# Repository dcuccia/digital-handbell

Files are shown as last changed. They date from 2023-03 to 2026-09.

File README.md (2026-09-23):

# Digital Handbell

**September 22: inner ground plane, +3V3 bridge and four ground stitches accepted.** The active
four-layer PCB now has **44 opens**, with existing connected groups and
protected sense returns preserved. The supply bridge adds three 0.40 mm
In2 segments between existing vias; component placement is unchanged.
An off-pad ground via and short R4 stub now join the existing C9/R4/R8
ground group to main GND without changing the plane fills; C9's local
high-frequency return remains unqualified.
Three further stitches connect C4, shared C11/C15 and U2 ground groups;
C12, C23 and C24 remain unresolved within the finite screen.
This is an incremental routing baseline, not a fabrication
release or final SI/PI qualification. See the
[latest acceptance record](hardware/handbell/iterations/printed-bell-four-layer/reports/supply-ground-radial-acceptance.json)
and [handoff](docs/pcb-closure-plan.md#owner-pause-and-next-item).

**September 21: four-layer migration approved, with Astra/Sol role separation.**
The [routing-agent policy](docs/routing-agent-policy.md) retains Astra's
engineering review and requires pinned Sol for corridor/group routing batches.
A separate [four-layer migration baseline](hardware/handbell/iterations/printed-bell-four-layer/README.md)
was established with 51 open connections, preserving placement and existing
copper. The first staged ground plane was rejected after a refill regression.
The explicit-settings replay subsequently preserved the connections and was
accepted September 22; the rejected trial remains historical evidence.
The two-layer layout is preserved unchanged. Saved SCL experiments and the older routing-recovery archive
are preserved separately; neither is accepted replacement copper. See the
[current handoff](docs/pcb-closure-plan.md#owner-pause-and-next-item).

An open-source, motion-triggered electronic handbell for affordable educational
music-making. Replace the clapper in a children's play handbell with a speaker,
rechargeable battery, and compact electronics. A natural ringing gesture should
produce a convincing bell sound; the instrument should be quiet between notes.

**Status: schematic, PCB and mechanical engineering drafts, not a
fabrication-ready or child-use-qualified design.** The preserved 0.2
[native KiCad draft](hardware/handbell/README.md) and
[schematic PDF](hardware/handbell/reports/handbell-schematic.pdf) integrate
LSM6DSOX, TPS61023 audio boost, independent mute, keyed speaker/button connectors
and service pads. Feather/RGB/servo/STEMMA extras are removed.
The [0.2 handoff](docs/electrical-reduction-and-placement.md) and
[mechanical models](docs/mechanical-feasibility.md) distinguish actual CAD,
screening assumptions and unresolved fit/power/manufacturing gates.
A separate partial-routing checkpoint is now available; no fabrication-ready
PCB or functioning firmware has been released.

**September 14 closure work:** the [current integration draft](hardware/handbell/iterations/printed-bell-clock-draft/README.md)
has its local clock routed, recorded ground fill restored, and USB slot/land
correction applied with local CC/VBUS repairs. All **83 fitted MPNs** are
assigned, and eleven selected power/passive land patterns are applied.
It retains **56 unconnected items**, with zero other native DRC errors and
232 silkscreen/text warnings.
The [cost-aware closure plan](docs/pcb-closure-plan.md) tracks remaining
geometry, routing and matched PCB+PCBA quotation inputs. This is still an
engineering checkpoint, not a complete or qualified board.
**September 15:** work has resumed. Six documented device-envelope corrections
are applied without moving parts. The selected U5 boost and R27 current-sense
land patterns are now applied too, with local U5 escape corrections and a
matching enlargement of R27's protected ground exclusion. The first local
core-supply links to C18, C6 and the C8 regulator-output capacitor are now
routed; **52 opens remain**.
C6's QSPI obstruction was resolved by a shorter QSPI escape and small
capacitor-column moves, retaining the existing courtyard geometry.
C8's obstruction was resolved by moving the unchanged-width VHI feed into
the central backside corridor and rearranging, not removing, the nine MCU
ground vias. Thermal/stencil review remains open.
Remaining native lands are retained for routing with explicit
supplier-process questions, including filled/capped amplifier thermal vias;
two-layer supplier availability and price are not yet confirmed.
The closure plan contains the
current handoff and repo-only fill-check commands.
The [routing-tooling study](docs/routing-tooling.md) records exercised native
API strategies and the bounded offline Freerouting pilot. No external-router
proposal was accepted; routing automation remains experimental.
Subsequent native-mask routing has connected the R2/CHG0 charge-indicator
branch without moving parts or changing existing copper: **51 opens remain**.
Core supply/return and amplifier GAIN attempts were preserved but not accepted.

**September 13 printed-bell revision:** the owner reports that the latest
inert pieces fit and authorizes a single-piece printed bell, flush removable
cartridge and black handle. The separate
[front-electronics placement](hardware/handbell/iterations/printed-bell-front/README.md)
fits **81 electronic parts on F and two battery contacts on B without growing
the D43 PCB**. Rear SMT contacts still require assembly work.
The [coordinated revision](docs/printed-bell-revision.md) records the new
interfaces, conditional routing authorization and pending mechanical results;
[material/handle notes](docs/printed-bell-material-and-handle.md) distinguish
silk-PLA guidance from qualified structural or thermal performance.

The [original printed bell and rendered views](docs/printed-bell-revision.md#printed-shell-cartridge-and-handle)
now provide a **70 mm diameter, 55.8 mm body with an 80 mm black handle**,
flush grille and removable complete cartridge. Native FreeCAD/STEP and nine
inert STL files are available separately from the earlier metal-bell studies.
The coordinated PCB interfaces support the authorized critical-routing stage;
this does not approve fabrication or live-cell operation.

The [first routed candidate](hardware/handbell/iterations/printed-bell-routing/README.md)
contains real tracks/vias and reduces unconnected items from 222 to 148.
It remains incomplete and inoperable. The owner-requested
[high-current review](hardware/handbell/iterations/printed-bell-routing/reports/power-routing-review.md)
identified boost output-capacitor loop and protector-sense pickoff corrections.
The [separate power-rework milestone](hardware/handbell/iterations/printed-bell-power-rework/README.md)
now implements those corrections, and the complete FreeCAD assembly has been
rebuilt around its exact placement. It still has **155 unconnected items**;
the main switched-battery feed, other routing, sourced parts and manufacturing
inputs remain unfinished. A newly identified
[USB import/land-pattern problem](docs/usb-connector-qualification.md) must also
be corrected before the quotation package.

The intended handoff includes [full PCB+PCBA quotation assets](docs/pcba-quotation-plan.md)
for JLCPCB and PCBWay after completing the design, not just the partial
routing checkpoint. No supplier upload or order is authorized.

**September 11 revision:** the owner confirms the newer print assembly fits,
supplies [measured shell stations](docs/measurements/2026-09-11-shell-speaker-inputs.json),
and refines the speaker magnet to **21.70 mm OD**. The
[next integration plan](docs/t8-integration-plan.md) combines the Vapcell T8
contact/capture candidate, compact cell protection, 2 MB flash, revised mouth
profile, supported USB access and reversible servicing. A complete placed
FreeCAD assembly is the owner-review checkpoint before routing. Earlier
profiles and prints below remain historical snapshots, not current tolerances.

The [new native T8 placement](hardware/handbell/iterations/t8-protected-draft/README.md)
implements **83 fitted parts**, including two SMT battery contacts, an eight-part
cell-protection stage and the smaller Winbond flash footprint. Its
[schematic PDF](hardware/handbell/iterations/t8-protected-draft/reports/handbell-schematic.pdf)
and [electrical handoff](docs/t8-electrical-revision.md) explain the protected
return, sourcing and current/charging limits. It remains unrouted and does not
approve live-cell operation.

The coordinated [T8 cartridge review model](mechanical/studies/2026-09-11-t8-cartridge/README.md)
adds a four-piece body/yoke/cradle/cover, M2 captive-nut hardware, insulating
shell attachment and a mouth-open USB service slot. Its current contact/guard
geometry requires a **6.25 mm mouthward stack shift**, putting the grille
10.75 mm outside the mouth. This is a review alternative, not an approved
final exterior or permission to route. Earlier print files remain unchanged.

**Preserved September 9 placement/fit draft:** the [two-face wing placement](hardware/handbell/iterations/wing-draft/README.md)
keeps a central battery/contact reservation, moves the boost and amplifier
blocks to rear wings, and adds two GND-assigned M2 mounting holes. The
[two-piece cartridge](mechanical/studies/2026-09-09-integrated-cartridge/README.md)
provides an integrated grille/seat/support body, removable capture yoke and
new populated-PCBA STEP/STL. Its 72 mm flange sits outside the assumed 70 mm
mouth; it does not yet include battery retention or shell attachment. The
[electromechanical handoff](docs/electromechanical-wing-iteration.md) separates
draft progress from the remaining cell, retention, routing and assembly-cost
gates. The original project/print files remain intact.

**September 9 measurements:** the arrived speaker is 40 mm OD x 19 mm overall,
with a 32 mm basket rear at 12 mm and a 22 mm x 7 mm magnet. The
[measured-speaker follow-up](mechanical/studies/2026-09-09-measured-speaker/README.md)
keeps the original print files intact and compares speaker-facing electronics
with cylindrical/pouch battery space. The PCBA print received positive fit
feedback; some other pieces need structural reconsideration.

The [compact power and packaging review](docs/compact-power-and-packaging.md)
records the earlier decisions behind this revision. Its hypothetical taper
example is superseded by the owner's z13/50 mm to z43/34 mm working profile.

The working first-revision baseline is the
[Adafruit RP2040 Prop-Maker Feather (5768)](https://www.adafruit.com/product/5768):
RP2040, CircuitPython, MAX98357A I2S DAC/amplifier, LIS3DH accelerometer, USB-C,
and single-cell LiPo charging. Its documented, code-supported circuitry is
adapted into the reduced circular candidate, with the sensor and audio-power
changes described above. This is not a frozen BOM.

The owner-approved [LSM6DSOX six-axis sensor](docs/motion-sensing.md) is now in
the separate handbell draft for strike plus chest-stop/rest development.
The imported reference retains its original LIS3DH. Gesture performance,
assembled cost and final electrical decisions remain evidence gates.

## Start here

| Document | Purpose |
|---|---|
| [Project brief](docs/project-brief.md) | Captured goals, requirements, open questions, and original mechanical ideas |
| [Reference catalog](docs/reference-designs.md) | Every proposed source, learning guides, source revisions, and important corrections |
| [Architecture](docs/architecture.md) | Proposed blocks, verified baseline GPIOs, and retain/remove decisions |
| [Schematic and CAD plan](docs/schematic-plan.md) | Beginner-oriented KiCad setup/import path and schematic review gates |
| [KiCad setup and readiness](docs/kicad-setup.md) | Installed tooling, opening the native reference, and remaining import-review work |
| [Firmware and audio](docs/firmware-and-audio.md) | CircuitPython, bell assets, strike detection, quiet idle, and power modes |
| [Motion-sensor decision](docs/motion-sensing.md) | LIS3DH versus six-axis sensing, chest-stop limits, CircuitPython APIs, and sourcing |
| [Mechanics and manufacturing](docs/mechanics-and-manufacturing.md) | Speaker/board trade space, measurements, mounting, JLCPCB and OSH Park |
| [Compact power and packaging review](docs/compact-power-and-packaging.md) | Approved next revision, boost/cell/mute review, speaker-rating conflict and fit constraints |
| [0.2 reduction and placement](docs/electrical-reduction-and-placement.md) | Implemented circuits, 43 mm candidate, service map and open routing/DFM gates |
| [Mechanical feasibility](docs/mechanical-feasibility.md) | Editable FreeCAD, STEP/STL, assumed shell profile and cartridge interference findings |
| [Wing/cartridge iteration](docs/electromechanical-wing-iteration.md) | Preserved September 9 placement, two-piece fit models and JLC assembly-tier findings |
| [Measured-shell T8 integration](docs/t8-integration-plan.md) | September 11 measurements, compact protection/contact/capture revision and owner review before routing |
| [T8 electrical revision](docs/t8-electrical-revision.md) | Actual 2 MB flash lands, protected battery return, pin map, current tradeoffs and remaining gates |
| [T8 cartridge model](mechanical/studies/2026-09-11-t8-cartridge/README.md) | Complete placed FreeCAD/STEP assembly, four inert structural prints, M2 service sequence and explicit fit limitations |
| [Routing readiness](docs/routing-readiness.md) | Print-fit checkpoint, electrical floorplanning gates and the path to reviewed Gerbers/BOM/CPL |
| [Validation plan](docs/validation-plan.md) | Measurements and evidence required before each hardware release |
| [Decision log](docs/decisions.md) | Provisional decisions and the evidence needed to close them |
| [Roadmap and epics](docs/roadmap.md) | Milestones, dependencies, scope, and acceptance criteria |
| [Attribution and licensing](ATTRIBUTION.md) | Hardware, software, sound-asset, and documentation provenance |

Track execution in the public
[Digital Handbell Project](https://github.com/users/dcuccia/projects/1),
[12 epic issues](https://github.com/dcuccia/digital-handbell/issues?q=is%3Aissue%20label%3Aepic),
and [five milestones](https://github.com/dcuccia/digital-handbell/milestones).
The epics include checklists, acceptance criteria, native blocked-by
relationships, and links to supporting plans.

## Design direction

- Start with a bench demonstration using the integrated Prop-Maker Feather,
  while developing the reduced schematic in parallel.
- Prefer a single circular PCB and compare selective rear-wing population
  against the original one-face assembly goal using complete assembly cost.
  Two copper layers remain the draft baseline. Establish diameter through real
  placement and measured shell geometry, not the sum of chip areas; compare
  four layers or stacked boards if evidence warrants them.
- Keep sounding local/offline; evaluate an S3-MINI wireless variant early
  enough to inform antenna/carrier choices. The draft already has six-axis
  sensing; the unchanged reference has neither a radio nor a gyroscope.
- Optimize complete assembled cost and novice assembly, not merely IC prices.
  Fine-pitch soldering should not be a prerequisite for an educational kit.

## Project history

The original [2023 design notes](Design%20Notes.md) and
[system diagram](System%20Diagram.pptx) are preserved unchanged. They considered
wireless connectivity, a host interface, and a six-degree-of-freedom IMU.
The 2026 planning baseline narrows the first experiment; it does not silently
erase those earlier ideas.

## Licensing and attribution

The existing [MIT license](LICENSE) remains in place for original project
software and documentation. It does **not** relicense third-party hardware,
software, images, or recordings. Most candidate Adafruit hardware sources use
CC BY-SA 3.0; adapted material must retain its applicable terms and notices.
See [ATTRIBUTION.md](ATTRIBUTION.md) before importing anything.

Pinned, licensed Adafruit CAD and notices are vendored in the reference
packages; the separate derivative identifies its modifications. No third-party
firmware or recordings are vendored. This is an independent project, not an
Adafruit-endorsed product.

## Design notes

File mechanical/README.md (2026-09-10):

# Handbell mechanical feasibility artifacts

**Integrated wing draft:** the
[two-piece cartridge study](studies/2026-09-09-integrated-cartridge/README.md)
adds an integral grille/seat/support body, removable capture yoke and a new
two-face PCBA proxy with mounting holes. It uses the separate native wing
placement and preserves every older print below. Its D72 flange is external;
insertion order, small nominal clearances and unqualified hardware/retention
are described in its own handoff. Do not substitute it for a finished battery
holder or shell attachment.

**September 9 update:** the arrived speaker measures 40 mm OD and **19 mm**
overall depth, with a D32 basket rear at z12 and D22 x H7 magnet. The
[separate measured-speaker study](studies/2026-09-09-measured-speaker/README.md)
records those stations, speaker-facing PCB conflicts, battery-space comparisons
and physical print feedback. The files below are the unchanged September 7
snapshot; its **18.5 mm speaker gauge is not deep enough for the measured part**.
No reinforced carrier or new battery holder has been released.

**Inert dimensional study, not a complete fitted assembly or child-use hardware.**
The editable FreeCAD document includes the current 74-part placement as rectangular
proxies, directly from the final supplied manifest with **no height overrides**.
J2 is SM02B side-entry at 3.1 mm; D3/D4 are 1.1/1.0 mm.
USB-to-shell interference and insufficient battery clearance are retained,
not hidden by cutting the shell or shrinking parts. See the
[quantitative handoff](../docs/mechanical-feasibility.md).
The [print-now dummy set](#print-now-inert-dummy-set) adds a connected fake
populated PCBA, speaker gauges and battery blocks for PLA fit work.

## Files and coordinate system

| File | Purpose |
|---|---|
| `handbell-feasibility.FCStd` | Native document with individually selectable BRep solids, Parameters spreadsheet, assumptions, source snapshot and placement snapshot |
| `handbell-assembly.step` | 82-solid assembly in the primary 74-component study; includes assumed shell and solid exterior-only handle, excludes construction cavity and battery clearance tools |
| `fit-carrier.stl` | Single connected baffle, speaker locating sleeve, three PCB seating rails and grille stand-offs; no positive speaker/PCB restraint |
| `bonded-interface.stl` | Separate shell mounting-ring fit gauge; adhesive/paint compatibility and retention unqualified |
| `grille.stl` | Separate grille fit gauge with matching alignment holes; cone excursion and acoustic performance unqualified |
| `parameters.json` | Explicit dimensions used for this run; editable regeneration input |
| `fit-report.json` | Per-component and scenario fits, material intersection volumes, battery alternatives, toolchain and artifact round-trip results/hashes |
| `fit-dummies.json` | Standalone dummy inventory, exact dimensions, print/assembly datums, assumptions and frozen placement hash |
| `freecad-build.log` | Local, Git-ignored diagnostics regenerated by the build; not part of the published download |
| `views/packaging-views.svg` | Original axial/proxy-plan illustration, not a photograph or manufacturer drawing |
| `views/fit-dummies.svg` | Original illustrative-speaker profile and print-dummy dimension inventory; no source image included |
| `README.md`, `LICENSE` | Usage, scope and original-work licensing |

All CAD coordinates represent **millimetres**. `z=0` is the bell opening,
positive z inward. PCB XY positions use the manifest's right-handed coordinates,
with positive rotations counterclockwise when viewed from +z toward the origin.
The SVG plan has +X right and +Y up. STEP declares millimetre SI units.
**STL has no unit metadata: import as mm at 1:1.**

The original carrier/interface/grille STLs retain assembly positions. Translate
them to the print bed rather than scaling: carrier z=-4, grille z=-5.8,
interface z=0. **All new standalone dummies below already start at print Z=0.**
Their print origin is not necessarily their position inside the bell.

## Print-now inert dummy set

Original dummy profile and dimensions

**Start with** the [populated PCBA STL](populated-pcba-proxy.stl),
[maximum speaker gauge](speaker-envelope-maximum.stl), and
[compact battery-clearance gauge](battery-clearance-compact.stl).
The [illustrative speaker STL](speaker-illustrative-unmeasured.stl) shows the
approximate stepped shape, but is not the conservative fit envelope.
Use mm at 100%; the PCBA's extra USB projection must not be scaled away.
**No USB drilling/cutting template is supplied.** Its interference with an
uncut shell is expected; do not force it or use the proxy box as a connector
manufacturing drawing.

All dimensions in this table are default **millimetres**, at 100% scale.
Every listed STL is one connected, closed solid. Each has an editable BRep in
the native document's `FitDummies` group, separate from the assembly export.

| STL file | Size / purpose |
|---|---|
| `populated-pcba-proxy.stl` | **43 x 43.465 x 6.6** bounding box; 43 mm circular substrate, 1.6 mm thick, fused to all 74 supplied component boxes |
| `speaker-envelope-nominal.stl` | **D40.5 x H18** full cylinder; nominal frame/depth gauge |
| `speaker-envelope-maximum.stl` | **D40.9 x H18.5** full cylinder; conservative maximum frame/depth gauge |
| `speaker-illustrative-unmeasured.stl` | **D40.5 x H18** stepped rim, solid tapered basket and magnet; intermediate geometry is unmeasured |
| `battery-dummy-primary.stl` | **20 x 30 x 8** inert block, not a selected pack |
| `battery-dummy-compact.stl` | **18 x 28 x 8** inert block, not a selected pack |
| `battery-clearance-primary.stl` | **22 x 32 x 10** solid gauge representing the primary block plus 1 mm clearance on every face |
| `battery-clearance-compact.stl` | **20 x 30 x 10** solid gauge representing the compact block plus 1 mm clearance on every face |

The standalone **`populated-pcba-proxy.step`** and
**`speaker-illustrative-unmeasured.step`** have the same print orientation/datum
as their STLs. The PCBA is a true fused union, not a collection of disconnected
boxes. No small 0402 detail was enlarged, no bridging material added outside the
source envelopes, and no body clipped at the PCB boundary. The USB proxy explains
the 43.465 mm overall Y extent: do not scale the whole dummy down to 43 mm.
No visualization-enlargement variant is included.

For the current inward-facing board, put the PCBA's flat substrate underside on
the bed and components upward. Restore its bottom to **assembly z20** when
checking the bell; the print file itself has substrate z0..1.6 and components
through z6.6. Speaker gauges have the front/frame face on the bed and correspond
to assembly z0. Battery blocks correspond to **assembly z28**, while their
clearance gauges start at **z27** because they include the mouthward free space.
Use those depth datums rather than directly stacking all dummies against each
other; the model includes deliberate gaps between them.
The current model still predicts USB interference with an uncut shell and failure
of the larger battery-clearance gauge; do not force either into the bell.

### Speaker: supplied dimensions versus invented shape

The supplied retail image repeats frame40.5 +/-0.4, magnet22 +/-0.5, overall
depth18 +/-0.5 and rim2.7 +/-0.3 mm. It is **not redistributed**, embedded in
the native document, or traced for measurements. Rim height is part of overall
depth, not added to it. The maximum full cylinder remains the hard-interference
model; neither gauge includes unknown terminals, wire exits or cone excursion.

The separate illustrative dummy uses nominal frame40.5, depth18, magnet22 and
rim2.7. Its **37 mm basket front diameter**, **26 mm basket rear diameter** and
**magnet front at z12** are deliberately chosen, unmeasured starting values.
They imply a 9.3 mm tall solid conical basket and 6 mm magnet height. No rib
windows, terminals, diaphragm, recess or rear vent is claimed. A fit of this
illustrative shape is **not** evidence that the real basket fits.

Change the `gauge_speaker_assumed_*` values in `parameters.json` or the saved
Parameters spreadsheet, then regenerate. The compact battery has separate
`gauge_compact_battery_*` parameters. Its parameters also drive the corresponding
numeric clearance comparison. Older native spreadsheets receive the explicitly
logged new gauge defaults during regeneration.

### Creality K1C / PLA starting guidance

Use the K1C profile for the **nozzle actually installed**, with the filament's PLA
temperature settings. For a stock 0.4 mm nozzle, a reasonable unqualified starting
point is 0.20 mm layers for bulk gauges, 0.12-0.16 mm for the PCBA's small details,
three walls and 15-20% infill. These are starting suggestions, not an exercised
slicer profile; no G-code or remote print job is supplied.

Import **mm, 100% scale**, without fit-to-bed resizing. The wide speaker frame
face and battery block bottoms are already on Z=0 and are intended to print
without support. Inspect the PCBA's USB overhang and very small component boxes
in the slicer; add local support only if the actual toolpath requires it. Tiny
0402 proxy details can be lost, fragile or dimensionally inaccurate with a
0.4 mm nozzle. Check the toolpath rather than enlarging the exact-fit file.
The original carrier may require a different orientation/support strategy.

Let prints cool, then measure their diameters, depths and board thickness with
calipers before drawing fit conclusions. Remove loose fragments and do not
force a gauge against the painted shell. Follow the printer/filament guidance
for PLA ventilation and enclosure use. **PLA dummies are not live-cell
restraints, FR4/thermal substitutes, electrically functional parts, mass/acoustic
stand-ins, structural mounts or child-ready hardware.**

## Reproduce without opening a GUI

From the repository root, using ordinary Python and installed FreeCAD:

```powershell
$FreeCAD = "$env:LOCALAPPDATA\Programs\FreeCAD 1.1\bin\FreeCADCmd.exe"
python .\tools\build_mechanical.py --freecad-cmd $FreeCAD --placement .\hardware\handbell\placement\placement-manifest.json
```

The launcher runs the installed FreeCAD Python interpreter, not an unrelated pip
package. It uses temporary isolated user/system preferences, waits synchronously,
and checks a fresh completion marker because FreeCAD's console can return zero
after a Python exception. The console process has a **300-second timeout**.
No GUI, background detachment, add-on installation,
user-window manipulation or shared FreeCAD-preference changes are required.

The script regenerates the named CAD/data/view artifacts in this directory.
It never writes the placement manifest, KiCad files or existing documentation.
It overwrites its generated outputs, so use `--output` with another directory
to preserve a study. A successful build means artifacts were generated and
round-tripped, **not** that all geometry fits.

To modify a parameter without editing code, use `--parameters` with a JSON
object containing known keys, or edit the native `Parameters` spreadsheet,
save the document, then regenerate:

```powershell
python .\tools\build_mechanical.py --freecad-cmd $FreeCAD --parameters-from .\mechanical\handbell-feasibility.FCStd --placement .\hardware\handbell\placement\placement-manifest.json
```

The BReps are source-generated features, not a fully constrained interactive
feature history. **Spreadsheet edits alone do not rebuild geometry.** The command
above reads those saved values and rebuilds the model. Manifest board dimensions
and face take precedence over parameter-file/spreadsheet board values.
`--speaker-front-z 1` moves the speaker front to z=1, with unchanged full depth.
The script snapshot inside the document records the source that built it.

`--component-height REFERENCE=MM` is an explicit model-only parameter: it changes
neither the input manifest nor the component's XY, footprint or rotation.
`--component-height-note` records its reason. If explicitly requested, original
and effective heights are recorded in `fit-report.json` and native
`ComponentHeightOverrides`; the native manifest snapshot remains unchanged.
`--parameters-from` does not restore such overrides automatically.
**No height override is used or needed for the current supplied manifest.**
The earlier top-entry height screen and its J2/battery-clearance overlaps are
superseded. The current side-entry J2 does not intersect either battery
alternative's clearance envelope.

The report distinguishes `required_shell_cutouts` from
`unplanned_cavity_conflicts` while retaining raw uncut-shell intersections.
No USB slot is implemented or dimensionally qualified. The 18 reverse-face
copper features and C29 DNP reservation remain metadata, not material solids.
Battery variants include their intersections with populated-board proxies:
cavity containment alone does not establish assembly clearance.

When first opening the headless-produced document in FreeCAD, hide
`CavityReference` and `BatteryClearance` under the construction-reference group;
their solid geometry is for calculations, not physical parts. Also hide the
`FitDummies` group: its independent print-coordinate objects overlap when shown
together and are deliberately excluded from `handbell-assembly.step`.
Hide `BellShell` and `HandleExterior` to inspect the electronics/carrier.
Show one dummy at a time to inspect it, or open its standalone STEP.
The original SVGs are ready-to-view illustrations without display setup.

Passing `--placement` with a missing or malformed file is an error. Omitting it
deliberately produces a **placeholder-only** study with no component solids;
it does not silently load a nearby manifest or reuse old placement data.

## Attribution and license boundaries

The original mechanical primitives, fit-print designs, parameters, program and
new documentation are explicitly available under the [MIT license](LICENSE).
They are independent geometry built from the declared dimensions and assumptions.
No vendor photograph, owner photograph, manufacturer STEP model, speaker drawing,
upstream board solid, KiCad library geometry or third-party mesh is copied here.
The illustration is generated from this original model.

**Do not label the populated study blanket-MIT.** The embedded placement snapshot,
component-reference context and adapted electronics remain subject to the
repository's [attribution policy](../ATTRIBUTION.md) and the
[handbell hardware's CC BY-SA 3.0 notices](../hardware/handbell/README.md).
The mixed populated FCStd/STEP, populated-PCBA STEP/STL, placement-based views
and reports must travel with
those notices; the original mechanical geometry's separate MIT grant does not
relicense the electronics. The embedded script retains MIT independently.

The referenced electronics are based on:

- **Limor Fried/Ladyada for Adafruit Industries**, RP2040 Prop-Maker Feather
  5768, revision `408fa9a40c0a01a3a65497ef42a29e0b08fe711e`;
  [source notices and full CC BY-SA 3.0 license](../hardware/reference/adafruit-5768/README.md).
- **Bryan Siepert for Adafruit Industries**, LSM6DSOX 4438,
  revision `c05abef4675b0380fbf3d23171615a2f1ac0b130`;
  [source notices and full license](../hardware/reference/adafruit-4438/README.md).
- **Limor Fried/Ladyada for Adafruit Industries**, TPS61023 MiniBoost 4654,
  revision `82b5a33a1900a5c13849029bc84e7856a44086e0`;
  [source notices and full license](../hardware/reference/adafruit-4654/README.md).

Distribute this study with the repository's complete upstream notices, or carry
those notices/licenses alongside standalone populated exports. These proxy boxes
are not Adafruit or component-manufacturer CAD models. Attribution does not imply
endorsement, manufacture or mechanical/electrical/safety qualification.

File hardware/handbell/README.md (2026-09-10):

# Handbell: 0.2 electrical and placement draft

**Later placement alternative:** the separate
[wing draft](iterations/wing-draft/README.md) adds selective rear-face
population and M2 mounting interfaces for the
[integrated cartridge](../../mechanical/studies/2026-09-09-integrated-cartridge/README.md).
This directory's original 0.2 CAD and print snapshot remain unchanged;
open the variant's project for the newer placement.

**Reduced electronics and a 43 mm unrouted candidate; not a fabrication release.** Open
[`handbell.kicad_pro`](handbell.kicad_pro) in KiCad 10.0.6, then its schematic.
For a CAD-free view, use the [schematic PDF](reports/handbell-schematic.pdf).
The PCB editor opens [`handbell.kicad_pcb`](handbell.kicad_pcb), an actual-footprint
placement with no tracks/vias/zones. Start with the
[0.2 handoff](../../docs/electrical-reduction-and-placement.md) for boost, mute,
connectors, service access, geometry and unresolved DRC/power gates.

The owner approved the sensor change on 2026-09-07. The earlier 0.1 replaced the
5768 reference's LIS3DH, resolves its original ERC findings in a separate
derivative, and established explicit sensor/debug connections. That history
remains in commit `ef3d6ab2bf822cff79d41573f05b5916c6a7133e`.

**Later 2026-09-07 scope update:** the owner approved the compact GPIO19-button,
no-STEMMA/header/RGB revision and a boosted audio/mute review. The
[power/packaging assessment](../../docs/compact-power-and-packaging.md) records
those decisions, candidate sources and remaining gates. This directory now
implements **0.2**: TPS61023 boost, independent GPIO20 mute, GPIO19 button,
keyed speaker connector, service pads and removal of expansion/RGB branches.

## Artifacts and scope

| Artifact | Purpose |
|---|---|
| [Native schematic](handbell.kicad_sch), [local symbols](Handbell.kicad_sym) | Editable design; source-derived and mode-specific symbol definitions |
| [PDF](reports/handbell-schematic.pdf), [XML netlist](reports/handbell-netlist.xml) | Human and machine-readable views |
| [ERC disposition](reports/erc-review.md), [machine-readable dispositions](reports/erc-dispositions.json) | Individual treatment of all 50 original findings and collateral warnings |
| [Current ERC](reports/handbell-erc.json) | Zero errors and zero warnings under the unchanged baseline rules; no exclusions |
| [Connectivity/pad review](reports/connectivity-review.json) | 62 retained components, 73 projected groups, explicit changes, all sensor/boost lands |
| [BOM draft](reports/bom-draft.csv) | Values and footprints, with incomplete MPN/assembly choices explicitly marked |
| [Placement](placement/placement-top.svg), [manifest](placement/placement-manifest.json), [review](placement/placement-review.json) | 74 fitted front parts, 18 reverse copper features, one DNP provision |
| [Native DRC](placement/placement-drc.json), [substrate STEP](placement/pcb-substrate.step) | Unresolved findings retained; substrate-only STEP is not a populated model |

The footprint table refers to three sibling reference packages and the local
`Handbell.pretty` correction library using
`${KIPRJMOD}`-relative paths. Keep the **whole repository checkout** together;
copying only this directory omits required footprints. Standard KiCad libraries
provide `power:PWR_FLAG`. The exported schematic also embeds its symbols.

## Reuse, authorship and license

This independent adaptation is **CC BY-SA 3.0 Unported**:
[complete license](LICENSE.txt). It is not an Adafruit product or endorsement.

- Core, power, audio and other retained circuitry: Adafruit RP2040 Prop-Maker
  Feather 5768, designed by Limor Fried/Ladyada for Adafruit Industries,
  source commit `408fa9a40c0a01a3a65497ef42a29e0b08fe711e`.
  [Full original notice and source](../reference/adafruit-5768/upstream/README.md).
- SOX symbol and LGA-14L footprint: Adafruit LSM6DSOX 4438, designed by
  **Bryan Siepert for Adafruit Industries**, source commit
  `c05abef4675b0380fbf3d23171615a2f1ac0b130`.
  [Full original notice and source](../reference/adafruit-4438/upstream/README.md).
- Boost: Adafruit TPS61023 MiniBoost 4654, Limor Fried/Ladyada for Adafruit
  Industries, commit `82b5a33a1900a5c13849029bc84e7856a44086e0`.
  [Full original notice and source](../reference/adafruit-4654/upstream/README.md).
- Integration, changed wiring, electrical pin types, annotations and review:
  the dcuccia digital-handbell project, with AI assistance, 2026-09-07.
- Standard KiCad power, connector, SOT23 and solder-jumper material is used in the design under KiCad's
  [CC BY-SA 4.0 library license with design exception](https://www.kicad.org/libraries/license/).
  It is not redistributed in `Handbell.kicad_sym` as a library collection.
  Original verification scripts under `tools` remain MIT-licensed.

All three upstream references are preserved separately. The old Adafruit graphical
title frame was removed from this derivative and replaced with an independent
title block carrying attribution; upstream notices were not removed.

## LSM6DSOX electrical contract

**IC4 = LSM6DSOXTR**, LGA-14L, nominal 2.5 x 3.0 x 0.83 mm. It operates from
the common regulated **3.3 V**, not raw battery voltage. This is an I2C-only,
ST **Mode 1** implementation at seven-bit address **0x6A**.

| Physical pad | Function | Connection |
|---|---|---|
| 1 | SDO/SA0 | GND: fixed address 0x6A |
| 2, 3 | SDx, SCx | GND: unused Mode 1 auxiliary pins must not float |
| 4 | INT1 | `INT`, RP2040 GPIO22 / IC1 physical pin 34 |
| 5 | VDDIO | +3V3, local C24 = 100 nF to GND |
| 6, 7 | GND | Both physical pads to GND; imported symbol has stacked pins |
| 8 | VDD | +3V3, local C23 = 100 nF to GND |
| 9 | INT2 / DEN | `IMU_INT2` to TP6 only; no second MCU connection yet |
| 10 | OCS_Aux | Explicit NC; its physical land must still be soldered |
| 11 | SDO_Aux | Explicit NC; its physical land must still be soldered |
| 12 | CS | +3V3: I2C interface selected |
| 13 | SCL | GPIO3 / IC1 pin 5; existing R14 = 10 kohm to +3V3 |
| 14 | SDA | GPIO2 / IC1 pin 4; existing R15 = 10 kohm to +3V3 |

No duplicate regulator, BSS138 level shifter, CS diode or additional I2C
pull-up bank is imported from the breakout. Two local 100 nF bypass capacitors
follow ST's application circuit rather than treating the breakout's shared
100 nF and regulator bulk capacitance as interchangeable.

**Deliberate difference from Adafruit 4438:** its auxiliary pins go to JP2.
This fixed-function design instead follows ST's Mode 1 instructions: SDx/SCx
are tied to GND; OCS_Aux is NC; SDO_Aux is NC (ST also permits VDDIO).
The source symbol's generic bidirectional types are specialized to this mode
in `LSM6DSOX_I2C_MODE1`. Do not reuse that symbol for sensor-hub/OIS wiring
without reviewing the types, straps and firmware.

Evidence: [ST LSM6DSOX datasheet](https://www.st.com/resource/en/datasheet/lsm6dsox.pdf),
DS12814 Rev 3, Table 1 pp.8-9, section 5.1 pp.18-19, Figure 24 p.39 and Table 20
p.42. The reviewed ST-authored Rev 3 document was obtained through JLC's
[C481766 datasheet link](https://jlcpcb.com/partdetail/C481766) when the direct
ST fetch failed; page numbers above are **Rev 3**, not Rev 4. Original Adafruit
pin-to-pad mapping is in its pinned
[schematic lines 5463-5482](https://github.com/adafruit/Adafruit-LSM6DSOX-PCB/blob/c05abef4675b0380fbf3d23171615a2f1ac0b130/Adafruit_LSM6DSOX.sch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).

## Historical 0.1 integration changes

In 0.1, all non-sensor component values, footprints and pin-to-pin groups were retained.
I2S remains GPIO16 data, GPIO17 bit clock and GPIO18 word select; amplifier
power enable remains GPIO23. The original changes beyond the sensor were:

- TP4 on SWCLK and TP5 on SWDIO make debug-pad intent explicit. They reuse the
  reference's 1.5 mm copper test-pad footprint; they are not fitted components.
  Adjacent GND/3V3 probing and physical accessibility remain layout decisions.
- Power-output/ground/mounting-terminal electrical types are corrected in the
  derivative library; intentional unused pins have NC markers.
- Redundant label-bearing wire tails are trimmed or removed without changing
  retained connections. Five power flags declare external/discrete sources;
  they are annotations, not added supplies or a proof of every power state.
- The inherited `1.2V` rail name becomes **`VCORE`**, with identical connections.
  RP2040's datasheet specifies a 1.1 V reset nominal for its internal regulator;
  a copied net label is not a voltage measurement or firmware setting.

## Firmware prerequisite discovered during integration

The inspected CircuitPython LSM6DS snapshot redefines `_i3c_disable` from
CTRL9_XL bit 1 to bit 0, and the SOX constructor uses that descriptor.
For this non-I3C design, verify **bit 1 set, reserved bit 0 clear**, preserving
other bits. Do not assume an unmodified copy of that inspected snapshot is
ready for bring-up. See the [motion document](../../docs/motion-sensing.md)
for pinned source evidence and the bring-up gate.
Execution is tracked in [E06 child issue #13](https://github.com/dcuccia/digital-handbell/issues/13).

Keep sensor-hub master, pass-through, OIS and DEN disabled. Retain the default
auxiliary pull-ups when leaving pads 10/11 NC. Route chosen events explicitly
to INT1; a physical interrupt wire does not configure interrupt behavior.

## Not resolved by 0.2

Cell choice, charger current/temperature/protection, cutoff and play-while-charge
policy; qualified speaker power and measured quiet-idle sequencing; USB input/ESD
review; final mating harnesses; complete MPN/assembly quote; real-shell circular fit,
orientation, placement/routing, ground/current-return paths and mechanical
support; actual sound, latency, gestures, runtime and safety.

In particular, the inherited R8 = 5.1 kohm is about **196 mA nominal** charge
current, not an approved setting for an unspecified cell. Neither speaker lead
is ground: the MAX98357A output is BTL. E02/E04 remain open; zero ERC findings
are not independent electrical, acoustic, thermal or child-use signoff.

## Reproduce exports and checks

From the repository root in PowerShell, with Python 3.10+ and KiCad installed:

```powershell
$Cli = "$env:LOCALAPPDATA\Programs\KiCad\10.0\bin\kicad-cli.exe"
$Sch = ".\hardware\handbell\handbell.kicad_sch"
$Reports = ".\hardware\handbell\reports"
& $Cli sch export pdf --exclude-pdf-metadata --output "$Reports\handbell-schematic.pdf" $Sch
& $Cli sch export netlist --format kicadxml --output "$Reports\handbell-netlist.xml" $Sch
& $Cli sch erc --exit-code-violations --format json --output "$Reports\handbell-erc.json" $Sch
python .\tools\check_handbell.py --kicad-cli $Cli
```

Stop on a nonzero exit code. The final command freshly exports all four
schematics in temporary storage, checks three source imports and the derivative,
and updates the connectivity report and BOM draft. It uses only Python's
standard library. Its expected changes describe this 0.2 integration; future
intentional reductions must update that explicit contract, not bypass it.
These commands do not qualify a PCB. See the 0.2 handoff for placement generation
and the `--placement` correspondence review.

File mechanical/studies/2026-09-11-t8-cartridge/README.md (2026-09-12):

# Measured-shell T8 cartridge: coordinated mouthward stack

**A nominal placed-fit study for owner review before routing, not a fabrication,
live-cell, contact-force or child-use approval.** The entire internal stack is
moved **6.25 mm toward the mouth**, preserving its speaker/yoke/PCB/cell gaps.
The mouth register stays fixed and the front body projects farther outside.
The chosen battery-guard target is **1.0 mm plastic**, within the owner's
1-1.5 mm range, with **0.10 mm nominal cell/contact clearance**.

The initial fixed-stack result is preserved under
[`alternatives/baseline-fixed-stack`](alternatives/baseline-fixed-stack/README.md).
It is not silently relabeled as fitting. The bounded alternative and its exact
source hashes are in
[`alternatives/whole-stack-screen/stack-shift-fit-report.json`](alternatives/whole-stack-screen/stack-shift-fit-report.json).
All September 7/9 studies and existing generators remain unchanged.

## Why the shift is 6.25 mm rather than 2 mm

The upper, full-thickness Keystone 254 spring limits the fit, not the bare cell.
At a 2 mm shift the bare cell clears the working shell by1.581 mm, but the
contact metal clears by only0.331 mm: that does not leave room for a1.0 mm
guard. The screen first tried the suggested1.5/2 mm shifts, then used the
analytic upper-contact corner to choose two quarter-millimetre brackets.
It did not run a blind optimizer or clip the metal.

| Whole-stack mouthward shift | Plastic target | Full rounded guard-stock result |
|---|---|---|
|1.5 mm |1.0 mm |27.475 mm3 shell overlap |
|2.0 mm |1.0 mm |18.845 mm3 shell overlap |
|6.0 mm |1.0 mm |No overlap;0.231 mm shell margin |
|**6.25 mm, chosen** |**1.0 mm** |**No overlap;0.294 mm shell margin** |
|7.0 mm |1.25 mm |No overlap;0.232 mm shell margin |
|7.25 mm |1.25 mm |No overlap;0.294 mm shell margin |

The rounded stock uses conservative local contact bounding solids with rounded
external corners, not an oversized rectangular corner and not a substituted
solid contact box through the cell. Its0.25 mm nominal shell-margin target is
a design assumption, **not measured print, paint or shell tolerance**.
The chosen1.0 mm option avoids another1 mm of external projection.

## Exact coordinated interface

All coordinates are **mm**. Mouth/front is z0; positive z is toward the handle.
The builder consumes the updated electrical manifest and contact interface
directly. It does not silently shift electronics imported from an old manifest.

| Feature | Current working coordinate |
|---|---|
| Speaker front / grille front |z-6.25 / z-10.75 |
| Rear basket station / magnet rear |z5.75 / z12.75 |
| Capture ring |z6.05..8.55 |
| PCB speaker-facing F / handle-facing B |z14.25 / z15.85 |
| T8 axis, X-oriented |(0,0,25.63), D16.4 x totalL34 provisional |
| Cell bottom / top |z17.43 / z33.83 |
| Contact B landing / spring top |z15.85 / z32.44 |
| Cover split |z25.75 |
| PCB mounting holes |(+10,+15.7), (-10,-15.7), D2.2 |
| USB native origin / source mouth |(0,-22.82) / (0,-27.90) |
| USB body-height proxy |z10.75..14.25 |
| Fixed shell attachment locations |Opposed X sides, outer-wall center z3 |

The main PCB remains D43 x1.6 with the **actual supplied outline polygon**:
contact-pad tabs to x+/-22.25, y+/-2.3 and a USB tongue x+/-5.75 to y-26.85.
The tongue/mouth move2.75 mm outward from the fixed-stack variant. All other
component XY, mount and contact-pad positions remain supplied by electrical.

The current manifest/companion hashes, actual PCB/schematic hashes and raw
snapshots are in `fit-report.json` and `artifact-manifest.json`.
The coordinated manifest at generation is
`4e8e27f7241e76850ef4fb9719a45acf0ab49ccfe9e1d651ef60f278b20da46c`;
the companion is
`e93d72ef211b7615634f255153a413b826d05c1495fa19d967c64456b647c4a6`.
An electrical source change requires a new build, not reuse of old fit values.

## Open the files

| File | Scope |
|---|---|
| `t8-cartridge.FCStd` | Selectable BReps, colored components, transparent working shell, parameters, exact base64 raw-input/source snapshots |
| `t8-cartridge-with-shell.step` | Complete placed study with proposed shell slot/holes and handle exterior |
| `t8-cartridge-assembly.step` | Complete cartridge including full contact primitives, without shell/handle |
| `body.step`, `yoke.step`, `battery-cradle.step`, `battery-cover.step` | Four separate structural parts |
| `populated-t8-pcba.step` | Full supplied PCBA/contact geometry; not a mesh-printability approval |
| `INERT-body.stl`, `INERT-yoke.stl`, `INERT-battery-cradle.stl`, `INERT-battery-cover.stl` | Four connected structural inert print models |
| `INERT-populated-t8-pcba-without-contacts.stl` and matching STEP | Explicitly contact-free, connected PCBA fit dummy |
| `INERT-speaker-body-screen.stl`, `INERT-T8-full-cell.stl` | Full inert dimensional bodies, not live parts |
| `inner-outer-profile-and-datums.svg` | Original novice-oriented section, measured/inferred stations and shifted datums |
| `fit-report.json`, `artifact-manifest.json`, `completion.json` | Exact Booleans/distances, path samples, source/output hashes and fresh completion |
| `placement-snapshot.json`, `contact_interface-snapshot.json`, `measurements-snapshot.json` | Exact consumed raw bytes, not reformatted approximations |

**STL is unitless: import mm,100%, without scaling.** Files retain assembly
coordinates, not print-bed coordinates; translate/reorient only for a separately
approved inert print. No G-code, printer job, physical drilling or fabrication
order is supplied.

Dark-grey F and brown B boxes distinguish the board faces; contact metal is
silver, body green, yoke amber, cradle/cover blue/cyan and cell purple.
`ConstructionReferences` contains hidden gauges, alternative/exact-source
comparison shapes and the USB anchor reservation, not extra fitted parts.
View properties are written headlessly; parent coordinates the actual GUI review.

### Contact geometry and the deliberately limited PCBA print dummy

The source spring polyline is its **cell-facing boundary**. The0.30 mm
thickness extends outward +X for BT1 and -X for mirrored BT2. Segment coordinates
are checked, and contact material must not penetrate the nominal cell.
Loaded ear angles are[-80,52] and[128,260] degrees, innerR8.2/outerR8.5.
The17.0 mm loaded outer width is an unqualified kinematic assumption, not an
approved deformation from the drawing's16.61 mm unloaded reference.

The contact base/spring junction has four nonmanifold mesh edges outside the
narrow outer solder tab. The full native/STEP geometry remains unchanged;
no connecting metal is invented to make an STL pass. The released PCBA STL
therefore explicitly omits BT1/BT2. They remain in the fitted83-component model
and BOM and are **not** reclassified as copper-only features.
Each contact is one instance containing three BRep solids; their fold-root
geometry and actual loaded form still need review. The report records the
nonmanifold edge endpoints/facet counts. No full-contact PCBA STL is released.

## Measurements versus assumptions

The model prioritizes owner-measured **ID71.68 atz0, ID69.75 atz4.9 and rough
ID50 atz14.9**. The first concave section ends at4.9+10=14.9, explicitly
confirmed. **ID36.12 at approximatez41.75 is inferred**, not measured:
OD38.42 minus twice the owner-requested1.15 wall assumption.

The1.15 mm wall is a **radial offset**, not constant normal thickness.
Working ODs at the first three stations are73.98,72.05,52.30; raw observations
remain73.15,73.15,51.50. The disagreements are preserved in the exact record.
Concave interpolation, the straight upper taper and the final closure above
z41.75 are provisional. Roundness, paint, uncertainty and handle-fastener
intrusion remain unmeasured. Handle exterior H85.5/D18.52..15.01 does not imply
usable internal handle space.

The fixed register follows that inner profile throughz9 with an assumed0.30 mm
radial print clearance. Two localized carrier pads intentionally bear on the
working cavity at the shell fasteners. The **D75.5 flange is external** and now
ends at the mouth plane; it is not shrunk to fit inside ID71.68. The external
skirt connects the mouth to the translated front plate. It projects6.25 mm
before the lower plate/grille; the grille front is10.75 mm outside the mouth.
Cosmetic overhang, mass, strength and acoustic behavior are not qualified.

Speaker dimensions remain D40/H19, rear basket D32 at speaker-relativez12 and
magnet D21.70/H7. The conservative conditional body remains D40 through the
basket depth, followed by the magnet; the illustrative tapered basket is not
substituted to hide collisions. Opening D22.1 gives0.4 mm diametral nominal
magnet play; the rear-basket gap remains0.3 mm. These are print assumptions,
not measured tolerances, permissible preload or a reason to force the speaker.
Rim bearing, intermediate basket, terminals, wire exits, vent and cone excursion
remain unknown.

## Four pieces, load paths and M2 hardware

The body integrates grille/seat, fixed register, external skirt, supports and
USB bezel. The removable yoke closes the speaker loading path and supports
the PCB. The cradle and separate cover provide positive can/end capture.
Cell loads are intended to pass through the cradle legs, locally supported
board mounts, yoke and body rather than SMT solder joints. Loaded force sharing,
spring travel, torque, creep and retention strength remain unqualified.

**M2 means2 mm nominal thread, not M3.** The board holes are2.2 mm clearance
drills. Hex nut pockets are not heat-set-insert pilots.

| Joint | Hardware / nominal stack |
|---|---|
| Two body-to-yoke joints | M2x6 cap screws and M2 nuts;1.45 mm roof,1.6 mm full nut engagement,0.4 mm blind-tip gap |
| Two PCB/cradle-to-yoke joints | M2x6 cap screws and M2 nuts;1.40 mm roof,0.8 mm clamping floor,1.1 mm blind-tip gap |
| Two cover-to-cradle joints | M2x6 cap screws and M2 nuts;1.45 mm roof,0.3 mm blind-tip gap |
| Two shell-to-carrier joints | Insulating nylon M2x6 screws and M2 nuts, separate from board hardware |

All six metal screws use the same M2x6 size. The dimension screen uses
DIN934-style nuts AF4/H1.6, ISO4762-style cap heads D3.8/H2 and nominal1.5AF
hex-key access. Nut pockets AF4.2 and screw bores D2.2 are unqualified print
allowances. Family references: [DIN934](https://www.fasteners.eu/standards/DIN/934/)
and [ISO4762](https://www.fasteners.eu/standards/ISO/4762/). No chosen supplier
lot, nylon head shape, thread form, knurl, torque or pullout rating is qualified.
The old D3xL4 insert placeholders are not reused.

The six metal nuts enter **sideways beneath real roofs** belonging to the part being fastened.
A top-open nut pocket closed only by the next part would not clamp its parent.
The engaged screw prevents sideways escape; a fully removed screw can release
a nut, so service over a tray with no live cell.
The two nylon shell nuts instead enter from the bell-axis side along open-ended
hexagonal sockets aligned with the inclined shell screws. A vertical insertion
chute was collision-checked and rejected. Their final outer nut faces bear on
the socket roofs; nominal engagement is1.6 mm with0.55 mm of screw beyond each
nut. The declared insertion path is included in the BRep report.

PCB screw heads end atz18.65 inside cups endingz19.90, recessed1.25 mm axially
and1.30 mm radially. Lower and cover screw guards are integral printed features.
The two shell screws follow the working lip's surface normal, approximately
**11.14 degrees handleward from the local radial direction**. Their under-head
planes contact the modeled outside instead of floating above it; local carrier
pads bear on the inside. These are proposed CAD/template locations, not
instructions to drill an unmeasured bell. Nylon substitution, paint damage,
clamping pressure, weakening of the shell and installation tooling remain gates.

## Assembly and service path

1. Outside the bell and before the yoke/PCB, load the nylon shell nuts from the
   inner ends of their inclined hexagonal sockets. Load the lower metal body nuts next: lower them
   through the register at radius26.5, move outward above the supports, lower
   at radius29.1, then slide inward into the roofed pockets. The report records
   the waypoints; do not push nuts through the external skirt.
2. With yoke/PCB absent, lower the speaker front-first onto its shifted seat.
   Its D40 frame cannot pass through the installed D22.1 capture opening.
3. Lower the yoke over the magnet and fit its two M2x6 screws. Do not preload
   an unverified speaker bearing surface.
4. Side-load the yoke-boss nuts, lower the PCBA into the **open-top** USB bezel,
   add the empty cradle and install the two recessed M2x6 screws.
5. Evaluate only with an inert cell, side-load the cover nuts and fit the cover.
   Positive retention does not qualify actual cell insertion, contact load,
   wrapper abrasion or reverse-insertion behavior.
6. Unplug USB and remove both shell screws before sliding the whole cartridge
   through the mouth, aligning its bezel with the mouth-open -Y slot.
   The front flange and carrier pads are the load-bearing interfaces, not USB
   solder anchors. Fit the insulating shell screws only after owner review.

For service unplug first, remove both shell screws and withdraw the **whole
cartridge mouthward (-z)**. Remove the cover/cell, then cradle/PCB, then yoke
and speaker as needed. The slot is open all the way toz0; a closed side hole
would trap a protruding USB connector. Nut, screw-tool, speaker, yoke, PCB,
cover and complete-cartridge motions are recorded as exact swept bounds where
available and explicit pose samples otherwise. They do not prove every tilted,
cabled or deforming motion.

The under-USB ledge ends atz10.55, leaving0.2 mm to the source body'sz10.75
underside. The proposed slot ends atz17.75 and bezel atz17.45. The source mouth
y-27.90 is approximately0.045 mm outward of the working shell at midpointz12.5;
the curved wall creates a different recessed/protruding band at other heights.
**No whole-face flush or selected-plug claim is made.** The unselected
8.8x8x2.6 mm plug-nose approach screen is not an approved mating travel/overmold.
USB tails remain unmeasured: copper1x2 and drill0.60 dimensions are not metal
tail dimensions. The full B projection is retained as a hidden planning
reservation, not a fabricated occupied height. Inherited electrical USB-hole
clearance findings are not waived or resized here.

## Fit evidence and remaining gates

The owner's later visual estimate of approximately 1 mm spare speaker-to-PCB
space is recorded as an estimate, not a measured minimum clearance.
`speaker_pcb_spacing_sensitivity` in the fit report compares 0.5 and 1.0 mm
PCB-only mouthward reductions with the speaker fixed. It preserves each
component's height/XY and reports individual speaker and unchanged-yoke
contacts/intersections. These comparisons do not modify the delivered
placement, supports or USB interface. A zero-distance contact is not positive
assembly clearance; reclaiming space by relocating parts is a separate design
change, not justification for silently shortening every standoff.

`fit-report.json` is authoritative for the current generated results. It
includes all physical pair intersections, uncut/cut shell comparisons,
metal-to-shell distances, the full guard stock **before** contact/PCB reliefs,
and a measured BRep material section under the cell.

The1.0 mm exterior guard uses0.10 mm clearance assumptions. Contact-ear pockets
follow the actual supplied angular sectors rather than erasing a full cylinder
through the bottom support. At x8/y0 the available under-cell section is1.08 mm;
the build checks that actual cradle material retains at least the chosen1.0 mm.
Other contact pockets use matched rounded offsets so a square clearance corner
does not thin a rounded outer wall. Each actual pocket BRep is positively
offset by1.0 mm; Boolean containment proves the entire expanded pocket stays
inside its stock. Additional containment checks establish the corresponding
bound for the union, before intentional PCB landing and fastener reliefs.
The report retains every witness and verifies that the global pocket contains
no unproved extra void. This constructive3D bound avoids an unsupported OCC
nested-shell extrema operation; it is not a bounding-box or single-height
proxy. Neither it nor the specific under-cell section is a global dielectric
or tolerance rating.
Intentional SMT lands terminate at PCB B; there is no plastic forced through FR4
to claim insulation, and no guard is clipped to the shell.

The bare T8 D16.4/L34, exact positive button, maximum cell dimensions, loaded
ear geometry and contact force remain unqualified. Positive ears approach the
wrapped negative can; the wrapper is **not credited as qualified independent
insulation**. Raw cell negative must remain isolated from both bell and
protected GND when the low-side protector opens. The circuit cannot clear a
short made directly across the raw cell outside its protected interface.

Minimum speaker/component and yoke/component gaps remain0.5 and approximately
0.25 mm; L1 is kept at its full5.0 mm height and its cradle gap remains0.30 mm.
These and the0.294 mm guard/shell margin require physical dimensional review.
Selected plastic/material, manufacturing variation, thermal/charge policy,
live-cell identification, vent clearance, reverse insertion, strength,
drop/shake, acoustic behavior and eventual child suitability are still gates.
**A nominal fit result is not routing, fabrication or safety signoff.**

## Reproduction and attribution

See [REPRODUCE.md](REPRODUCE.md). STEP precedes tessellation; native and STEP
are reopened and compared by BRep symmetric differences, not only bounding
boxes. Released STLs are reimported as closed manifold meshes and reconstructed
BReps. Raw source/measurement/electrical bytes and hashes are preserved.

Original geometry, code, SVG and documentation are MIT under
[mechanical/LICENSE](../../LICENSE). No vendor photograph, third-party CAD or
manufacturer mesh is copied. Mixed populated exports retain the adapted
electronics' **CC BY-SA3.0** context and complete
[hardware notices](../../../hardware/handbell/README.md) and
[attribution policy](../../../ATTRIBUTION.md), including Limor Fried/Ladyada
for Adafruit Industries (5768/4654) and Bryan Siepert for Adafruit Industries
(4438). Carry those notices with standalone populated files.

Owning epics remain E01/#1 (measurements), E04/#4 (electrical/contact interface),
E05/#5 (capture/service), E07/#7 (placed review before routing), and E10/#10
(eventual insulation/retention/use qualification). No purchase, physical
modification, routing, GUI launch or commit was performed by this mechanical task.

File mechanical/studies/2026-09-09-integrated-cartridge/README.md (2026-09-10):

# Integrated cartridge - two-piece mechanical draft

**An original, implemented fit/structural concept, not a complete retained
battery assembly or a qualified instrument.** The former separate grille,
speaker seat and lower supports become one printed body. One removable
capture yoke carries the PCB and closes the speaker-loading opening.
There are **two primary printed structural pieces**, four ordinary M2 screw
placeholders, four metal insert placeholders and two PCB washers.

The speaker can be inserted directly from the rear **before the yoke and PCB
are installed**. No claim is made that a D40 speaker passes through the
installed D22.8 capture opening. The yoke is intentionally removable rather
than a thin flex clip. No cell retainer is supplied or qualified.

Original cartridge section and shared-coordinate component plan

## Delivered artifacts

| File | Purpose |
|---|---|
| `integrated-cartridge-draft.FCStd` | Native selectable BReps, individual F/B component envelopes, full alternative battery bodies, Parameters record and embedded builder/helper/input source snapshots |
| `integrated-cartridge-assembly.step` | Body, removable yoke, conditional speaker body, fused populated PCB and metal hardware placeholders; no unselected battery or assumed shell in this assembly |
| `INERT-integrated-grille-seat-body.stl` | First primary structural piece: integral grille, annular front seat, lip register and opposed lower supports |
| `INERT-removable-capture-yoke.stl` | Second primary structural piece: rear capture ring, screw ears and locally supporting PCB bosses |
| `populated-wing-pcba-proxy.step`, `INERT-populated-wing-pcba-proxy.stl` | Single connected substrate-plus-73-component union with both 2.2 mm mounting drills; no enlarged components or extra bridging material |
| `INERT-measured-speaker-body-screen.stl` | Optional fit dummy, not an additional structural piece; D40 through z12 plus D22 magnet through z19 |
| `placement-snapshot.json` | Exact consumed schema-2 bytes, not a rewritten approximation |
| `parameters.json` | Dimensional record of this build, not a stand-alone regeneration input |
| `shell-parameters-snapshot.json` | Frozen baseline shell parameters consumed by the reused profile helper |
| `fit-report.json` | Raw BRep intersections/distances, insertion sweeps/samples, battery failures, hardware stacks and round-trip results |
| `artifact-manifest.json`, `completion.json` | Input/output SHA-256 records and a fresh run-specific completion token |
| `review-status.json` | Export-hold status; cleared only after the regenerated CAD and reports reach successful completion |
| `integrated-cartridge-views.svg` | Original explanatory section and common-XY two-face plan; not vendor artwork |
| `freecad-build.log` | Local console diagnostics, Git-ignored; no GUI was launched |

All coordinates are **mm**, with opening z0 and +z inward. CAD/STL objects
retain assembly coordinates. **Do not scale these files to fit.** Translate
to a print bed only when preparing an inert sample: the body starts at z-4.5,
yoke at z9, PCBA components at z17 and speaker at z0. The two-sided PCBA proxy
has no full flat board face to put directly on the bed; its printing orientation,
supports and small-feature reproduction require separate consideration.
No G-code, print job or fabrication package is supplied.

## Frozen interface and actual input

The board is D43 x 1.6, F substrate face z20.5 toward the speaker and B face
z22.1 toward the handle. Component XY, rotation, footprint, side, dimensions
and explicit z bounds are consumed without adjustment. There are 62 F and
11 B fitted proxies.

MH1 is (+10,+15.7), MH2 (-10,-15.7). The **actual supplied manifest has 4.4 mm
pad diameters**, rather than the initial 4.2 mm planning value. Both drills
remain 2.2 mm, GND-assigned, with 3.2 mm-radius reservations on both faces.
The yoke's D6.4 PCB bosses stay inside those reservations; this builder does
not alter the PCB, pads, nets or source manifest. GND assignment is not
electrical connection on an unrouted board.

Consumed placement SHA-256:
`d78f06c8793b69e0d4d2ae1dab5687bb57284abac32e0f68830c0995b6bd8f34`.
The input section of `fit-report.json` also records the manifest's electrical
PCB/schematic hashes and the frozen helper hash. The old print artifacts and
measured-speaker study are not regenerated.

## Geometry and mechanical load paths

| Feature | Draft dimensions / meaning |
|---|---|
| Integrated body | D72 outer flange, z-4.5..9; 2.7 mm annular plate with 1 mm axial grille-root overlap; D69 lip register z-1..2 inside assumed ID70 mouth |
| Speaker front seat | D36 aperture, outer D40.4, top z0; actual rim bearing width is unknown |
| Grille | 1.8 mm web, z-4.5..-2.7, nominal 2.8 mm slots on 4 mm pitch; no excursion/acoustic approval |
| Opposed lower supports | Radius22.6 on MH radial axis, 4.6 radial x 7 tangential, ending at z9; clear basket passage D40.6 |
| Capture yoke | Ring ID22.8 / OD37, z12.3..14.8; wider 8 mm screw ears, PCB bosses D6.4 ending at z20.5 |
| Lower fasteners | Two M2x8 placeholders, shanks z3.5..11.5, heads D3.8 x H2 at z11.5..13.5; inserts D3 x L4 at z5..9 |
| PCB fasteners | Two M2x6 placeholders, shanks z16.4..22.4; D4 x 0.3 washers at z22.1..22.4; heads through z24.4; inserts z16.5..20.5 |

PCB clamping passes through each washer, locally supported substrate and
yoke boss, then through the capture arms and the two lower M2 joints into
the integrated body. The speaker bears on the front seat, with the removable
yoke limiting rearward/lateral movement. Its loads need not pass through an
unsupported PCB, solder joint or battery contact.

The lower fastener pockets leave nominal 0.8 mm radial plastic walls and
1.95 mm tangential ligaments around the head counterbores. These are
geometrical dimensions, **not** insert-installation or pullout approval.
Nominal thread-engagement envelopes are 4 mm; screw-tip to blind-hole-bottom
gaps are 0.3 mm below and 0.6 mm at the PCB. Real screw tolerances, insert
knurls, installation tools, torque, washer finish, layer orientation, creep
and local IMU stress remain gates. The model uses smooth metal placeholders,
not printed/custom helical threads. No fastener penetrates the central
battery planning corridor; actual electrical insulation is still required.

The integral D69 lip register **locates but does not attach** the cartridge
to the shell. The D72 flange deliberately remains outside the mouth.
Adhesive/paint compatibility, a positive shell attachment and insertion/USB
loads into that attachment are unresolved. There is no invented handle
interior, concealed bonded mounting ring or third structural print.

## Exact assembly sequence and evidence

1. Outside the bell, inspect both inert prints and install the selected metal inserts only after resolving their actual installation dimensions. Keep all live cells absent.
2. With the yoke, PCB and screws absent, lower the speaker axially, front-first, until its front rim reaches the z0 seat. The lower supports leave a D40.6 passage for the D40 body.
3. Lower the yoke over the D22 magnet, onto the two lower support tops. Install the two M2x8 screws from the handle side before fitting the PCB.
4. Lower the populated PCB onto the two D6.4 bosses. Add the two washers and M2x6 screws from the handle side. Support the board locally; do not use torque to pull a warped PCB flat.
5. Inspect the remaining access/clearance gates. Do not install an unselected cell or treat the lip register as secure shell attachment. Reverse the order for speaker service.

`assembly_paths` contains an exact swept union of the stepped speaker for
50 mm axial travel and 26 pose samples, checked against the integrated body.
It contains conservative yoke translation bounds for 40 mm travel plus
21 poses against the seated speaker/body, and a 30 mm conservative populated
PCBA sweep against installed lower hardware and structure. These paths have
zero modeled material intersection at the supplied input. Intended bearing
contacts have zero distance; that does not mean interference.

The wrong sequence is also recorded: attempting rear axial speaker insertion
with the yoke installed produces a large swept collision. Positive stop
probes show intersections for 0.5 mm axial displacement and eight 1 mm lateral
displacements, rather than relying solely on gravity. These are rigid-body
stop probes, **not** proof of all possible tilted escape paths, sufficient
retention strength or a suitable bearing surface on the real driver.

The stepped D40 z0..12 + D22 z12..19 speaker is a **conditional body screen**.
The straight D40-to-D32 basket in the native file is only illustrative.
The real rim, intermediate basket, terminals, wire exit, rear vent, excursion
and dimensional tolerances are unknown. In particular, a measured D32 rear
basket station does not establish that the capture annulus may safely bear
there. The 0.3 mm axial gap and 0.4 mm radial magnet gap are assumptions.
The speaker-front z0 placement is also assumed.

## Retained fit findings and battery blockers

There are no speaker/component or yoke/component material intersections in
the supplied 73-part screen. Minimum component-to-speaker separation is
**0.5 mm**. The closest component-to-yoke gap is only **0.254 mm at U3**;
this is not a tolerance, vibration or IMU-stress allowance.
The yoke clears the assumed shell by only **0.263 mm**, and the lower screw
heads by **0.354 mm**. These small nominal distances do not establish usable
manufacturing or real-shell clearance.

X6 remains `required_not_implemented` for a shell access cutout even though
its new F-side body proxy has **0 mm3 raw uncut-shell intersection**.
Its full bounds are x-4.82..4.82, y-21.965..-14.035, z17..20.5.
Do not interpret a contained connector box as an accessible USB port.
Plug/cable travel, through-board anchors, connector support, insulation and
a manufacturable cutout remain unresolved; no shell material is silently cut.

The manifest's **10.64 x 8.93 mm B-side USB projection**, centered at
(0,-18), is screened separately against B components, structure, hardware,
the optional floor and every battery alternative. Its native construction
prism extends z22.1..43 conservatively because the anchor height is unknown:
**43 mm is the assumed cavity-depth limit, not a claimed anchor height.**
It is not fused into the PCBA or included as material in the assembly STEP.
Individual USB anchor/solder volumes and PTH/NPTH holes are not supplied as
3D primitives; the PCBA dummy is not a gauge for those omitted details.
Raw overlaps and distances are in `cross_face_reservations`, separate from
actual material collisions and the required shell access cutout.

Battery bodies are **not** shrunk or clipped. Cylindrical axes are X; pouch
long dimensions are also X to match the central x+/-19, y+/-10 planning
corridor. The alternatives are mutually exclusive native reference bodies,
not installed objects in the STEP assembly.

| Full bare body | Bottom z23.1: 1 mm above PCB | Bottom z24.6: illustrative floor/contact lift |
|---|---|---|
| Protected 16340 example, D16.8 x L34 | About 0.43 mm shell distance | About 0.04 mm shell distance |
| Fenix ARB-L16-700UP published D16.8 x L35.5 | About 1.37 mm3 outside cavity | About 16.48 mm3 outside cavity |
| Pouch 28X x 18Y x 8Z | About 3.41 mm shell distance | About 3.02 mm shell distance |
| Pouch 30X x 20Y x 8Z | About 2.07 mm shell distance | About 1.69 mm shell distance |

An **unattached** 38 x 20 x 1.5 floor sensitivity is modeled in full at
z22.6..24.1, with cell bottom z24.6 leaving 0.5 mm above it. It is not a
printed part, a load-bearing connection or an implemented cradle. The full
cells move with the lift; no original cell underside is retained by clipping.
Uniform 0.5 and 1 mm envelope sensitivities are also reported.

With 0.5 mm clearance, even the shorter cylindrical example has about
1.19 mm3 outside the cavity at the no-floor position, rising to about
14.58 mm3 after lift. The larger pouch's 0.5 mm envelope at z23.1 intersects
the populated PCB by about 2.23 mm3, despite clearing the shell. The raw
failures remain in the report.

**No complete battery retainer fits by declaration here.** There are no end
stops, independent top capture, contact travel model, wrapper-safe supports
or selected cell/insulation system. Contacts must not be structural restraint;
a bare floor cannot replace cell protection. The compact example's current
capability is unqualified; the Fenix published 2.5 A claim does not solve its
longer body's mechanical interference or unspecified tolerances. No live-cell,
child-use, PLA temperature, shake, drop or electrical qualification is implied.

## Reproduction and source editing

From `C:\Projects\dcuccia\digital-handbell`:

```powershell
$FreeCAD = "$env:LOCALAPPDATA\Programs\FreeCAD 1.1\bin\FreeCADCmd.exe"
python .\tools\build_integrated_cartridge.py --freecad-cmd $FreeCAD --placement .\hardware\handbell\iterations\wing-draft\placement-manifest.json
```

The exercised toolchain is FreeCAD **1.1.3**, OpenCASCADE **7.8.1**, bundled
Python **3.11.14**. No new packages or GUI are used. `--placement` is required;
schema, dimensions, faces, z bounds, hole interfaces and electrical hashes
are checked. There is no fallback to the old placement. Missing or invalid
input fails, and a unique completion token prevents FreeCAD's interactive
console returning zero after a Python exception from looking successful.

STEP is exported before tessellation so OpenCASCADE's mesh-cached bounding
boxes cannot contaminate the exact STEP-bound comparison. STEP is reopened
for solid-count, volume, bounds and mm-unit checks. Each STL is reimported
as a single closed manifold mesh and reconstructed BRep; FCStd is reopened
and its solids/source records checked.

Native solids can be inspected/edited in FreeCAD; the source snapshots
describe their construction. For reproducible changes, edit the **new**
builder's geometry and dimensional record together, then rerun. The
Parameters spreadsheet is a record, not a live expression-driven model;
editing it alone does not recompute the BReps. Hide the assumed shell,
individual proxy group, cross-face planning reservations and unselected
battery/reference objects when viewing only the assembly. The historical
`tools\build_mechanical.py` is imported
unchanged and enforced against its frozen SHA-256.

## Original work and retained electronics context

Original mechanical primitives, this illustration, documentation and the
new builder are MIT under [the mechanical license](../../LICENSE).
No third-party printed design, manufacturer CAD, vendor photograph or image
was copied. The mixed assembly/PCBA context retains the adapted electronics'
**CC BY-SA 3.0** scope; it is not relicensed MIT merely by using simple boxes.
See [mechanical attribution](../../README.md),
[handbell notices](../../../hardware/handbell/README.md) and
[project attribution](../../../ATTRIBUTION.md), including the source notices
for Limor Fried/Ladyada and Adafruit Industries, and Bryan Siepert for
Adafruit Industries for the SOX hardware. Attribution does not imply endorsement.

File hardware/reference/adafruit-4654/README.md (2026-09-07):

# Adafruit MiniBoost TPS61023 reference

**Immutable imported reference, not a qualified handbell power supply.**
Source: [Adafruit TPS61023 PCB](https://github.com/adafruit/Adafruit-TPS61023-PCB/tree/82b5a33a1900a5c13849029bc84e7856a44086e0),
product [4654](https://www.adafruit.com/product/4654), commit
`82b5a33a1900a5c13849029bc84e7856a44086e0`.

Designed by **Limor Fried/Ladyada for Adafruit Industries**. The complete
[original README and required notice](upstream/README.md) and
[CC BY-SA 3.0 Unported license](upstream/license.txt) accompany byte-exact
EAGLE sources. Native conversions retain those terms, not the root MIT license.
This reference/adaptation is not an Adafruit endorsement.

KiCad 10.0.6 imported the schematic through its EAGLE project importer and the
PCB through its native CLI. The
[import record](reports/import-review.json) contains source hashes:
**six source connection groups match**, and **18 physical pads** in the seven
standalone footprint types match source locations, dimensions and rectangle axes.
Standalone footprints were normalized from native PCB poses before use.

The [reference ERC](reports/reference-erc.json) retains its **four initial
findings**, not suppressed or confused with the handbell derivative's ERC.
The [PDF](reports/reference-schematic.pdf) and
[netlist](reports/reference-netlist.xml) support review. Raw PCB import is not a
complete routing/geometry/thermal audit; do not assume it proves source copper
fidelity merely because standalone lands were checked.

The source divider is **732 kohm / 100 kohm**, approximately a 5 V rail despite
the README/product's 5.2 V prose. It uses TPS61023, 1 uH in a 5 x 5 mm footprint,
three 22 uF/0805 capacitors and default EN pull-up. It is **not a charger**.
Exact magnetic/capacitor MPNs and ratings remain unresolved for the handbell.

The [0.2 derivative](../../handbell/README.md) omits the default-on EN pull-up,
uses the existing GPIO23 POWER pull-down/switching, adds an optional DNP
feed-forward provision, and supplies the amplifier through VAMP. It does not
modify this reference or blindly reuse its routing.

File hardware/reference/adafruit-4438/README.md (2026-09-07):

# Adafruit 4438 LSM6DSOX reference

Pinned, unchanged EAGLE source plus a KiCad 10.0.6 conversion, made 2026-09-07.
This is a **reference**, not the handbell derivative or a fabrication release.

Source: [Adafruit-LSM6DSOX-PCB](https://github.com/adafruit/Adafruit-LSM6DSOX-PCB/tree/c05abef4675b0380fbf3d23171615a2f1ac0b130),
commit **`c05abef4675b0380fbf3d23171615a2f1ac0b130`**.
[Product 4438](https://www.adafruit.com/product/4438);
[learning guide](https://learn.adafruit.com/lsm6dsox-and-ism330dhc-6-dof-imu).

**Designed by Bryan Siepert for Adafruit Industries.** This package and its
derived CAD/review exports retain **CC BY-SA 3.0 Unported**, not the root MIT
license. See the [complete license](LICENSE.txt), the verbatim
[upstream README](upstream/README.md) and [upstream license](upstream/license.txt).
The original README, including its asset links, is unchanged; product images
are not vendored. This project is not endorsed or manufactured by Adafruit.

## Source bytes

Downloaded directly from the pinned GitHub revision; `.gitattributes` disables
line-ending conversion for `upstream/**` and the copied license.

| File | SHA-256 |
|---|---|
| `Adafruit_LSM6DSOX.sch` | `7fe13187c92c2170aa739ca57b0ee3c0541cc95609738b708574141811c1302c` |
| `Adafruit_LSM6DSOX.brd` | `42b56029ffb6dddc04ed11b2173ebecbe7d558b3489007661546e2276abea58a` |
| `README.md` | `baeae983e8d6afd022d590fa3b07986c18d62cfbf57a65a75fa80cc6a9fd9f7b` |
| `license.txt` | `075dad5e5fc96c27014fabc269f4f5732909cffd178a486f546d982b6cf86b74` |

## Conversion and evidence

Used **File > Import Non-KiCad Project > EAGLE Project**, selected the pinned
schematic and matching board, auto-matched imported layers, and saved both
editors. Native files and project-local libraries are in `kicad`.

- [Schematic PDF](reports/reference-schematic.pdf)
- [XML netlist](reports/reference-netlist.xml)
- [Initial ERC](reports/reference-erc.json): **24 findings retained**, not waived.
- **All 17 nonempty upstream board-signal connection groups match** the native
  schematic. This source needs no reference-designator renaming for comparison.
- The LGA-14L import preserves all **14 numbered lands**, their positions,
  sizes, rectangular-pad axes, and top copper/paste/mask layers. GND's two
  physical pads, 6 and 7, remain separate stacked symbol pins.

Reproduce the net/pad comparison with
[`tools/check_handbell.py`](../../../tools/check_handbell.py) as described in
the [derivative handoff](../../handbell/README.md). Its
[report](../../handbell/reports/connectivity-review.json) records the results.
This does not establish complete board-geometry, design-rule, assembly,
functional or safety equivalence. The breakout's remaining ERC findings have
not been silently edited out of this reference.

Only the sensor symbol and footprint are reused by the handbell. The derivative
follows ST's fixed Mode 1 wiring rather than copying the breakout's auxiliary
header and floating SDx/SCx connections. Its regulator, level shifters, CS diode
and resistor networks are not needed on the common 3.3 V handbell bus.

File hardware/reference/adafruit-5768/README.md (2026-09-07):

# Adafruit 5768 reference: EAGLE sources and KiCad conversion

**Reference only: not a custom digital-handbell schematic or fabrication
package.** No intentional circuit reduction or sensor substitution has been
made. The imported reference is not yet fully reviewed or ERC-clean.

## Provenance and license

- Original design: **Limor Fried/Ladyada for Adafruit Industries**.
- Product: [RP2040 Prop-Maker Feather, PID 5768](https://www.adafruit.com/product/5768).
- [Learning guide](https://learn.adafruit.com/adafruit-rp2040-prop-maker-feather).
- [Pinned hardware source](https://github.com/adafruit/Adafruit-RP2040-Prop-Maker-Feather-PCB/tree/408fa9a40c0a01a3a65497ef42a29e0b08fe711e):
  `408fa9a40c0a01a3a65497ef42a29e0b08fe711e`.
- Original CAD: EAGLE XML 9.6.2.
- Conversion: KiCad 10.0.6 on 2026-09-07, using the built-in GUI project importer
  and automatic layer matching.

**This entire reference package, including adapted CAD and derived exports, is
distributed under [CC BY-SA 3.0 Unported](LICENSE.txt), not the repository's root
MIT license.** Preserve the complete [upstream README](upstream/README.md) and
[original license](upstream/license.txt) with redistribution. Upstream markings
are retained to identify the reference, not to imply Adafruit endorses or
manufactures this project's future derivative.

## Contents

| Directory | Purpose |
|---|---|
| `upstream` | Unmodified source `.sch`, `.brd`, README, and license from the pinned commit |
| `kicad` | Saved native project, schematic, PCB, imported symbols/footprints, and project-local library tables |
| `reports` | Schematic PDF and initial ERC JSON from the converted reference |

Open `kicad\Adafruit Feather RP2040 Prop-Maker.kicad_pro`.
The imported footprint library has 116 files. Machine-local `.kicad_prl`, lock
files, temporary source copies, and editor history are not part of the package.

## Original source SHA-256

| File in `upstream` | SHA-256 |
|---|---|
| `Adafruit Feather RP2040 Prop-Maker.sch` | `B94E1E25F71B7F7B6AB203B362476060F20FC40AA0F0B3186E82D129BE12D5ED` |
| `Adafruit Feather RP2040 Prop-Maker.brd` | `D1F434C1DA4D7AB0B70ECD9EE710E3150E708AB6D29B9648DEE83500349EC43B` |
| `README.md` | `4170E40C048C0C33A510486BC43CD7C6FC78AAF5A4617EC748DF938E43716C2B` |
| `license.txt` | `075DAD5E5FC96C27014FABC269F4F5732909CFFD178A486F546D982B6CF86B74` |

These are the raw upstream Git object bytes, not a Windows CRLF-normalized
checkout. The local `.gitattributes` preserves those bytes on future checkouts.

## Initial import evidence

The GUI conversion produced saved native files and project-relative library
references. Native schematic XML-netlist and PDF export succeeded. The
schematic export contains 77 component entries and 78 nets, including additional
unconnected-pin nets generated by KiCad.

Electrical partition comparison used the original EAGLE board's physical
`contactref` element/pad groups and the converted schematic's exported
reference/pin groups. It found **71 matching nonempty signal groups, with no
group-membership differences**, after the following importer renames:

| EAGLE reference | KiCad reference |
|---|---|
| `CHG` | `CHG0` |
| `CHG_EN` | `CHG_EN0` |
| `GAIN` | `GAIN0` |
| `L` | `L0` |
| `OUTPUTS` | `OUTPUTS0` |
| `SERVO` | `SERVO0` |

These names were also observed in the imported PCB. Three additional upstream
board signals have no contact references and were excluded, not treated as
connected nets: `PB22/I6/SERCOM5.2`, `PB23/I7/SERCOM5.3`, and
`PB03/I3/AIN11/SERCOM5.1`.

This comparison checks preservation of the populated source connection groups.
It is not full schematic-to-board synchronization, a package/pad review,
confirmation of unrouted geometry, or functional verification.

## Known conversion findings

The [initial ERC report](reports/reference-erc.json) has **50 findings**:

| Severity/type | Count | Disposition |
|---|---:|---|
| Error: power pin not driven | 8 | Review source power intent and KiCad pin types/power flags |
| Error: pin not connected | 5 | Review intended NC pins versus missing connections |
| Warning: isolated pin label | 2 | Inspect imported label attachment and intended net |
| Warning: unconnected wire endpoint | 35 | Inspect import geometry and dangling source stubs |

Do not blanket-exclude these or assume they are all harmless. No changes were
made merely to obtain a clean ERC result.

A separate CLI PCB-import experiment logged eight skipped package polygons on
EAGLE layers `Route2` and `Route15`. The source board's active layer setup is
`(1*16)`; those two layers are explicitly inactive, and its actual signal
polygons are on layers 1 and 16. The skipped polygons are library-package
content, not evidence that an active four-layer design was flattened.
Nevertheless, review their intended role and compare geometry before treating
any PCB conversion as fabrication-equivalent. The CLI JSON report had empty
warning/error arrays despite the console diagnostics: retain this distinction.

## Remaining work before deriving a release schematic

- [ ] Resolve or individually justify the ERC findings against upstream intent.
- [ ] Review symbol pin types, power flags, intended NC pins, net labels, and
  imported graphic/wire geometry.
- [ ] Check footprint pad mapping, orientation, exposed pads, mask/paste,
  board outline, stackup, zones, and project design rules.
- [ ] Confirm schematic/PCB identity linking and all library assets in a fresh
  checkout, not just successful rendering.
- [ ] Create the reduced handbell design separately and record every changed
  block, including any six-axis sensor substitution.

Tracked by [E02](https://github.com/dcuccia/digital-handbell/issues/2) and
[E04](https://github.com/dcuccia/digital-handbell/issues/4).

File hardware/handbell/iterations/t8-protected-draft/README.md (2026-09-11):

# T8 protected-contact placement draft

**2026-09-11: native schematic and complete new placement, deliberately
unrouted. Not for a live cell, fabrication, charging or child use.**

Open `handbell.kicad_pro` in **KiCad10.0.6**. Read the
[electrical revision](../../../../docs/t8-electrical-revision.md) for exact
pins, body-diode directions, protection thresholds/current tradeoffs,
source drawings and still-open temperature, reversal and charging gates.
This is separate from the frozen wing/reference/original projects.

T8 two-face placement

## Delivered artifacts

| Artifact | Scope |
|---|---|
| `handbell.kicad_sch`, `handbell.kicad_pcb`, `handbell.kicad_pro` | Native editable circuit/placement;104 references,83 fitted (70F/13B) |
| `T8.kicad_sym`, `T8.pretty`, library tables | New USON2x3, protector/FET/shunt and SMT-contact implementations |
| [Schematic PDF](reports/handbell-schematic.pdf) | Human-readable export, including a dedicated protection section |
| [XML netlist](reports/handbell-netlist.xml), [BOM draft](reports/bom-draft.csv) | Actual pin/net and fitted/DNP/copper inventory; not an order-ready BOM |
| [Placement manifest](placement-manifest.json) | Schema2 mixed-face components, explicitZ, actual substrate outline, USB/mount interface |
| [Contact interface](battery-contact-interface.json) | Drawing-based land datums and original **thin** contact primitives, not solid collision boxes |
| [Frozen XY seed](placement-xy-seed.json), [stack-shift evidence](reports/stack-shift-screen-evidence.json) | Retained native poses and exact bounded mechanical selection; not a full-assembly approval |
| [Correspondence review](reports/correspondence-review.json) | Native inputs/reports byte-bound, unchanged-pin and actual-pad checks |
| [ERC](reports/erc.json), [DRC](reports/drc.json) | Complete findings retained, not hidden by waivers |
| [Source evidence](source-evidence.json) | Reviewed manufacturer document revisions/hashes; documents not redistributed |

U1 is **W25Q16JVUXIQ TR /2MB**, not4x4. The8-part protection block uses
**BQ29700DSER+CSD83325L+33mohm shunt**, with both charge and all-load returns
on protected GND. **Raw CELL_NEG must not be bonded to USB/system ground**.
Two **Keystone254revC** B-side contacts replace X1 completely.

The conservative overcurrent choice can trip below2A at low voltage/hot
silicon. It is not a promise of2A continuous delivery, a3A hard current clamp,
or a complete BMS. Reverse-cell protection and cell-temperature charging
inhibit are **not implemented**. The unchanged196mA/14.7mA charger profile
needs agreement with the exact T8 specification. Use inert fit models only.

**Selected fit alternative: the whole internal stack moves 6.25 mm toward
the mouth**, preserving relative speaker/component/cell gaps. A 1.0 mm
plastic guard with 0.10 mm nominal clearance gives 0.29406 mm external
guard-stock/shell clearance in the bounded mechanical BRep screen.
The requested 1.5/2.0 mm shifts failed because of the upper contact spring,
not the bare cell. No cell or metal geometry was clipped.
The complete mechanical assembly must rebind to this selected manifest;
this bounded result does not qualify tolerances or the positive clip's
independent can insulation. See the
[selected stack translation](../../../../docs/t8-electrical-revision.md#mechanical-coordination-selected-stack-translation).

## Shared mechanical interface

- Main bodyD43; Fz14.25/Bz15.85. Mounts(+10,+15.7),(-10,-15.7):
  2.2mm plated drills/4.4mm pads assignedGND,3.2mm local support/tool reserve.
- Local contact support tabs extend tox=±22.25 overy=±2.3.
- USB tongue isx=±5.75, outery=-26.85; retained **body mouth** is(0,-27.90),
  not the footprint center. Shell opening and repeatable load support required.
  This projects0.0445mm at the working shell's connector-midheight station,
  not across its entire flat mouth on a curved shell.
  USB signal ground is system GND; shell anchors X6.M1-M4 remain unassigned,
  with no reviewed shield bond. Insulate the shield as a conductive interface.
- Provisional34.0mm-total button-top T8 lies alongX; cell centerz25.63,
  springtopz32.44. Speakerfrontz=-6.25; the mechanical grille projects farther
  outside while the measured mouth register/shell attachment remain fixed.
  Maximum length/button geometry conflict, tolerances, loaded contact span,
  spring travel/current rating and qualified retention remain open.
- The FreeCAD assembly must consume this exact new manifest, including
  substrate tabs/tongue and thin contact geometry, before routing review.
  Existing wing mechanical approvals do not transfer.

## Native results

**0ERC**. There are244 physical DRC findings:240 unfinished silk/text and
the four inherited internal USB hole-clearance findings. **222 unconnected**
items reflect no routing. **46 known CLI parity fallback findings** remain
in the full report. There is no new GUI parity approval.

No copper-clearance, mask-bridge, courtyard or library findings remain.
The BQ29700 footprint deliberately uses an all-NSMD adaptation of the
manufacturer's exposed-land dimensions instead of copying its larger
left-side SMD copper. The unchanged0.20mm rule was not weakened; the
land/mask/stencil choice remains an assembler-review gate.

## Reproduce

From repository root, with Python and the installed KiCad:

```powershell
python .\tools\draft_t8_placement.py --preserve-xy --front-z 14.25 --usb-mouth-y -27.90 --guard-mm 1.0
python .\tools\check_t8_placement.py --run-native
python .\tools\check_t8_placement.py
```

The original placement's deterministic seed was163404. The selected update
uses **zero optimizer steps** and the immutable `placement-xy-seed.json`;
all non-USB native XY/angles/faces remain unchanged. Later runs automatically
retain that seed. Add `--preview` for a non-writing parameter screen.
The generator reads frozen wing sources but writes **only this variant**.
It refuses edited/untracked native
schematic/board bytes, routed boards, changed project settings and changed
previously recorded local libraries/interfaces. Preserve manual work and
update handoffs deliberately; do not run a frozen/original generator over it.

`--run-native` performs ERC, native netlist, parity DRC and PDF export in
`reports\.native-run`, then removes that staging directory and records
`native-input-bindings.json`. This location is inside this project, not an
OS temporary directory. Later checks reject stale CAD/dependencies,
changed report bytes or a mismatched manifest. The selected source-measurement
bytes, frozen XY seed and bounded stack-screen snapshot are also bound.
The fast electrical shell screen uses station chords; the mechanical BRep
uses its separately declared curved working profile. Manually invoking native
commands alone does not renew the evidence binding.

No Gerbers, routed copper, manufacturing order, purchase, firmware test or
physical battery-safety approval is provided.

## Attribution

The adapted hardware remains **CC BY-SA3.0 Unported**, not the root MIT
license: see [complete LICENSE](LICENSE.txt), [upstream notices](notices/)
and the [project attribution policy](../../../../ATTRIBUTION.md).
Core5768 and boost4654 credit **Limor Fried/Ladyada for Adafruit Industries**;
SOX4438 credits **Bryan Siepert for Adafruit Industries**. Their pinned
source revisions and full notices remain intact. This is an independent
dcuccia adaptation with AI assistance, not an Adafruit product/endorsement.

Standard KiCad mounting/recovery/library material uses its library design
exception. The new pads/symbols/contact primitives are original factual
implementations, not copied manufacturer CAD. Vendor PDFs, images and
STEP models are not redistributed. Original generation/checking code and
documentation use MIT; that does not change the adapted hardware's license.

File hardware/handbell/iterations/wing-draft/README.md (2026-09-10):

# Two-face wing placement draft

**2026-09-09: a separate, unrouted electromechanical iteration.**
Open `handbell.kicad_pro` in KiCad 10. The native schematic/board live beside
this file; their libraries resolve to the preserved parent/reference packages.
The original handbell project, September 7 print kit and measured-speaker study
are unchanged.

Two-face planning view, common assembly coordinates

## What changed

The 43 mm board retains the existing circuit connectivity and part footprints.
It has **73 fitted components: 62 on F, facing the speaker; 11 on B, facing
the handle**. B contains the seven-part MiniBoost block and the four-part
amplifier/local-bypass block. The speaker connector and its output filter
remain on the speaker-facing outer annulus.

The old wired-battery connector X1 is **DNP in all three schematic units and
on the PCB**; C29 remains DNP. X1's footprint is retained as an unpopulated
provision, not a fitted 5 mm obstruction. No new contact footprint or reverse
insertion circuit is invented: battery/holder selection remains an electrical
freeze gate. This is not a complete, ready-to-power replacement battery input.

Two board-only plated M2 mounting footprints, MH1/MH2, are assigned to GND.
Their stock KiCad pads are **4.4 mm diameter with 2.2 mm drills**. They have
not become electrically grounded just by receiving a net name: the PCB still
has no tracks, vias or copper zones.

The 18 copper-only recovery/test/jumper features are on F and excluded from
the fitted BOM/placement-file inventory. They are principally board-out
bring-up access, not proven access through the assembled speaker/carrier.

## Shared mechanical interface

All dimensions are mm. The bell-opening plane is z0; +z points toward the
handle. F faces the speaker at z20.5; the 1.6 mm substrate ends at z22.1.

| Interface | Draft value |
|---|---|
| PCB | Diameter 43, thickness 1.6, front surface z20.5 |
| MH1 / MH2 centers | (+10, +15.7) / (-10, -15.7) |
| Hole copper / bore | Diameter 4.4 / plated drill 2.2, assigned GND |
| Support/head/tool reservation | Radius 3.2 about each mounting center on both faces |
| B-side battery/contact planning corridor | x=-19..19, y=-10..10; not a fitted holder envelope |
| B-side USB reservation | Center (0,-18), 10.64 x 8.93; USB body/drill projection plus 0.5 per edge |

`placement-manifest.json` is the schema-2 interface to the integrated-cartridge
study. Every fitted proxy has its actual side, center, rotation and explicit
z-min/z-max. Both diagram faces use **common assembly XY with +Y up**, not
mirrored photographs. Native KiCad coordinates are centered at (100,100);
for the speaker-facing F orientation, the common-frame rotation is the
negative native footprint angle.

**The USB's anchors extend through the PCB.** Initial placement under that
connector caused real rear-copper/drill conflicts, even though the SMT parts
were on opposite faces. The revised draft reserves that projection on B and
keeps the amplifier clear. Mating plug, actual anchor protrusion, slot,
insulation and cable/load-path dimensions still need review.

Mounting pads are not permission for metal fasteners to contact a cell can,
terminals or the bell. Support the PCB locally at fasteners and route
speaker/battery loads into the retaining structure, not through an unsupported
board or the IMU. Screw-head/washer size, shoulder/insert geometry, thread
engagement and bottom-out length remain explicit mechanical decisions.

## Electrical floorplanning versus geometric packing

The core starts from Adafruit 5768 relative placement. MCU, flash, crystal and
their fixed resistors retain their relative poses; local core capacitors are
translated by at most 1.2 mm before the cluster is placed, to remove crowded
courtyard relationships. The per-capacitor changes are recorded in the
manifest's local cluster frame.

The boost retains the pinned MiniBoost's internal placement as a rigid
seven-part block. Its source copper is **not copied**. This is a starting point
for short power loops and feedback separation, not a thermal/routing result.
The amplifier cluster explicitly moves C16 toward the transformed PVDD pads
7/8 and keeps bulk C19 adjacent instead of retaining the remote original
location. Other controls are still draft placements and need a routing-led
bypass/return-path review.

The planner reports zero inter-cluster envelope overlaps and zero current
boundary, mounting, battery-corridor or tall-front-part constraint violations.
Seven retained inflated planning-envelope overlaps remain within the boost
and fixed core relationships. These are not suppressed native DRC findings;
native copper, mask and courtyard results are recorded separately below.
Footprint-derived boxes/heights are not qualified manufacturer bodies.

## Native correspondence and remaining findings

[`reports/correspondence-review.json`](reports/correspondence-review.json)
binds the CAD, native reports and manifest. The source and candidate netlists
have identical pin/net connectivity, all 300 physical pads are accounted for,
and the project/rule settings are unchanged. Schematic changes are limited to
its title/revision and the consistent X1 DNP state.

| Native result | Disposition |
|---|---|
| ERC | 0 findings |
| Copper clearance, solder-mask bridge, courtyard and library issues | None in this candidate's native report |
| Physical DRC findings | 264 total: 116 silk-over-copper, 69 text-height, 68 silk-overlap, 4 hole-clearance, 4 silk-edge and 3 text-thickness |
| Four hole-clearance findings | The retained internal X6 USB geometry; still open, not waived |
| Unconnected items | 205; the board is intentionally unrouted |
| CLI schematic parity | 46 known auto-net/NC-pin fallback findings; complete records retained |

No paired-editor GUI parity review has been performed for this variant.
The baseline's GUI evidence must not be transferred to these changed files.
The independent pin/net/side/DNP checks and the known CLI limitation are not a
claim of fabrication, hardware, cell-safety or full routing approval.

## Reproduce and inspect

From the repository root:

```powershell
python .\tools\draft_wing_placement.py
python .\tools\check_wing_placement.py --run-native
python .\tools\check_wing_placement.py
```

The `--run-native` wrapper creates fresh reports in an isolated temporary
directory and binds their bytes to the exact schematic, board, project and
library tables. Later checks reject changed CAD or stale/modified reports.
Manually running a native command does not create that binding.

The deterministic placement defaults are seed163402 and160000 steps.
Regeneration takes time and refuses to overwrite routed or manually changed
candidate boards, edited schematics, project settings or library tables.
After a manual placement change, preserve the edited board
and update its mechanical/validation handoffs deliberately; do not work around
the overwrite guard. Do not run the original `place_handbell.py` to regenerate
this separate variant.

The next placement freeze depends on the
[integrated-cartridge study](../../../../mechanical/studies/2026-09-09-integrated-cartridge/README.md),
exact cell/contacts, complete speaker/USB envelopes and a priced assembly route.
JLC's published Economic tier is single-sided; Standard supports two-sided
placement, and the selected IMU's current listing is already Standard Only.
See the [dated capability/cost record](../../../../docs/electromechanical-wing-iteration.md#assembly-cost-is-a-decision-gate-not-a-reason-to-stop-drafting)
for the source links and required frame/panel assessment.
No Gerber, drill, order-ready BOM/CPL or fabrication order is issued here.
Inherited supplier-rotation fields are not approval of this variant's assembly
orientation; pin-1/side/rotation must be reconciled with the eventual JLC BOM/CPL.

## Attribution

The circuit and native PCB remain Adafruit 5768/4438/4654 derivatives under the
[parent hardware license](../../LICENSE.txt) and
[project attribution](../../../../ATTRIBUTION.md). The stock KiCad mounting
footprint is covered by the standard library's CC BY-SA 4.0 design exception.
Original generation/checking code is MIT; that does not relicense the adapted
electronics. No manufacturer 3D model, vendor photo or third-party print design
is copied into this draft.

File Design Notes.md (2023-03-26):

2023-03-26 Episode 0

- Microprocessor to play sounds (aka "mp3 player") + IMUwith WiFi and BLE:
    - Seeed Xiao: https://www.seeedstudio.com/Seeed-XIAO-BLE-Sense-nRF52840-p-5253.html
    - ILabs: https://ilabs.se/product/challenger-rp2040-wifi-ble-mkii-with-chip-antenna-and-16bit-accelerometer/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
- Handbell "object" to mechanically hold the parts
    - e.g. https://www.amazon.com/Rhythm-Band-Note-Metal-Bells/dp/B0002E363C
- Speaker to play the sound
    - https://www.adafruit.com/product/3968
- Amplifier to magnify the signal
    - https://www.adafruit.com/product/3006
- Power switch
    - https://www.adafruit.com/product/5498 (?)

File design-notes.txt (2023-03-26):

2023-03-25 Episode 0

- Microprocessor board to "play" wav files
    - Adafruit QT PY
        - board with Raspberry Pi RP2040: https://www.adafruit.com/product/4900
        - AirLift breakout: https://www.adafruit.com/product/4201
    - Challenger MKII with WiFi/BLE and accelerometer: https://ilabs.se/product/challenger-rp2040-wifi-ble-mkii-with-chip-antenna-and-16bit-accelerometer/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
    - Alternative - Pico W (with WiFi): 
        - Adafruit: https://www.adafruit.com/product/5526
        - Newark: https://www.newark.com/raspberry-pi/raspberry-pi-pico-w/raspberry-pi-board-arm-cortex/dp/38AK5986?CMP=AFC-OP
    - Alternative: Feather + Wing
        - Feather: https://www.adafruit.com/product/4884
        - Feather Wing: https://www.adafruit.com/product/4264

- Amplifier board to amplify the audio
    - Adafruit I2S 3W Class D Amplifier Breakout - MAX98357A: https://www.adafruit.com/product/3006

- Speaker to play the audio
    - Speaker - 40mm Diameter - 4 Ohm 3 Watt: https://www.adafruit.com/product/3968

- IMU sensor:
    - Absolute 9-DOF breakout: https://www.adafruit.com/product/4646
    - (or, built-in ala Challenger)
    - (or, something simpler)
    
- Mechanical structure to hold the electronics
    - design a 3D print
    - use "toy" set of handbells off Amazon

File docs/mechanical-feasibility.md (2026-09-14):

# FreeCAD mechanical feasibility

**Current September 13 direction:** use the
[original printed-bell handoff](printed-bell-revision.md#printed-shell-cartridge-and-handle)
and [dedicated native/print package](../mechanical/studies/2026-09-13-printed-bell/README.md)
for new work. It has a D70/H55.8 one-piece shell, flush removable cartridge,
80 mm keyed black handle and the exact D43 all-front electronics interface.
The guide includes original exterior/profile/grille/cutaway views and an
exercised portable FreeCAD view macro. Earlier studies below remain preserved;
their metal-shell profiles, exterior skirt and mixed-face poses are not the
new printed-bell geometry.

**September 11 update:** [new shell stations and owner clarifications](measurements/2026-09-11-shell-speaker-inputs.json)
supersede the old assumed taper for new work. The first concave section ends
at z14.90; the owner requests a uniform 1.15 mm working wall and now measures
the speaker magnet as D21.70. The
[T8 integration plan](t8-integration-plan.md) includes actual battery capture,
USB access and service attachment before routing. Preserve the old artifacts
and their original parameter/manifest bindings.

The [complete T8 cartridge](../mechanical/studies/2026-09-11-t8-cartridge/README.md)
is the current separate review model: open
`mechanical\studies\2026-09-11-t8-cartridge\t8-cartridge.FCStd`.
It contains the exact 83-part placement, full contact primitives, speaker,
provisional T8 cell, four printed structural pieces, M2 hardware and the
working shell. The contact/guard fit requires a proposed 6.25 mm mouthward
stack shift, so the grille front is 10.75 mm outside the mouth.
Use its dedicated reproduction instructions, not the September 7 commands
below. The contact-free PCBA print dummy deliberately omits BT1/BT2 while the
full native/STEP models retain them; it cannot qualify spring or cell fit.

**Historical measurement follow-up, 2026-09-09:** the
[separate measured-speaker study](../mechanical/studies/2026-09-09-measured-speaker/README.md)
uses the owner's arrived-part measurements and captures physical print feedback.
The speaker is 40 mm OD and 19 mm deep, not the earlier 18.5 mm retail maximum.
Its measured basket rear is D32 at z12, followed by a D22 x H7 magnet.
The original artifacts and findings below are preserved as the September 7
snapshot, not silently regenerated. The new outward-facing screen does not yet
establish a complete fit or reinforced carrier.

**2026-09-07: actual editable CAD and fit-print artifacts, not a demonstrated
complete fit.** FreeCAD generated the
[native document](../mechanical/handbell-feasibility.FCStd),
[STEP assembly](../mechanical/handbell-assembly.step),
[carrier](../mechanical/fit-carrier.stl),
[separate interface](../mechanical/bonded-interface.stl) and
[grille](../mechanical/grille.stl). The current 74-component placement is integrated
as explicitly approximate solids, directly from the final supplied manifest
with **no height overrides**. J2 is the selected **SM02B side-entry at 3.1 mm**.
The study retains the required-but-unimplemented USB slot's raw interference
and insufficient clearance around the larger battery dummy. The earlier
height-screen J2/battery overlaps are no longer present. No routed board,
live-cell assembly, acoustic result or child-ready hardware is claimed.

**Print-now addition:** the [inert dummy set](../mechanical/README.md#print-now-inert-dummy-set)
includes standalone populated-PCBA STEP/STL, two full-cylinder speaker gauges,
an explicitly illustrative speaker STEP/STL, two battery blocks and two
clearance gauges. These are delivered files, not just modeling instructions.

Original section and component-proxy plan

## Installed toolchain and reproduction

Installed silently for the current Windows user with the official winget package:

```powershell
winget install --id FreeCAD.FreeCAD --exact --source winget --scope user --silent --accept-package-agreements --accept-source-agreements --disable-interactivity
```

The exercised version is **FreeCAD 1.1.3, revision 20260725 (Git shallow)**,
commit `145529fe741292ff0b3977a01195bf0247425794`, with **OpenCASCADE 7.8.1**
and bundled **Python 3.11.14**. Executable:
`%LOCALAPPDATA%\Programs\FreeCAD 1.1\bin\FreeCADCmd.exe`.
No prior installation was found. Winget verified the installer hash and
successfully installed the user-scoped package; no fallback installer was needed.

Official installer:
<https://github.com/FreeCAD/FreeCAD/releases/download/1.1.3/FreeCAD_1.1.3-Windows-x86_64-py311-installer.exe>

Installer SHA-256:
`3de56676dedb7c68f4da9734c79abeaff9bbbf09f6a2c01df72a82beeee81c11`.

From the repository root:

```powershell
$FreeCAD = "$env:LOCALAPPDATA\Programs\FreeCAD 1.1\bin\FreeCADCmd.exe"
& $FreeCAD --version
python .\tools\build_mechanical.py --freecad-cmd $FreeCAD --placement .\hardware\handbell\placement\placement-manifest.json
```

This is a console build: **no FreeCAD GUI was opened** and no KiCad window,
document or settings were changed. The launcher supplies isolated temporary
`--user-cfg` and `--system-cfg` files and runs synchronously. Exact executable
arguments, console bootstrap and output are written to local
`mechanical\freecad-build.log` on regeneration. This machine-local diagnostic
file is Git-ignored and is not part of the published download.
Actual native export operations are `doc.saveAs(...)`, `Part.export(assembly,
step_path)` and `MeshPart.meshFromShape(...).write(stl_path)` in the
[readable script](../tools/build_mechanical.py).

[`parameters.json`](../mechanical/parameters.json) and the native `Parameters`
spreadsheet expose dimensions. Edit a parameter JSON or saved spreadsheet and
regenerate with `--parameters` or `--parameters-from`; the
[mechanical README](../mechanical/README.md) contains those commands and native
viewing instructions. Spreadsheet edits alone do not recompute the generated
BReps. The FCStd includes source and input snapshots, with separate named solids,
not a mesh-only model or an undisclosed one-off construction.

### Final supplied manifest and connector configuration

The supplied manifest SHA-256 is
`bca8252da704c28e0982eacd353149119c557c5a6a1f0f5452f98bc73d00af41`.
It contains **74 fitted components, 18 copper-only reverse features and C29 DNP**.
J2 is **SM02B-SRSS-TB side-entry**, screened at **3.1 mm** from the reviewed JST
2.95 mm reference mated-height reading. Its local manifest envelope is
**4.8 x 6.25 x 3.1 mm**. The placement generator includes a 0.7 mm front mating planning
allowance; the model consumes the supplied final width/depth and center verbatim,
without adding another 0.7 mm to that proxy. No separate mating-allowance field
or qualified cable/plug/underside-anchor model is present in the manifest.

**D3 is 1.1 mm high and D4 is 1.0 mm high.** The final supplied footprint
identifiers, XY centers, dimensions and mathematical rotations are retained;
reverse-face copper and the DNP reservation do not create physical component
boxes. Native PCB net-associated copper and back-face semantics remain the
electrical handoff's scope, not an inference from these bounding-box solids.

The temporary J2 height override is removed. The earlier top-entry screen and
its battery-clearance overlaps are superseded; do not apply an override when
reproducing this final manifest. No placement input or electrical
file was modified. The hash above identifies the exact bytes consumed, including
embedded native-PCB hash metadata; later metadata-only updates can change the
manifest hash even when component geometry remains identical.
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

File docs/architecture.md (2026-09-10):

# Proposed architecture

Status: schematic integration draft, not frozen. The
[handbell derivative](../hardware/handbell/README.md) adapts Adafruit 5768 and
now has LSM6DSOX, TPS61023 boost, independent mute and reduced peripheral
wiring. Cell/speaker qualification and routing remain open; the
[0.2 handoff](electrical-reduction-and-placement.md) covers the 43 mm placement.
All upstream implementation claims refer to the
[pinned source catalog](reference-designs.md), particularly the
[5768 schematic](https://github.com/adafruit/Adafruit-RP2040-Prop-Maker-Feather-PCB/blob/408fa9a40c0a01a3a65497ef42a29e0b08fe711e/Adafruit%20Feather%20RP2040%20Prop-Maker.sch).

The diagram below describes the current **0.2 boosted** circuit.

```mermaid
flowchart LR
    USB[USB-C: 5 V and USB data] --> SEL[USB / battery source selection]
    USB --> CHG[1S charger: cell-specific limits]
    CHG --> BAT[Protected 1S LiPo]
    BAT --> SEL
    SEL --> LDO[3.3 V regulator]
    LDO --> MCU[RP2040 + QSPI flash]
    LDO --> ACC[LSM6DSOX + INT1]
    ACC <-->|I2C| MCU
    USB <-->|USB D+ / D-| MCU
    SEL --> SW[Switched amplifier rail]
    MCU -->|Power enable| SW
    MCU -->|I2S: data / BCLK / LRCLK| AMP[MAX98357A DAC + class-D amp]
    SW --> BOOST[TPS61023: VAMP about 5 V]
    MCU -->|POWER / EN| BOOST
    MCU -->|AMP_MUTE via Q4| AMP
    BOOST --> AMP
    AMP -->|BTL pair: neither lead is ground| SPK[Speaker]
```

This is a logical diagram, not wiring instructions. Protection, decoupling,
clocking, reset, USB CC terminations, test access, and control/status circuits
must be explicit in the schematic.
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

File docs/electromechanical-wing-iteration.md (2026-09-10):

# Wing placement and integrated cartridge iteration

**2026-09-09: draft iteration, not an electrical/structural manufacturing release.**
The owner requested selective rear-face components in the battery-free wings,
ground-assigned mounting holes for sturdier supports, and fewer separate
printed parts. The original print kit and electrical baseline are preserved.
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

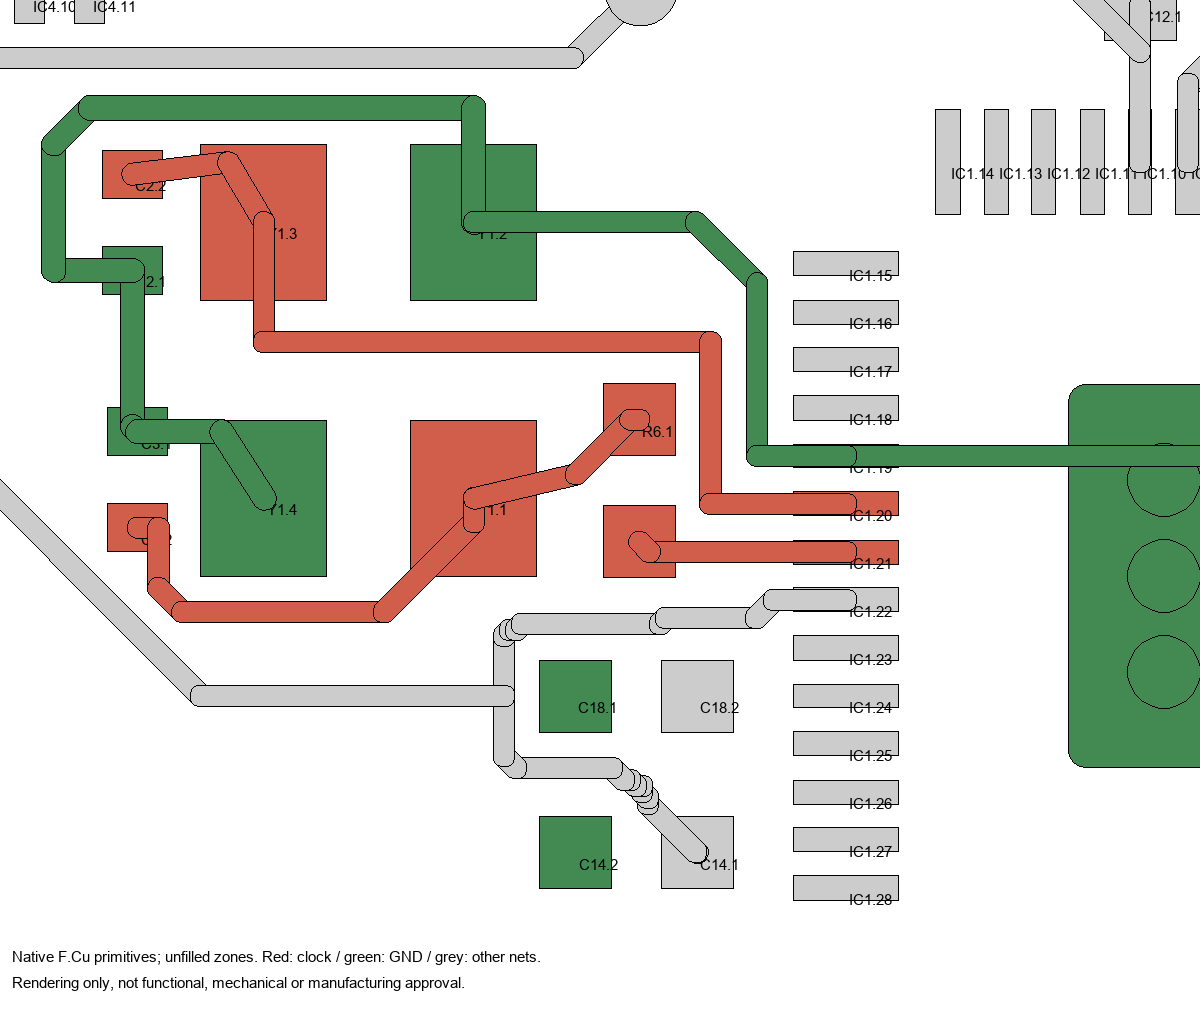
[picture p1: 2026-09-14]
hardware/handbell/iterations/printed-bell-clock-draft/reports/clock-approaches-front.png

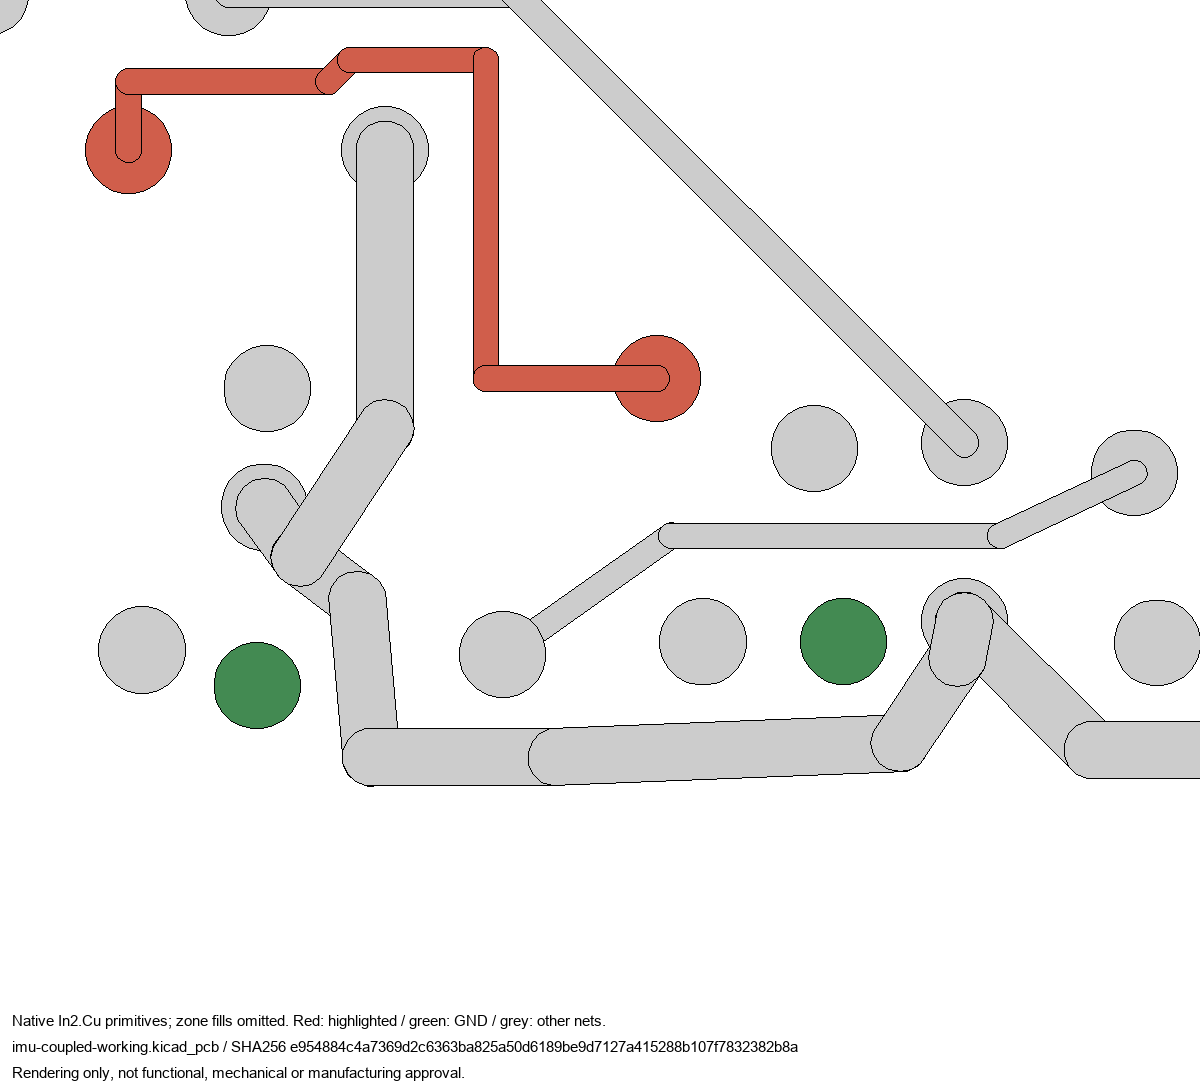
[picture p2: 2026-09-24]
hardware/handbell/iterations/printed-bell-four-layer/reports/imu-working-inner.png

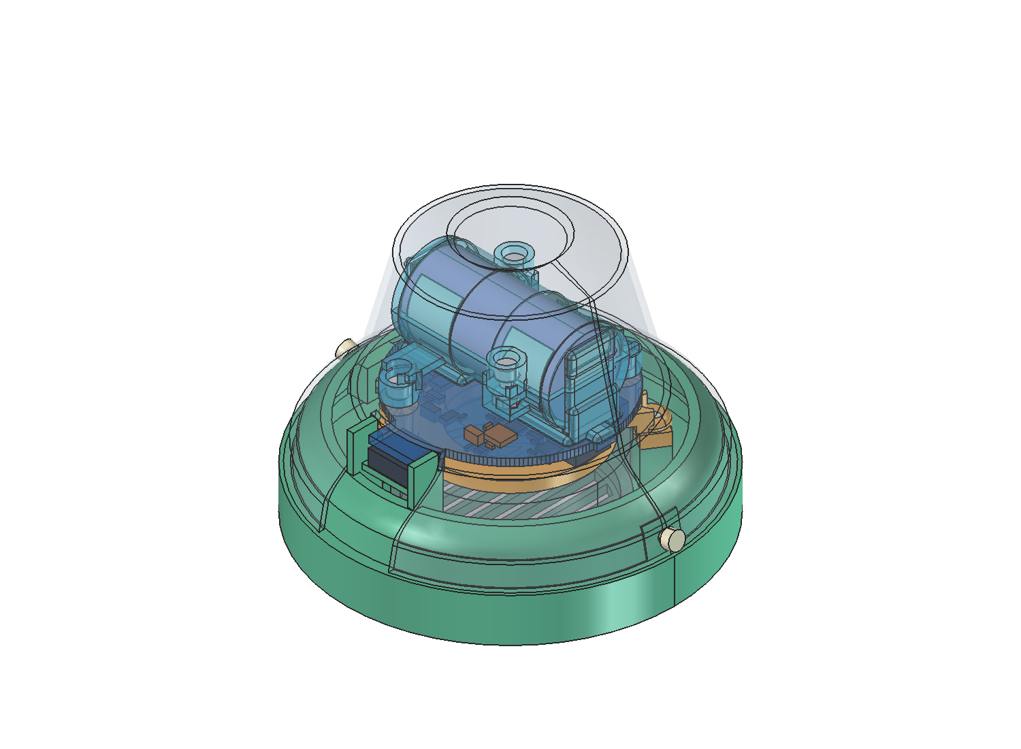
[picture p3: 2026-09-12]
mechanical/views/t8-cartridge-review.png

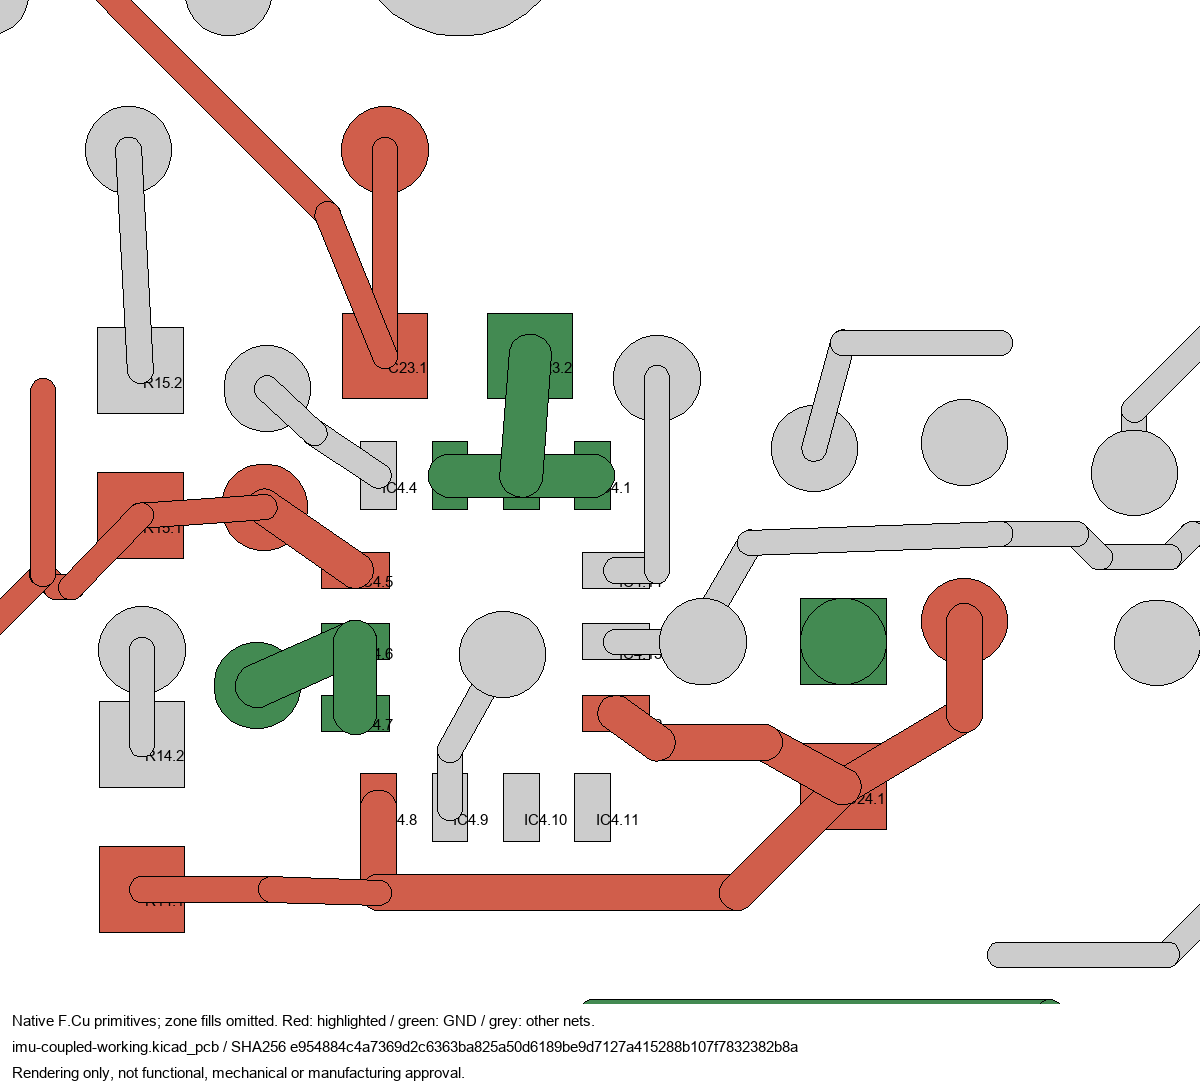
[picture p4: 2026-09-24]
hardware/handbell/iterations/printed-bell-four-layer/reports/imu-working-front.png

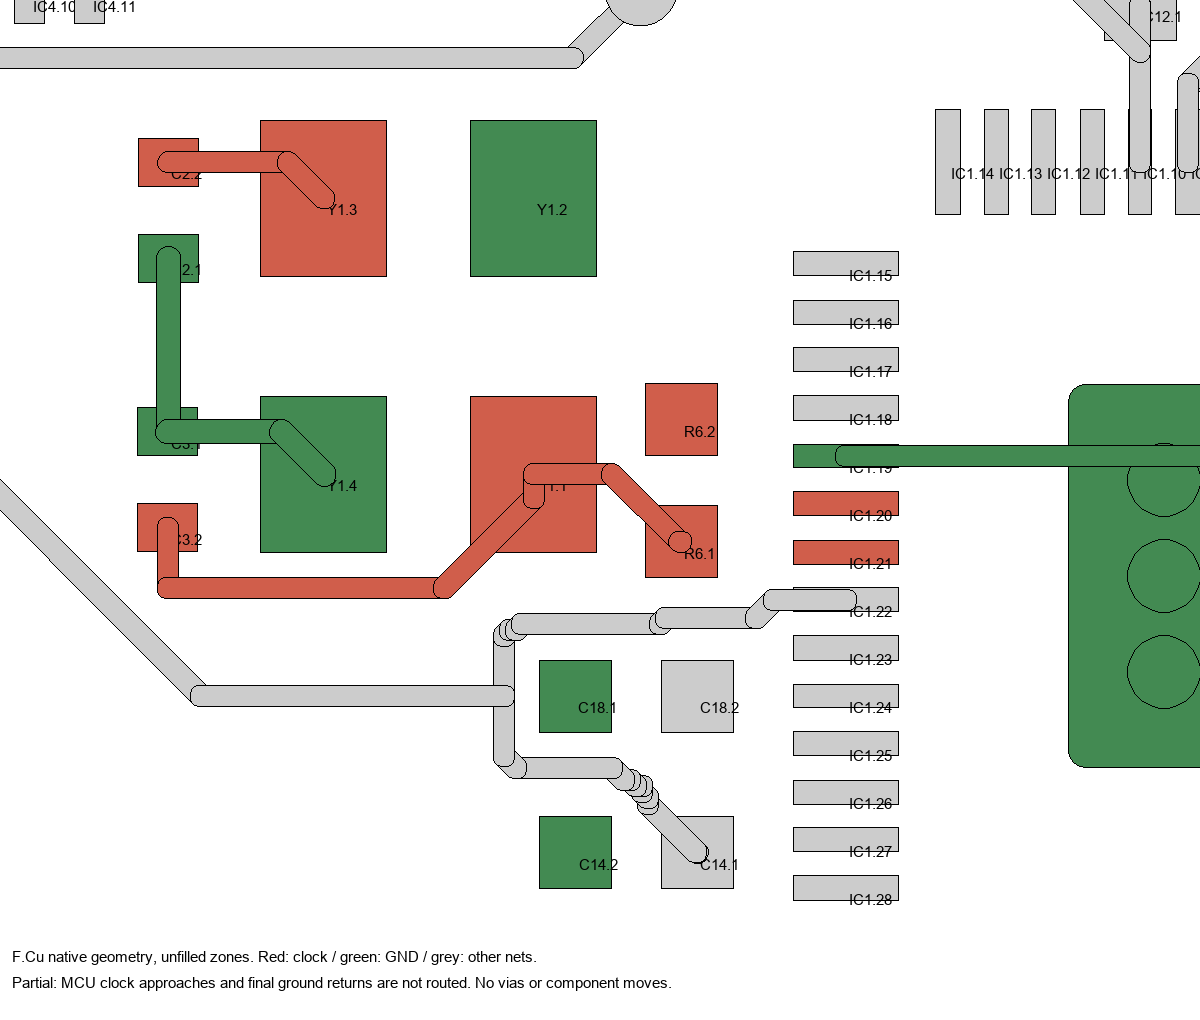
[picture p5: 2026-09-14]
hardware/handbell/iterations/printed-bell-clock-draft/reports/clock-local-front.png

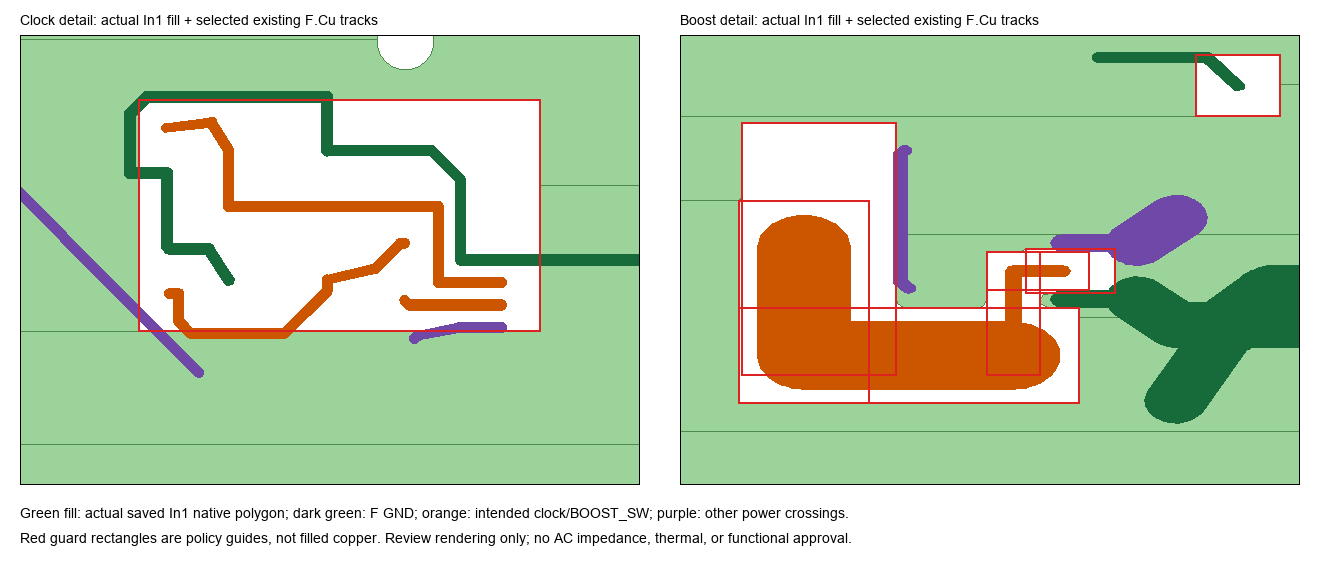
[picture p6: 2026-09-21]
hardware/handbell/iterations/printed-bell-four-layer/reports/in1-plane-review-details.png

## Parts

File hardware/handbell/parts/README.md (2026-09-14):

# Sourced part candidates

This separate register supplies **manufacturer-verified prototype candidates**,
not a complete supplier upload or authority to purchase. It leaves the frozen
schematics, BOMs, footprints and placement packages unchanged.

`standard-passive-candidates.json` covers **53 fitted references**: 26
non-boost capacitors and 27 ordinary resistors. It provides identities for
48 previously blank MPN rows and confirms five already specified rows.
C26-C28, the power inductor/beads, shunt and remaining device/connector
selections are outside this register.

The choices preserve existing nominal values and specified minimum voltage
except the explicit **C2/C3 22-to-15 pF clock-reference revision** below.
They prefer consistent Murata/Yageo families, including the
already recorded C30/R25/R26/R28/R29 identities. Application/land/paste/
supplier review remains explicit; importing this list must not be mistaken
for closing the whole [quotation handoff](../../../docs/pcba-quotation-plan.md).

**Scoped native application:** the continuing
[clock/integration draft](../iterations/printed-bell-clock-draft/README.md) now
implements the Y1/C2/C3 clock revision, selected Q3 identity, all 27 ordinary
0402 resistor identities and all 26 non-boost capacitor identities. The resistor
step filled 23 blank MPNs and confirmed four; the capacitor step filled 23 and
confirmed three. Nominal values and geometry were preserved by those identity
steps; R27 and C26-C28 were excluded from those ordinary-passive batches.
The subsequent USB correction and final 17-reference device/power batch now
complete **83/83 fitted MPNs**, matching across PCB, schematic and manifest.
This is not a count of supplier-qualified or geometry-approved parts.
The [current schematic PDF](../iterations/printed-bell-clock-draft/reports/identified-schematic.pdf)
and `reports/remaining-identities.json` bind that milestone. The frozen source
packages remain unchanged; part-specific land/envelope/assembly gates remain.

`hro-usb-candidate.json` separately identifies **HRO TYPE-C-31-M-12 / C165948**
for X6. It records the visually read 2020-12-08 drawing, derived datums and
explicit project DFM deviations for the new quote candidate. Its current
1.4 mm front-slot recommendation differs from the old source; true plated
slots, larger annular rings, four shifted power/ground lands and matching
paste are required. It also adds the previously absent mouth-position
component tolerance to the mechanical handoff. This is not an exact
manufacturer footprint or supplier approval. Its native implementation is now
applied in the continuing draft, with local CC/VBUS repairs and no X6 move;
see [the USB qualification record](../../../docs/usb-connector-qualification.md).

`power-component-candidates.json` selects the six L1/C26-C28/FB1-FB2 prototype
candidates and records their current/bias data and required native land/paste
changes. It also covers the closely coupled land treatment for the five
already selected 10 uF capacitors sharing the oversized source pattern.
No larger body envelope is required for these six parts; keep the conservative
heights. The eleven selected land patterns are now applied in the continuing
draft, with no part moves and preserved quiet pickoffs. This is not supplier or
current-capacity qualification. See
[power-component selection](../../../docs/power-component-selection.md).

`device-component-candidates.json` selects thirteen formerly blank device
identities and confirms Q4, including **DMP2045UFY4-7** for Q3 and the
tested **ABM8-272-T3** clock reference. It records diode-height and permitted-flash
screening corrections, correct package/pin variants, and remaining land/
paste/thermal-via gates. See
[device-component selection](../../../docs/device-component-selection.md).

Y1 requires a deliberately larger 3225 footprint and four-terminal schematic,
with a 3.60 x 2.80 x 1.00 mm screening envelope, within the unchanged D43 board.
Its exact electrical sheet and matching family geometry have different source
roles; generic crystal electrical defaults must not replace the exact part.
C2/C3 now select **GRM1555C1H150JA01D, 15 pF**, with dedicated
manufacturer-range 0.40 x 0.50 mm lands. Their retained `source_values`
still describe the immutable 22 pF base; `selected_value` explicitly records
the new value. No other passive group changes, and R6 remains 1 kohm.
The continuing draft now has local all-front clock routing. The complete
mechanical bind, supplier process and powered/low-cell oscillator behavior
remain open.

## Direct source evidence

`existing-part-review.json` preserves the **stopped final audit of nine
already-identified references** against the frozen power-rework package.
It records connector suffix/pickup evidence, U5/R27 land and envelope
dispositions, contact packing/height and fine-package assembly gates.
No changes were applied by that audit; it did not inspect the active routing
candidate. It is not a second selected BOM or authority to rewrite native
geometry. See [the wrap-up findings](../../../docs/pcba-bom-readiness.md#stopped-final-audit-remaining-assembly-inputs).

On September 14, 2026, the actual manufacturer product pages, their public
catalog responses and linked specifications were read. The JSON records
response/document SHA-256 values. Raw responses and manufacturer PDFs were
kept as local research evidence, not redistributed as project-owned material.

For Murata, open
`https://pim.murata.com/en-global/pim/details/?partNum=<MPN>`.
Its browser uses the public read-only search endpoint
`https://pimapi.murata.com/public/api/pim/v1/products/search`, with this
observed POST query:

```json
{
  "searchCondClass": 3,
  "partNum": "<MPN>",
  "page": 1,
  "pageSize": 20,
  "productCategoryId": "ceramicCapacitorSMD",
  "languageRegion": "en-global",
  "series": "",
  "sortKey": "",
  "valSearchCondList": [],
  "rangeValSearchCondList": [],
  "dateRangeSearchCondList": []
}
```

Require a unique result whose `partNumWithPackageCode` contains the exact
orderable, not merely a similarly named family. Specifications and versioned
PDF links are in `productSearchResult[0].itemInfoList`. Use the full dimensional
display including tolerance: some API numeric `thicknessMax.value` fields
still contain the nominal number despite a larger displayed maximum.
Some `capacitanceTolerance.value` fields likewise contain nominal capacitance,
not tolerance; use the explicit tolerance display and the linked specification.

For Yageo, open `https://yageogroup.com/products/Resistors/part/<MPN>`.
The observed public GET
`https://yageogroup.com/search/unique-parts/<MPN>?displayArea=COMPONENT_EDGE_PART_DETAIL`
provides exact identity, resistance, tolerance, power and package. The linked
RC_L specification is **V.14, November 14, 2025**; pages 4, 5 and 7 define
dimensions, ratings/TCR and derating.

## Important distinctions

| Quantity | Verified manufacturer basis |
|---|---|
| Murata 0805 maximum body | 2.1 x 1.35 x 1.35 mm, not the 2.0 x 1.25 x 1.25 mm nominal size |
| Murata 0402 maximum body | 1.05 x 0.55 x 0.55 mm, not 1.0 x 0.5 x 0.5 mm |
| Yageo 0402 maximum body | 1.05 x 0.55 x 0.40 mm |
| R23 orderable | RC0402FR-07732KL is **732 kohm**, not 73.2 kohm |
| Selected Yageo TCR | V.14 specifies +/-100 ppm/C for the selected 1/16 W values above 10 ohm through 10 Mohm, including 5.1 Mohm |
| Resistor voltage | Limited by both 50 V maximum working voltage and the derated power/resistance relationship |

Search summaries had incorrectly reported some nominal dimensions as maxima,
misread 732 kohm and assigned a different high-resistance TCR range. Those
claims were discarded in favor of direct manufacturer records.

These passive body limits are manufacturer data, not project measurements or
a qualified mounted-assembly envelope. Their existing conservative proxies
are retained; the separate USB register explicitly requires a larger front bound.
Part-specific DC-bias and circuit behavior, final supplier codes, placement/
paste and assembly processes remain to be resolved in the complete handoff.
The manufacturer catalog's production indication is not a stock promise.

Original register and explanations: MIT. Adapted electronics and their
exports retain the hardware attribution/license scope in `ATTRIBUTION.md`.

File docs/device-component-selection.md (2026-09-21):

# Device identities and package corrections

September 14, 2026. The
[device register](../hardware/handbell/parts/device-component-candidates.json)
selects **thirteen formerly blank prototype device identities** and confirms
Q4. It records manufacturer sources, pin/polarity details, local-axis maximum
dimensions and unresolved manufacturing gates. These identities are not a
released supplier BOM, approval to purchase, or proof that every inherited
land/paste pattern is suitable.

All selected device identities are now applied in the continuing
[clock/integration draft](../hardware/handbell/iterations/printed-bell-clock-draft/README.md#all-fitted-part-identities-applied).
Its final identity batch preserves geometry. The separately completed clock/Q3
work and September 15 six-device envelope revision are applied. Remaining
copper-retention decisions are recorded below; supplier paste/process acceptance
and full mechanical qualification stay open.

| Reference | Selected identity | Principal distinction |
|---|---|---|
| CHG0 | Kingbright APT1608LSECK/J4-PRV | Low-current orange; J4, not J3 |
| L0 | Kingbright APT1608LSECK/J3-PRV | Low-current hyper red |
| D3 | Diodes 1N4148WS-7-F | Actual SOD323, not axial 1N4148 or a similarly named SOD123 part |
| D4 | Nexperia PMEG2020AEA,115 | Manufacturer package is SOD323, despite the imported SOD323F alias |
| IC1 | Raspberry Pi RP2040 | Official reel codes SC0914(7)/(13) are recorded separately |
| IC4 | ST LSM6DSOXTR | Correct LGA14, Mode 1 and existing firmware initialization gate retained |
| Q1 | AOS AO3401 | Manufacturer says Full Production; no AO3401A substitution is needed |
| Q2, Q4 | AOS AO3400A | C20917 resolves Q2; Q4 has a differently oriented native footprint |
| Q3 | Diodes DMP2045UFY4-7 | Explicit replacement for NRND DMG3415UFY4-7; corrected DFN drain retained |
| U2 | Richtek RT9080-33GJ5 | Fixed 3.3 V, non-N variant: pin 4 NC, not SNS |
| U3 | Microchip MCP73831T-2ACI/OT | Exact existing charger options retained |
| U4 | MAX98357AETE+T | T1633+4 16-TQFN, not the WLP option |
| Y1 | Abracon ABM8-272-T3 | RP2040 reference; deliberate 3225 footprint and 15 pF load-capacitor revision |

The researcher preserved original manufacturer documents and actual catalog
records locally; the parent confirmed all 24 named source hashes and
inspected the height/flash drawings. Twenty of those source records support
the first eleven selected groups. The subsequent Q3 selection adds four
manufacturer records from a separately hash-bound follow-up; all sixteen
follow-up source hashes were confirmed before adoption. Public records omit personal evidence paths
and do not redistribute manufacturer PDFs or images.

## Conservative package-envelope corrections

These changes belong only in the new quote candidate and its next complete
CAD bind. No archived board, placement or print is overwritten.

**Applied September 15** to the continuing manifest, retaining actual current
poses and offsets. The source-bound `reports/device-envelopes.json` records
no new overlap/outline/speaker screen conflicts. Native PCB/schematic files
are unchanged; this is not a fresh full-CAD or physical-fit approval.

| Reference | New local X x Y x Z screening envelope, mm | Reason |
|---|---|---|
| D3 | 3.04 x 1.40 x 1.20 | The drawing separates body thickness A2 from standoff A1; their conservative maximum sum is 1.20, not the old 1.10 |
| D4 | 3.00 x 1.35 x 1.10 | Actual SOD323 maximum width and height exceed the old 1.30/1.00 values |
| Q1/Q2 | 3.354 x 3.20 x 1.50 | Add the manufacturer-permitted mold-flash screen to the body's long axis |
| Q4 | 3.35 x 3.354 x 1.50 | The same package's long axis is local Y in this footprint |
| U3 | 3.60 x 3.8002 x 1.50 | Conservative BSC/profile and permitted-flash derivation, not an ordinary-body size claim |

Mold flash is a small plastic protrusion left by package molding. AOS permits
less than 0.127 mm per non-lead side beyond its 3.10 mm body length, giving
a conservative 3.354 mm screening bound. Microchip separately excludes up
to 0.25 mm per side; the recorded profile-based bare-length derivation gives
3.10 mm and hence a 3.60 mm flash-inclusive screen.

These are conservative component screens, **not measured mounted dimensions**
or a complete combination of solder lift, placement accuracy, PCB distortion
and printed-part tolerances. Manufacturing should review the interpretations
before the final envelope is frozen. Do not shrink other existing proxies or
discard native-to-proxy center offsets.

## Electrical identity does not approve the old footprint

The new candidate must address the part-specific land/paste/polarity findings
in the register. Examples include the LEDs' recommended 0.85 mm land gap
versus the old 0.70 mm, D3/D4's actual SOD323 recommendations, and U2's
recommended 0.7 x 1.0 mm pads versus the old 0.55 x 1.2 mm pads.
These differences are not themselves evidence that previous hardware failed,
but they cannot be hidden behind a generic package label.

U4's selected exposed pad is nominally 1.10 mm square, maximum 1.25 mm;
the native thermal copper is 1.50 mm square. Its actual paste, thermal vias,
mask and supplier soldering process need an explicit disposition. Neither
full-pad paste nor filled/capped vias are automatically approved by this
identity selection. Preserve the intended GND return and remeasure altered
current-carrying geometry where applicable.

Keep actual pin/net mappings, including diode/LED `C`/`A` identities and
manufacturer pin-1 cathode conventions. Do not widen all similarly named
footprints globally or silently replace RT9080 with its SNS variant.

The two LED candidates are specified optically at 2 mA, but the actual board
uses **10 kohm R2/R7**. Illustrative currents are about 0.28-0.32 mA for
the charging LED and 0.15 mA for the GPIO LED. These are operating-point
examples, not guaranteed bounds or guaranteed visible brightness. The
resistors are not changed to force the datasheet's optical test current.

## September 15 remaining land and assembly dispositions

The current native land choices are retained for continued routing unless
listed as changed below. This closes a copper-design decision, **not** supplier
process acceptance. Example-pattern differences alone are not evidence that
the adopted Adafruit design failed.

| References | Routing disposition | Explicit quotation/assembly condition |
|---|---|---|
| CHG0/L0 | Retain 0.8 x 0.8 mm lands at 1.50 mm pitch. The manufacturer example uses the same land size at 1.65 mm pitch; retain the mapped C/A polarity and source layout rather than moving parts solely to copy the example. | Confirm paste, placement and joints for the exact selected LEDs. Do not change the 10 kohm resistors to match an optical-test current. |
| D3 | Retain 0.9 x 0.8 mm lands at 2.14 mm pitch. The selected SOD323 lead-span/terminal bounds fit the centered land region; C remains USBBOOT. | Full-pad paste is larger than the manufacturer's 0.59 x 0.45 mm land example. Assembler must review solder volume; this is not a manufacturer-prescribed stencil or a demonstrated solder failure. |
| D4 | Retain 1.0 x 0.8 mm lands at 2.00 mm pitch for the selected actual SOD323 package, not the stale SOD323F alias. A remains VBUS, C remains VHI. | Confirm exact suffix/packing and stencil volume. The corrected maximum envelope is already applied. |
| U2 | Retain 0.55 x 1.20 mm lands, 0.95 mm pitch and 2.6002 mm row spacing. Nominal pin layout agrees; the 0.559 mm maximum lead width exceeds the land by 0.009 mm overall. This small width difference alone does not establish a failed joint. Pin 4 stays NC. | Obtain placement/joint acceptance rather than silently claiming the Richtek 0.7 x 1.0 mm example was applied. |
| U4 | Retain the imported copper, peripheral openings and four thermal vias. The actual center paste is one **1.143 x 1.143 mm square**, not full 1.5 x 1.5 mm pad paste. Retain it as the quotation stencil baseline. | Specify filled-and-copper-capped treatment for those four vias in the quote-only process notes below. Stencil volume/voiding and the 16 explicit peripheral mask openings require assembler review; do not add duplicate automatic mask openings. |

For U4, the center paste area is 1.306449 mm2, about 58.1% of the 2.25 mm2
copper land. Comparing only that percentage is not a solder-process approval:
the selected package's exposed pad is nominally 1.10 mm square and its
placement, paste release and finished voiding still matter.

The retained-part audit is likewise split into copper and process decisions:
J1/J2 keep their agreeing nominal connector patterns and all reinforcement
joints; BT1/BT2 keep their split lands and fixed datums; U1 keeps the previously
corrected terminal/center-strip geometry; U6 keeps the documented all-NSMD
adaptation; Q5 keeps its manufacturer-matching circular copper lands and
current circular paste. U5/R27's selected corrections are now applied in
`reports/power-device-lands.json`. No further native land change is selected
by this pass.

J2's toleranced maximum, connector pickup mapping, U1's 0.15 x 1.20 mm
center-strip aperture, U6's all-NSMD assembly and Q5's paste-area difference
remain explicit supplier questions, not hidden waivers. BT1/BT2's 16.97 mm
upper drawing height must be screened in the coordinated mechanical model;
do not stretch the nominal contact primitives or invent loaded geometry.

### U4 quote-only via treatment

September 21 update: the owner approved a separate four-layer migration.
The treatment below remains required for the retained U4 geometry until a
specific simpler alternative passes thermal, electrical and stencil review.
Extra ground-plane access alone does not qualify an off-pad substitute.

For the matched quotation assets, specify **nonconductive resin fill,
planarization and copper capping** on U4's four existing 0.35 mm nominal-drill
thermal vias. Keep the two-layer board and current copper as the baseline.
Their native PCB centers in mm are:

| X | Y | Via UUID |
|---|---|---|
| 110.400323 | 89.587211 | `eb628663-2af6-5175-bd63-91e9eecb0258` |
| 110.400323 | 90.237211 | `d9dcd570-3f7d-5000-b8d1-12b9b39f93b5` |
| 111.050323 | 89.587211 | `545fee40-3fbd-59ae-bd8d-30ffe16436ec` |
| 111.050323 | 90.237211 | `c63c289d-af32-592b-9732-d17507fbf476` |

Transform these coordinates with the final fabrication datum; do not mistake
this native-coordinate table for a finished vendor drawing. Ordinary tenting
is not an equivalent process: the vias sit inside the thermal land's mask
opening and can draw solder away without controlled treatment.

This is a **quotation requirement, not a verified service or cost** at either
vendor. Supplier confirmation of two-layer availability, cap finish/flatness
and stencil is required before manufacture. If unavailable, report the
constraint or separately priced alternative; do not silently change the
stackup, relocate vias or replace capping with ordinary tenting.

The [official JLCPCB via-treatment guide](https://jlcpcb.com/help/article/pcb-via-covering),
read September 15, distinguishes resin-filled/capped vias from ink plugging
and tenting, and specifically excludes via-in-pad from ordinary ink plugging.
Its statement that resin filling is free at six layers and above does **not**
establish a two-layer prohibition. Neither vendor's two-layer availability or
price was established here, and no quote was requested.

## Q3 replacement decision

Select **DMP2045UFY4-7** instead of the manufacturer-NRND DMG3415UFY4-7.
The old/new package drawings agree, so keep the corrected DFN lands, explicit
paste/mask, 2.855 x 1.575 x 1.0 mm proxy and 0.2725 mm centre displacement.
Pin 1 is gate/VBUS, pin 2 source/VHI and pin 3 the large drain/VBAT.
The intrinsic diode conducts from VBAT toward VHI during battery startup.

This is package-compatible, **not electrically identical**. At 25 C the
maximum resistance increases 39 to 45 milliohm at -4.5 V gate drive and
52 to 58 milliohm at -2.5 V, under their matching specified currents.
An illustrative 2 A comparison at the latter limits adds 12 mV/24 mW;
it does not rate the board. The new 1.8 V resistance test is at only 0.1 A,
not the old 2 A condition. Drain voltage increases to 20 V; gate maximum
remains +/-8 V.

Do not retain the old 500 nA gate-leakage guarantee at 5 V: the new datasheet
only specifies 10 microamp at 8 V. Gate charge, capacitance and internal gate
resistance also differ; the real VBUS/10 kohm gate network needs startup and
USB-transition measurements, not an assumed identical switching waveform.
Neither the body-diode current figure nor the thermal ratings are independent
of the manufacturer's specified test-board copper.

[PCN-2792-REV1](https://www.diodes.com/assets/PCN-Files/Diodes_PCN_2792_and_Qual_Rpt.pdf),
dated January 27, 2026 with April 27 implementation, names exact
DMP2045UFY4-7 in table 4. Its change is Cu-to-PdCu bond wire, not the
mold-compound changes in other tables. This supports current manufacturing
continuity, not a stock/lifetime guarantee or an observed Active field.
No reverse-cell or ideal-diode protection is added.

**Native application:** the continuing
[clock/integration draft](../hardware/handbell/iterations/printed-bell-clock-draft/README.md)
now identifies Q3 as DMP2045UFY4 with exact MPN **DMP2045UFY4-7**, manufacturer
and datasheet fields in its schematic and PCB, plus the placement manifest.
It retains the generic P-channel symbol and corrected DFN footprint rather
than inventing a different circuit symbol or changing copper. All three nets,
pad primitives, placement and the actual pose-dependent proxy offset are
unchanged. The scoped report is `reports/q3-native-identity.json`; the updated
schematic is `reports/q3-schematic.pdf`. Earlier native variants remain intact.
This implements the identity choice, not its remaining powered or supplier gates.

## Selected clock-reference revision

The bounded 2520 search did not establish a lower-ESR exact orderable.
ECS-120-12-36-AGN-TR remains a conditional 12 MHz/12 pF/150 ohm option,
not the preferred reference. A seemingly lower-ESR Multicomp ordering string
had contradictory primary tables; its suffix was not accepted as a rating.

Select **Abracon ABM8-272-T3**, explicitly recommended
in Raspberry Pi's RP2040 hardware guide: 12 MHz, 10 pF load, 50 ohm maximum
ESR and 200 microwatt maximum drive. Its 3.2 x 2.5 mm package is larger than
the old crystal, but the board must remain D43. This is authorization to
implement the local revision, not a claim that the finished routing fits.

The exact 2024 manufacturer PDF still contains only three sheets and
references an absent height table. The matching manufacturer-hosted
[ABM8 family drawing](https://abracon.com/Resonators/abm8.pdf), revised
July 29, 2020, supplies the actual **0.80 mm maximum** height table and
recommended lands. Its body/terminal dimensions, pin arrangement and
variable-chamfer note match the exact part. Use it for geometry only;
its generic electrical/MSL defaults do not override the exact part.

Use four **1.30 x 1.05 mm rectangular lands at 2.30 x 1.75 mm centre pitch**,
with 1.00/0.70 mm X/Y gaps. The new **3.60 x 2.80 x 1.00 mm screening
envelope** contains both maximum bare body and recommended copper while
retaining the existing height allowance. It is not a qualified placement
courtyard. The register specifies body-centred pin coordinates; chamfer
location alone does not identify pin 1 or the assembly rotation.

This reference uses 15 pF load capacitors and 1 kohm series resistance for
3.3 V IOVDD. C2/C3 now explicitly select **Murata GRM1555C1H150JA01D**,
15 pF/C0G/50 V/+/-5%, replacing only the earlier 22 pF group. The original
catalog response and part-specific PDF agree on the complete orderable,
maximum 1.05 x 0.55 x 0.55 mm body and D packing.

While rerouting this clock cluster, select dedicated **0.40 x 0.50 mm
capacitor lands at X +/-0.40 mm**. These follow the manufacturer's reflow
range, unlike the old 0.60 mm pad length. Update corresponding paste/mask;
do not alter all 0402 footprints or shrink the existing capacitor proxies.
Keep C3 on the crystal side of R6, and keep R6 at 1 kohm.

Even the tested reference needs
startup/drive/load evaluation on this layout, particularly when the battery
and LDO approach dropout rather than maintaining 3.3 V.
The Pi guide explicitly warns that reduced IOVDD can stop oscillation with
1 kohm; any later damping change must also recheck drive at maximum IOVDD.

The preserved Y1 symbol has only pins 1/3, while physical pads 2/4 have no net.
The selected crystal's grounded metal-case pads require a corresponding
four-terminal symbol, schematic/netlist and PCB grounding change. A PCB-only
ground assignment would not close source equivalence.

The routing candidate owns native implementation and its evidence; the
parent then rebinds the complete assembly and prepares the
[matched quotation handoff](pcba-quotation-plan.md). Prototype electrical,
thermal, fault, acoustic and child-use qualification remain separate gates.
Tracking: E04/#4, E05/#5, E07/#7 and E08/#8.

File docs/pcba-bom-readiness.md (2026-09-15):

# Parts readiness for the full PCBA quotation

This independent audit covers the preserved initial routing candidate at
`b63a121b1ca990a64b00f231a85dd715126319af`, not the active power rework.
Its source [BOM](../hardware/handbell/iterations/printed-bell-routing/reports/bom-draft.csv)
has SHA-256 `b760b993757a85d4b0bb9b32155a34244e6282fbc9127692afbd5df36a8bd0e0`.
PCB and manifest hashes begin `075c7b7c` and `cc935ef4`.

**83 parts are fitted: 81 F and 2 B. Fifteen fitted rows have an MPN field;
68 do not, and there is no manufacturer column.** Some exact identities are
recoverable from values/source metadata, so this is not a claim that all
68 devices are unknown. It is nevertheless not a complete turnkey BOM.

The [quotation plan](pcba-quotation-plan.md) requires a sourced, matched final
package. Do not overwrite this immutable draft CSV to suggest its original
metadata was already procurement-ready.

## First sourcing increment

The separate [standard-passive register](../hardware/handbell/parts/README.md)
now provides manufacturer-verified candidates for 53 fitted references.
It identifies candidates for 48 formerly blank rows and confirms five already
specified identities without editing the preserved BOM. Full nominal/tolerance
dimensions and the actual Yageo TCR range are recorded from direct sources.
Application, final land/paste/placement and supplier review remain open;
this is progress toward the complete BOM, not a completed quotation package.

## Subsequent source decisions

The [USB register](../hardware/handbell/parts/hro-usb-candidate.json) identifies
X6 and its required engineering footprint/mechanical correction. The
[power-component register](../hardware/handbell/parts/power-component-candidates.json)
now selects L1, C26-C28 and FB1/FB2 prototype candidates, with actual biased
capacitance/current evidence and source-backed land/paste changes. The five
already selected 10 uF capacitors receive the corresponding part-specific
land treatment because they share the oversized source pattern.

These provide candidate identities for seven more formerly blank references.
The [device register](../hardware/handbell/parts/device-component-candidates.json)
then selects all thirteen remaining formerly blank identities and confirms
Q4, including the explicit DMP2045UFY4-7 replacement for NRND Q3 and the
tested ABM8-272-T3 crystal reference. C2/C3 explicitly change to sourced
15 pF parts with dedicated reflow lands. Implement the larger crystal
within the unchanged D43 board; actual fit is not yet established.
Circuit/package gates are in
[the device handoff](device-component-selection.md).
The selected parts still need to be applied to the new native candidate and
matched final supplier BOM; neither this progress nor the existing MPN fields
establishes complete package/process qualification. The audit tables below
retain the original draft's definitions rather than rewriting its history.

## Stopped final audit: remaining assembly inputs

At the owner's request to wrap up the long-running work, the final
nine-reference audit has stopped and handed back its findings. The
[structured audit](../hardware/handbell/parts/existing-part-review.json)
preserves eight identity groups, source URLs/hashes and unresolved operations.
It inspected the frozen power-rework package, **not the active quote
candidate**, and applied no native changes.

| References | Finding requiring disposition before freezing |
|---|---|
| J1 | Retain Molex 5040500291, alias 504050-0291. Manufacturer nominal lands agree; body height is 2.00 +/-0.15 mm. Preserve the larger proxy and map the specified pickup region rather than using its proxy centre. |
| J2 | Complete identity is SM02B-SRSS-TB(LF)(SN). Nominal side-entry lands agree; toleranced maximum geometry and actual pickup datum remain unresolved. |
| U5 | TI's example uses 0.67 x 0.30 mm pads at X +/-0.74, versus frozen 0.65 x 0.275 at +/-0.635. Local depth needs 1.70 mm for the body, or 2.00 including the documented protrusion allowance. |
| R27 | Panasonic's part-specific example permits 1.15 x 1.40 mm pads at X +/-1.025. Maximum package is 2.20 x 1.45 x 0.75 mm; frozen depth and height each underbound it by 0.05 mm. Preserve the independent sense connections when reconciling lands. |
| BT1/BT2 | Keystone 254 is bulk; 254TR is the reel option, not an automatic substitution. Confirm Rev C and account for its 16.97 mm upper drawing height separately from nominal/loaded contact geometry. Both contacts require assembly. |
| U1/U6/Q5 | Retain the existing exact identities and documented flash/protector geometry corrections. Fine-package stencil/handling remains a supplier disposition; Q5's native circular paste is about 19.5% smaller in area than TI's rounded-square example. |

These differences are **not demonstrated solder failures**, and they are not
silently waived or patched during wrap-up. Contact-height tolerance requires
coordinated mechanical work, not simply changing a number in a released model.
Pickup/rotation, connector hold-down joints, the common stencil/reflow profile,
thermal-pad vias and the distinct under-R27 transition still need an explicit
manufacturing disposition. Do not infer a complete board's reflow profile from
one semiconductor's MSL/260 C classification.

The current source-selection records and this stopped audit are durable
inputs to the next deliberate revision. They do not establish completed
routing, a matched final mechanical assembly or upload-ready quotation files.
No further research or implementation is authorized by this audit handoff.

**Subsequent owner-authorized September 15 application:** U5 and R27's recorded
land examples and conservative envelopes are now applied in the continuing
clock draft. The [source-bound result](../hardware/handbell/iterations/printed-bell-clock-draft/reports/power-device-lands.json)
includes local U5 escape corrections and a matching R27.2 pour-exclusion
enlargement, preserving the private sense connection. The historical audit
above is unchanged; remaining contacts, fine-package stencil/handling and
thermal-pad processes still need disposition.

## Capacitors: 29 fitted

| Group | Count | Existing definition and required action |
|---|---:|---|
| C1,C4,C5,C19,C20 | 5 | 10 uF/16 V, 0805. Select manufacturer/MPN, dielectric/tolerance, maximum dimensions and suitable effective capacitance. |
| C2,C3 | 2 | 22 pF, 0402. Specify dielectric/tolerance/voltage and reconcile with the actual crystal. C0G/NP0 is a proposed specification, not a recorded selection. |
| C6,C7,C9,C12,C13,C14,C16,C18,C23,C24 | 10 | 100 nF, 0402. Voltage, dielectric, tolerance and MPN are absent. The selected C30 identity is not automatically assigned to these references. |
| C8,C10,C11,C15,C17 | 5 | 1 uF/25 V, 0402. Select actual orderable parts and verify DC-bias/dimensions. |
| C21,C22 | 2 | 220 pF, 0402. Define dielectric, tolerance, voltage and EMI/pulse behavior. |
| C25 | 1 | 10 nF, 0402. Complete voltage/dielectric/tolerance/MPN. |
| C26,C27,C28 | 3 | 22 uF, 0805; no voltage/dielectric/tolerance/MPN. Priority power selections: effective capacitance at input/output bias, temperature/tolerance, ESR/ripple and maximum body dimensions. C29 remains DNP unless explicitly changed. |
| C30 | 1 | Explicit Murata GRM155R71C104KA88D, 100 nF/16 V X7R. Complete the exact manufacturer/package evidence; its height entry is still a planning proxy. |

Source BOM lines 4-33. The generic 0805 capacitor height is an unqualified
2.0 mm proxy, not a verified manufacturer maximum.

## Resistors: 28 fitted

| Group | Count | Existing value/identity |
|---|---:|---|
| R1-R5,R7,R14,R15,R18,R21 | 10 | 10 kohm, generic 0402 |
| R6,R11,R22 | 3 | 1 kohm, generic 0402 |
| R8,R12,R13 | 3 | 5.1 kohm, generic 0402; charge-programming and USB-C functions still need application-specific tolerance review |
| R9,R10 | 2 | 22 ohm, generic 0402 |
| R16,R17,R24 | 3 | 100 kohm, generic 0402; R24 is the boost divider's lower leg |
| R20 | 1 | 4.7 kohm, generic 0402 |
| R23 | 1 | 732 kohm, generic 0402; do not let the assembler round the divider value |
| R25 | 1 | Yageo RC0402FR-07330RL, 330 ohm |
| R26 | 1 | Yageo RC0402FR-072K2L, 2.2 kohm |
| R27 | 1 | Panasonic ERJ-6BWFR033V, 33 mohm, 1%, 0.5 W, 0805 |
| R28,R29 | 2 | Yageo RC0402FR-075M1L, 5.1 Mohm |

Source BOM lines 54-81. Generic rows need exact manufacturer/orderable,
tolerance, power and TCR. The five explicit rows still need package/derating
evidence; do not infer the high-resistance part's TCR/voltage parameters from
the 330 ohm family member. R27's 0.7 mm manifest height is not a sourced
maximum, and its nominal power rating is not a board-level thermal result.

## Other components: 26 fitted

| References | Count | Audit disposition |
|---|---:|---|
| BT1,BT2 | 2 | Keystone 254, real B-side assembly. Confirm supplied revision, packaging/pickup and assembly operation. Nominal free-contact height is not loaded spring/retention/current qualification. |
| IC1 | 1 | Recover Raspberry Pi RP2040 from the existing identity/source C2040; do not procure by the footprint name. |
| IC4 | 1 | Recover ST LSM6DSOXTR from the existing exact value. Front placement does not eliminate supplier-tier restrictions. |
| U1 | 1 | Winbond W25Q16JVUXIQ TR is explicit; retain the actual UX land/paste pattern. Correct the maximum-XY proxy below. |
| U2 | 1 | RT9080-3.3 is incomplete. RT9080-33GJ5 is a proposed Richtek orderable, subject to non-SNS pin/package comparison, not already selected. |
| U3 | 1 | Recover Microchip MCP73831T-2ACI/OT from the exact existing value. Preserve the AC charging-profile option. |
| U4 | 1 | MAX98357A is a family name. MAX98357AETE+T is a proposed TQFN orderable; do not substitute a WLP package. |
| U5 | 1 | TI TPS61023DRLR is explicit; attach exact DRL package/manufacturing limits. |
| U6 | 1 | TI BQ29700DSER is explicit. Retain the deliberately reviewed all-NSMD pattern and correct the maximum-XY proxy below. |
| Q1 | 1 | AOS AO3401 base identity; resolve ordering/package evidence. Do not silently change to AO3401A or a clone. |
| Q2,Q4 | 2 | Q4 is AO3400A. Q2's C20917 catalog identifier maps to AOS AO3400A, but imported versus standard SOT23 land patterns still need reconciliation. |
| Q3 | 1 | Diodes DMG3415UFY base identity; freeze orderable/packing suffix and preserve the corrected custom drain land. |
| Q5 | 1 | TI CSD83325L, YJE6 PicoStar. Maximum 1.15 x 2.20 x 0.22 mm has source support; confirm assembly capability and authorized sourcing. |
| D3 | 1 | 1N4148 plus SOD323_MINI is not a package-specific orderable. Select the actual SOD323 device/polarity/ratings. |
| D4 | 1 | Nexperia PMEG2020AEA base identity. Reconcile exact orderable and SOD323F drawing; generic SOD323 names are not interchangeable. |
| FB1,FB2 | 2 | Only "Ferrite", 0603. Define actual impedance/frequency, DCR, rated/DC-bias current and maximum dimensions before selecting. |
| CHG0,L0 | 2 | Orange/red 0603 LEDs need separate exact orderables, polarity, electrical/optical specifications and dimensions. |
| J1 | 1 | Molex 504050-0291 is explicit. Confirm manufacturer/mating/current evidence; 3.1 mm remains a proxy. |
| J2 | 1 | JST SM02B-SRSS-TB is explicit. Confirm suffix/finish and side-entry package; do not substitute BM02/top-entry. |
| L1 | 1 | 1 uH and TDK_VLC5045 footprint family do not establish an orderable. Priority: actual saturation/thermal current, DCR/loss, tolerance, lands and maximum height. Do not invent a part number from the family name or shrink the 5 mm proxy without evidence. |
| X6 | 1 | CUSB31-CFM2AX-01-X footprint alias versus source C165948/HRO TYPE-C-31-M-12 is unresolved. Obtain the exact manufacturer drawing and reconcile the actual lands, NPTH/anchors, mouth and height. |
| Y1 | 1 | 12 MHz/12 pF, 2.5 x 2 mm is not an orderable. Freeze crystal load/ESR/drive/tolerance/stability/pin case/height; do not substitute an oscillator. |

Source BOM lines 2-3, 34, 38-53, 96-103. Existing device/package evidence is
in [the T8 electrical revision](t8-electrical-revision.md), particularly its
flash, protection, contact and footprint sections. Public catalog identity
leads for [Q2](https://jlcpcb.com/partdetail/AO3400A/C20917) and
[X6](https://jlcpcb.com/partdetail/Korean_HropartsElec-TYPE_C_31_M12/C165948)
are not proof of land-pattern compatibility or current stock.

## Geometry and assembly corrections

The manifest has 78 unqualified height-proxy entries, three entries with
manufacturer-height evidence and two nominal contact-height entries.

- U1's depth is 2.0 mm, but the reviewed Winbond dimension is 2.0 +/- 0.1 mm:
  use 2.1 mm maximum along the appropriate transformed axis. The other axis
  already has the larger envelope. See the T8 flash drawing discussion and
  initial manifest lines 2580-2603.
- U6's depth is 1.5 mm; TI DSE0006A 4220552/B permits 1.55 mm. Enlarge the
  relevant envelope in the new candidate, not the preserved snapshot or pad
  identities. See [BQ2970 package drawing](https://www.ti.com/lit/ds/symlink/bq2970.pdf)
  and initial manifest lines 2700-2723.

Proxy centres and native origins also differ: X6 Y-1.115 mm, J2 Y+0.350 mm,
Q3 Y+0.2725 mm and U4 X-0.170709 mm. None of those differences alone defines
the assembly pickup point. Explicitly review actual package centres, pin 1,
cathodes and bottom-side rotation. Inherited rotation metadata is not a
universal correction. The split-land contacts need particular handling.

The original candidate's actual outline bounds are **44.50 x 48.35 mm**,
including contact tabs and USB tongue, not a D43 circular coupon. Preserve
that outline and coordinate supplier-defined rails/tooling/depanelization.
Define thermal-pad via, under-resistor via and stencil treatment. U1's narrow
0.15 x 1.20 mm paste aperture and Q5/U6 packages require specific capability
review. Do not erase USB-clearance findings to obtain a superficially clean
quote export.

## Population and closure

Include both BT1 and BT2. Exclude C29 (DNP), the 18 copper-only features
CHG_EN0/D+1/D-1/GAIN0/TP3-TP16, and MH1/MH2 from component loading.
X1 is absent, not an extra purchase line. Copper jumpers are not fictitious
zero-ohm resistors.

First close L1, C26-C28, FB1/FB2, X6, Y1 and D3; normalize recoverable device
identities and finish the ordinary passive specifications in parallel.
Record explicit proposals and selection/package evidence before exporting a
complete sourced BOM. Incompatible lands and unspecified parts/processes
are quotation-input problems, not merely future functional tests.

Later powered, acoustic, runtime, enclosed-temperature, contact/fault and
charging qualification may remain clearly disclosed prototype gates at
quotation time. No supplier upload, purchase or live-cell approval is implied.
Owning epics: E04/#4, E05/#5, E07/#7 and E08/#8.

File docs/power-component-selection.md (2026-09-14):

# Sourced boost and audio-filter parts

September 14, 2026. These are selected **prototype quotation candidates**,
not a purchase, assembly or safety approval. The
[machine-readable register](../hardware/handbell/parts/power-component-candidates.json)
records exact source URLs/hashes, dimensions, native changes and limits.
The frozen references and power-routing milestone are not edited.

The selected identities and all eleven land/paste changes below are now applied
in the continuing
[clock/integration draft](../hardware/handbell/iterations/printed-bell-clock-draft/README.md#power-land-patterns-applied-owner-pause).
The actual smaller lands retain existing primitive connectivity and quiet
pickoffs without moving parts or changing tracks. Pad-adjacent exposure is
remeasured separately; this does not qualify solder joints or current capacity.

| References | Selected exact part | Important source limits |
|---|---|---|
| L1 | TDK **VLS5045EX-1R0N** | 1 uH +/-30%; 19.5 milliohm maximum DCR; manufacturer current figures use separate inductance-drop and temperature-rise criteria |
| C26-C28 | Murata **GRM21BR61C226ME44L** | 22 uF, 16 V, X5R; typical effective capacitance is about 9.96 uF each at 5 V |
| FB1/FB2 | Murata **BLM18SG121TN1D** | 120 ohm at 100 MHz, maximum initial DCR 25 milliohm; impedance falls substantially with current |

The parent directly read TDK's current product page: it lists **Production**,
magnetic shielding, the exact unsuffixed order code, maximum dimensions and
the same recommended lands as the 20160411 manufacturer drawing. This is
not a delivery/stock guarantee. The primary PDF was not retrieved; the older
drawing was viewed through a public mirror. Murata's exact catalog aliases,
versioned specifications and actual characteristic samples were obtained
directly from its public product-data APIs.

## Fit is not the same as an assembly-ready footprint

All six selected maximum bodies fit the existing conservative local envelopes.
Keep L1's full **5 mm** planning height, even though the selected part is
4.5 mm maximum. Do not use this selection to reduce PCB/speaker spacing.

The original lands are comparatively large and have full-pad paste. Their
similar package names do not establish a suitable solder joint for these
specific parts. The new quote candidate receives deliberate, part-specific
land and paste changes:

| Group | New copper land basis | Manufacturing treatment |
|---|---|---|
| L1 | 1.5 x 4.0 mm, centers +/-1.8 mm, gap 2.1 mm | TDK recommended pattern instead of old 2 x 5 mm full-pad paste |
| C26-C28 | 0.7 x 1.3 mm, centers +/-0.95 mm, gap 1.2 mm | Within Murata's reflow recommendation for this +/-0.20 mm body-tolerance group |
| C1/C4/C5/C19/C20 | 0.6 x 1.25 mm, centers +/-0.90 mm, gap 1.2 mm | Separate pattern for the already selected 10 uF GRM21 part's +/-0.10 mm body-tolerance group |
| FB1/FB2 | 0.65 x 1.2 mm copper, centers +/-0.675 mm | Explicit 0.65 x 0.7 mm solder-mask/paste windows, following the wide-copper/narrow-opening mounting arrangement |

The five additional capacitors are tightly coupled to this issue: the parent
confirmed that they have the same old 1.24 x 1.5 mm native pads/full paste as
C26-C28. Their selected values/MPNs do not change. This is not a blanket
replacement of every 0805 or 0603 footprint.

The ferrite manufacturer's 1.2 mm copper dimension is from its 35 um,
3-4 A mounting-reference category. It does not make the route, amplifier or
whole board a 3 A design. Ordinary pad mask/paste must not duplicate the
explicit windows. Preserve component/pad identities and nets; make the
library, schematic and actual board agree.

Changing copper lands also changes electrical geometry. Reconnect actual
traces and vias where necessary, preserve broad power/return approaches,
and remeasure uncovered necks and voltage-drop paths. Keep the short boost
output loops and the R26/R24 independent reference connections; their old
pad-boundary evidence does not automatically apply to smaller lands.
Supplier stencil/profile/assembly acceptance remains open.

## What the component ratings actually mean

**Inductor:** the 8.9 A catalog point is defined by a 30% inductance reduction;
the 5.1 A figure is a typical DC current causing 40 C self-heating. Neither
permits those currents in the enclosed bell. A tolerance-only 0.7 uH,
2.8-to-5 V, 1 MHz typical-frequency example gives 1.76 A peak-to-peak ripple.
At 2 A mean, this means approximately 2.88 A peak and 83 mW cold winding loss.
AC/core loss, hot DCR, bias-dependent inductance and startup/fault behavior
are not included. TPS61023's limit is a valley-current limit, not a guaranteed
peak-current ceiling.

**Capacitors:** ceramic capacitance falls with applied DC voltage. The
manufacturer's 25 C, 0.5 Vrms typical data give 9.96 uF at 5 V and 9.47 uF at
5.25 V for each selected 22 uF part. C26 must include USB-derived input
voltage, not only cell voltage. Temperature, initial tolerance and small
AC-amplitude effects cannot simply be multiplied into a guaranteed joint
minimum.

TI recommends **4-1000 uF effective output capacitance**, not an invented
20 uF hard minimum. Its 10 uF input statement applies to most applications.
Its feedforward-capacitor recommendation above 40 uF needs the complete
connected output network and operating conditions, not just three nameplate
values. **C29 remains DNP.** An ideal 0.75 A/1 MHz example using the two
typical 5 V-biased output capacitors gives about 16.6 mVpp capacitive ripple;
it excludes interconnect, ESR/ESL, control response and audio transients.

**Ferrites:** the selected pair's cold resistance gives about 37.5 mW loss at
the ideal 3 W/4 ohm planning current of 0.866 A RMS. At 1 A DC bias, typical
impedance is only about 14.7 ohm at 100 MHz and 70.2 ohm at 600 MHz. These
curves do not predict the complete switching/audio waveform or emissions.

BLM18SG331TN1D is a recorded, unselected alternative with stronger
high-frequency suppression but greater resistance and a lower catalog
current rating. Its MAX98357 evaluation-board precedent used 680 pF, whereas
this design retains **220 pF C21/C22**. Neither choice validates the complete
filter or proves 3 W of clean audio.

## Remaining handoff

The continuing candidate now owns native land/mask/paste and connectivity
evidence. Complete routing, current-budget and supplier/process work remain.
The parent consumes its exact final placement in the complete CAD model.
The [USB correction](usb-connector-qualification.md), remaining device
identities and [quotation process](pcba-quotation-plan.md) remain coordinated
dependencies. No fabrication exports are called quote-ready while these
native/assembly inputs are unfinished.

Manufacturer PDFs, mirrors and curve images are retained only as local
research evidence; the public register records factual parameters and hashes.
Original explanation/register: MIT. Adapted electronics retain CC BY-SA 3.0.
Tracking: E04/#4 electrical, E05/#5 mechanics, E07/#7 routing, E08/#8 quotation.

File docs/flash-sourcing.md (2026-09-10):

# Smaller RP2040 flash: sourcing and compatibility

**2026-09-10 sourcing study, not a selected or qualified BOM substitution.**
The owner requested in-stock 2 MB and 4 MB alternatives from major authorized
distributors. These capacities mean 16 Mbit and 32 Mbit respectively; they
are serial NOR flash, not DRAM or PSRAM. Availability and prices must be
observed for the exact ordering code rather than inferred from a general
memory-market description.
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

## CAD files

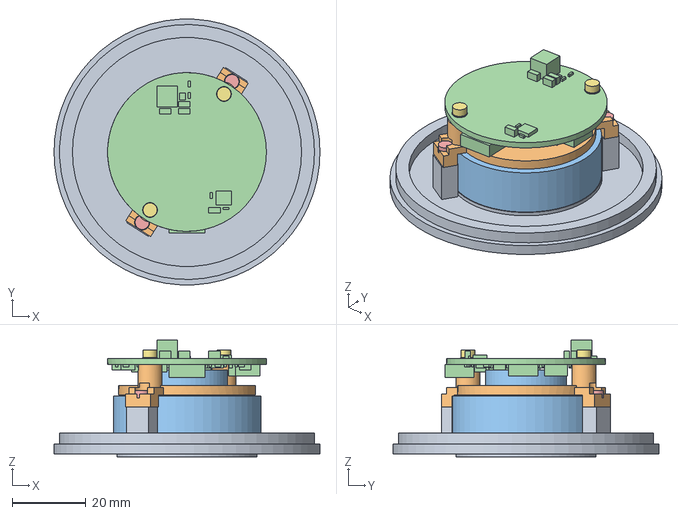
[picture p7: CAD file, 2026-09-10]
mechanical/studies/2026-09-09-integrated-cartridge/integrated-cartridge-assembly.step
72.0 x 71.9 x 31.6 mm

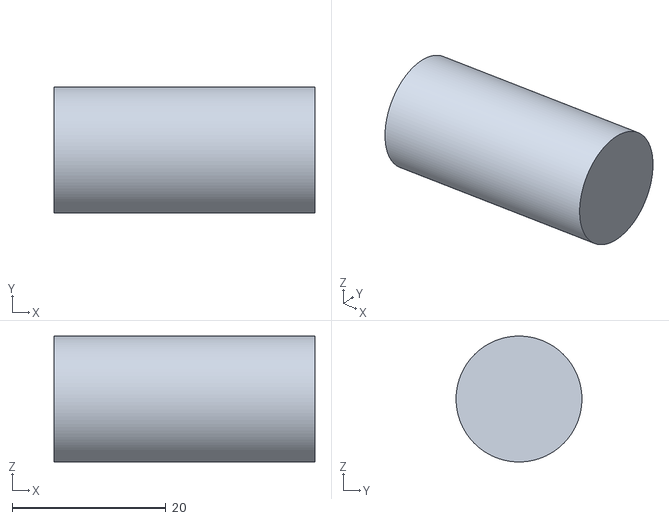
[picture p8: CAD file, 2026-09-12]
mechanical/studies/2026-09-11-t8-cartridge/alternatives/baseline-fixed-stack/INERT-T8-full-cell.stl
34.0 x 16.4 x 16.4

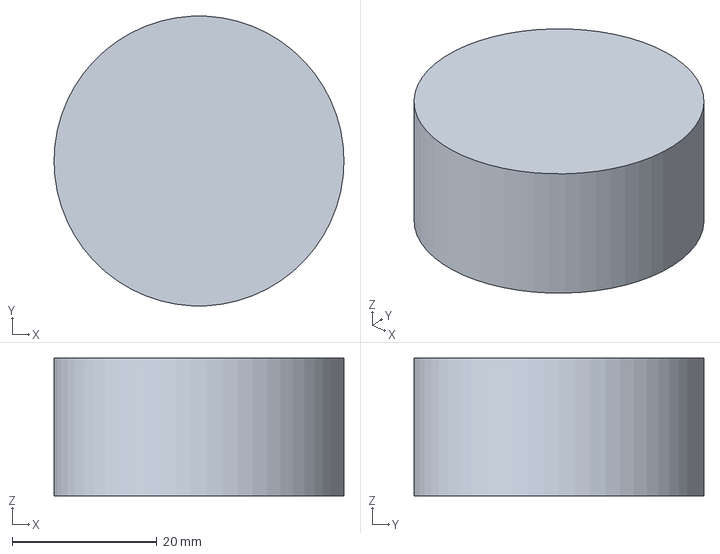
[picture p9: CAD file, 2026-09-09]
mechanical/studies/2026-09-09-measured-speaker/speaker-full-body-cylinder.step
40.0 x 39.9 x 19.0 mm

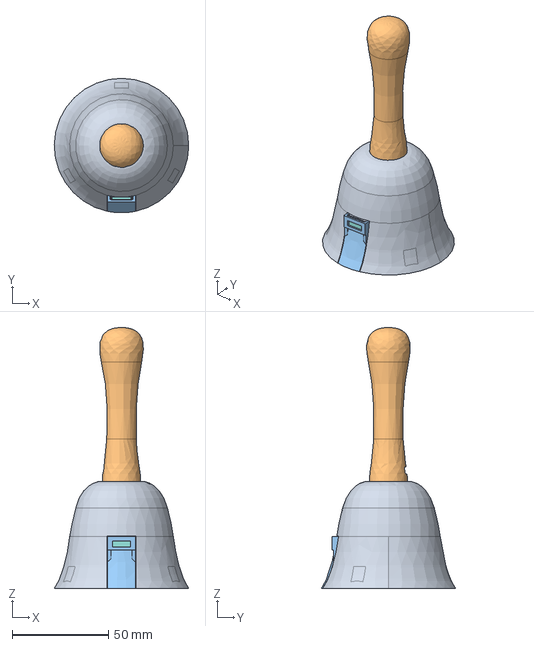
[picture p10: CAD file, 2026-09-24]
mechanical/studies/2026-09-13-printed-bell/imu-four-layer-review/extended-run/printed-bell-complete.step
70.0 x 69.9 x 135.8 mm

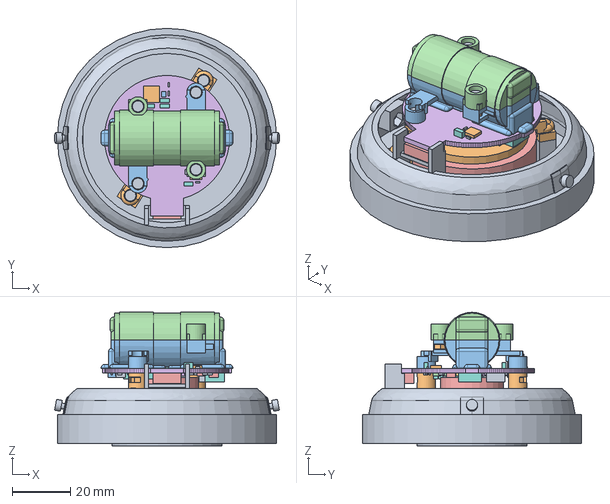
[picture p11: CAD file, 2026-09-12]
mechanical/studies/2026-09-11-t8-cartridge/t8-cartridge-assembly.step
77.5 x 75.5 x 46.0 mm

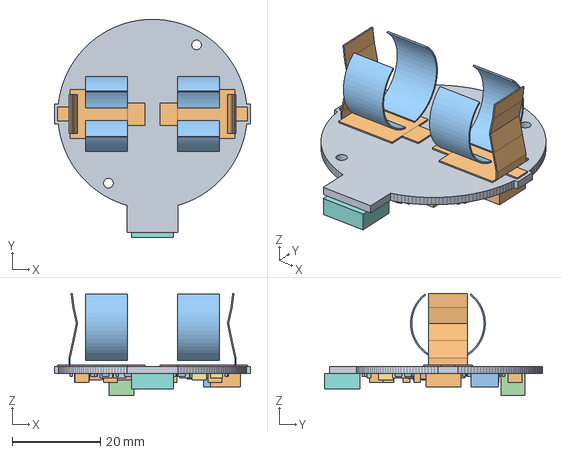
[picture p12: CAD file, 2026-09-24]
mechanical/studies/2026-09-13-printed-bell/imu-four-layer-review/extended-run/full-populated-pcba.step
44.5 x 49.5 x 23.2 mm

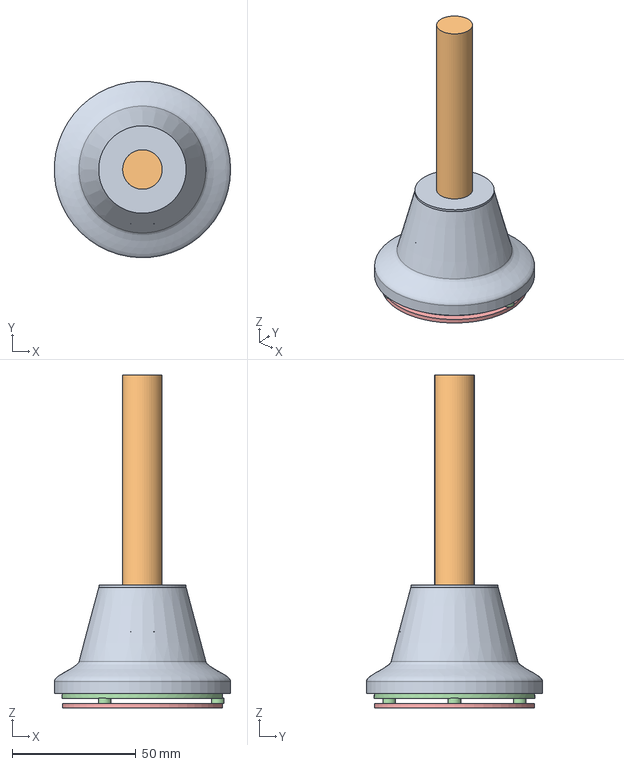
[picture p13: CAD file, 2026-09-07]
mechanical/handbell-assembly.step
71.3 x 71.4 x 134.8 mm

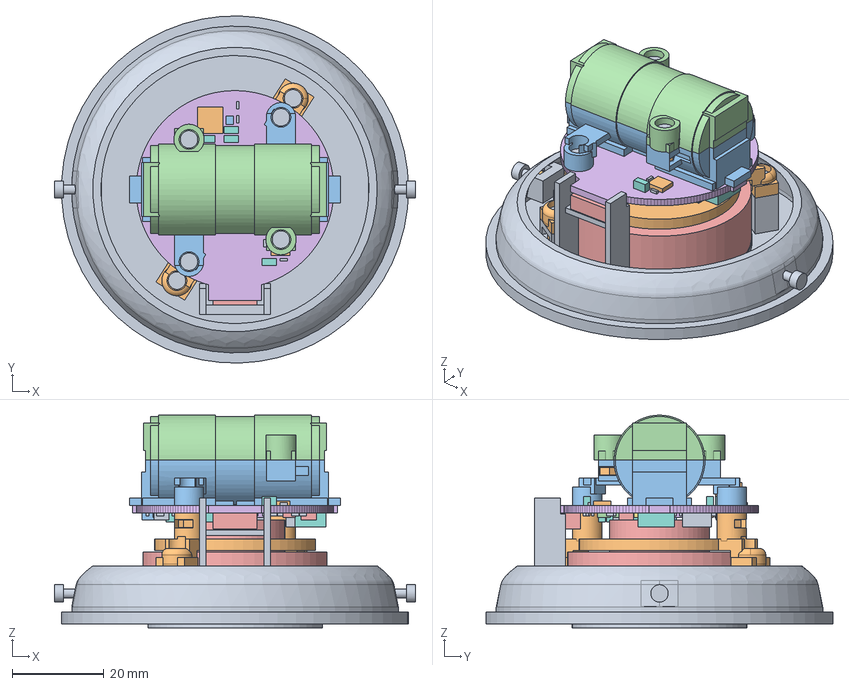
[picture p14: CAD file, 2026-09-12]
mechanical/studies/2026-09-11-t8-cartridge/alternatives/baseline-fixed-stack/t8-cartridge-assembly.step
78.6 x 75.5 x 46.3 mm

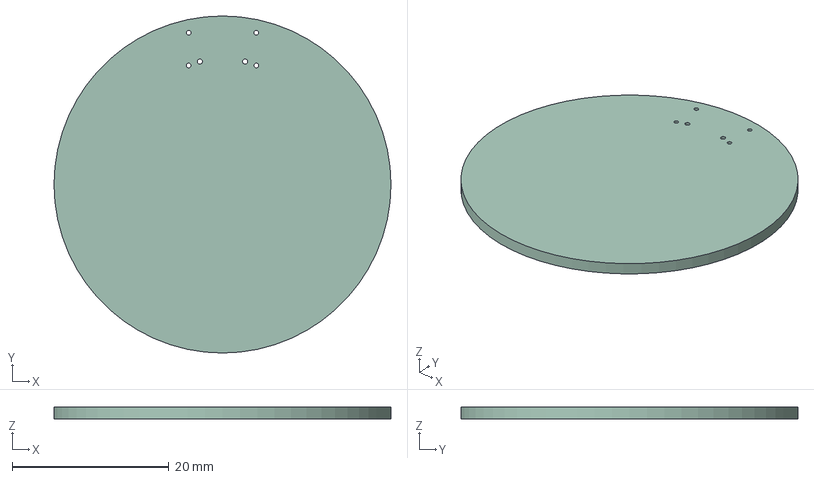
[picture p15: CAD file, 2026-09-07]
hardware/handbell/placement/pcb-substrate.step
43.0 x 43.0 x 1.51 mm

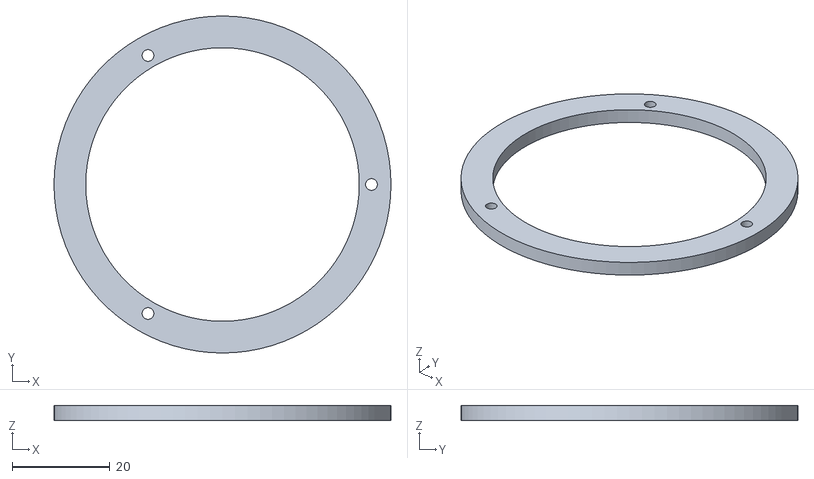
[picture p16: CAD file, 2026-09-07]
mechanical/bonded-interface.stl
69.0 x 69.0 x 3.00

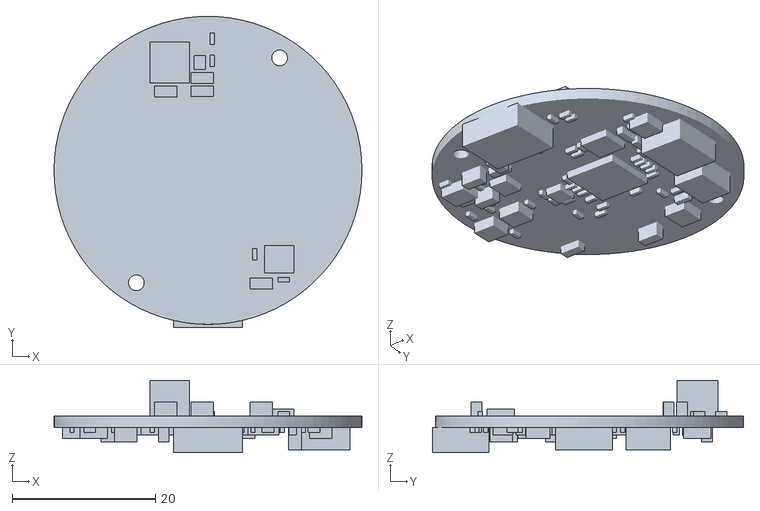
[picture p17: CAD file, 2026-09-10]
mechanical/studies/2026-09-09-integrated-cartridge/INERT-populated-wing-pcba-proxy.stl
43.0 x 43.5 x 10.1

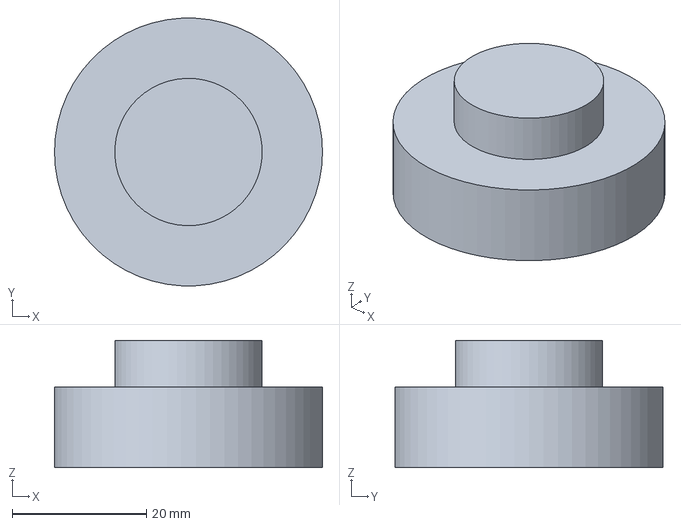
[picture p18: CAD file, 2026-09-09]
mechanical/studies/2026-09-09-measured-speaker/speaker-stepped-body-envelope.step
40.0 x 39.9 x 19.0 mm

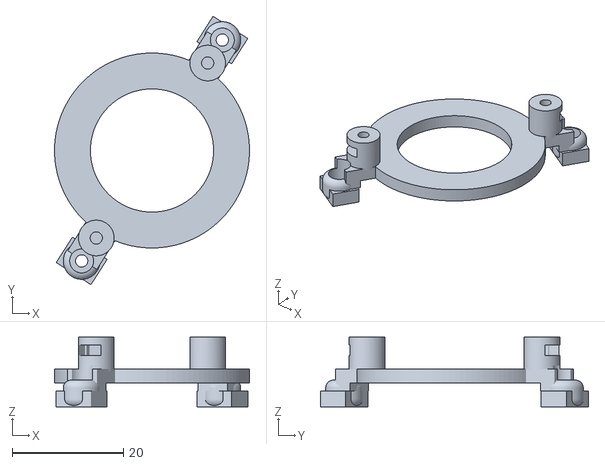
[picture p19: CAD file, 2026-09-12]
mechanical/studies/2026-09-11-t8-cartridge/alternatives/baseline-fixed-stack/INERT-yoke.stl
35.0 x 48.2 x 12.5

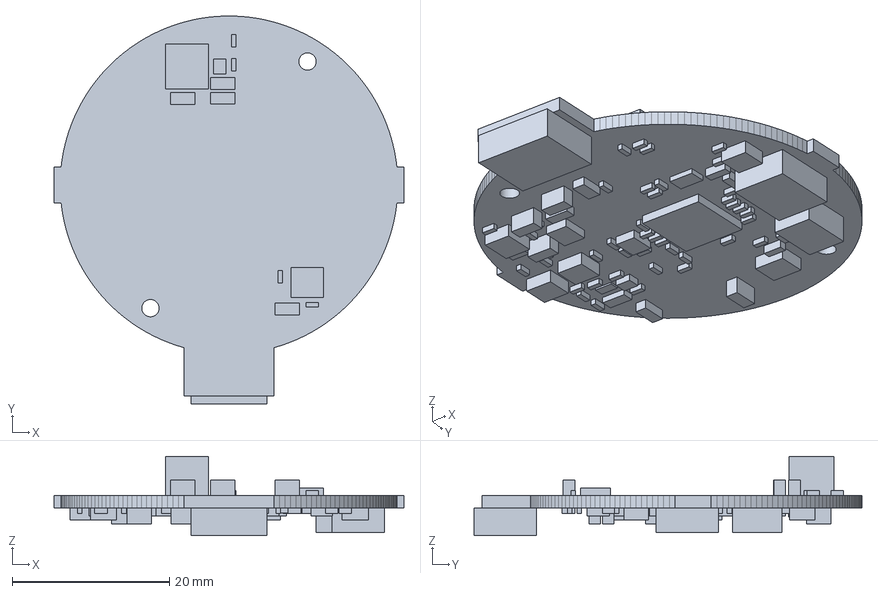
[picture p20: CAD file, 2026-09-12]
mechanical/studies/2026-09-11-t8-cartridge/populated-t8-pcba-without-contacts.step
44.5 x 49.4 x 10.1 mm

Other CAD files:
mechanical/studies/2026-09-11-t8-cartridge/INERT-T8-full-cell.stl
mechanical/studies/2026-09-13-printed-bell/imu-four-layer-review/extended-run/INERT-full-cell.stl
mechanical/studies/2026-09-13-printed-bell/imu-four-layer-review/extended-run/INERT-flush-carrier.stl
mechanical/grille.stl
mechanical/battery-clearance-compact.stl
mechanical/battery-clearance-primary.stl
mechanical/battery-dummy-compact.stl
mechanical/battery-dummy-primary.stl
mechanical/fit-carrier.stl
mechanical/handbell-feasibility.FCStd
mechanical/populated-pcba-proxy.step
mechanical/populated-pcba-proxy.stl
mechanical/speaker-envelope-maximum.stl
mechanical/speaker-envelope-nominal.stl
mechanical/speaker-illustrative-unmeasured.step
mechanical/speaker-illustrative-unmeasured.stl
mechanical/studies/2026-09-09-integrated-cartridge/INERT-integrated-grille-seat-body.stl
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

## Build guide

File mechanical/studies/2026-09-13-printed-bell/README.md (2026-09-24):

# Original printed bell — September 13

**Latest engineering review: four-layer IMU closure, September 24.**
Open [the completed native assembly](imu-four-layer-review/extended-run/printed-bell.FCStd)
or [complete STEP](imu-four-layer-review/extended-run/printed-bell-complete.step).
The separate [fit report](imu-four-layer-review/extended-run/fit-report.json)
and [artifact manifest](imu-four-layer-review/extended-run/artifact-manifest.json)
bind PCB `d2a098b0...` and the preserved manifest `443fe1b5...`.
IC4/R15's 0.50 mm shifts and the approved HRO USB envelope are included.
The flat USB skin moves 0.15 mm outward while retaining the native
connector datum, closed frame, loading gap and assembly/service checks.

The authorized run finished in 440.1 seconds with zero nominal material
intersections and passing native, STEP and inert-STL checks. This is not
physical tolerance, mating, insulation-material, live-cell, powered,
supplier or child-use qualification. The parent `imu-four-layer-review`
files are the incomplete first attempt; use **`extended-run`**, not those
partial files. Its ignored raw build log is private installation evidence.

**Preserved earlier assembly:** the remainder of this page describes the
power-rework artifacts at the study root. They have not been overwritten.

**Exact all-front power-rework assembly; an intermediate routing milestone,
not the final fabrication model.** The native and exports at this
study root bind the actual `printed-bell-power-rework` PCB, schematic, manifest,
contact companion and source libraries: **81 F electronic parts plus two
fitted B contacts**. No PCB growth, changed mounts, USB relocation, lowered
cell or shortened inductor was required.

The ten local power-layout pose changes and audited U1/U6 maximum-depth
enlargements are now represented in the full assembly. D3 still gives the
smallest nominal component/speaker gap, 0.400 mm; L1 retains its 0.700 mm
yoke gap. All seven actual rear service labels have separate current-model
visibility evidence in the electrical package. The six structural print
geometries are unchanged. The prior stage-1 assembly remains in commit
`4bbdcbb0ee1724b450b66f3a03abcaa8c48333d1`.

The recorded power-rework checker passed exact input/output hashes, native/STEP BRep
round trips, all nine inert meshes, zero static material overlaps and the
declared assembly/service poses. This is engineering confidence in the
**unchanged mechanical interface**, not electrical-rule waivers, physical
tolerances, a qualified print, live-cell use or fabrication approval.

The earlier `development` directory is explicitly a frozen mixed-face
checkpoint, **not the current assembly**. Use the latest review linked above.
Final mode never automatically falls back to that old electronic population.

**Parent visual-review finding corrected:** the former R29.5 shell-fastener
pockets broke through the cosmetic exterior. Static nonintersection alone
had not established a closed skin. The three printed shell/carrier joints
are now at **R26.5, angles90/210/330 degrees**, with radial hex flats,
inside-only nut entry and positively verified **at least1 mm geometric
exterior stock**. The actual shell retains every original revolved cosmetic
side face except the intentional USB channel; measured missing face area
in the BRep check is **0 mm2**. PCB, USB, speaker, cell and contact datums
did not change. The earlier rendered checkpoint remains preserved at
commit `6e7ef9ef4dd1f6611695e73227630fdc5c8dae7a`; a new parent rendering
should use the corrected root native, not those earlier images.

## Released mechanical interface for routing

The actual all-front placement and full retained contacts fit the complete
shell/cartridge/yoke/capture/handle assembly. Critical routing can proceed
without changing the D43 outline, mounting holes, USB XY/Z, contact lands,
cell axis or speaker-relative PCB stack listed below. Keep these interfaces
fixed. Copper-only changes still require a new exact-byte bind by the parent;
do not silently treat a changed PCB hash as already reviewed.

| Bound source | SHA256 |
|---|---|
| Placement manifest | `60e394c41bcfd7734b41c7713100360253164381f0217eed325386bd49977799` |
| Actual PCB | `6132f8d3ec508f8ae023888052cc2a1f8b2c24f2c38d9d12dca3234ba887dcc1` |
| Actual schematic | `e131a8d093795df7285bcae4a8886ffe01106c6513a19bd588ee7c29c6993b4f` |
| Contact companion | `f96133d9f044600167477bcddbf67c43311ed0897066db9fa63d8e7f8118467b` |
| Dated design-input bytes | `e0006b59412f4a0184744e0aa9cebbab2b7f11e57228aa5997de904f1b48916e` |
| Current FreeCAD native | `2a923489d72297a27e0bd05760b09d3ed2e19513efced5a6510add9d7b53cb4b` |

The electrical package retains 155 unconnected items, four known USB clearance
findings and unfinished silk/text work; mechanical release does not waive them.
The newly documented lost USB anchor-slot import and exact connector drawing
remain qualification work, so this model does not approve the current USB
drills or a future replacement footprint.
Actual USB tails/cable, loaded contact/cell geometry, insulation, strength,
temperature and printing gates remain open as detailed below.

## Shape and size

This is an original revolved Bezier design: continuous flared mouth, concave
sides and rounded narrow crown, with no broad handguard disk. No supplied
photograph, traced outline, logo or artwork is imported or redistributed.

| Working CAD feature | Dimension |
|---|---|
| Maximum shell diameter | 70 mm, versus previous 75.5 mm comparison |
| Shell body height | 55.8 mm, versus previous 56.3 mm assembly comparison |
| Handle above crown | 80 mm, versus previous 85.5 mm |
| Complete height | 135.8 mm |
| Grille/front mouth plane | z0, no projecting skirt |
| Speaker front / conservative basket rear / magnet rear | z4.5 / 16.5 / 23.5 |
| PCB F / B | z25 / 26.6 |
| Full D16.4 x L34 provisional cell axis | z36.38 |
| PCB mounting holes | (+10,+15.7), (-10,-15.7), D2.2 |
| USB native origin / mouth | (0,-22.82) / (0,-27.90) |

These are authored CAD dimensions, **not measured tolerances**. The profile
does not rescale the old metal bell. Its independent cavity follows the
retained hardware, and the flush carrier replaces the former projecting
external band. Exact part volumes and component/structure distances are in
`fit-report.json`; do not convert volumes to mass without a
declared material density and slicer settings. No normal wall thickness,
global printable tolerance or support-free claim is made.

Current nominal solid volumes (not slicer consumption or measured mass):

| Printed part | BRep volume |
|---|---:|
| One-piece shell | 22.413 cm3 |
| Black handle | 19.883 cm3 |
| Flush carrier/bezel | 9.656 cm3 |
| Retained yoke | 2.117 cm3 |
| Retained cradle | 2.112 cm3 |
| Service-relieved cover | 1.597 cm3 |

The carrier is approximately 57.4% lower volume than the preserved T8 body;
this comparison does not imply equal stiffness or printing time.
The actual **all-front** minimum component-to-speaker gap is **0.400 mm
(D3)**; the minimum component-to-yoke gap is **0.700 mm (L1)**. L1 retains its
full 5 mm height at z20..25 and clears the yoke top z19.3. The USB source
body-to-carrier ledge gap is **0.200 mm**. These small CAD distances are not
qualified printing, component-envelope or assembly tolerances.

## Six structural prints and the retained architecture

The shell is **one connected printed solid**, including its crown and three
cartridge attachment lugs. The black handle is separate. The cartridge still
has four pieces: flush grille/carrier, speaker yoke, cell cradle and cover.
Yoke and cradle are exact read-only T8 BReps translated into the new frame.
The cover retains that architecture but adds two straight upper-spring service
channels and outside wall stock, described below. Successful capture, M2
joints and under-cell insulation are not casually replaced.

The carrier has a flush perforated grille, speaker seat, two yoke supports,
USB support ledge and color-matched service-channel filler. Removing the
old exterior skirt reduces material without cutting away the cell capture.
The speaker remains the conservative D40 body through 12 mm, followed by
D21.70 x H7 magnet. An illustrative tapered basket is **not** substituted
to hide interference. Rim bearing, terminals, wires, vent and excursion
remain unqualified.

Only the inert PCBA STL omits BT1/BT2. Full **thin** contacts remain in native
and STEP. They are still fitted components and are not copper-only BOM
exclusions. Known T8 fold-root meshing limitations are not repaired by
inventing connecting metal.

### Battery insulation and retention

The cell remains at PCB B + 9.78 mm. The 0.30 mm contact base stays below a
verified 1.08 mm under-cell plastic section; no floor or contact is lowered
through metal for apparent height savings. Exact retained contact/guard
geometry is checked against the supplied contact contract in final mode.
The inherited constructive guard-stock proof is identified as historical
evidence for unchanged local material; its old metal-shell margin does not
apply to this new shell. The new full-PCBA service check found that the old
cover's purely vertical removal path crossed the outward-flared spring tips;
the old check had included only cell and cradle, not contact metal.
The new cover therefore has straight end clearances with added exterior
stock, preserving witnessed **1 mm actual external end, side and top walls**.
Neither thin contact nor the cradle floor is clipped. The split seam and
cell-facing contact opening remain intentional, unqualified insulation
interfaces—not a claim of a globally sealed dielectric enclosure.

The cover/cradle provides stops in all six directions with the cartridge
outside the shell. Half-millimetre inert-cell displacement probes demonstrate
geometric stops, **not** force, loaded spring travel or impact retention.
Plastic outside removes the former metal-shell short path but not the
positive contact below the negative cell can. Wrapper abrasion, independent
insulation, cell polarity/button, contact force and raw CELL_NEG isolation
from protected GND remain gates.

## USB and reversible servicing

There is a 15 mm wide **mouth-open** -Y shell channel, filled by a 14.4 mm
color-matched bezel integral with the cartridge. Installed cosmetic continuity
does not rely on a broad exterior band.

**Second parent visual finding corrected:** the original rearward loading
cuts removed the curved bezel above/around the connector, so the nominal
9.2 x3.1 cutter did **not** define the whole effective opening and a blue
PCB-edge strip remained exposed. The carrier now includes a real,
same-color **locally raised flat front skin**, not a visibility/rendering fix:

| Actual port feature | Authored dimensions |
|---|---|
| Skin width / height / thickness |14.4 /7.0 /1.0 mm |
| Front / rear planes |y-29.1 /-28.1 |
| Skin bottom / top |z20.0 /27.0 |
| Effective aperture |x-4.6..+4.6, z21.7..24.8: **9.2 x3.1 mm** |
| Material beside / below / above aperture |2.6 /1.7 /2.2 mm |
| Skin-to-source USB separation |0.200 mm |
| Skin-to-actual PCB separation |1.250 mm |
| Skin-to-shell separation |approximately1.055 mm |

The skin lies wholly ahead of the rear loading cuts beginning at y-28.0.
It joins the existing carrier rails with real material. The actual cut
front-face opening is **28.52 mm2**, exactly the intended aperture:
both additional opening area and blocked intended area are **0 mm2**.
The complete1 mm thick frame is contained in the released carrier.

The entire actual PCB tongue-front projection (x±5.75, z25.0..26.6) has
real1 mm material in front of it. The upper lip therefore conceals that
edge in the horizontal -Y front view; arbitrary oblique sightlines are not
claimed. This does not hide or move a PCB object in the native model.
The whole PCBA remains at least0.2 mm behind the skin rear plane for
**every pure Z loading translation**, and the complete assembly-path checks
still pass. The original receptacle/PCB datums and source envelopes are
unchanged, and the under-body ledge remains0.2 mm below the nominal USB body.
All carrier material remains within the existing D70 ceiling; shell
D70/H55.8 is unchanged.

An explicitly **unselected** 8.8 x 8 x 2.6 mm male-nose screen approaches
the source mouth without intersecting shell/bezel. In addition to pose
checks, the **exact continuous straight swept union** of that8 mm nose
over12 mm approach travel, spanning y-47.9..-27.9, has zero shell/carrier
intersection. This does not prove actual mating depth, overmold fit, a
complete cable or insertion force. Source
through-board anchor XY reservations are retained as hidden planning
projections, not invented tail-height solids.

Unplug before removing the three recessed front M2x8 screws. The captured
cartridge withdraws straight mouthward through the open channel; a closed
side hole would trap its protruding connector. The carrier ledge/rails,
front screws and shell are the intended handling-load path, not unsupported
solder anchors. Their physical force/deflection performance is unqualified.

### Closed-skin shell/cartridge fasteners

Only the three **printed shell-to-cartridge** joints moved. They are not the
two PCB mounting holes. Their common XY centers are (0,26.5),
(-22.949673,-13.25) and (+22.949673,-13.25). Rotating the pattern away from
the retained lower yoke posts/nuts and the USB channel permits inward
placement without colliding during whole-cartridge withdrawal.

Each M2 nut enters radially **from inside the empty shell**, through its
inward-opening slot. Nut/pocket hex flats face radially. The seated nut
occupies z7.0..8.6, inside a z7.0..8.9 pocket. The M2x8 screw head remains
recessed in the front carrier: under-head z2.3, tip z10.3, complete1.6 mm
nut-body coverage and1.7 mm beyond the nut. The nut bears on a witnessed
**3.7 mm actual shell floor**, with a **2.6 mm captive roof** above the pocket.
Neither nut fit nor nominal screw coverage is a qualified preload/thread,
torque, loose-part retention or printed-strength rating.

`shell_cartridge_joints` in the fit report records:

- **All nine actual void primitives**—three hex pockets, three inward
  loading slots and three screw bores—positively offset by1 mm and wholly
  contained within the unchanged outer solid, clear of the USB opening.
- The original lower cavity positively offset by1 mm and contained within
  that outer solid across the complete affected z band.
- Actual floor/roof annulus material contained in the released shell.
- Zero missing original cosmetic-side surface area except the deliberately
  mouth-open USB channel.

These constructive checks establish exterior stock without unsupported
nested-shell distance extrema or a rendering/transparency trick. Interior
nut entry and front screw access are intentionally open; there are **no
additional cosmetic side openings**. Exact static checks, inward nut
loading, front screw insertion/removal and driver paths, and cartridge
withdrawal with the shell nuts left installed all pass. D70/H55.8 and the
one-solid shell are unchanged.

### Rear polarity-label visibility

The proposed `+POS` at(+11,10.5) and `-NEG` at(-11,10.5) are **obscured by
the retained cradle**, even with the cover removed. The negative position
also projects beneath its retained cover-joint nut. No PCB was edited and
the active routing source was not read.

The following existing-PCB locations pass complete rectangular sight-column
checks with the cartridge outside the shell, cover and its screws removed,
and cell/contact metal still installed:

| B.SilkS text | Recommended common XY | Maximum screened text rectangle |
|---|---|---|
| `+POS` | **(+15.7,+11.0)** |4.4 x1.4 mm |
| `-NEG` | **(-15.7,+11.0)** |4.4 x1.4 mm |
| `T8 BUTTON END >` | **(0,+10.5), unchanged** |12.0 x1.4 mm |

The full rectangles lie on the exact existing PCB and have zero projected
capture/cell/contact/hardware obstruction. They are **mechanical reservations,
not inspected KiCad glyph bounds**: the electrical owner must keep actual
mirrored B.SilkS strokes within these envelopes and run native silk checks.
Hidden native reservation boxes and `back_silk_visibility` record both the
rejected initial locations and tested alternatives. These label moves do not
change the mechanical PCB freeze.

## Handle and shell load path

The working handle uses a **M4x16 machine screw** pointing handleward from
inside the empty crown, nominal pan head D8/H3.1, large washer
OD12/ID4.3/H1 and metal nut AF7/H3.2. This is a geometry selection using
parent-confirmed **supplier dimensional tables**, not inspected ISO primary
standards or a qualified hardware lot, and not an interchangeable 8-32 thread.
The [ISO7045-labelled supplier page](https://www.fasteners.eu/standards/ISO/7045/)
explicitly displays a **DIN7985** table. The model screens its maximum
head diameter 8.0 mm and height **3.25 mm**, M4x16 under-head length
15.65..16.35 mm, [nut](https://www.fasteners.eu/standards/ISO/4032/)
AF6.78..7.0/H2.9..3.2 and [large washer](https://www.fasteners.eu/standards/DIN/9021/)
ID4.3..4.48/OD11.57..12.0/H**0.9..1.1 mm**.

The nut slides through an accessible side tunnel and bears on real printed
material. A 12 x 10 x 2 mm keyed tenon engages the crown, so friction or
printed screw threads are not the only antirotation means. There is no
handguard disk. The nominal screw fully spans the 3.2 mm nut and projects
3.45 mm past it. Even the shortest screw with the thickest washer projects
3.0 mm beyond the maximum-height nut; full nut-body coverage is 2.9..3.2 mm.
This is **not certified effective thread engagement**: actual thread runout,
chamfers and a fully threaded supplier part still need confirmation.
The washer bearing region contains a checked OD12/ID4.4 annulus
of 2.35 mm actual shell material below the key pocket.

Nominally the screw head is z47.2..50.3, washer z50.3..51.3 and nut
z59.65..62.85. Tolerance cases hold the washer bearing plane at z51.3:
the thickest washer plus highest head reaches mouthward to **z46.95**.
The screw tip range is **z65.85..66.75**; the extended blind bore ends
at z68, leaving at least **1.25 mm** tip clearance.
The tolerance-case BReps and empty-shell insertion checks are recorded in
`handle_joint.supplier_tolerance_screen` and hidden native construction objects.
In the current retained capture geometry the screw-to-cell distance is
2.62 mm and screw-to-cover distance approximately 1.353 mm.
Those two values are **nominal**, not the conservative tolerance-case result.
At maximum head/washer thickness, the checked clearances are **2.370 mm to
the cell and 1.133 mm to the cover**. The authoritative report separately
lists each maximum-head/washer case.
None is a physical fit, torque, preload or printed-strength rating.
**M4x20 is not interchangeable:** its maximum tip would reach z70.8,
2.8 mm beyond this blind bore, requiring a redesign and new bind.

**Handle loads go through nut, screw, washer and integral shell crown, not
through the cell or PCB.** Install/remove this joint with the cartridge out;
the battery correctly blocks an axial driver when installed. The modeled
empty-shell straight-driver and screw/washer/nut insertion paths are recorded.

A later turned-wood option can use the same original exterior silhouette,
but needs a separately engineered metal insert/cross-dowel, keyed shoulder
and wood properties. No wood pilot, ordinary wood screw or printed thread
is qualified here. Changing the screw length requires checking engagement,
tip clearance and tool access again.

## Assembly and printing

1. With the shell empty, side-load the handle nut, fit the keyed handle and
   insert washer/screw upward through the mouth. Install the shell's three
   M2 nuts inward-to-outward in their roofed pockets.
2. Outside the shell, install the carrier nuts, load the speaker first, then
   fit the yoke and its two retained M2x6 screws. The D40 speaker cannot pass
   through the installed small magnet aperture.
3. Load the yoke nuts, lower the PCBA into the open-top USB support, then add
   the empty cradle and two M2x6 screws.
4. For inert evaluation only, install the cell surrogate, cover nuts and
   cover with its two M2x6 screws. Keep capture closed during whole-cartridge
   removal.
5. Align the port bezel, insert the cartridge and install three front M2x8
   screws. Reverse the sequence to service. Loose nuts need a tray.

The model includes static material intersections, finite withdrawal/plug
poses, speaker-before-yoke, yoke-over-magnet, PCBA loading, cover removal,
M2 driver access, handle installation and shell nut loading. Finite poses
are not exhaustive continuous-motion or deformable-contact proofs.

Print the **shell mouth-down/handle-up** and the **grille separately
face-down** for a smooth cosmetic exterior. The upper internal crown slopes,
nut-pocket roofs, locally raised USB surround/aperture roof and handle side tunnel need explicit slicer support/
bridging review. The wide mouth gives internal support-removal access
**before assembly**. No universal support-free claim is made. STLs retain
assembly coordinates: import millimetres at 100%, translate/reorient, never
scale. Material/strength/creep/temperature settings are the parent's separate
evidence work; silk appearance alone qualifies none of them.

## Files and review

Open [`printed-bell.FCStd`](printed-bell.FCStd) for the current assembly. Gold shell/
carrier, black handle, amber yoke, blue/cyan capture and purple cell have
saved headless visibility/color metadata. Construction references (USB nose,
anchor reservations, export compounds and driver) are hidden. Shell
transparency assists parent GUI inspection; no GUI approval is claimed.

The study root contains full assembly/cartridge/PCBA STEP, component STEP,
six structural INERT STLs plus contact-free PCBA, speaker and full-cell
surrogates, original profile SVG, exact raw-input snapshots, fit report,
artifact inventory, fresh completion marker and local build log.

See [REPRODUCE.md](REPRODUCE.md). The native report records FreeCAD1.1.3,
OpenCASCADE7.8.1 and bundled Python3.11.14. Its
`routing_interface.mechanical_freeze_recommended` is true for the **exact
bound stage-1 sources**, not a different board or an electrical/safety signoff.

Original mechanical geometry, SVG, code and documentation are MIT under
[`mechanical/LICENSE`](../../LICENSE). Mixed populated exports retain the
adapted electronics' **CC BY-SA 3.0** context and full
[hardware notices](../../../hardware/handbell/README.md) and
[attribution policy](../../../ATTRIBUTION.md): Limor Fried/Ladyada for
Adafruit Industries (5768/4654), Bryan Siepert for Adafruit Industries (4438).
Do not distribute populated files under a blanket MIT label.

Owning epics: E04/#4, E05/#5, E07/#7 and E10/#10. No purchase, fabrication,
live-cell activity, GUI launch, issue posting, commit or push is performed
by this mechanical implementation.

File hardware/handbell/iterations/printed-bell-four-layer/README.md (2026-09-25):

# Printed-bell four-layer routing baseline

**Current acceptance: eastern MCU ground closure.** Active PCB
`adc262b3e7056cb9031387c55262b5cf99e599ae6e28970f9784f5237e662314`
and manifest
`b849b5defb95f010f555d43b6d261fdea3ef37e240aee0190a607fb519c642f8`
have **37 opens, 234 non-open findings and 46 enabled parity findings**.
One ordinary off-contact via and a short F connection restore the shared
C6/C7/C8/C13/C17 ground island to In1 MAIN, with no placement or existing
copper changes. The [acceptance record](reports/mcu-east-ground-acceptance.json)
binds validation and Astra's filled-layer review. Exact CAD rebinding is
required; the prior completed IMU CAD is preserved, not relabeled as a
match to the new board. VCORE distribution remains unfinished. This is
not powered, PI, manufacturing or safety approval.

**Earlier acceptance: integrated IMU closure.** Active PCB at that checkpoint
`d2a098b0dcd198fb790e6dd4341c036814aabba7fa2ef7c278c79a0a2c916711`
and manifest
`aa68559eebaf8a43c369f549deed1f025d393bafe2d4323d2098fa4712ef622c`
have **38 opens, 234 warnings and 46 enabled schematic-parity findings**.
The [acceptance record](reports/imu-closure-acceptance.json) binds electrical
evidence and the completed full CAD, with an exact lifecycle-only bridge
to its immutable input manifest. IC4/R15 are each shifted north 0.50 mm;
local IMU supply, I2C, ground and INT2-to-TP6 are closed. External
INT-to-IC1.34 remains open. This is an incremental engineering checkpoint,
not fabrication, powered or safety approval.

**Earlier acceptance: C24 ground via.** One centered 0.60/0.30 mm
through-via connects C24.2 to the existing In1 ground plane, without
changing its land, mask, paste, other copper or F/In1 filled geometry.
PCB `c7b6b6fdb9857f7ea993e3cad37c04e852981eceea5146802cadb35865b2cec7`,
manifest `08bf866d80f74775ff4099e4734da0d445fd359843f61637bf453abf002fe667`.
**41 opens**, 233 warnings and 46 historical parity notices remain.
**Mandatory process:** this C24 via requires nonconductive resin fill,
planarization and copper capping, in addition to U4's four required vias.
Tenting is not a substitute; native treatment flags were not added.
Carry the [exact treatment map and acceptance record](reports/c24-filled-via-acceptance.json)
into quotation/fabrication notes. Supplier, stencil, yield and cost
qualification remain open. This is not fabrication or powered approval.
Earlier checkpoints below are historical.

**Separate incomplete IMU working fixture:** the
[archived PCB](reports/imu-fanout-method-staged.kicad_pcb) and
[manifest](reports/imu-fanout-method-staged-manifest.json) preserve an
unfilled, deliberately disconnected local rework with IC4 moved north
0.50 mm and one replacement SCL escape. They are **not the current accepted
board or a self-contained fabrication package**. The
[source-invariant qualification](reports/imu-fanout-method-validation.json)
does not qualify full routing, DRC, powered behavior or mechanical fit.
Continue only through the [current closure handoff](../../../../docs/pcb-closure-plan.md#owner-pause-and-next-item).

The subsequent [working PCB](reports/imu-coupled-working.kicad_pcb) and
[working manifest](reports/imu-coupled-working-manifest.json) now contain
the [complete local primitive block](reports/imu-signal-layer-correction.json):
local supply, SCL, SDA, INT2-to-TP6 and an INT local exit are connected.
At that primitive checkpoint, ground straps reached C23.2/local via but
MAIN-plane attachment had not yet been proved.
IC4 and R15 are each shifted north 0.50 mm in this working candidate.
Ordinary-via off-pad checks pass without a new via-in-pad dependency.
Their native
[front](reports/imu-working-front.png)/[inner](reports/imu-working-inner.png)
views are source-bound, not complete group/plane or source/DRC qualification.
Full electrical and mechanical acceptance gates remain open, along with
the external INT-to-MCU connection. The earlier
[failed signal screen](reports/imu-signal-closure.json) is historical;
the corrected plan was applied after explicit September 24 resumption.
Follow the [current handoff](../../../../docs/pcb-closure-plan.md#owner-pause-and-next-item).
Earlier working versions/reports are historical; the handoff records the
precise current evidence limits and remaining replacement duties.

**Separate filled recovery candidate, not promoted:** the
[filled PCB](reports/imu-electrical-filled.kicad_pcb) (`79a1dee3...`) and
[matching manifest](reports/imu-electrical-filled-manifest.json)
(`eb37d87f...`) have **38 opens**, 236 warnings, no non-open DRC errors,
and unchanged 46 parity notices. Existing connected pad groups and both
private protection-sense paths are preserved. The
[corrected ground review](reports/imu-ground-anchor-review.json) proves
all five IC4 ground pads and C23.2 reach the actual In1 GND island;
`/CELL_NEG` remains isolated. The earlier diagnostic failure used +3V3
IC1.49 as a ground reference and is superseded, not a repair obligation.
The three new dangling warnings are the intentional INT exit and two
preserved exterior stubs; none has been suppressed or trimmed.
Later source/process/geometry and CAD evidence supersede that stage's
pending gates. These historical recovery files are not quotation or
fabrication assets.

**Cleaned IMU candidate, electrical and CAD checks complete:** the
[cleanup PCB](reports/imu-cleanup-staged.kicad_pcb) (`d2a098b0...`) and
[manifest](reports/imu-cleanup-staged-manifest.json) (`62ea87d6...`)
remove only the two proved obsolete terminal branches. The
[final saved-board report](reports/imu-cleanup-final-validation.json)
confirms **38 opens, 234 warnings and 46 enabled parity findings**,
preserved connected groups/protected returns, and cleared fill/geometry
gates. The intentional unfinished INT exit remains. The earlier API and
unchecked-parity reports are historical, not remaining repair obligations.
The [completed CAD run](reports/imu-cad-extended-run.json) includes the
exact placement and approved USB skin adjustment, with preserved source
snapshot `443fe1b5...`. The exact cleaned PCB now replaces the accepted electrical package through
the lifecycle-metadata binding record above. The staged manifests remain
immutable historical evidence. It is not fabrication-ready.

**Earlier acceptance: paired C12 supply/ground closure.** A shorter feed
from the existing In2 +3V3 bridge replaces only the upstream F supply
segment, preserving the local capacitor-to-MCU wiring. One ordinary
through-via is added; native refill connects C12 ground.
PCB `834086079bc792165adcf642d41f3fd52c65446a355904934fcdf39b289227eb`,
manifest `054f203553f7051e12f098acac9683539488e77e4a42266439b48c519dbf39dd`.
**42 opens**, 233 warnings and 46 historical parity notices remain.
The protected In1 plane remains connected with the reviewed local
power-via antipad. No components moved; C24 remains unresolved.
See [acceptance and evidence reuse](reports/c12-paired-feed-acceptance.json).
Full electrical, thermal, mechanical and manufacturing qualification
remain open. Descriptions below are preserved historical checkpoints.

**Earlier acceptance: C23 ground closure.** Five local USBBOOT F segments
are replaced by two 0.20 mm In2 segments between existing vias, freeing
the front ground fill to connect C23. No parts moved or vias were added.
PCB `01a943c795ba97246c9681ad64088dfeb68ca94008cc9f08081d4c4f90789b00`,
manifest `d69d1ae6267eafe5976e528fd47d30cbed81ff01df058dbceca9d9c6cdc49b8c`.
**43 opens**, 233 warnings and 46 historical parity notices remain.
The In1 plane is unchanged; the five remote F comparison components pass
the reviewed native displacement and clearance bounds. The actual board
graph preserves prior connections and private pickoffs without shorts or
floating copper. C12 and C24 remain unresolved.
See [acceptance and evidence reuse](reports/c23-usbboot-acceptance.json).
This is not full electrical, thermal, mechanical or manufacturing approval.
Descriptions below are preserved historical checkpoints.

**Earlier September 22 radial acceptance:** the radial ground batch adds three
off-pad through-vias and short F stubs, joining C4, shared C11/C15 and U2.
PCB `7927882fa05f05411c6bf9e12782326f55572aa0b450cc2e26e9ea534ab3add7`,
manifest `a7a04cc74f0b487beda240c9b868dec54afbe32cd60fa003ec9e6578bc8717e7`.
**44 opens** and 233 warnings remain, with 46 historical parity notices.
Plane fills and prior copper are unchanged; local high-frequency, current,
thermal and manufacturing qualification remain open. C12, C23 and C24
remain unresolved within the finite screen.
See [radial-batch acceptance](reports/supply-ground-radial-acceptance.json).

**Earlier September 22 stitch acceptance:** an off-pad GND via and 0.65 mm F stub
at R4 connect the existing C9/R4/R8 group to main ground. The accepted PCB is
`453b9f6da227cc3ce4fe0a664e4d0e05d159a6cbe41b00c72d2b009e1c3ffe43`,
manifest `1bf38f7a9e6f9a1b086844a6309103f8935ecfcb8ef142bed7ccc0acc473ec2a`.
There are **47 opens**, 233 warnings and 46 historical parity notices.
F/In1 fill geometry is unchanged, all previous connected groups and private
pickoffs survive, and the remaining VCORE/ground connections are unfinished.
See [ground-stitch acceptance](reports/supply-ground-stitch-acceptance.json).
This is group-level connectivity, not C9 local high-frequency qualification.

**Earlier September 22 supply acceptance:** the +3V3 bridge adds three In2 segments
between existing vias, without changing placement, prior routes or plane
fills. PCB `5dc0ebe6b75a2325826460ece80d3f1b2cb45bc1af8341baa79358d85e3136d8`,
manifest `cdff8e0501a015039bc10c9b01a8f92dfde1a3edc2b7247914952d971073df41`.
There are **48 opens**, 233 warnings and 46 historical parity notices.
See the [bridge acceptance](reports/in2-3v3-bridge-acceptance.json).
Sixteen ground and two VCORE opens remain; this is not a powered-ready board.

**Earlier September 22 plane acceptance:** the first protected In1 ground plane is
promoted byte-for-byte from the saved candidate. The PCB is
`19d3bf9a1ab37dcc7af29f0cc99cc44a98564f878402beee15af3ce0a731ff78`;
manifest `ce915418d33442f6ab42b155f6a7bc95c05e6c7032574d58044963ca4d066741`.
There are **49 opens**, 233 warnings and 46 historical parity notices still
to disposition. All existing connected groups and both private returns are
preserved; component geometry and existing routing primitives are unchanged.
See [acceptance and exact evidence reuse](reports/in1-plane-acceptance.json).
Full CAD source binding, physical stackup and final engineering/manufacturing
qualification remain open. Earlier migration/staging descriptions below are
historical, not the current inner-copper state.

This package began as a **partial migration baseline**, not a routed four-layer
design, physical stackup qualification, fabrication release, or quotation
package. It was created from the exact accepted sibling
`../printed-bell-clock-draft` PCB
`a83cc417c96b05dd15c187e648b9fd2a35ba857c3a66f7d13aaaa42ae3bd9fff`.
That source package remains unchanged.
The repository pins this package's line endings with `-text` attributes so
its authoritative file hashes survive checkout on different platforms.
Inherited native/library formatting is intentionally preserved.

## Authorized logical layer reservation

- `F.Cu`: short critical routes and fitted parts.
- `In1.Cu`: reserved for a protected GND plane.
- `In2.Cu`: reserved for power and released lower-speed routing.
- `B.Cu`: battery contacts and constrained routes.

These are policy reservations only. No inner-layer plane, zone, trace, via,
or fill was added. Existing F/B copper, filled-zone caches, placement, nets,
pads, rules, outline, masks, paste, courtyards, zones, exclusions, and
through-via endpoints were not edited. Existing through vias now have native
`*.Cu` padstacks on all four enabled copper layers, so KiCad exposes inner
annuli; there is still no filled inner copper.

Nominal total board thickness remains 1.6 mm. Dielectric materials,
individual copper/dielectric thicknesses, impedance, and a
supplier-qualified physical stackup are pending.

The native KiCad 10.0.6 DRC result is
[`reports/four-layer-baseline-drc.json`](reports/four-layer-baseline-drc.json):
51 unconnected items, zero other errors, and 233 warnings, unchanged from the
accepted source counts. The compact migration evidence and tooling gate are in
[`reports/four-layer-baseline.json`](reports/four-layer-baseline.json).
The new invocation also enabled schematic parity and records 46 notices;
the historical comparison did not enable that check. These notices are
not covered by the unchanged geometry/error counts and require disposition
before release.

Historical source proofs remain in the source sibling and are not fresh
four-layer routing proof:

- `../printed-bell-clock-draft/reports/charge-led-routing.json`
- `../printed-bell-clock-draft/reports/charge-led-routing-drc.json`
- `../printed-bell-clock-draft/reports/charge-led-routing-ground-check.json`

The [saved-native graph control](reports/four-layer-graph-saved-native-control.json)
now exercises inner-layer short reporting, through-via annuli, exact filled
In1 connectivity and same-net In2 isolation. The failed earlier controls
remain historical evidence, not the current graph result.

Production plane topology, contact/private-return exclusions and engineering
acceptance are still required before adding copper. The old F/B routing
masks/search remain unqualified for inner routes. A native plane operation
using qualified graph checks does not require that unused search engine.

The [first staged production-plane result](reports/in1-plane-first-stage.json)
is rejected: a previously connected GND pad group split despite the native
open count decreasing to 50. No candidate copper is promoted into this
package. The saved candidate requires exact regression diagnosis and the
remaining per-layer acceptance gates before another engineering decision.

**September 21 end-of-day pause:** the subsequent
[explicit-settings replay](reports/in1-plane-settings-replay.json) preserves
the original connections and has 49 opens. Its
[supplementary review evidence](reports/in1-plane-review-supplement.json)
and [saved candidate archive](reports/staged-in1-settings-replay.zip) are
preserved separately; the top-level PCB/manifest are still the accepted
51-open migration baseline. The archive is not a quotation/fabrication
package and must not be extracted over this package. Root return-path review
and promotion remain unfinished. Resume only on explicit owner request.

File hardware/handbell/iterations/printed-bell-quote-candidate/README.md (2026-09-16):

# Printed-bell routing completion candidate

> **Historical recovery archive, committed September 16, 2026. Not the active
> candidate.** These files preserve the earlier interrupted routing work and
> its intermediate outputs; the historical status and hashes below are not
> current-board approval. Do not run its generators over the active package.
> Continue only after owner resume in
> [`printed-bell-clock-draft`](../printed-bell-clock-draft/README.md).
> The accepted board there has 51 opens at the pause. Existing hardware
> licenses and attribution notices in this archive remain in force.

**Development candidate, not a released quotation package or permission to
power, fabricate or order it.** This separate project continues the accepted
power rework toward the owner's full JLCPCB and PCBWay PCB+PCBA quotation
handoff. Current native connectivity, failures and residual nets are reported
in `reports/completion-review.json` and its Markdown companion; filenames or
an autorouter's completion message are not approval.

The immutable source is `printed-bell-power-rework`, PCB SHA-256
`6132f8d3ec508f8ae023888052cc2a1f8b2c24f2c38d9d12dca3234ba887dcc1`,
manifest SHA-256
`60e394c41bcfd7734b41c7713100360253164381f0217eed325386bd49977799`.
The parent's accepted mechanical model is
`2a923489d72297a27e0bd05760b09d3ed2e19513efced5a6510add9d7b53cb4b`;
that model approves neither the new local moves below nor later USB/part changes.
No old snapshot, source report folder or personal KiCad preferences are copied
or rewritten by the completion generator.

## Delivered bounded result

**Routing is not complete: 59 native unconnected items remain.** This milestone
reduces the source's 155 opens without a source-connected physical-pad-pair
regression. It contains 1,124 tracks, 87 through vias, one F-ground zone with
23 actual filled islands and ten pour-only private-reference exclusions.
Of 86 physical nets, 34 multi-pad nets are complete, 27 remain partial/unrouted,
and 25 are single-pad/NC nets. No B ground pour was added.

The compact cell-positive/Q3/Q1/boost feed, protector gate branches and all six
QSPI connections are real connected copper. The source's all-F output-capacitor
loops and terminal-cut-independent R26/R24 pickups remain intact.
The red F fill is **not a continuous ground return**: protected GND still has
23 disconnected pad islands, including separate MCU thermal/pin19 islands.
The board is non-operable; the MCU core rail, USB, I2S and other controls remain
incomplete. No Gerbers or quote-ready assembly ZIP has been generated.

| Authoritative candidate file | SHA-256 |
|---|---|
| `handbell.kicad_pcb` | `2d88301f48ad05dc01384b90111f16615f176a7f4704eab82a1e3560ef5c8bc0` |
| `placement-manifest.json` | `404a8c53dc0ce28f8769ec4a1926452564cbd3cd5f8c27d95b7ac2ebee1b55de` |
| `handbell.kicad_sch` | `e131a8d093795df7285bcae4a8886ffe01106c6513a19bd588ee7c29c6993b4f` |
| `battery-contact-interface.json` | `f96133d9f044600167477bcddbf67c43311ed0897066db9fa63d8e7f8118467b` |

KiCad 10.0.6 reports zero ERC findings and no new physical copper violations;
the four original USB-hole errors, 46 CLI parity findings and visible
silk/text warnings remain unresolved. Actual PDFs/SVGs, every open physical
pad UUID, exact local-pad proofs and native input bindings are in `reports`.
The seven rear labels remain readable from B, positive on the left and the
button arrow pointing left. Their full mechanical visibility needs rebind.

### Concrete remaining routing blockers

There are 22 required GND island joins and 37 other native joins. `VCORE`
has six islands: IC1.50, IC1.45, IC1.23, C18.2, C6.2 and the C8.1/C7.2 pair.
The regulator's +3V3 island is still separate from the large MCU/flash island;
VHI's C1/U2/R3 island and VBAT's charger/C20 island also remain separate.
USB D+/D-, the I2S triplet, reset/SWD, enable/control branches and the remaining
BTL paths must be completed. The JSON, not this abbreviated list, is exhaustive.

The current local floorplan needs another routing-led revision, not more
blind passes over rounded interchange files. The 0.8 mm USB-VHI passage uses
the MCU's east annulus: its outer edge is X2.7 while the perimeter lands start
at X3.0125. That 0.3125 mm gap cannot hold another 0.1778 mm track with 0.2 mm
clearance on both sides. The QSPI DATA3 detour also separates the VREG_OUT
escape from C6. Behind this area, the positive contact's inner land spans
X1.685..5.685, Y+/-2.54, and its conductive base continues outward over
Y+/-5.565. Foreign B vias/tracks cannot be used as an apparent easy crossover.
Reconsider the USB supply passage and local MCU/flash power fanout together;
do not preserve these particular tracks at the expense of core power/returns.
These are local routing constraints, not evidence that D43 or fixed interfaces
must change. No larger board or interface move is requested by this milestone.

`reports/additive-completion.json` records a bounded additional native-island
search after the local autorouter. It added 13 real island joins; unsuccessful
searches are not treated as proof of physical impossibility. Filled-copper
iteration now requires an explicit guarded new revision/refill, not stale pours.

`reports/power-path-measurements.md` gives actual selected copper walks.
The cell-positive, short VHI and switched-feed walks are approximately
11.6/2.24/7.06 mm, with nominal chosen-strip estimates of 12/2.0/3.1 mOhm.
Their sum is a **positive-side-only** screen, not round-trip resistance.
Very small inscribed-strip minima near annuli/junctions are analyzer walk
geometry, not claims that the PCB has 18 um drawn high-current tracks.
Filled-GND resistance and current redistribution are not modeled, so neither
the 50 mV cell nor 100 mV amplifier round-trip target is demonstrated.

## Physical scope

D43, two copper layers, F25/B26.6, all tabs/outline, M2 mounts, cell/contact/USB
datums and **81 front electronic parts plus two fitted rear SMT contacts**
remain fixed. All 325 physical pad identities/nets and full local pad
primitives/angles are retained. U1 depth remains 2.1 mm and U6 depth 1.55 mm;
L1 remains the full 5 mm proxy with nominal 0.7 mm yoke gap, and D3 remains
0.4 mm. Those are not a complete tolerance, thermal or part-qualification budget.

The additional root-pose changes are fully recorded in
`reports/footprint-movements.json`. Board-relative X,Y and native angles:

| Ref | Source X,Y,angle | New X,Y,angle | Purpose |
|---|---|---|---|
| Q1 | -18.872664,1.307474,0 | -6.4,8,90 | Colocate the switch with Q3/C26, avoiding a long 2 A perimeter detour |
| Q3 | -1.997257,-11.500683,90 | -2.5,7.45,0 | Shorten the cell-positive and VHI path; preserve the corrected custom drain land |
| U6 | -11.502673,7.349061,0 | -10.8,6.6,0 | Expose COUT beyond the Q5 source-via barrier without routing through NC copper |
| C30 | -11.596821,5.551993,0 | -8.9,7.1,270 | Face the adjacent U6 supply/VSS pins without blocking VM |
| R28 | -17.200715,6.750382,90 | -11.6,8.55,0 | Put the bias-only discharge resistor beside the controller rather than across source fanouts |
| R25 | -9.2,8.3,0 | -7.5,5.3,0 | Keep the filter beside its capacitor and clear the switched-power corridor |
| R7 | -2.998764,8.006721,90 | -3,10,0 | Clear Q3 while retaining the control resistor nearby |
| L0 | -5.000460,9.003011,90 | -2,-11.23,0 | Use the vacated selector envelope rather than obstructing compact power |
| U1 | 6.301448,-3.359246,90 | 6.301448,-3.159246,270 | Make all six QSPI signals planar on F despite the B contact lands |
| C10 | 5.294511,-6.217731,90 | 8.6,-2.2,0 | Keep bypass at the relocated flash VCC bank |
| R5 | 7.001181,-6.301464,90 | 6.901181,-6.701464,90 | Clear the CS path while retaining its pullup |
| R9 | 8.105371,0.242334,180 | 8.105371,0.642334,180 | Shift the USB series pair together, preserving spacing and values |
| R10 | 8.109565,-0.959133,180 | 8.109565,-0.559133,180 | Clear the rotated flash courtyard |

No component height, value, pin map or source library is changed. The full
mechanical model must be regenerated from the final exact manifest.

## Routing constraints

The direct all-F U5/C27/C28 positive and ground loops, independent R26-to-R27
and R24-to-C28 ground pickups, paired source escapes and thermal meshes remain
explicit routing constraints. Both raw contact lands and their conductive
base projections exclude foreign B copper and vias. BTL outputs are not GND.
All seven mirrored service/chemistry labels and their clear rectangles remain.

The former under-R27 common-return transition is replaced by a second
off-pad transition at (-16.6,+7.2), alongside (-16.6,+8.1). The short
R29 bias connection joins this local common return rather than its former
long perimeter detour. Parallel vias are not assumed to divide current equally
or constitute demonstrated ampacity.

The COUT connection uses an outside F gate escape and a bias-only B path
between the raw contact base and source bus. It is not a high-current return
corridor. U6 VSS returns to raw CELL_NEG, not protected GND. These connections
still require native checking after each copper revision.

The cell-positive feeder is 1.5 mm B copper, with two off-pad selector-entry
vias, 1.2 mm F landing copper and a bounded 0.6 mm drain escape. The short
VHI link has a bounded 0.3 mm selector escape and 1.0 mm body. The switched
Q1-to-C26 feed is 1.2 mm F copper. The positive feeder deliberately stays
clear of the separate USB-supply exit rather than taking a conflicting
shortest centerline.

The USB-fed VHI branch uses 0.8 mm copper and an F passage **outside** the
unchanged 3.2 mm MCU thermal land. Its off-pad transitions include two
under-package annular locations; assembly/mask treatment remains a process
gate, not a filled/capped-via mandate. This is a supply branch, not a shared
high-current return through the B contact gap. All six QSPI signals are
explicitly routed on F; their lengths and the new return environment need
timing/EMI review, not an assumed high-speed approval.

The local autorouter preserves locked power/local-loop/quiet/source-fanout
copper but may reroute other signal copper. Ground completion is deferred
to the explicit native F fill rather than arbitrary signal-width returns.
Native pad/island/clearance results, actual necks and load-path
measurements take precedence over route-group names and requested widths.
No continuous ground plane or thermal qualification is implied.

Keep the provisional 2 A cell / 3 A sensitivity, 1 A at 5 V, 35 um nominal
foil and 30 um/60 C resistance sensitivity. The 50/100 mV copper-only
round-trip targets are analysis cases, not current ratings. Contacts, FETs,
33 mOhm shunt, inductor losses and IC internals are additional. A selected
strip walk is not equivalent resistance of a branched/filled plane. No
temperature-rise, fault-SOA or safe live-cell result is claimed.

## Reproducible local tools

`route.py` uses an explicit authoritative source list and only used local
footprint libraries. `completion-build.json` protects native inputs against
accidental overwrite. It does not fingerprint ignored PRL files, locks,
caches, an ambient report directory or downstream mechanical artifacts.
Read-only geometry/search helpers are reused without old writer invocation
or module-global monkey-patching.

The generation pipeline below is for an **empty separate candidate package**
at the same iteration-directory depth, initially containing only these local
tools. Edited protected inputs, an existing SES/completion receipt and an
already filled PCB are refused. Do not delete guard receipts to overwrite
the delivered candidate:

```powershell
python .\route.py power
python .\route.py export-dsn
python .\run_local_router.py --java <path-to-java.exe> --jar <path-to-freerouting-1.9.0.jar> --passes 8
python .\route.py import-ses
python .\complete.py --apply
python .\check.py --run-native
python .\fill_ground.py --apply
python .\check.py --run-native
```

For the delivered candidate, rerun only the evidence commands:

```powershell
python .\check.py --run-native
python -B .\measure.py --pcb-sha256 (Get-FileHash .\handbell.kicad_pcb -Algorithm SHA256).Hash
```

Checker exit 2 is the expected honest incomplete/blocked result, not an
invitation to remove its gates. The actual saved native file is authoritative;
external routing and native airwire endpoint selection need not be byte-identical
between runs. Every regenerated result must carry its own exact bindings.

Specctra SES omits fixed wires. The exporter records their **native UUIDs**;
the importer reinstates exactly those original native items, rather than
guessing from rounded DSN coordinates. Re-exporting a rounded routed result
caused Freerouting normalization failures; use the exact generated power seed
for reproducible routing attempts, not accumulating interchange round trips.
The importer verifies the SES against the local-run receipt and removes only
redundant same-net segment centerlines contained in restored fixed copper.
Native endpoint/regression checks still own acceptance.

Freerouting 1.9.0 is an external GPL-licensed local tool, not redistributed
inside this project. Its pinned release JAR SHA-256 is
`9084a4888937a7f31f857ecc12aa7a37407f51160e4d2892dff9c9bb47ae3102`.
Download: https://github.com/freerouting/freerouting/releases/tag/v1.9.0 .
The exercised portable runtime is Temurin 17.0.20.1+1, Windows x64 JRE;
the publisher ZIP checksum is
`bc21a93923103cdaac93ee337b0ae4365e739fde36df823dd456bc67c8a9d352`.
Runtime binary/input/output hashes are recorded by `run_local_router.py`.

Analytics is disabled (`-da`), and process-local HTTP(S) proxies point to
loopback port 9. The resulting blocked version-query exception is visible in
the log; no design is uploaded to a remote routing API or vendor. Each
interchange input is tied to its exact native seed and manifest. An existing
SES output is refused rather than silently overwritten.

Native exports use KiCad 10.0.6 and an isolated default configuration. DRC
stalled with shared runtime configuration on both the accepted source and
candidate; the isolated configuration completes without changing board rules.
The installed standard `power.kicad_sym` dependency is explicitly registered
and hashed with the native tool identity. Custom project libraries remain
package-local exact copies. Logs record executable names, not home paths.

After signal routing, `fill_ground.py --apply` is a guarded one-shot F-only
ground fill. It preserves existing footprints/tracks/vias and protects the
private references with pour-only exclusions. The zone-aware checker uses
actual filled islands and holes, never a zone's unfilled outline. No B fill
or new vias are introduced. Solid ground attachment is an explicit assembly
heat-demand tradeoff, not soldering or thermal qualification.
The linked-hole boundaries are used exactly as saved by KiCad, without
integer-coordinate unfracturing/normalization. Repeated native DRC runs may
choose different representative airwire pairs; actual pad-island partitions,
unconnected counts and physical findings must still agree.

`measure.py --pcb-sha256 <hash>` measures actual nonground copper walks,
overlap-aware necks and conditional barrel drops. With the F fill present,
GND connectivity is checked but its resistance/neck distribution is explicitly
not modeled; whole-loop drop targets cannot be closed by a track-only estimate.

The checker emits fresh ERC/DRC/netlist and front/rear PDF/SVG outputs,
and rejects stale cached inputs or results. Exit 1 indicates failed/stale
checks; exit 2 indicates an incomplete or otherwise blocked candidate.
Only the declared native F-ground fill and its pour-only exclusions are supported.

## Still-required quotation and qualification work

X6 is untouched pending the parent's drawing/mapping correction. Its four
round anchor drills do not reproduce the EAGLE slots, and its four inherited
NPTH-to-copper clearances remain unwaived. Neither the nominal old USB
interface nor an autorouter run approves a replacement land pattern.

The L1/C26-C28/FB1-FB2 manufacturer study, USB review and other sourcing
sidecars are owned separately. Current values/family names do not freeze
orderable parts, dimensions, bias/ripple performance or process capability.
Any resulting footprint/body changes require explicit integration, rerouting
and exact mechanical rebind before final quotation exports.

No Gerber/drill quotation ZIP or supplier BOM/CPL is produced while connections,
parts and manufacturing inputs remain unresolved. Full PCBA must include both
rear contacts, with actual pickup/rotation and assembly process reviewed.
Quote readiness is separate from production, enclosed thermal, charging,
reversal, retention and child-use qualification. No supplier upload, quote
request on the owner's behalf, purchase or order is authorized.

Adapted hardware remains CC BY-SA 3.0 with the exact copied `LICENSE.txt` and
Adafruit notices. Root MIT does not relicense it. Original completion tools
and prose use MIT; external manufacturer documents and routing binaries are
not redistributed here. Parent owns publication and E04/#4, E05/#5, E07/#7
and E08/#8 coordination.

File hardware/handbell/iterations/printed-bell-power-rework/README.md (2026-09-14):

# Printed bell: critical power-rework milestone

**Non-operable partial routing, not fabrication, current, charging, thermal or
physical-fit approval. Do not power this board.** This separate KiCad 10.0.6
project addresses the two required corrections in the parent's
[independent review](../printed-bell-routing/reports/power-routing-review.md).
It does not overwrite either published electrical checkpoint.

This is an intermediate milestone toward the owner's
[JLCPCB and PCBWay full PCB+PCBA quotation handoff](../../../../docs/pcba-quotation-plan.md),
not the final deliverable. Complete remaining routing, sourced BOM and
manufacturing inputs, then bind the final mechanical model before generating
matched Gerber/drill, supplier-specific BOM/CPL and assembly/process assets.
Both fitted B SMT contacts must remain in the assembly population and cost
scope. Parent coordinates those next stages; this package contains no
quote-ready exports. Open nets and unresolved part/process choices must not
be concealed in a quote ZIP. Quote readiness is separate from production or
live-cell qualification; no vendor upload, order or purchase is authorized.

There are **674 tracks, 35 through vias, no zones, 12 complete multi-pad nets
and 11 partial nets**. All 325 physical pad identities, nets, complete local
pad primitives/angles and libraries remain intact. Native connectivity proves
64 declared endpoint pairs. Unconnected items are **155 versus 148**, with
163 previously connected physical-pad pairs lost; those losses are itemized,
not hidden behind the new power connections.

## Reviewable native evidence

| Artifact | What it contains |
|---|---|
| [Native project](handbell.kicad_pro) / [PCB](handbell.kicad_pcb) / [schematic](handbell.kicad_sch) | Actual two-layer candidate and unchanged circuit |
| [Front PDF](reports/front-native.pdf) / [rear PDF](reports/rear-native.pdf) | Actual native copper and readable rear chemistry/polarity labels |
| [Front SVG](reports/front-native.svg) / [rear SVG](reports/rear-native.svg) | Native vector views |
| [Boost before F](reports/boost-before-front-detail.svg) / [after F](reports/boost-after-front-detail.svg) | Matched-coordinate copper/silk details without the cluttered fabrication-value layer |
| [Boost before B](reports/boost-before-back-detail.svg) / [after B](reports/boost-after-back-detail.svg) | Through-board, non-mirrored companion details |
| [Native review](reports/routing-review.md) / [complete JSON](reports/routing-review.json) | ERC/DRC, actual pad islands, terminal-cut proofs, regressions and final hashes |
| [Power measurements](reports/power-path-measurements.md) / [complete JSON](reports/power-path-measurements.json) | Copper-aware walks, uncovered necks, provisional drop cases and limitations |
| [Pose changes](reports/footprint-movements.json) / [manifest](placement-manifest.json) | Exact transforms/rationales and new mechanical input |
| [Proxy enlargements](reports/proxy-envelope-adjustments.json) | Separate authorized U1/U6 maximum-depth corrections, local-to-board axes and manufacturer evidence |
| [Build binding](routing-build.json) / [native bindings](reports/native-input-bindings.json) | Source/tool/native bytes, commands, original-source guards and report hashes |

## Required corrections implemented

**Boost:** L1 is now behind U5. SW runs underneath the SOT563, not across
the capacitor-facing side. C27/C28 face U5 VOUT and GND; both positive and
ground connections are direct F-side copper, with 0.8 mm buses and bounded
0.30 mm pad exits. Neither local output-capacitor loop requires a via.
The separate load return takes off outside these local loops.

The same sampled native-copper walk method, including pad travel, gives:

| Capacitor loop | Old paired XY / transitions | New paired XY / transitions |
|---|---:|---:|
| C27 | 7.99 mm / 2 | 4.46 mm / 0 |
| C28 | 12.2 mm / 2 | 8.63 mm / 0 |

The simple planar walk areas are approximately 2.81 and 6.56 mm2, respectively.
These are geometric comparisons, not parasitic-inductance or stability results.
They intentionally differ from the earlier review's pad-as-region distances.

**Protector pickup:** R26.2 has a single approximately 1.691 mm direct F
pickoff to R27.2, replacing the former 13.245 mm drawn sense route through
shared returns. Removing only copper joins inside the actual R27.2 land leaves
the sense branch isolated from every other ground pad. Load returns enter
R27.2 from the right; the sense branch enters from below. U6.VSS is deliberately
connected to raw CELL_NEG, never protected GND.

**Feedback:** R23/R24 moved with the boost. R24 has its own reserved reference
to C28's ground land. A separate native terminal-cut check shows no load joins
before that land. The approximately 11.9 mm, two-transition reference is a
quiet-topology improvement, **not a short trace or demonstrated noise immunity**.
FB remains a partial net because the DNP C29 branch is not completed.

**Amplifier and returns:** both U4 supply pins are joined, C16/C19 positive and
ground bypass branches are connected, and a paired 5 V supply/return reaches
the boost bank. The three exposed thermal-pad-to-ground-pin gaps use 0.30 mm
orthogonal exits, approximately 0.35 mm exposed each. Local bypass returns
use off-pad transitions outside the raw-contact base areas, connecting to the
retained thermal mesh rather than an invented continuous ground plane.

The original four outside Q5 source escapes remain. An additional common
PROT_FET_RETURN transition at **(-16.6,+8.1)** is outside SMD lands and joins
R27.1 through a parallel branch. The old under-R27 transition remains too.
This provides parallel copper, not equal current sharing or qualified via
ampacity. Gate pads between source balls are not bridged.

## Exact authorized pose changes

Coordinates are board-relative X,Y in mm followed by the native KiCad angle.
Only root footprint poses change; all local pad geometry/angles stay exact.

| Ref | Previous X,Y,angle | New X,Y,angle | Reason |
|---|---|---|---|
| U5 | -4.198999,16.001796,0 | -2.7,15.2,0 | Face output bank; SW exits underneath toward L1 |
| L1 | 0.478653,15.758568,180 | -7,14.8,0 | Behind converter, outside magnet; full 5 mm height |
| C26 | -4.442651,18.407437,0 | -9.5,10.9,180 | V+ faces inductor input, GND faces protected return |
| C27 | -7.265563,15.705807,270 | 0.1,15.2,270 | Direct all-F first output loop |
| C28 | -9.383487,15.802423,270 | 2.2,15.2,270 | Parallel output bank |
| C29 | -6.603258,12.098491,0 | -5.7,11,0 | Keep DNP reservation clear of moved L1; still DNP |
| R23 | -4.199078,13.802444,180 | -1.8,12.7,180 | Local FB divider/output pickup |
| R24 | -4.197681,12.592618,0 | -2.1,11.4,0 | Separate quiet capacitor-ground reference |
| R25 | -11.599531,9.349843,0 | -9.2,8.3,0 | Remove bias resistor from R27 load-return approach |
| R26 | -14.602592,5.549142,0 | -13.6,11.7,90 | Independent nearby shunt pickup with courtyard clearance |

All unrelated footprints are byte-identical. No circuit/value, USB, contact,
mount, outline, copper-layer count or B electronic-population change is made.

### Authorized maximum body-depth corrections

The September 14 parent BOM-audit follow-up authorizes these two additional
**proxy-only enlargements**, applied in the new manifest after pose transforms:

| Ref | Local width x depth, old -> new (mm) | Manifest rotation | Board-axis expansion |
|---|---|---:|---|
| U1 | 3.1 x 2.0 -> 3.1 x 2.1 | -90 degrees | X, 0.05 mm each edge |
| U6 | 1.9 x 1.5 -> 1.9 x 1.55 | 0 degrees | Y, 0.025 mm each edge |

Winbond UX E=2.0 +/-0.1 mm and TI DSE0006A 4220552/B's 1.55 mm maximum
support these depths; the other local axes already have larger envelopes.
Previously inspected manufacturer-document revisions and hashes are carried
forward in the separate proxy report, not represented as new measurements.
Centres, native poses, heights, pads, nets and libraries are unchanged by
these corrections. The old nominal-depth clearance does **not** cover the
component tolerance. Fresh envelope screening and the parent's exact final
mechanical rebind are required; this is not a complete assembly-tolerance budget.

The preserved draft BOM still has 15/83 fitted rows with an MPN field and
68 blank fields, some with recoverable identities. It is not a sourced turnkey
BOM. L1's 1 uH/TDK_VLC5045 family, the three 22 uF/0805 C26-C28 entries and
generic FB1/FB2 do not freeze orderable parts. Parent-coordinated selection
studies and X6/USB research are separate; X6 remains unchanged here. Any later
part requiring different lands or body geometry needs explicit coordinated
revision before the full quotation handoff.

## Widths, exposed necks and provisional power budgets

The actual input-inductor feed is 1.2 mm; its copper-aware walk is about
3.90 mm. The bias-only C26-to-U5.VIN spur is approximately 8.95 mm at minimum
signal width and **does not carry full inductor current**. Cell-positive body
uses 1.2 mm, VHI uses 1.0 mm with genuine package exits, and raw-negative
body uses 1.0 mm into the existing outside source bus. Boost load return uses
1.2 mm B copper in the upper bank and 0.8 mm F takeoff/terminal connections.
The amplifier distribution bodies use 1.0 mm.

The SW connection has a **0.20 mm under-package section** feeding a 1.2 mm
body. The approximately 0.62 mm space between opposite SOT563 lands cannot
hold a broad trunk plus two unchanged 0.20 mm clearances. The complete narrow
SW inventory is 2.135 mm drawn and **1.21 mm uncovered after pad/broad-copper
coverage**, including the continuation beyond the directly pad-adjacent
segment. Its isolated full-width nominal resistance is about 2.97 mOhm.
This exposed segment is longer than the old review's approximately 0.65 mm:
the corrected topology is not advertised as an improvement of every neck.

Each 0.30 mm output-pin exit is 0.815 mm drawn but only approximately
0.09 mm uncovered after pad/broad-copper overlap. Do not treat the entire
drawn exit as an isolated series bottleneck. The four original Q5 source
escapes are approximately 0.704/0.772 mm each; their pad/annulus overlaps are
reported separately. The broader Q5 pad-adjacent inventory also contains
bias branches and must not all receive a 2 A assignment.

Use the review's **provisional** 2 A cell / 3 A sensitivity, 1 A at 5 V,
35 um nominal foil, and 1.35x 30 um/60 C resistance sensitivity. The unqualified
1 uH/1 MHz, 2.8-to-5 V example is about 1.23 App and 2.6 A peak at 2 A mean.
Neither 60 C nor a <=10 C conductor-rise target is an established operating
limit or measured thermal result.

The selected native-copper walks give approximately:

| Copper-only screen | Nominal / 1.35x drop | Interpretation |
|---|---:|---|
| Cell round trip, <=50 mV at 2 A | Not computed | Q1.3-to-L1 input remains open; target not demonstrated |
| 5 V bulk-capacitor endpoints, 1 A | 42 /56 mV | Numerically below 100 mV for this selected walk only |
| Amplifier supply pin to thermal return, 1 A | 68-69 /92-93 mV | Numerically below 100 mV for these selected walks only |
| Amplifier supply pin to small GND11 return, 1 A | 75-76 /102-103 mV | Sensitivity case exceeds 100 mV for this selected walk |

The analyzer uses finite native-shape contact portals and conservative
inscribed strips, not a least-resistance path or 2-D current solution. Junction
geometry can overstate those strip estimates. Neither a numerical pass nor an
exceedance proves the actual parallel network's equivalent drop. **Neither
whole-system copper budget is declared qualified or closed.**
Contacts, Q3/Q1/Q5, the deliberate 33 mOhm shunt, inductor winding, IC internals
and capacitor ESR are additional and excluded. The shunt alone is nominally
66/99 mV at 2/3 A. Conditional 0.30 mm barrel DCR is about 1.17 mOhm only if
1.6 mm board/25 um wall assumptions hold; plating is not selected.

## Native result and remaining work

ERC is zero. The four original USB hole-clearance findings and 46 CLI parity
findings remain, without rule changes or waivers. There are no new shorts,
copper clearance, mask-bridge, courtyard or dangling-copper findings.
All seven original B labels are unchanged and clear of candidate B copper;
foreign-net B tracks/vias avoid both raw contact lands and conductive base
projections. GND does not use the narrow central B gap as a shared power return.

The **V+ feed from Q1.3 (-18.872664,+0.307474) to C26.1 (-8.55,+10.9) remains
open** after the 1.2 mm body/limited escape search. COUT to Q5 and the R28 DOUT
discharge-gate branch remain open. Broader signal/enable/charger/BTL completion
is still needed. QSPI DATA0/DATA1, VCORE branches and multiple shared GND
branches from the old attempt were displaced or omitted. Native before/after
islands and every regressed pad pair are in the report.
Bounded search failure is not proof that an unapproved Q1 move or larger PCB
is necessary; neither has been applied or claimed necessary.

Thirteen retained thermal-pad vias, the inherited under-R27 transition, new
off-pad transitions and stencil/paste behavior require process/DFM review.
Filled/capped vias are **not mandated** without that review, nor are ordinary
open vias declared qualified. No pours or proven heat spreader are provided.
Inductor saturation/ripple/current, FET/fault SOA, charging profile,
temperature inhibit, reversal/primary-cell misuse, insulation and physical
retention remain unclosed. Labels do not detect chemistry or prevent reversal.

## Mechanical contract and reproduction

D43, F25/B26.6, original tabs/tongue, both M2 holes (+10,+15.7) and
(-10,-15.7), USB origin (0,-22.82)/mouth (0,-27.90), all battery-contact
geometry, nominal cell axis/center and **81F electronics +2B SMT contacts**
are unchanged. L1 remains 5 mm high with nominal z20 bottom and the original
0.7 mm yoke gap. The moved proxies have no overlap or outline/speaker-envelope
violation in the electrical screen; this is **not actual mechanical fit**.
The parent has now regenerated the complete corrected CAD using this exact
manifest: native SHA-256
`2a923489d72297a27e0bd05760b09d3ed2e19513efced5a6510add9d7b53cb4b`,
with no nominal material overlaps and refreshed views. See the
[current complete assembly](../../../../mechanical/studies/2026-09-13-printed-bell/README.md)
and [actual-label service evidence](reports/service-label-current-mechanical-review.json).
The producer's conservative manifest flags do not self-approve fit; the
separate exact consumer evidence records this completed intermediate bind.
Future routing, sourced-part and USB-footprint changes require their own bind.

From repository root, with existing Python/numpy and KiCad 10.0.6:

```powershell
python .\tools\route_printed_bell_power_rework.py
python .\tools\check_printed_bell_power_rework.py --run-native
$pcb = '.\hardware\handbell\iterations\printed-bell-power-rework\handbell.kicad_pcb'
python -B .\tools\analyze_printed_bell_power_paths.py --pcb-sha256 (Get-FileHash $pcb -Algorithm SHA256).Hash
python .\tools\check_printed_bell_power_rework.py
```

The generator refuses edited candidate/native dependencies. It reuses only
the old router's in-memory geometry/search engine and unchanged contact data;
it never monkey-patches module globals or runs the old writer/checker against
the new package. Native-reported sub0.01 mm grid overruns alone may be removed,
with fresh endpoint/native confirmation; larger dead ends fail for repair.
Source fingerprints exclude local `.kicad_prl` preferences, just as they
exclude locks/backups/bytecode. The checker consumes the same source-file set
as the writer; a clean checkout must not require an ignored personal-state file.
Native command records use the executable name, with its actual version and
binary SHA-256 recorded separately, rather than publishing a user-home path.
The shared S-expression parser and source attribute file also retain their
existing working bytes in Git, rather than depending on checkout-time newline
conversion. That publication-only line-ending correction changes no parser
logic or source PCB geometry.

**After each exact mechanical rebind**, run:

```powershell
python .\hardware\handbell\iterations\printed-bell-power-rework\screen_current_mechanical.py
```

This checks all four embedded electrical inputs against this package, then
checks the new copper/labels and actual current-model sight columns. It
refuses the still-stage1-bound f0dae8 model. The separate resulting report is
not an input to the mechanical build, avoiding a circular artifact dependency.

## Source and license boundaries

The source electrical checkpoint was published at
`b63a121b1ca990a64b00f231a85dd715126319af`; source service tooling was refreshed
at `222ddb816c882da5aee476a0d873a4490caf8ce3`. The parent's review is recorded
at `eb9041a6c0d4cd5b43adfb33383449f4a8ada6fc`. All source bindings are preserved.

TI's [SLVAES4](https://www.ti.com/lit/an/slvaes4/slvaes4.pdf), May 2020,
pp3-5, distinguishes wide local output loops from bottom-return/wrong-side-SW
mistakes and explicitly recommends routing SW under the device. Inspected PDF
SHA-256: `d0046c0259fc5b840fb89fdca1837b2f398a7da11e8f73b3a9748972de0fefcc`.
Also retain the review's [TPS61023 section 10.1](https://www.ti.com/lit/ds/symlink/tps61023.pdf)
and [MAX98357 Rev.7 p33](https://cdn-shop.adafruit.com/product-files/3006/MAX98357A-MAX98357B.pdf)
references. These are manufacturer guidance, not project measurements.
Manufacturer PDFs/images are not redistributed.

Adapted hardware remains **CC BY-SA 3.0**, not root MIT. Complete source
libraries, `LICENSE.txt`, original notices and source-evidence records are
copied unchanged. Credit Limor Fried/Ladyada for Adafruit Industries for
5768/4654 and Bryan Siepert for Adafruit Industries for 4438. Standard KiCad
library exceptions do not relicense that hardware. Original tools and prose
use MIT. No vendor endorsement or selected power-component qualification is
implied. Owning epics remain E04/#4, E05/#5 and E07/#7; parent owns publication.

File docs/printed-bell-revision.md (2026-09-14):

# Printed bell and front-face electronics revision

**September 13 owner-authorized engineering work.** The successful T8 fit
assembly at `fefa8bce4e02f1c6c216f7053fb5d7abb16f3d44` remains preserved.
The [dated design inputs](design-inputs/2026-09-13-printed-bell.json) distinguish
owner requests, working CAD selections and unclosed qualification gates.

## Approved direction

Use a single-piece, original printed bell shell around a removable cartridge
with a flush or recessed grille. Retain the successful speaker/yoke/PCB/cell
interfaces where practical. A separate black printed handle is the first
implementation, with a common attachment concept for a later wooden handle.
Do not include a broad handguard disk.

The supplied photographs guide only the generic flared handbell character.
They are not dimensional evidence, traced profiles or licensed assets for
redistribution. Neither image nor its artwork is imported into this project.

The owner is interested in ERYONE silk PLA and is willing to trade print time
for fine layers and exterior finish. Material processing guidance must retain
its source and scope; appearance is not structural or thermal qualification.
The [material and handle source notes](printed-bell-material-and-handle.md)
record the manufacturer's actual ranges, TDS limitations and working M4
fastener dimensions.

## Shared mechanical/electrical interface

The new z0 is the external grille/mouth plane. Initially keep the existing
speaker-relative stack: speaker front z4.5, magnet rear z23.5, PCB F z25.0
and PCB B z26.6. The cell centre remains z36.38, reflecting the nominal
9.78 mm contact datum above B. Removing the old cradle floor alone does not
change the metal contact's working height.

Try the 43 mm PCB first and retain the two existing M2 mounting holes.
Any enlargement must be supported by a coherent electrical floorplan and
reported against the original maximum outer envelope. The custom shell is
not a reason to make every part larger.

Consolidate the electronic SMT population on the speaker-facing side where
possible. The two B-side Keystone SMT contacts remain fitted components and
assembly work; this must not be advertised as a single-side reflow BOM without
an explicit contact-attachment process.

This is an assembly-flexibility improvement, not a guaranteed JLCPCB Economic
qualification. The [September 9 supplier review](electromechanical-wing-iteration.md#assembly-cost-is-a-decision-gate-not-a-reason-to-stop-drafting)
found an explicit Standard-only listing for the selected LSM6DSOX, independent
of placement face. Obtain a current whole-BOM/process determination rather
than silently deleting rear contacts from the master BOM or asking a novice
to fit the fine-pitch IMU. Compare factory-complete assembly with an explicitly
quoted secondary contact-attachment process. Two copper layers remain a
separate decision from one-face electronic SMT population.

A central M4 machine screw, broad washer and captive metal nut is the working
printed-handle selection. It is similar in size class to an 8-32 screw but not
thread-compatible. Use a keyed locating shoulder and a shell load path clear
of the battery. A wood-screw option is not qualified by a printed nut pocket.

## Completion sequence

1. Produce a separate native front-electronics placement and exact interface.
2. Bind a new FreeCAD shell, cartridge and handle to that interface, including
   both installed and service/plug paths.
3. Once those interfaces are stable, begin justified critical PCB routing.
   Preserve any unresolved native findings and electrical limits.
4. Publish native models, original rendered views, inert print files, a
   reproducible handoff and linked epic updates.

Final placement and routing status, dimensions, screw engagement and measured
or modeled findings will be recorded below when available. No fabrication,
live-cell or child-use approval follows from this engineering iteration.

## Delivered electrical stage 1

The [separate native placement](../hardware/handbell/iterations/printed-bell-front/README.md)
retains the **43 mm main PCB body**, its exact contact tabs/USB tongue, original
two M2 mounting holes and the initial USB datum. It now has **81 fitted
electronic parts on F and only two battery contacts on B**, with the unchanged
83-part T8 circuit and all 325 physical pad records preserved.

The RP2040 supply/crystal/flash, boost, amplifier and protection groups are
electrically floorplanned rather than merely repacked by body area. The native
package records actual pad distances, source guidance and remaining copper
layout requirements. Its fixed interface has been handed to the mechanical
consumer. The stage-1 manifest SHA-256 is:

`710717186d5ecc795edaf3da7eec8f6532f34077906645a8fca32318320f23c4`

Stage 1 is deliberately **unrouted**. ERC is zero; the four original USB
hole-clearance findings remain alongside unfinished silkscreen/text and
unconnected-net findings. No inherited GUI parity approval is transferred.
Routing waits for the complete mechanical interface review, not merely this
placement result.

## Printed shell, cartridge and handle

The [complete mechanical package](../mechanical/studies/2026-09-13-printed-bell/README.md)
now contains the actual all-front placement, an original one-piece bell,
flush removable grille/cartridge, retained battery capture and separate keyed
black handle. The PCB-related interface review supports beginning critical
routing. The initial release evidence is preserved in commit
`6e7ef9ef4dd1f6611695e73227630fdc5c8dae7a`; subsequent exterior refinements
do not move the board, its mounting holes, USB or contacts.

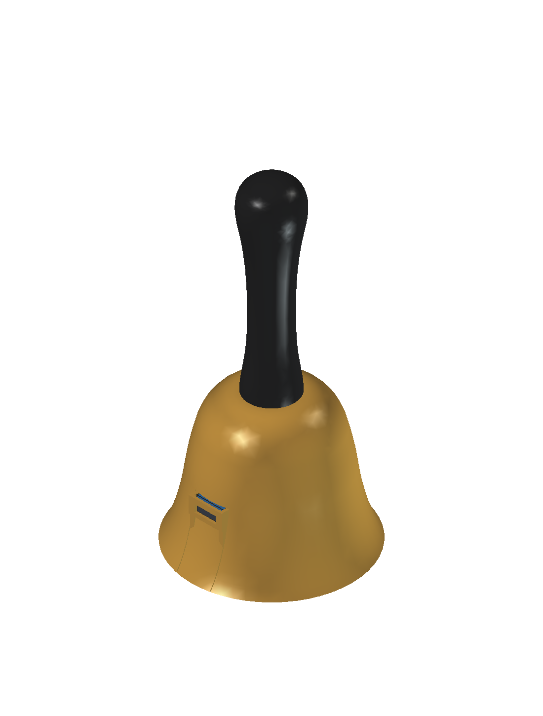
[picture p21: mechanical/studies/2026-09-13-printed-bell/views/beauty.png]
Original printed-bell CAD exterior


[Profile](../mechanical/studies/2026-09-13-printed-bell/views/profile.png) |
[Flush grille](../mechanical/studies/2026-09-13-printed-bell/views/grille.png) |
[Display-only cutaway](../mechanical/studies/2026-09-13-printed-bell/views/cutaway.png)

These are original CAD views, not photos or a prediction of silk-PLA finish.
The cutaway removes material only in extra view objects; every source solid
and the released full native remain intact.

| Interface | Current authored dimension |
|---|---|
| Maximum body diameter | 70 mm, versus the prior 75.5 mm flange |
| Body height / handle above crown | 55.8 / 80 mm |
| Complete height | 135.8 mm, versus the prior complete 141.8 mm envelope |
| Grille projection | 0 mm; face is flush with the mouth |
| PCB / original M2 mounts | D43 x1.6; (+10,+15.7), (-10,-15.7), drill2.2 |
| Handle hardware | M4x16 pan-head machine screw, large washer and captive metal M4 nut |
| Cartridge attachment | Three recessed front M2x8 screws and internal captive nuts |
| Retained internal joints | Six M2x6 screws and nuts |

The selected M4x16 is a compact metric alternative to the suggested 8-32
class, not an interchangeable thread. The keyed shoulder carries orientation
and lateral location; the recessed washer/screw/nut load path bypasses the
cell and PCB. The actual supplier-bound head/washer extremes retain 2.370 mm
to the cell and 1.133 mm to the cover. M4x20 is too long for the current blind
bore. None of this establishes printed strength or permitted torque.

Parent visual review caught two omissions in the initial static-clearance
result. The three shell nuts/pockets now sit inside the cosmetic surface
with a witnessed minimum 1 mm exterior wall rather than exposed side holes.
The USB bezel now has a real 1 mm front skin and upper lip, with a
9.2 x3.1 mm front nose aperture instead of relying on a larger loading cut.
The mouth-open shell channel remains necessary for straight withdrawal and
is filled by the matching cartridge bezel; assembly seams remain visible.
The unselected cable-nose screen is not actual mating-depth or overmold
qualification.

The floor and contact datum are retained: removing the nominal 1.08 mm
under-cell insulation would not by itself lower the selected contact's
9.78 mm cell-centre datum. Polarity/chemistry guidance belongs on visible
PCB/compartment surfaces, not only beneath the installed cell. A plastic
outer shell still does not prevent a raw-positive contact shorting the
negative cell can or bypassing the low-side protector.

### Viewing and inert print files

Open `mechanical\studies\2026-09-13-printed-bell\printed-bell.FCStd`.
The exercised portable view macro produces the four images above, binds
their hashes to the actual model and leaves a separate ignored local view copy:

```powershell
& "$env:LOCALAPPDATA\Programs\FreeCAD 1.1\bin\FreeCAD.exe" .\tools\view_printed_bell.FCMacro
```

Its FreeCAD 1.1.3 GUI run preserves the source model. The assembly can be
rotated with the shell transparent; the reference photographs are not loaded
or redistributed by this tool.

The study root has six structural prints: `INERT-shell.stl`,
`INERT-black-handle.stl`, `INERT-flush-carrier.stl`, `INERT-yoke.stl`,
`INERT-cell-cradle.stl` and `INERT-cell-cover.stl`. The other three are
`INERT-pcba-without-contacts.stl`, `INERT-full-cell.stl` and
`INERT-speaker.stl`. Use the root, **not** the mixed-face `development`
checkpoint. The PCBA dummy still omits the thin contacts only; full native
and STEP retain them.

Import millimetres at 100%, arrange separate parts and review supports.
Shell mouth-down/handle-up and grille face-down protect the visible faces;
internal crown/nut-pocket supports and the handle tunnel need actual slicer
review. The [silk-PLA starting settings](printed-bell-material-and-handle.md)
are sourced/proposed guidance, not an exercised printer job.

## First routed checkpoint and high-current review

The [separate partial-routing project](../hardware/handbell/iterations/printed-bell-routing/README.md)
now has actual copper: **921 segments, 38 vias, no zones**, 59 connected
requested endpoint pairs, 14 complete multi-pad nets and nine partial nets.
Native unconnected items decreased from 222 to 148. The published stage-1
placement is preserved, and all footprint poses, local pad geometry, original
mounts, USB and contact interfaces remain unchanged.

This does **not** make the board operable or fabrication-ready. Feedback,
returns, power/control/contact connections and signal-route optimization
remain unfinished. The candidate records real routed lengths rather than
mistaking the shorter placement distances for completed traces.

Rear-facing polarity and rechargeable-chemistry instructions are now actual
silkscreen, not a diagram overlay. Their glyphs and service-view visibility
were checked against the corrected capture with the cartridge outside the
shell and cover removed. Physical legibility remains unqualified; the charger
cannot identify a primary cell or prevent reversal merely because labels exist.

The owner specifically requests extra care with high-current routes. The
[completed independent review](../hardware/handbell/iterations/printed-bell-routing/reports/power-routing-review.md)
covers actual load versus sense/gate branches, widths and neck lengths,
vias, boost/amp hot loops, return continuity and voltage drop. It requires
reworking the boost's F-B-F output-capacitor loop and separating the R26
protector-sense pickoff from shared load-return copper. Local boost/sense
placement changes are authorized in a separate candidate, preserving the
old packages and all PCB mount/USB/contact interfaces; their new mechanical
fit must be established rather than inherited from the old placement.
The existing 35 um copper/current examples are explicit planning assumptions,
not a selected manufacturing process or current rating. A DRC pass alone
does not establish adequate current capacity, acceptable temperature rise
or safe short-circuit behaviour. The initial routing checkpoint is published
as review evidence, not declared a finished power layout.

### September 14: power rework and current assembly

The [separate power-rework candidate](../hardware/handbell/iterations/printed-bell-power-rework/README.md)
now has direct F-side C27/C28 supply/return loops, a short independent
R26-to-R27.2 pickoff, a separate capacitor-ground reference for R24, amplifier
bypass/distribution routing and an additional parallel protection-return via.
Ten local poses changed; U1/U6 body-depth proxies now include the audited
manufacturer maxima. The original placements and first routing package remain
unchanged.

The candidate has **674 tracks, 35 vias, no zones and 155 unconnected items**.
It deliberately reopens some earlier connections rather than preserve an
inferior power topology. The main Q1-to-boost feed and other power/signal nets
remain open. Shorter output loops do not prove thermal/current performance;
the SW neck and sampled voltage-drop cases retain explicit limitations.

The complete corrected FreeCAD assembly, exports and four views now bind
PCB `6132f8d3ec508f8ae023888052cc2a1f8b2c24f2c38d9d12dca3234ba887dcc1`
and manifest `60e394c41bcfd7734b41c7713100360253164381f0217eed325386bd49977799`.
Native SHA-256 is
`2a923489d72297a27e0bd05760b09d3ed2e19513efced5a6510add9d7b53cb4b`.
There are no nominal material overlaps; the smallest component/speaker gap
remains D3's 0.400 mm, and L1 retains its 5 mm height and 0.700 mm yoke gap.
All seven actual rear labels have a separate exact-current-model service
screen. This is conservative CAD evidence, not physical fit or safety signoff.

The shell, six structural prints, mounts, contact/cell datums and insulation
were not reduced or resized. A subsequent sourced-part or
[USB land-pattern correction](usb-connector-qualification.md) still requires
another exact bind; this intermediate assembly is not the final quote model.

Owning epics: E04/#4 electrical, E05/#5 mechanics, E07/#7 placement/routing,
E10/#10 eventual qualification.

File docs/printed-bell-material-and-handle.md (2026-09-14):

# Printed-bell material and handle source notes

**2026-09-13 source review, not a qualified print profile or strength rating.**
This supports the [printed-bell revision](printed-bell-revision.md).

## ERYONE silk PLA

The owner linked [Amazon ASIN B082XTFB7T](https://www.amazon.com/dp/B082XTFB7T).
The Amazon page did not expose usable product parameters during this review.
The exact listing/spool-to-formulation mapping therefore remains unconfirmed.
Do not substitute settings for a newer high-speed formulation.

The [manufacturer's standard Silk PLA page](https://www.eryone.com/silk-pla-product/)
lists nozzle **190-220 C**, bed **55-70 C**, speed **30-60 mm/s**, and filament
diameter **1.75 +/-0.03 mm**. The page's linked
[Silk PLA TDS](https://file.globalso.com/file_manage/3828/20251125/eryone-silk-pla-tds.pdf)
identifies itself as **version 1.0, 08/2024**, despite the later URL directory.
The reviewed PDF SHA-256 is:

`0213b4d708b87844989996308e1d0173379ff783be67fd89bab4f4dfe9fa8184`

That TDS repeats the temperature ranges but lists **30-100 mm/s**. Preserve
the difference rather than presenting a single universal speed limit.
It expressly says higher temperature or slower printing can increase sheen;
this supports the owner's proposed direction, but not heating beyond the
actual spool's range. No maximum volumetric flow or layer-height specification
was found in the reviewed TDS.

For a **0.4 mm nozzle and an inert finish/geometry trial**, a project-selected
starting point is **0.12 mm layers, 215 C nozzle, 60 C bed and 30 mm/s outer
walls**, retaining the established first-layer/adhesion settings. These are
unexercised starting settings, not an ERYONE K1C profile. Comparing 0.12 with
0.16 mm layers and 210/215/220 C on a small curved sample can separate visible
layer stepping from gloss and bonding. Do not lower cooling universally or
apply high-speed acceleration/flow limits without looking at the actual
overhangs and print.

Keep the visible shell free of support contact where geometry permits.
Print the shell mouth-down/handle-up, with accessible internal supports or
sloped inner surfaces where needed; print the grille's exterior face on the
bed. Plate texture transfers to that face. Shorter layers do not eliminate
the seam, support marks, or all stair-stepping at a rounded crown.
See [Prusa's geometry/orientation guidance](https://help.prusa3d.com/article/modeling-with-3d-printing-in-mind_164135);
its printer-specific overhang capability is not a measured K1C capability.

The TDS gives typical density **1.32 g/cm3**, Vicat **56 C**, heat-distortion
temperature **53 C at 0.45 MPa**, and glass transition **63 C**. None is a
permitted enclosure operating/storage/charging temperature. Its printed
sample table also shows directional strength differences; those data are
not allowable stresses for our handle. In particular, the X-Z tensile row
names GB/T 1843, an impact-test standard, so its standard attribution should
not be treated as verified tensile qualification. The TDS itself says its
values are for reference/comparison, not design specifications.

Use the silk candidate for appearance/fit development. Final shell, mounting
boss and handle suitability still needs impact, creep, temperature and
assembly-load evidence. A black non-silk printed handle can share the same
interface, but a material name alone does not establish its strength.
No vendor PDF or user reference photograph is redistributed here.

## One central handle fastener

The working selection is an **M4 machine screw into a captive metal M4 nut**,
with a locating/keyed shoulder and a large washer inside the crown. This
keeps repeated service out of threads cut directly into printed plastic.
The washer spreads the head load; the shoulder/key transfers lateral and
rotational loads into the shell rather than relying only on clamp friction.
The battery and PCB are not part of this load path.

M4 is close to the size class of the owner's suggested 8-32, while retaining
the metric convention of the existing M2 joints. Threads are not
interchangeable. A 1/4-20 screw would require a larger 6.35 mm nominal bore;
it is not adopted without a demonstrated need.

The following are **supplier-published standard-family dimensions**, not an
inspected licensed ISO standard or a selected hardware lot:

| Item | Working/source dimensions |
|---|---|
| [M4 pan-head screw](https://www.fasteners.eu/standards/ISO/7045/) | The page actually labels its table DIN 7985. Pitch0.7, head diameter7.64-8.00 mm, height2.95-3.25 mm (nominal3.1). M4x16 under-head length15.65-16.35; M4x20 length19.6-20.4 |
| [M4 large washer, DIN 9021](https://www.fasteners.eu/standards/DIN/9021/) | ID4.30-4.48, OD11.57-12.00, thickness0.90-1.10 mm |
| [M4 hex nut, ISO 4032 family](https://www.fasteners.eu/standards/ISO/4032/) | Across flats6.78-7.00, height2.90-3.20 mm, pitch0.7 |

The new mechanical model must select an actual working screw length and
demonstrate nut loading, bearing surfaces, thread engagement, tip clearance,
tool access and battery separation, including relevant dimensional bounds.
A washer/head envelope alone does not prove adequate printed bearing
strength, preload, anti-loosening or service life. Do not over-tighten an
unqualified silk-PLA boss.

A wooden handle remains a later compatible option, not an implemented wood
joint. A predrilled wood-screw pilot depends on screw design, wood species,
grain and engagement; the printed handle's machine-nut dimensions cannot
qualify it. A matching machined tenon and mechanically retained threaded
interface can reuse the shell without altering the PCB.

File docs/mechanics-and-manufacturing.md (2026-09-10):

# Mechanics, acoustics, and manufacturing

Status: trade study and measurement plan, updated 2026-09-09. The owner has
shells, 2-inch speakers and the arrived EK1794. Its reported measurements are
D40/H19, a D32 basket rear at z12 and D22/H7 magnet; see the
[measured-speaker study](../mechanical/studies/2026-09-09-measured-speaker/README.md).
No cell, final PCB outline, assembly quote or production process is selected.

## Measure before choosing a circle

**Current feasibility model:** the owner now assumes D50 at z13 tapering
linearly to D34 at z43. The [FreeCAD study](mechanical-feasibility.md) and
[43 mm placement](electrical-reduction-and-placement.md) use that profile.
The z22 calculation below is preserved as a **superseded sensitivity example**,
not the current fit model. Real-shell tolerances, clapper intrusion, USB slot,
cell and mating harnesses remain measurement gates.

The initial [inspiration listing](https://www.amazon.com/Colorful-Handbells-Musical-Instrument-Wedding/dp/B09P4NTLWK)
did not establish usable internal geometry. The owner actually has
[B01EABRWO6 shells](https://www.amazon.com/dp/B01EABRWO6). Owner estimates and
the supplied retail speaker dimensions are captured in
[structured inputs](measurements/shell-speaker-inputs.json); do not substitute
external photographs for inner taper, handle/clapper intrusion and tolerances.

| Owner-reported shell input | Approximate value / limitation |
|---|---|
| Inside diameter just inside lip | 70 mm |
| Inside diameter halfway down the smaller tapered region | 40 mm; depth from lip not specified |
| Bell-body height | 44 mm |
| Handle height | 85 mm; hollow/usable interior not established |

Use the lip plane as axial datum `z=0`, positive inward. Record clear ID at
known depths (for example every 5 mm), including ovality and the minimum usable
diameter after the clapper is removed. Identify the existing 40 mm station.
Measure the candidate USB opening at its proposed depth, not just at the lip.

Measure several shells, ideally across more than one set. Record inner diameter
at multiple heights, ovality, wall thickness, lip profile, depth, handle/clapper
mount, usable USB-slot locations, and total mass. Keep a drawing with a datum and
measurement uncertainty. Clarify how removing the clapper changes the shell.

For each real speaker and cell, record the full envelope, frame/ear dimensions,
connector/cable exit, magnet/back-vent keepouts, mounting surfaces, and mass.
Stack up the diaphragm/grille clearance, speaker depth, rear acoustic cavity,
PCB standoffs, components on both faces if any, battery, insulation, screw ends,
and assembly/tool access.

Begin with cardboard circles and an inert battery-sized block, then a simple
printed carrier. Do not test fit by compressing a live pouch cell.

## Why the axial stack now matters

The historical 40 mm speaker drawing's worst-case frame diameter is **40.9 mm**, magnet
diameter **22.5 mm**, and overall depth **18.5 mm**. Its rim dimension is included
in that height. The basket profile, terminals, rear vent and excursion envelope
are not fully established. Those are retailer dimensions, not the current
arrived-part measurements: the owner's reported **19 mm** depth exceeds the
old 18.5 mm gauge. Keep the following calculation as historical sensitivity
analysis; use the new study for current station-based geometry.

For a **sensitivity example only**, assume the 40 mm shell ID occurs 22 mm
inward and a straight taper connects it to the 70 mm lip:

```text
ID(z) = 70 - (30/22)*z, for 0 <= z <= 22 mm
```

At 18.5 mm depth this hypothetical cavity is 44.8 mm wide. Add an illustrative
2 mm gap behind the speaker and the PCB plane sees only **42.0 mm** before
board thickness, component height, carrier, battery or other clearances.
Under that assumption, 55/50/45 mm PCB planes must be no deeper than
11.0/14.7/18.3 mm, respectively. The owner did **not** measure the 40 mm station
at 22 mm; these numbers are not a fit finding or a profile extrapolation.

Explicitly hypothetical packaging comparison

The original diagram and [numeric screen](measurements/packaging-screen.json)
are generated with standard-library Python:

```powershell
python .\tools\screen_packaging.py --assumed-40mm-depth 22
```

The required argument makes the invented station explicit. The
[input record](measurements/shell-speaker-inputs.json) still stores its actual
depth as `null`. No supplied product photo/drawing is redistributed.

Study a **near-mouth annular/C-shaped or offset board** rather than forcing all
electronics onto a disk behind the magnet:

| Hypothetical outer / inner diameter | Gross annulus area | Area after 1 mm excluded at both edges | Radial width |
|---|---:|---:|---:|
| 64 / 43 mm | 1,765 mm^2 | 1,429 mm^2 | 10.5 mm |
| 66 / 43 mm | 1,969 mm^2 | 1,627 mm^2 | 11.5 mm |
| 68 / 43 mm | 2,180 mm^2 | 1,831 mm^2 | 12.5 mm |

The 66/43 example has the gross area of a 50.1 mm solid disk, but its narrow
band is harder to place/route. **A 15.4 mm-wide S3-MINI body does not fit wholly
in this uniform band**; it needs a wider bay, offset aperture, permitted
overhang with real 3D clearance, or another location. Antenna keepouts are extra.
These examples are not selected outlines and do not prove that the battery,
USB or power block fits.

Component height near the tapered wall matters even when the PCB plane fits.
A shallow printed mouth extension, or components facing outward toward a
standoff grille, may create room. Model USB access and antenna placement with
that choice; neither a printed bezel nor an open mouth guarantees usable RF.
Do not block speaker vents or assume the smaller magnet diameter describes
the entire basket.

## One face, two layers, and board-area estimates

**One-sided assembly** means components placed on one PCB face. **Two-layer**
means two copper layers. These are different constraints.

The [new wing iteration](electromechanical-wing-iteration.md) explicitly
compares selective rear-face power/audio placement with the original one-face
goal. Its mounting and battery/USB reservations are shared with the integrated
cartridge study. Do not infer low-tier assembly eligibility from layer count
or from having only a few rear components.

The KB2040 provides a relevant two-layer RP2040 precedent. QT Py RP2040's
compactness also uses bottom-side components, so its dimensions do not prove
our one-face target. Connectors, power/thermal copper, test access, routing,
and mechanical keepouts may dominate the silicon area.

Use actual component courtyards for a first screening estimate:

```text
D_estimate >= 2*m + sqrt((4/pi) * (A_K + A_F/eta))
```

`A_F` is summed footprint/courtyard area; `A_K` is additional non-overlapping
reserved area; `eta` accounts for imperfect packing/routing; `m` is a radial
edge allowance. Values such as 0.45-0.65 for `eta` are only sensitivity-study
assumptions, not a design rule or demonstrated fit.

| Illustrative circle diameter | Gross circular area |
|---|---:|
| 40 mm | 1,257 mm^2 |
| 50 mm | 1,963 mm^2 |
| 60 mm | 2,827 mm^2 |

These are mathematical examples, **not recommended board sizes**. Fixed USB
orientation, fasteners, fragmented keepouts, taper, and height can defeat an
area-based result. Establish feasibility with actual placement and routing.

Compare one two-layer board against one four-layer board and two stacked
boards using the same BOM/envelope assumptions. Stacking adds interconnects,
supports, height, assembly steps, and failure points; it does not automatically
save cost. Four layers may be cheaper overall than a difficult two-board build.

## Speaker trade-space examples

These are comparison candidates, not an approved procurement list. Manufacturer
power ratings use different conditions and are not direct loudness comparisons.

| Example | Stated envelope / mass | Electrical rating | Use in the trade study |
|---|---|---|---|
| [Gikfun 40 mm, owner candidate EK1794](https://gikfun.com/products/gikfun-4ohm-40mm-diameter-3w-full-range-audio-speaker-stereo-woofer-loudspeaker-for-arduino-pack-of-2pcs) | Owner measured D40/H19, basket rear D32 at z12 and magnet D22/H7 on September 9; no tolerance limits established | Seller 4 ohm; **3 W title versus 2 W input-power rating in description** | Arrived and dimensioned at key stations; no assumed continuous/peak interpretation; qualify intended signal and limits |
| [Gikfun 2-inch, owner part EK1725](https://gikfun.com/products/gikfun-2-4ohm-3w-full-range-audio-speaker-stereo-woofer-loudspeaker-for-arduino-pack-of-2pcs) | Seller says 2-inch diameter, 30 mm height; measure the two on-hand units | Seller says 3 W, 4 ohm | Immediate acoustic comparison; substantially deeper nominal envelope |
| [Adafruit 1890](https://www.adafruit.com/product/1890) | 28 mm diameter x 4.5 mm; listing says 6 g | 8 ohm; datasheet 0.25 W continuous, 0.5 W short-term max | Very shallow/light baseline; enforce a suitable output limit |
| [Same Sky CMS-28468N](https://www.sameskydevices.com/product/product-resources/cms-28468n.pdf) | 28 mm diameter x 4.6 mm; 5.3 g | 8 ohm; 0.5 W nominal, 1 W max under stated test | Shallow, manufacturer-documented alternative |
| [Visaton BF 37, 8 ohm](https://www.visaton.de/en/products/drivers/fullrange-systems/bf-37-8-ohm) | 41 mm max frame extent, 37 mm across flats; 23.8 mm total depth; 33.1 g | 8 ohm; 5 W rated | Deeper/heavier comparison, not proof of fit or superior sound in this cavity |
| [Dayton ND65-4](https://www.daytonaudio.com/product/63/nd65-4-2-1-2-aluminum-cone-full-range-driver-4-ohm) | Listing approximately 64 mm diameter x 48 mm depth; confirm mechanical drawing | 4 ohm; 15 W RMS; specified 3.5 mm Xmax | Large long-excursion reference; may be impractical for this shell and amp |

Primary drawings:
[1890](https://cdn-shop.adafruit.com/datasheets/1890_8ohmMetalSpeaks.pdf),
[BF37](https://www.visaton.de/sites/default/files/dd_product/BF37-4-8-Ohm_datasheet_1.pdf),
[ND65](https://www.daytonaudio.com/images/resources/290-204-dayton-audio-nd65-4-specifications.pdf).
Do not confuse the BF37's stated mechanical excursion with linear Xmax.

Compare sensitivity, response, distortion, perceived timbre, mass, and current
at matched listening level. A deeper driver or higher wattage rating is not
automatically louder or better. The board, carrier, and battery reduce rear
volume and can obstruct vents. Establish front/rear acoustic separation where
intended; compare sealed, vented, and leaky mock-ups rather than assuming the
metal bell is a suitable speaker enclosure.
See [miniature-speaker enclosure guidance](https://www.sameskydevices.com/blog/the-critical-role-of-rear-enclosures-in-miniature-speakers).

## Retention and assembly concepts

Retain all three ideas in the [brief](project-brief.md). The current leading
concept is a **printed, removable cartridge and grille**, preassembled outside
the bell. A separately bonded mounting ring or interface retains it inside the
shell; do not permanently glue the battery into an inaccessible assembly.
Use printed baffle/speaker seats, independent cell retention and PCB supports.
Grille open area, stiffness, print orientation, cone clearance and rattle
behavior need physical evaluation. Prototype with inert fit pieces first.

USB insertion, removal, and cable-lever loads should transfer from connector
shell anchors through nearby PCB/carrier supports into the enclosure. Signal
pads and a far-side SMT threaded receptacle alone are not a demonstrated load
path. For scale only, the [GCT USB4105 drawing](https://gct.co/files/drawings/USB4105.pdf)
specifies 5-20 N mating force; that is not our structural acceptance criterion.

An SMT right-angle nut requires exact part selection and assembler approval:
packaging, pickup surface, reflow tolerance, solder joint strength, screw
direction, torque, and access all matter. Compare a captive nut or heat-set
insert in the carrier. Deburr and insulate any metal-shell slot. Mechanical
insulation is not galvanic USB isolation.

Define speaker-JST family and polarity explicitly; "JST" is not a connector
specification. The BFF's small speaker connector is PicoBlade-compatible, not
automatically the same family as a LiPo JST-PH. Avoid interchangeable battery
and speaker plugs or make misconnection impossible. Check actual retention
under shaking and access at every assembly step.

Use positive screw-length stops, captive hardware, strain relief, and
cell-manufacturer-required expansion/clearance. Keep cells away from sharp
edges, screw tips, heat, hard compression, and metal shorts. Printed carrier
adhesion to painted metal, print creep, and repair access need evidence.

## JLCPCB: fabrication plus optional assembly

Consult the current
[assembly capabilities](https://jlcpcb.com/capabilities/pcb-assembly-capabilities),
[PCB capabilities](https://jlcpcb.com/capabilities/pcb-capabilities), and
[assembly FAQs](https://jlcpcb.com/help/article/pcb-assembly-faqs)
when quoting; the following is a 2026-09-06 research snapshot, not order approval.

**2026-09-07 sensor update:** the inspected JLC listings for the owner-approved
LSM6DSOX and alternate LSM6DS3TR-C were Standard-only/Extended with required
X-ray inspection. Requote the entire BOM rather than assuming Economic assembly
from the one-face layout goal. See the dated [motion/sourcing report](motion-sensing.md).

| Topic | Planning consequence |
|---|---|
| Economic vs Standard | Economic advertises single-side placement on 2/4/6-layer boards; Standard supports single/double-side. Select the service from the complete job, not layer count alone. |
| Minimum sizes | Assembly and panelization limits are distinct. The inspected page lists Economic 10 x 10 mm and Standard 70 x 70 mm minima; small Standard boards may require an approved panel. Circular "Panel by JLCPCB" has a separate 20 x 20 mm minimum. Reconfirm during quotation. |
| Round outline | Routed tabs/mouse bites and a carrier can support handling; straight V-cuts cannot follow a circle. Reserve depanelization clearance and address residual tab roughness. |
| Rails/fiducials | Standard specifies rails/fiducials; the guide gives at least 5 mm rails. Economic rules differ. Obtain the actual panel acceptance. |
| USB-C overhang | Review connector body, stakes/slots, board edge, rails, and assembly access explicitly; a copper-edge rule is not permission for arbitrary component overhang. |
| Fine pitch | Economic lists 0402 minimum packages under supported conditions. Prefer factory assembly of fine-pitch ICs rather than requiring novice reflow. |
| Parts | Basic/Extended/Preferred Extended status changes setup charges; catalog/LCSC presence is not a guaranteed assembled part reservation. |
| Odd mechanics | SMT threaded hardware or unusual connectors may require custom/manual operations and a separate quote. |

On 2026-09-07 the rendered official capability table again confirmed
**Economic: single-sided placement; Standard: single- and double-sided**.
It lists 0402 / 0201 minimum packages respectively and X-ray for specified parts
in both services; not every QFN/LGA automatically requires Standard.
One-face remains the preference, not a guarantee of Economic eligibility.
If two faces win the trade study, factory assembly is preferable to assuming
novice backside inductor rework. Many small molded inductors have bottom
terminations, and moving the inductor alone can enlarge critical switching
loops. Treat IC, inductor, input/output capacitors and return paths as a block.

Additional official guidance:
[panelization](https://jlcpcb.com/help/article/pcb-panelization),
[rails/fiducials](https://jlcpcb.com/help/article/how-to-add-edge-rails-fiducials-for-pcb-assembly-order),
[assembly edge FAQ](https://jlcpcb.com/help/article/pcb-assembly-faqs-part-2),
[parts consignment](https://jlcpcb.com/help/article/how-to-consign-parts-to-jlcpcb).
Consignment is available but may introduce logistics overhead unsuitable for a
small initial batch; prefer supported stocked parts when technically suitable.

The [official KiCad BOM/CPL guide](https://jlcpcb.com/help/article/how-to-generate-the-bom-and-centroid-file-from-kicad)
describes BOM fields including `Comment`, `Designator`, `Footprint`, and supplier
part number, and CPL fields `Designator`, `Mid X`, `Mid Y`, `Rotation`, `Layer`.
Supply Gerbers/drills, BOM, and centroid data; inspect every placement/polarity
in the assembly preview. Match component substitutions to electrical, package,
and firmware requirements.

## OSH Park: bare-board comparison

[OSH Park](https://oshpark.com/) offers PCB fabrication, not a turnkey populated
board service. Budget separate component assembly; JLCPCB's FAQ says it does
not assemble externally fabricated PCBs.

At the research snapshot, standard
[two-layer](https://docs.oshpark.com/services/two-layer/) and
[four-layer](https://docs.oshpark.com/services/four-layer/) services list
$5/in^2 and $10/in^2 respectively, including three copies. These are published
service formulas, not a quote including components, shipping, or assembly.
Both list nominal 1.6 mm construction and ENIG; stackups and rules differ.
Two-layer lists 6/6 mil trace/space and 15 mil copper-edge clearance.

Round boards are supported, but
[billing uses the enclosing rectangle](https://docs.oshpark.com/submitting-orders/board-outline/):
for diameter D, billed area is D^2, not pi*D^2/4.
Choose whether a shared layout meets both vendors' rules or maintain explicitly
versioned fabrication variants. Revalidate the actual stackup and USB geometry
for the selected service.

## Total-cost model

Quote illustrative batches of 5, 25, and 100 instruments unless actual demand
sets different quantities. These are planning scenarios, not commitments.
Include PCB/panel waste, parts, extended-part setup, assembly, programming/test,
cell, speaker, bell shell, connectors/harnesses, printed carrier, fasteners,
shipping/taxes, yield, repair spares, and remaining manual labor.

Compare per-instrument and per-class-set cost and assembly time. Do not order
parts or fabrication without explicit owner approval.

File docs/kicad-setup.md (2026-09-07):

# KiCad setup and schematic readiness

Verified on Windows on 2026-09-07. **The tools needed to start schematic work
are installed and operational.** The remaining work is electrical design and
reference-import review, not installing an EDA subscription or importer plugin.

## Installed toolchain

| Item | Result |
|---|---|
| Package | Official `KiCad.KiCad`, version 10.0.6, installed through WinGet |
| Scope | Current Windows user; no machine-wide PATH modification |
| Executables | `%LOCALAPPDATA%\Programs\KiCad\10.0\bin` |
| GUI | Manager, schematic editor, and PCB editor opened with the reference |
| Standard libraries | 224 symbol-library files, 155 footprint-library directories, 105 3D-model-library directories in this installation |
| Global library tables | Initialized using KiCad's built-in libraries |
| Privacy | Anonymous data collection left disabled |
| Command line | Native schematic netlist/PDF export, ERC, and EAGLE PCB import exercised |
| Third-party plugins | None required or installed for this work |

The installer came from the official KiCad release linked by WinGet; WinGet
verified its SHA-256 before installation:
`9e24dc47119f7c472128c2f293c5e3f35569274a44c905e60a7514d47c16ce48`.
The official [Windows download page](https://www.kicad.org/download/windows/)
and [10.0.6 release](https://www.kicad.org/blog/2026/08/KiCad-10.0.6-Release/)
provide the distribution context. Counts are installation observations, not
compatibility guarantees for every future component.

Standard symbols include RP2040, MAX98357A, MCP73831-2-OT, LIS3DH, and LSM6DS3.
A similarly named symbol is not proof that its package/pinout matches a selected
suffix such as LSM6DS3TR-C. Review the exact MPN and footprint before use.
An exact LSM6DSOX symbol was not found in the installed `Sensor_Motion`
library. The [approved SOX block](../hardware/handbell/README.md) now uses the
actual Adafruit 4438 imported symbol/footprint, with all 14 physical pad mappings
compared and its symbol specialized to Mode 1. Do not substitute the LSM6DS3
symbol merely because the package outline looks similar.

## Open the handbell draft

Use **File > Open Project** and select:

```text
C:\Projects\dcuccia\digital-handbell\hardware\handbell\handbell.kicad_pro
```

Open its schematic, or read the
[PDF](../hardware/handbell/reports/handbell-schematic.pdf). The current 0.2
also has a **43 mm unrouted placement**, not a fabrication-ready PCB.
Keep the whole checkout: its footprint table references the
sibling reference packages. The [handoff](../hardware/handbell/README.md)
includes repeatable strict ERC and net/pad comparison commands.

## Open the reference

1. Start **KiCad 10.0** from the Windows Start menu.
2. Choose **File > Open Project** and open:

   ```text
   C:\Projects\dcuccia\digital-handbell\hardware\reference\adafruit-5768\kicad\Adafruit Feather RP2040 Prop-Maker.kicad_pro
   ```

3. Open the `.kicad_sch` entry for the schematic or `.kicad_pcb` for the board.
4. For a quick read without CAD, open the
   [schematic PDF](../hardware/reference/adafruit-5768/reports/reference-schematic.pdf).

The imported symbol and footprint libraries are project-local and use
`${KIPRJMOD}` paths. No personal library configuration is required to resolve
those imported assets. Keep this reference unchanged while a separate handbell
derivative is developed.

## Repeatable CLI access

The CLI is not assumed to be on PATH. In PowerShell:

```powershell
$KiCadCli = "$env:LOCALAPPDATA\Programs\KiCad\10.0\bin\kicad-cli.exe"
& $KiCadCli version
$Reference = "C:\Projects\dcuccia\digital-handbell\hardware\reference\adafruit-5768"
$Schematic = "$Reference\kicad\Adafruit Feather RP2040 Prop-Maker.kicad_sch"
& $KiCadCli sch export pdf --exclude-pdf-metadata --output "$env:TEMP\handbell-reference.pdf" $Schematic
& $KiCadCli sch export netlist --format kicadxml --output "$env:TEMP\handbell-reference.xml" $Schematic
& $KiCadCli sch erc --format json --output "$env:TEMP\handbell-reference-erc.json" $Schematic
```

Adjust the checkout/install path on another machine. ERC without
`--exit-code-violations` can return success while reporting violations; inspect
the report. The handbell derivative now uses that flag for enforcement, without
changing the inherited severity matrix or adding exclusions.

## Import behavior actually observed

KiCad 10.0.6 has `pcb import --format eagle`, but **no equivalent `sch import`
CLI subcommand**. Passing the EAGLE schematic directly to `sch export netlist`
failed with exit code 3. The working schematic route was the GUI:

**File > Import Non-KiCad Project > EAGLE Project**, selecting the pinned `.sch`
and a separate destination. KiCad also imported the matching `.brd`. At the
layer-mapping dialog, use **Auto-Match Layers**, review the mapping, and then
save both native editors. Do not stop with unsaved editor tabs.

The reference retained project-local libraries and produced native schematic
and PCB files. Relocating the package into this repository still allowed
schematic PDF export.

## What is ready, and what is not

We can now inspect the upstream circuit, make a separate reduced schematic,
assign reviewed parts, export review PDFs/netlists, and run ERC.

The imported reference is **not ERC-clean**: its initial report contains
13 errors and 37 warnings. Its 71 nonempty upstream board-net pin groups match
the schematic export after documented reference renaming, which is useful
connectivity evidence but does not prove footprint accuracy, layout geometry,
design-rule equivalence, or functional performance.

See the [import report](../hardware/reference/adafruit-5768/README.md).
E02 remains open for the remaining geometry/design-rule reviews. The separate
[handbell draft](../hardware/handbell/README.md) resolves all 50 original findings
and has zero current ERC findings; E04 remains open for unresolved electrical
decisions and complete review. The unchanged SOX breakout reference has its own
24 initial findings, preserved with that reference rather than globally waived.
The MiniBoost reference adds four preserved initial findings. Native PCB/STEP
and placement-specific limits are covered in the
[0.2 handoff](electrical-reduction-and-placement.md).

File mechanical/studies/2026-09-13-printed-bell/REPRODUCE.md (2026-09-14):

# Reproduce the separate September 13 package

Run from `C:\Projects\dcuccia\digital-handbell`. FreeCAD 1.1.3 is the
exercised console; each report records actual FreeCAD/OpenCASCADE/Python
versions. Ordinary launcher Python needs no FreeCAD modules or extra package.

## Current exact all-front bind

```powershell
python .\tools\build_printed_bell.py --placement .\hardware\handbell\iterations\printed-bell-power-rework\placement-manifest.json
python .\tools\check_printed_bell.py
```

This writes the current assembly to the study root. The completed power-rework
manifest begins `60e394c4`; the PCB begins `6132f8d3`. Full hashes are in
README, `fit-report.json` and `artifact-manifest.json`.
After copper-only routing changes, the parent must supply the regenerated
manifest with actual new PCB hash and repeat the complete bind. Geometry
can remain unchanged; a stale input hash is still not an approved release.

After the completed generation and mechanical check, run this candidate's
actual-glyph screen against the rebound native:

```powershell
python .\hardware\handbell\iterations\printed-bell-power-rework\screen_current_mechanical.py
```

The command rejects a native bound to another electrical candidate and writes a separate
`service-label-current-mechanical-review.json` beside the routing reports.
Its exact current-native and completion bindings supplement, rather than
overwrite, the earlier immutable release/visibility evidence. This report
is not an input to model generation, avoiding a circular evidence dependency.

This intermediate power milestone is not the final routed/quote candidate.
Changing the USB footprint, sourced-part envelopes or electrical bytes requires
another complete bind and the corresponding candidate's label screen.

On the September 14 GUI run, FreeCAD 1.1.3 emitted a nonfatal
`Reading failed from embedded file: GuiDocument.xml` message while restoring
the headless-written display metadata. All four views were produced from the
intact native, and the view macro left that source unchanged. The minimal
display XML has no Camera element; GUI-state cleanup remains a separate
handoff item, not permission to replace the bound source with a GUI-resaved
file or to ignore a geometry/hash failure.

## Optional explicit development reproduction

```powershell
python .\tools\build_printed_bell.py
python .\tools\check_printed_bell.py --development
```

This writes only `mechanical\studies\2026-09-13-printed-bell\development`.
It reads frozen T8 native/placement/contact/report artifacts without editing
them, translates retained hardware +10.75 mm and keeps the old mixed-face
population visibly and machine-readably marked as **development**.

The automation takes an explicit `--placement` path and does not ask questions.
Final mode writes the study root, not the preserved T8 or electrical directories.
An optional `--output` must remain inside this September 13 study.
Use `--freecad-cmd` for a nondefault installed console path:

```powershell
python .\tools\build_printed_bell.py --freecad-cmd "$env:LOCALAPPDATA\Programs\FreeCAD 1.1\bin\FreeCADCmd.exe"
```

Final mode rejects previews, any electronic B-side population beyond BT1/BT2,
PCB F/B or mount changes, USB-source changes and altered contact geometry.
It accepts D43/46/48 only, so a larger board is an explicit electrical
tradeoff rather than silent generator growth. The authoritative outline is
the supplied polygon, not an ideal replacement circle.

Final source integrity covers actual PCB/schematic bytes, companion hash,
available source symbol/footprint libraries, exact design-input bytes,
preserved BRep/report inputs, and helper/builder/checker code. Text inputs
are embedded as raw base64 in native; binary frozen-native provenance is
recorded by SHA256 and read-only source path. Public paths are
repository-relative, not private session paths.

## Geometry and validation

The source contains original cubic Bezier radial/z poles for shell exterior,
independent cavity and black handle. Alter only this new builder/package,
never the preserved T8 generators/native or shared electrical outputs.
Current inner/outer coordinates are not a constant-normal-offset promise.
The T8 yoke/cradle/cover and thin metal contacts are copied as BReps, not
regenerated by the old builder. Yoke/cradle/contact geometry remains unchanged.
The new cover receives straight spring-tip service channels and added outside
stock with actual external-wall containment witnesses; the full-contact
removal check exposed this omission in the earlier cell/cradle-only screen.

The builder performs:

- One-solid validity for all six structural prints, complete placed-part
  material intersections and explicit service poses.
- Closed cosmetic shell-joint stock:1mm positive offsets of every actual
  nut pocket, inward slot and screw bore contained in the unchanged outer
  solid; matching expanded-cavity containment in the affected band;
  actual3.7mm bearing-floor/2.6mm roof witnesses; zero missing cosmetic
  side-surface area except USB. Static overlap checks alone do not prove this.
- Front shell-screw and driver paths, inward nut loading and complete
  cartridge withdrawal with the shell nuts still installed. The revised
  three-joint pattern is R26.5 at90/210/330 degrees, not the PCB mount pattern.
- Actual USB skin/frame containment and front-face opening equality:
  the14.4x7x1mm locally raised frame at y-29.1..-28.1 retains only the
  intended9.2x3.1mm aperture. The source PCB tongue's full front projection
  is covered by real material. Plane separation proves open-top PCBA
  loading relative to the new skin for every Z position; the full unselected
  nose's continuous straight approach sweep clears shell and carrier.
- B-side label sight columns against the retained cradle, installed cell,
  contacts and remaining hardware with cover/screws removed. These are
  proposed rectangular text reservations, not actual routed-PCB glyphs;
  the builder does not read or edit the active routing source.
- Actual 1.08 mm under-cell section and constructive containment of the
  M4 washer bearing annulus in the real shell.
- Separate supplier-table M4x16 tolerance BReps: maximum head H3.25 and
  washer H1.1, minimum/maximum screw lengths, nut-height coverage, maximum
  tip clearance and empty-shell installation. These are supplier tables,
  not inspected ISO primary standards or certified thread/preload behavior.
- Native reopen and BRep symmetric-difference comparison.
- All full/component STEP exports **before tessellation**, followed by
  per-solid BRep symmetric differences, solid-count/unit/bounds checks.
- Reimport of every released STL as a closed, single-connected,
  non-self-intersecting mesh and reconstructed valid BRep.
- Exact input hashes before/after generation, output hashes and a fresh
  completion token. A console zero exit or stale native file is not success.

The full native/STEP PCBA retains both thin contacts. The inert PCBA STEP/STL
is explicitly contact-free because the frozen contact fold roots have known
mesh limitations; no fabricated bridge is added to metal.

The checker validates all recorded outputs, current inputs, raw native source
records, geometry findings, service poses and final/development scope.
It is not an independent CAD solver; regenerate with FreeCAD for new Boolean
results. Passing it does not qualify printing, force/torque, thermal behavior,
USB mating, actual cell contact, live-cell use or child suitability.

The console runs synchronously, using a uniquely named preference/marker
directory **inside this study** and removing that directory afterward.
No operating-system temporary directory, GUI launch, add-on, package install
or old-generator invocation is required. `freecad-build.log` is diagnostic
console output. STEP/native files left after a failed run are not reviewable;
`review-status.json` and the matching completion/inventory bind are required.

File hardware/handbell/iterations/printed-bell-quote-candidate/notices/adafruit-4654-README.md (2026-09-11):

## Adafruit Adafruit MiniBoost 5V at 1A - TPS61023 PCB

<a href="http://www.adafruit.com/products/4654"><br/>
Click here to purchase one from the Adafruit shop</a>

PCB files for the Adafruit Adafruit MiniBoost 5V at 1A - TPS61023.

Format is EagleCAD schematic and board layout
* https://www.adafruit.com/product/4654

### Description

This adorable little board will come in very handy whenever you need a good amount of 5V power. It's the size of a linear regulator, but it's actually a mini-booster! Input 2-5VDC on one side, and get 5V at up to 1A supply on the other. Perfect for use with battery-powered projects with 2 or 3 Alkaline, or a single Lithium battery.

This booster uses a very small but thermally efficient chip from TI, the TPS61023. This chip has nearly everything integrated, including dual 3A MOSFET switches. Note that the switch doesn't tell you the max output, see the tables below for that!

We set the feedback resistors to give a 5.2V output, this is a little higher than 5V which helps account for voltage drop over cables. We took some measurements of the input/output current and max draw using a bench-top power supply and electronic load:

    At 2V DC in, max current out at 5V is 300mA (the minimum input voltage that will 'boot' the booster)
    At 2.5V DC in, max current out at 5V is 500mA (two NiMH rechargables)
    At 3V DC in, max current out at 5V is 800mA (two alkalines or a near-dead LiPo)
    At 3.5V DC in, max current out at 5V is 1100 mA (this is a LiPoly nominal voltage)
    At 4V DC in, max current out at 5V is 1400 mA (3 NiMH, or a fresh LiPoly)

Most people will want to use a Lipoly or LiIon battery with a booster, with a nominal voltage of 3.7V. Here's the efficiencies at that voltage:

    5.2V 100mA out requires 160mA in at 3.7V (88%)
    5.2V 250mA out requires 400mA in at 3.7V (88%)
    5.2V 500mA out requires 800mA in at 3.7V (88%)
    5.2V 1000mA out requires 1800mA in at 3.7V (78%)

As you can see, you'll be humming at ~88% as 'lower' currents of about 500mA and less. You can get 1A out but your efficiency will drop a bit to ~78%

You get one fully assembled breakout with a TPS61023 and components, and a small bit of header. Give it 3-5V on the IN and ground pins. Then you'll have 5V on the OUT pin. The enable pin can be pulled low to disable the output, its a 'true disconnect' so the output will be completely de-powered.

### License

Adafruit invests time and resources providing this open source design, please support Adafruit and open-source hardware by purchasing products from [Adafruit](https://www.adafruit.com)!

Designed by Limor Fried/Ladyada for Adafruit Industries.

Creative Commons Attribution/Share-Alike, all text above must be included in any redistribution.
See license.txt for additional details.

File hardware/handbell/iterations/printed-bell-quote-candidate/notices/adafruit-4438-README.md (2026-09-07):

## Adafruit LSM6DSOX 6-DoF Accelerometer and Gyro PCB

<a href="http://www.adafruit.com/products/4438"><br/>
Click here to purchase one from the Adafruit shop</a>

PCB files for the Adafruit LSM6DSOX 6-DoF Accelerometer and Gyro. 

Format is EagleCAD schematic and board layout
* https://www.adafruit.com/product/4438

### Description

INSERT PRODUCT COPY HERE

### License

Adafruit invests time and resources providing this open source design, please support Adafruit and open-source hardware by purchasing products from [Adafruit](https://www.adafruit.com)!

Designed by Bryan Siepert for Adafruit Industries.

Creative Commons Attribution/Share-Alike, all text above must be included in any redistribution. 
See license.txt for additional details.

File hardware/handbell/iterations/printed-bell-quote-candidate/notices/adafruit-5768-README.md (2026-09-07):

## Adafruit RP2040 Prop-Maker Feather with I2S Audio Amplifier PCB

<a href="http://www.adafruit.com/products/5768"><br/>
Click here to purchase one from the Adafruit shop</a>

PCB files for the Adafruit RP2040 Prop-Maker Feather with I2S Audio Amplifier. 

Format is EagleCAD schematic and board layout
* https://www.adafruit.com/product/5768

### Description

The Adafruit Feather series gives you lots of options for a small, portable, rechargeable microcontroller board. By picking a feather and stacking on a FeatherWing you can create advanced projects quickly. One popular combo is our Feather M4 or Feather RP2040 with a Prop-Maker FeatherWing on top to create animatronics or props that boot up instantly and can drive LEDs, and small speakers.

We've used the Prop-Maker FeatherWing to make lots of lil robots, swords, and other prop projects. However, what if we made it even easier for people to make props? What if we made it so many projects can be built with minimal or no soldering at all? Yeah that would be pretty nice!

Thus, the creation of the Feather P2040 Prop-Maker: an all-in-one combination of the Feather RP2040 with a Prop-Maker FeatherWing with a few tweaks based on feedback from expert prop-builders. Perfect for fitting into your next prop build! This Feather will unlock the prop-maker inside all of us, with tons of stuff packed in to make sabers & swords, props, toys, cosplay pieces, and more.

We looked at hundreds of prop builds, and thought about what would make for a great low-cost (but well-designed) add-on for our Feather boards. Here's what we came up with:

* Terminal Block NeoPixel Port - With easy-to-use screw terminals you can quickly connect and disconnect your NeoPixel strips and rings. This port provides high current drive from either the Feather Lipoly or USB port, whichever is higher. A 5V level up-shifter gives you a clean voltage signal to reduce glitchiness no matter what chip you're using. You can also cut power to the entire strip instantly to reduce quiescent power, thanks to a separate control transistor.
* MAX98357 I2S 3 Watt Class D Audio Amplifier - Drive any 4-8Ω speaker, up to 3 Watts, for sound effects. Audio comes out on two of the terminal blocks so you can screw in any wires to a speaker you like - we're partial to this small 3W speaker with pre-attached wires. Thanks to the I2S digital inputs, you'll get excellent audio quality
* Triple-Axis Accelerometer with Tap Detection - The LIS3DH is our favorite accelerometer, you can use this for detection motion, tilt, or taps. Here's an example of a lightsaber that makes sounds when swung or hit. We have code for this chip in both Arduino and CircuitPython.
* Extra Button or Output Pin - One more pin on the terminal screw block can be used for button input or digital output, for activation or a simple LED.
* Servo Connection - Plug any hobby servo with 3 wires into the 0.1" spaced header, and you can have quick motion control.
* Low power mode! The power system for the NeoPixels and speaker amplifier can be controlled by a pin to cut power to them, so you have lower power usage when the prop is in sleep or off mode (but can wake up fast by listening to the button press or accelerometer data).

At the Feather's heart is an RP2040 chip, clocked at 133 MHz and at 3.3V logic, the same one used in the Raspberry Pi Pico. This chip has a whopping 8 MB of onboard QSPI FLASH and 264K of RAM!  There's even room left over for a STEMMA QT connector for plug-and-play of I2C devices.

To make it easy to use for portable projects, we added a connector for any of our 3.7V Lithium polymer batteries and built in battery charging. You don't need a battery, it will run just fine straight from the USB Type C connector. But, if you do have a battery, you can take it on the go, then plug in the USB to recharge. The Feather will automatically switch over to USB power when it's available.

Here're some handy specs! You get:

* Measures 52.1mm x 22.8mm x 12.2mm / 2.1" x 0.9" x 0.5 without headers soldered in
* Light as a (large?) feather - ~7grams
* RP2040 32-bit Cortex M0+ dual core running at ~133 MHz @ 3.3V logic and power
* 264 KB RAM
* 8 MB SPI FLASH chip for storing files, images, and CircuitPython/MicroPython code storage. No EEPROM
* Tons of GPIO! 21 x GPIO pins with following capabilities:
	* Four 12-bit ADCs (one more than Pico)
	* Two I2C, Two SPI, and two UART peripherals, we label one for the 'main' interface in standard Feather locations
	* 16 x PWM outputs - for servos, LEDs, etc
* Built-in 200mA+ lipoly charger with charging status indicator LED
* Pin #13 red LED for general purpose blinking
* RGB NeoPixel for full-color indication.
* On-board STEMMA QT connector that lets you quickly connect any Qwiic, STEMMA QT or Grove I2C devices with no soldering!
* Both Reset button and Bootloader select button for quick restarts (no unplugging-replugging to relaunch code)
* USB Type C connector lets you access built-in ROM USB bootloader and serial port debugging
* 3.3V regulator with 500mA peak current output and power enable pin
* 4 mounting holes
* 12 MHz crystal for perfect timing.
* Prop-Making section with I2S 3W audio amplifier, 5V NeoPixel level shifting, accelerometer, servo port, and terminal blocks for fast solder-free connections.

Comes assembled and tested, with some header. You'll need a soldering iron to attach the header if you'd like to use it on a breadboard!

### License

Adafruit invests time and resources providing this open source design, please support Adafruit and open-source hardware by purchasing products from [Adafruit](https://www.adafruit.com)!

Designed by Limor Fried/Ladyada for Adafruit Industries.

Creative Commons Attribution/Share-Alike, all text above must be included in any redistribution. 
See license.txt for additional details.

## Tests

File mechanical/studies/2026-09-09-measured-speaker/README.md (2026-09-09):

# Measured speaker stations and battery-space screen

**2026-09-09: a separate study, not a replacement print kit or fitted layout.**
The speaker arrived, and the owner supplied physical dimensions. The existing
populated-PCBA print worked and could enter the bell relatively deeply, but no
insertion depth/orientation was measured. Some other printed parts were flimsy;
which parts and failure locations were not specified.

The original KiCad files, placement manifest, mechanical generator and
September 7 print artifacts are unchanged. No strengthened carrier, battery
holder or routed PCB is delivered by this study.

## What was measured

| Dimension | Owner report |
|---|---:|
| Front/frame outside diameter | 40 mm |
| Front face to back of magnet | 19 mm |
| Front face to basket rear / first ridge | 12 mm |
| Basket rear outside diameter | 32 mm |
| Magnet height | 7 mm |
| Magnet outside diameter | 22 mm |

The axial reports agree: 12 + 7 = 19 mm. Measurement uncertainty, sample count,
front-rim thickness, intermediate basket profile, terminals, wire exits, rear
vent and cone excursion remain unspecified. These are measurements of the
arrived part, not manufacturing maximum dimensions.

**The old 18.5 mm-deep speaker gauge is now too short for the reported part.**
Keep that file as the original study, not as the current conservative fit gauge.
No previously printed PCBA needs to be rescaled because of this measurement.

## Files

Original measured-station diagram and placement screen

| File | Meaning |
|---|---|
| `speaker-interpolated-stations.step` / `.stl` | D40 to D32 straight basket taper over 12 mm, plus D22 x H7 magnet; interpolation is assumed |
| `speaker-stepped-body-envelope.step` / `.stl` | D40 x H12 basket cylinder plus D22 x H7 magnet; leaves the entire basket width occupied instead of trusting a straight taper |
| `speaker-full-body-cylinder.step` / `.stl` | D40 x H19 full-body cylinder; ignores the available space around the magnet |
| `outward-body-screen.step` | Speaker stepped envelope and original populated board at the report's display depth; no carrier, contacts or battery included |
| `measured-speaker-study.FCStd` | Native BRep features, alternative battery bodies, measured-station spreadsheet, source and input snapshots |
| `fit-report.json` | All six board-depth screens, component conflicts, battery/clearance comparisons, artifact evidence and limitations |
| `measurements-snapshot.json`, `placement-snapshot.json`, `shell-parameters-snapshot.json` | Logical input snapshots for this dated screen |
| `measured-speaker-screen.svg` | Original drawing; no vendor/user photos used |

The three speaker STLs start with the speaker front on print Z=0. Import in
**millimetres at 100% scale**; STEP declares mm, whereas STL has no units.
These are inert solids, not acoustic models. There is no need to print another
speaker dummy now that the physical speaker is available.

The stepped shape is a **conditional body envelope**, not a tolerance or
terminal/vent envelope. It assumes all basket material is within D40 at z0..12
and the rear body within D22 at z12..19. Unmeasured projections can invalidate
that bound. The straight taper is a visualization alternative, not the
authority for collision clearance.

Open the native document with the full-cylinder and interpolated speaker
alternatives hidden, and show only one battery alternative at a time. Hide
`AssumedShell` to inspect the electronics. The `AssemblyDisplay` group is the
STEP assembly. Spreadsheet/source snapshots document the construction;
editing a spreadsheet cell alone does not rebuild these generated features.
Edit the measurement input and regenerate instead.

## Current placement does not become a fit merely by flipping

The shell remains the previous **assumed** profile: D50 at z13 tapering to D34
at z43, with the adjustable near-mouth transition. The speaker front remains
at bell-opening z0. PCB-front depth is the opening-facing substrate surface;
the substrate is 1.6 mm thick and components face the speaker.

The 74 component proxies are rigidly flipped 180 degrees about X, including
their Y coordinates and in-plane rotations. Their dimensions, footprints and
heights are unchanged; this is not an electrical re-placement. The simple
depth sweep produces:

| PCB front depth | Proxies overlapping stepped speaker body |
|---|---|
| z20 | C1, C5, C20, D3, J1, L1, Q1, Q4, U2, U3, X1 |
| z20.5 | C1, C5, C20, J1, L1, X1 |
| z21 | J1, L1, X1 |
| z22 | J1, L1, X1 |
| z23 | L1, X1 |
| z24 | None with positive volume, but L1/X1 touch the magnet rear plane |

All six substrates fit the assumed cavity without their mounting hardware.
**None meets even the illustrative 0.5 mm nominal speaker-body-gap screen.**
`selected_screen_depth_mm` is therefore null; `display_depth_mm` is explicitly
z20, an intersecting reference configuration, not a successful alternative.
The STEP/native assembly must not be mistaken for an approved fit.

For these depths, the interpolated basket and stepped basket produce the same
component conflicts: the measured rear magnet and component heights dominate.
This is useful direction for the next actual electrical floorplan:

- L1 is the boost inductor with a provisional 5 mm height; relocate the power
  block coherently rather than moving just the inductor away from its capacitors.
- X1 is the original wired-battery connector, also screened at 5 mm. A committed
  wire-free contact design would remove/replace that branch, not retain both
  connectors by default. It remains in this unchanged-baseline comparison.
- J1 is the speaker connector. Its body/mated/lead envelope must clear the
  magnet and remain accessible; the current proxy is not a qualified mated model.
- Lower parts near the magnet still need explicit vertical/radial clearance,
  vent access and routing/return-plane space.

Moving the entire PCB toward the handle to dodge tall parts reduces battery
space. The successful bare-PCBA print does not prove that speaker, battery,
contacts and carrier fit simultaneously.

## Keep battery alternatives open

For comparison, each cell body starts **1 mm above the handle-facing PCB
surface**. This is an assumption, not a real contact's installed height.
The report evaluates bare bodies plus uniform 0.5 and 1 mm clearance envelopes.
Those envelopes are sensitivities, not substitutes for spring travel, clip
geometry, electrical insulation, pouch expansion, leads or a capture cradle.

| Body / clearance comparison | Board at z20 | Board at z22 | Board at z24 |
|---|---|---|---|
| D16.8 x L34 compact 16340 body only | Fits; about 0.56 mm distance to shell | Fits; about 0.04 mm | Interferes |
| Same 16340 plus 1 mm uniform clearance | Interferes | Interferes | Interferes |
| Fenix ARB-L16-700UP published D16.8 x L35.5 body only | Slight interference (about 0.21 mm3) | Interferes | Interferes |
| Nominal D18 x L35 18350 body only | Interferes | Interferes | Interferes |
| 18 x 28 x 8 pouch placeholder plus 1 mm each face | Fits; about 1.94 mm to shell | Fits; about 1.43 mm | Fits; about 0.91 mm |
| 20 x 30 x 8 pouch placeholder plus 1 mm each face | Fits; about 0.60 mm to shell | Fits; about 0.09 mm | Interferes |

Distances here are shortest BRep distances to the modeled shell, not the
slightly different horizontal radial distances in the earlier analytic screen.
Rounded positive values are not allocated assembly tolerance. These rows only
describe battery-space comparisons; their corresponding board depths still
have the speaker conflicts above.

The compact 16340 size example comes from [KeepPower's RCR123A 800 mAh page](https://www.keeppower.com.cn/products_detail.php?id=635);
its required current capability is not qualified. The 18350 is a nominal
size-only example, **not** a protected/button-top maximum. Neither pouch
placeholder identifies a purchasable pack, capacity or discharge rating.

The Fenix ARB-L16-700UP is a separate, sourced higher-current candidate with
published 2.5 A stable output; it is **not** the smaller KeepPower envelope.
Its extra 1.5 mm length causes nominal interference even at z20 with the assumed
1 mm standoff. This does not prove it cannot fit a revised stack or the real
shell; it shows why cell/contact selection and PCB placement must be evaluated
together. No complete holder or terminal-charging approval is implied.

Keep both compact protected 16340 and suitably rated flat-pouch options active.
Screen actual cells for the existing >=2 A continuous plus transient-margin
target, cell-specific 4.2 V Li-ion charging and protection. Actual clip/cradle
height may eliminate the slim 16340 body-only margin. See the
[contact research](../../../docs/battery-contact-options.md) for sourced leads
and the limits of interpreting a CR123A holder designation.

## Flimsy parts: unresolved structural work, not a reprint request

The owner did not identify which other pieces were flimsy. The prior carrier's
long 1.2 x 2.5 mm rails, 0.8 mm seating tabs, 1.8 mm grille and unqualified
fastening scheme are review targets, **not identified failures**.

The next carrier should use short supported load paths, ribs/webs where the
actual cavity permits, positive PCB/speaker capture, a supported USB interface
and independent cell restraint. Compare ribbed/integrated cartridge geometry
against thin free-standing rails. More infill alone does not increase a thin
member's external section. Blindly thickening everything can lose the small
existing taper clearance, so no replacement carrier is issued yet.

Record the weak part names, failure locations, slicer orientation and measured
PCB insertion depth before changing the retaining structure. The existing
PLA prints are not qualified live-cell restraints or child-use hardware.

## Reproduce without changing the original print kit

From the repository root:

```powershell
python .\tools\screen_measured_speaker.py --freecad-cmd "$env:LOCALAPPDATA\Programs\FreeCAD 1.1\bin\FreeCADCmd.exe"
```

The default output is this dated subdirectory. The separate launcher uses
isolated temporary FreeCAD preferences, a 300-second timeout and a fresh
completion marker; there is no GUI, persistent background job or package install.
Its local `freecad-build.log` is Git-ignored.

To use this study's saved inputs, pass `--measurements`, `--placement` and
`--shell-parameters` with the corresponding snapshot files, and `--output` with
a different directory. The generator reuses the frozen original geometry
helpers but does not regenerate or modify the original print kit.

Original code and mechanical primitives are MIT-licensed under
[mechanical/LICENSE](../../LICENSE). Embedded electronics context retains the
[handbell hardware notices](../../../hardware/handbell/README.md) and applicable
CC BY-SA 3.0 terms. No manufacturer CAD, third-party print design or photo has
been copied. The three speaker-only models are original mechanical geometry;
the populated exports include the separately licensed electronics context.

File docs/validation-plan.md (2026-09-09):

# Validation and release evidence

This is a planned evidence matrix, not a report of completed measurements.
Target values are TBD in E01; each protocol must record setup, instruments,
uncertainty, hardware/firmware revisions, input conditions, results, and
disposition. Preserve measured versus calculated versus vendor-specified labels.

## Evidence matrix

| ID | Requirements | Measurement / review | Gate |
|---|---|---|---|
| V01 | R08-R12 | Inner shell profile, tolerance-aware speaker/cell/PCB stack and assembly sequence using actual samples | Before outline freeze |
| V02 | R15-R17 | Pinned source licenses, import fidelity, source-to-net and retained/removed block review | Before schematic freeze |
| V03 | R02-R07 | Power/USB/GPIO/flash/boot schematic review and individually resolved ERC findings | Before layout |
| V04 | R05, R22 | Cell datasheet/protection/polarity, current/voltage/temperature limits, safe retention and cutoff strategy | Before cell-powered prototype |
| V05 | R04, R13-R14 | Acoustic response/timbre, SPL at fixed distance, clipping/distortion, driver excursion and temperature at defined levels | Speaker and gain selection |
| V06 | R13-R14 | Idle hiss/noise with stated bandwidth/distance, startup/shutdown clicks, USB/no-USB transitions, reload/reset, low battery | Audio/power design selection |
| V07 | R03, R06, R13, R25 | Strike-to-sound latency/jitter, repeated strokes, missed/false strikes and false damping; compare gyro-enabled/disabled chest-stop/rest recognition on the same motion corpus | Firmware and sensor selection |
| V08 | R05, R13 | Ready/play/sleep/off currents, peak current, actual runtime under a stated duty cycle, wake/first-strike behavior | Battery/power-mode selection |
| V09 | R05, R07 | USB-only/battery-only/combined operation, cable/source limits, unplug/replug, charger termination and thermal behavior | Before permitting play while charging |
| V10 | R07-R12, R22 | USB mating/load path, speaker/cell retention, cable abrasion, screw intrusion, metal insulation, shake/drop serviceability | Before educational pilot |
| V11 | R11-R12, R18-R19 | DRC, stackup, 3D clearances, footprints, BOM availability, panel/CPL preview and vendor acceptance | Before fabrication order |
| V12 | R02-R07 | Board bring-up: current-limited input, rails, recovery/programming, I2C/interrupt, I2S, speaker, protection/status functions | Before enclosing custom PCB |
| V13 | R16, R20, R23 | Reproducible export/install/recovery, attribution, complete kit instructions, assembly time and fault diagnosis | Release candidate |
| V14 | R13, R18, R22-R23 | Intended age/use classification, sound exposure, battery access, small parts, edges and appropriate compliance review | Before distribution to children |

## First bench procedure

### September 9 partial mechanical evidence

The [measured-speaker study](../mechanical/studies/2026-09-09-measured-speaker/README.md)
records owner-measured speaker stations and qualitative print feedback. This
advances V01 but does not close it: no shell-depth profile, inserted-PCB depth,
complete terminal/vent/tolerance envelope or assembled cell/contact/carrier fit
has been established. Some other printed pieces were reported flimsy without
identifying the pieces or failure locations; V10 remains open.

For the proposed speaker-facing PCB, record the IMU axes relative to the bell
and the final cell mass/location before gesture collection. A physical PCB
flip changes that transform; do not reuse orientation assumptions silently.
For a removable contact-mounted cell, include contact resistance/voltage drop,
momentary contact loss and reset behavior, independent mechanical capture,
wrapper/metal-can insulation and reverse-insertion protection in V04/V08/V10.
Do not treat a contact's catalog current rating as shake/drop or system approval.

### Electrical and acoustic bench work

Start with the integrated reference board and a current-limited bench supply,
then a documented compatible protected cell only after its limits are reviewed.
Confirm speaker impedance and BTL wiring before enabling audio. Compare a small
set of licensed/generated sounds at controlled levels. Record supply, load,
gain, digital level, cavity geometry, microphone distance, and motion behavior.

Use a shared time reference for motion/trigger and sound-onset measurement;
software timestamps alone do not establish acoustic latency. Report repeated
measurements and tails of the latency distribution, not only one best case.
Measure both quiet readiness and wake-from-sleep behavior.

Use differential/appropriately isolated measurement techniques for class-D
outputs. Neither speaker lead is ground; do not attach an earth-grounded
oscilloscope clip to a BTL output.

## Battery and child-use gates

A charger copied from a reference board is not a complete cell safety design.
The MCP73831's die thermal regulation does not measure pouch-cell temperature.
Set current and temperature handling from the selected cell manufacturer, not a
universal "1C" rule. Review input limits, charger dissipation, pack protection,
charging termination, and cutoff under actual system loads.

If playing while charging is deferred, specify and verify how the restriction
is enforced. That restriction does not eliminate cell-temperature, access, or
charging-safety requirements. Do not deliberately short, puncture, overcharge,
heat, or otherwise abuse live cells for informal project experiments.

Educational intent does not establish product safety. Plan adult/tool-controlled
cell access, captive parts, insulated edges, and assessment of parts released
by foreseeable use or drops. Determine applicable classification with a
qualified reviewer before child-use distribution.
US references include [CPSC toy guidance](https://www.cpsc.gov/Business--Manufacturing/Business-Education/Toy-Safety)
and [small-parts guidance](https://www.cpsc.gov/Business--Manufacturing/Business-Education/Business-Guidance/Small-Parts-for-Toys-and-Childrens-Products);
the applicable rules depend on the actual product, age group, and market.

## Evidence storage

At implementation, keep reviewed reports and small non-identifying measurement
datasets with the project; attach large raw files to versioned releases or an
identified durable store. Record file hashes and the analysis procedure.
Never publish personal participant data. Link each result and unresolved
anomaly from the owning epic; do not close a gate solely because a checklist
was generated.

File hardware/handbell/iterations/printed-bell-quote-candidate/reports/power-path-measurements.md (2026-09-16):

# Quote-candidate actual-copper path measurements

**Screening only; copper-drop targets remain NOT_DEMONSTRATED.**
A connected row has a finite sampled copper walk, not a measured/equivalent resistance. OPEN or native-short cases have no invented round-trip total.

Candidate PCB SHA-256: `2d88301f48ad05dc01384b90111f16615f176a7f4704eab82a1e3560ef5c8bc0`
Source PCB SHA-256: `6132f8d3ec508f8ae023888052cc2a1f8b2c24f2c38d9d12dca3234ba887dcc1`
Analyzer SHA-256: `c378834e3138ac1138a0f36acbb072ece348158a1b2cbeb8440f4b13de2b820f`
KiCad `10.0.6`; Python `3.11.9`; numpy `2.4.2`. E04/#4, E05/#5, E07/#7.

Bound native review: **INCOMPLETE routing; quotation/fabrication BLOCKED**; 0 checker errors; 59 unconnected items.
Native report input/tool hashes and full findings remain in the JSON. This measurement does not replace or waive completion-review.json/md.

With an F-ground fill, GND connectivity uses actual filled islands but its walk, neck and resistance values are NOT MODELED. Nonground copper is still measured; no track-only return estimate or invented whole-loop budget is assigned to the plane.

## Connected current corridors

| Path | Status / layer | XY incl. pad travel (mm) | Barrels | Min. strip width (mm) | Nominal chosen-strip (mOhm) |
|---|---|---:|---:|---:|---:|
| BT1.1 -> Q3.3 | CONNECTED_CHOSEN_WALK / F.Cu/B.Cu | 11.6 | 1 | 0.035 | 12 |
| Q3.2 -> Q1.2 | CONNECTED_CHOSEN_WALK / F.Cu/B.Cu | 2.24 | 0 | 0.3 | 2 |
| Q1.3 -> L1.P$1 | CONNECTED_CHOSEN_WALK / F.Cu/B.Cu | 7.06 | 0 | 0.75 | 3.1 |
| U5.4 -> R27.2 | NOT_MODELED_FILLED_GND_NETWORK / F.Cu/B.Cu | - | - | - | - |
| R27.1 -> Q5.A2 | CONNECTED_CHOSEN_WALK / F.Cu/B.Cu | 4.47 | 2 | 0.018 | 22 |
| R27.1 -> Q5.C2 | CONNECTED_CHOSEN_WALK / F.Cu/B.Cu | 6.74 | 2 | 0.018 | 26 |
| Q5.A1 -> BT2.1 | CONNECTED_CHOSEN_WALK / F.Cu/B.Cu | 15.6 | 1 | 0.082 | 21 |
| Q5.C1 -> BT2.1 | CONNECTED_CHOSEN_WALK / F.Cu/B.Cu | 13 | 1 | 0.018 | 21 |
| C28.1 -> C19.1 | CONNECTED_CHOSEN_WALK / F.Cu/B.Cu | 25.8 | 0 | 0.13 | 27 |
| C28.1 -> U4.7 | CONNECTED_CHOSEN_WALK / F.Cu/B.Cu | 28.4 | 0 | 0.13 | 32 |
| C28.1 -> U4.8 | CONNECTED_CHOSEN_WALK / F.Cu/B.Cu | 27.9 | 0 | 0.13 | 30 |
| U4.THERMAL -> C27.2 | NOT_MODELED_FILLED_GND_NETWORK / F.Cu/B.Cu | - | - | - | - |
| U4.11 -> C27.2 | NOT_MODELED_FILLED_GND_NETWORK / F.Cu/B.Cu | - | - | - | - |
| C19.2 -> C27.2 | NOT_MODELED_FILLED_GND_NETWORK / F.Cu/B.Cu | - | - | - | - |
| C19.1 -> U4.7 | CONNECTED_CHOSEN_WALK / F.Cu/B.Cu | 2.89 | 0 | 0.17 | 5.6 |
| C19.1 -> U4.8 | CONNECTED_CHOSEN_WALK / F.Cu/B.Cu | 2.44 | 0 | 0.24 | 3.9 |
| U4.THERMAL -> C19.2 | NOT_MODELED_FILLED_GND_NETWORK / F.Cu/B.Cu | - | - | - | - |
| U5.5 -> L1.P$2 | CONNECTED_CHOSEN_WALK / F.Cu/B.Cu | 6.13 | 0 | 0.2 | 6.6 |
| C26.1 -> L1.P$1 | CONNECTED_CHOSEN_WALK / F.Cu/B.Cu | 3.9 | 0 | 1.1 | 1.3 |
| C26.2 -> U5.4 | NOT_MODELED_FILLED_GND_NETWORK / F.Cu/B.Cu | - | - | - | - |
| C26.1 -> U5.3 | CONNECTED_CHOSEN_WALK / F.Cu/B.Cu | 8.93 | 0 | 0.04 | 42 |
| R24.2 -> C28.2 | NOT_MODELED_FILLED_GND_NETWORK / F.Cu/B.Cu | - | - | - | - |
| R26.2 -> R27.2 | NOT_MODELED_FILLED_GND_NETWORK / F.Cu/B.Cu | - | - | - | - |
| U4.11 -> U4.THERMAL | NOT_MODELED_FILLED_GND_NETWORK / F.Cu/B.Cu | - | - | - | - |
| U5.6 -> C27.1 | CONNECTED_CHOSEN_WALK / F.Cu | 2.23 | 0 | 0.3 | 2.2 |
| C27.2 -> U5.4 | NOT_MODELED_FILLED_GND_NETWORK / F.Cu | - | - | - | - |
| U5.6 -> C28.1 | CONNECTED_CHOSEN_WALK / F.Cu | 4.32 | 0 | 0.3 | 3.5 |
| C28.2 -> U5.4 | NOT_MODELED_FILLED_GND_NETWORK / F.Cu | - | - | - | - |

## Paired copper-only budgets

| Conditional loop | Case (A) | Nominal / 1.35x drop (mV) | Budget at target current | Result |
|---|---:|---:|---:|---|
| cell_via_a2_a1 | - | - | 50 mV @ 2 A | NOT_DEMONSTRATED: OPEN or unmeasured section: no numerical round-trip total is reported |
| cell_via_a2_c1 | - | - | 50 mV @ 2 A | NOT_DEMONSTRATED: OPEN or unmeasured section: no numerical round-trip total is reported |
| cell_via_c2_a1 | - | - | 50 mV @ 2 A | NOT_DEMONSTRATED: OPEN or unmeasured section: no numerical round-trip total is reported |
| cell_via_c2_c1 | - | - | 50 mV @ 2 A | NOT_DEMONSTRATED: OPEN or unmeasured section: no numerical round-trip total is reported |
| 5V_amp7_thermal | - | - | 100 mV @ 1 A | NOT_DEMONSTRATED: OPEN or unmeasured section: no numerical round-trip total is reported |
| 5V_amp7_11 | - | - | 100 mV @ 1 A | NOT_DEMONSTRATED: OPEN or unmeasured section: no numerical round-trip total is reported |
| 5V_amp8_thermal | - | - | 100 mV @ 1 A | NOT_DEMONSTRATED: OPEN or unmeasured section: no numerical round-trip total is reported |
| 5V_amp8_11 | - | - | 100 mV @ 1 A | NOT_DEMONSTRATED: OPEN or unmeasured section: no numerical round-trip total is reported |
| 5V_bulk_capacitor_endpoints | - | - | 100 mV @ 1 A | NOT_DEMONSTRATED: OPEN or unmeasured section: no numerical round-trip total is reported |

Cell Q5 alternatives are separate whole-current chosen walks, never parallel sums or equal-sharing claims. 3 A is sensitivity, not an approved operating current. An above-budget chosen strip does not prove the actual parallel-copper network fails; a below-budget strip does not qualify it.

Contacts and FET losses are unknown and excluded. The separate nominal 33 mOhm shunt alone adds 66 mV at 2 A or 99 mV at 3 A, before tolerance/temperature.

## Boost capacitor native source-to-candidate comparison

| Capacitor | Source paired XY / vias | Candidate paired XY / vias | Native all-F source -> candidate | Candidate rough all-F area |
|---|---:|---:|---|---:|
| C27 | 4.46 mm / 0 | NOT_DEMONSTRATED | True -> True | not meaningful/available |
| C28 | 8.63 mm / 0 | NOT_DEMONSTRATED | True -> True | not meaningful/available |

Loop lengths include finite pad travel; they are not the frozen review's pad-as-region numbers. Area is only a simple all-F walk polygon with straight IC/capacitor pin closures, not an inductance model. Each capacitor is separate; capacitances/parallel branches are not added.

## Exposed fine copper

| Native pad-adjacent inventory | Minimum exposed width (mm) | Total drawn (mm) | Uncovered centerline (mm) |
|---|---:|---:|---:|
| U5_SW_minimum_escape | 0.2 | 2.13 | 1.21 |
| output_VAMP_small_pin_exits | 0.3 | 0.815 | 0.09 |
| Q5_pad_adjacent_fine_including_bias_branches | 0.1778 | 2.95 | 1.15 |

Lengths here are inventories, not series resistance. The JSON contains exact native owners, covered/exposed intervals, actual narrow pieces on each selected main walk, and conditional currents. Pad/annulus/broader-trace coverage is subtracted; drilled-out centerline is not counted as copper. R24/R26/VIN bias and ripple branches have no automatic 2 A load.

## Counts and unresolved gates

Candidate: {'physical_pads': 325, 'tracks': 1124, 'vias': 87, 'physical_net_islands': 145, 'multi_pad_nets_not_complete': 27}. Source: {'physical_pads': 325, 'tracks': 674, 'vias': 35, 'physical_net_islands': 241, 'multi_pad_nets_not_complete': 49}.
Candidate native shape shorts: 0; geometry-walk diagnostics: 1.
The complete diagnostic and input-hash inventories are in the JSON. Native shape connectivity is not DRC; USB findings, clearance/short findings, residual islands and native-review gates remain visible.

## Method and assumptions

- Native KiCad copper, not authored route groups, owns connectivity and path selection.
- Track/pad/via walks are supported. With the checked F-ground fill, only nonground walks/neck estimates are evaluated; filled GND connectivity is native but its resistance is not modeled.
- Native inward copper polygons and outward drill polygons use a 1 nm polygonization bound; positive-width walk contacts use a 2 nm numerical guard. Boundary-only contact is not a usable walk.
- Dijkstra minimizes XY walk length plus 1.6 mm per layer transition on a finite portal graph. It is not the exact geometric shortest path, least-resistance path, or a 2-D current solution.
- An identical-XY overlap join has zero length; travel across a pad or between different contacts does not. Separate physical pads sharing a pin number are never internally shorted.
- Foil screening uses rho*L/(w*t). Each <=0.25 mm walk slice uses an inscribed strip width equal to twice its minimum distance to the same-net copper-union boundary, including holes.
- These restrictive chosen-strip estimates intentionally ignore parallel current redistribution. They can overstate drop; bends, junction spreading, barrel entry crowding, terminal injection and overlapping strips prevent calling them a rigorous upper bound or equivalent resistance.
- Neck inventory subtracts actual same-net pad, via-annulus and strictly broader-track coverage from drawn centerlines. Coverage is not proof of full-width bypass or absence of a 2-D bottleneck.
- A chosen-path current is a conditional load case, not a measured branch current. Bias, sense, feedback and capacitor-ripple spurs receive no blanket 2 A assignment.
- Nominal foil is assumed 35 um/20 C. The requested 30 um/60 C sensitivity is 1.35x nominal. 60 C is a calculation case, not an allowed cell/enclosure temperature.
- Via DCR uses thin-wall rho*board_thickness/(pi*drill*wall), conditional on 25 um wall plating and 1.6 mm board thickness. Neither plating nor finished copper is selected/qualified.
- Each selected barrel is charged once per traversal at its full conditional DCR. No equal sharing, parallel Q5 via division, or thermal-via-array resistance reduction is assumed.
- JSON decimal places preserve computational reproducibility, not measurement accuracy. Markdown resistance/drop screens are intentionally shown to about two significant digits.
- A barrel edge is a lumped annulus-to-annulus connection, not a vertical copper column at the reported annular XY port; its entry/exit spreading is not solved.
- Cell copper sections are concatenated only conditionally across the excluded ON-state selector/audio/protector FETs, shunt and converter. No copper edge bridges different nets.
- Copper budgets exclude contacts, solder interfaces, FETs, the deliberate 33 mOhm shunt, inductor winding, IC internals and capacitor ESR. These are separate additional losses.
- No IPC-2152 or 10 C temperature-rise claim, ampacity, functional, fault, charging, fabrication, mechanical, live-cell or child-use signoff follows. Native diagnostics remain release gates.
- The actual final native file, not intended SES groups or former via positions, owns the result. Bias/sense tracks are classified by physical endpoints and chosen-walk ownership.
- Two off-pad return vias, when present, are inventoried individually. Neither their presence nor four outside Q5 fanouts establishes equal current division or final network performance.

Inputs were hash-checked before and after the calculation; this is not a cross-process generator lock. Rerun only after a coherent final build. These reports do not alter the parent-owned review. The measurement JSON SHA-256 embedded below pairs these two outputs.

Measurement JSON SHA-256: `3e92ab84ce5eb989d6ddf1c3f6ebce2fe521989f444544101c3d74e819f5e5bb`

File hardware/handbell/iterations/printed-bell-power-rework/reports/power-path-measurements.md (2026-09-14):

# Printed-bell actual-copper path measurements

**Screening only; copper-drop targets remain NOT_DEMONSTRATED.**
A connected row has a finite sampled copper walk, not a measured/equivalent resistance. OPEN rows have no invented round-trip total.

Candidate PCB SHA-256: `6132f8d3ec508f8ae023888052cc2a1f8b2c24f2c38d9d12dca3234ba887dcc1`
Source PCB SHA-256: `075c7b7cb0a98e302af29f5985bbf020111df5b1be385e5ebfa61be236b04250`
Analyzer SHA-256: `c48f73a438e5bc9a81d5e26437a3ce9f5f0ce4b61e82e17ddf6480bbaa4da6cf`
KiCad `10.0.6`; Python `3.11.9`; numpy `2.2.6`. E04/#4, E05/#5, E07/#7.

## Connected current corridors

| Path | Status | XY incl. pad travel (mm) | Barrels | Nominal chosen-strip (mOhm) |
|---|---|---:|---:|---:|
| BT1.1 -> Q3.3 | CONNECTED_CHOSEN_WALK | 16.9 | 1 | 13 |
| Q3.2 -> Q1.2 | CONNECTED_CHOSEN_WALK | 29.6 | 2 | 37 |
| Q1.3 -> L1.P$1 | OPEN | - | - | - |
| U5.4 -> R27.2 | CONNECTED_CHOSEN_WALK | 18.5 | 2 | 20 |
| R27.1 -> Q5.A2 | CONNECTED_CHOSEN_WALK | 3.89 | 2 | 13 |
| R27.1 -> Q5.C2 | CONNECTED_CHOSEN_WALK | 6.15 | 2 | 15 |
| Q5.A1 -> BT2.1 | CONNECTED_CHOSEN_WALK | 15.5 | 1 | 22 |
| Q5.C1 -> BT2.1 | CONNECTED_CHOSEN_WALK | 12.9 | 1 | 21 |
| C28.1 -> C19.1 | CONNECTED_CHOSEN_WALK | 25.9 | 0 | 20 |
| C28.1 -> U4.7 | CONNECTED_CHOSEN_WALK | 28.5 | 0 | 24 |
| C28.1 -> U4.8 | CONNECTED_CHOSEN_WALK | 28 | 0 | 23 |
| U4.THERMAL -> C27.2 | CONNECTED_CHOSEN_WALK | 37.7 | 2 | 45 |
| U4.11 -> C27.2 | CONNECTED_CHOSEN_WALK | 38.5 | 2 | 53 |
| C19.2 -> C27.2 | CONNECTED_CHOSEN_WALK | 31.3 | 0 | 22 |
| U5.5 -> L1.P$2 | CONNECTED_CHOSEN_WALK | 6.13 | 0 | 6.6 |
| C26.1 -> L1.P$1 | CONNECTED_CHOSEN_WALK | 3.9 | 0 | 1.3 |
| C26.1 -> U5.3 | CONNECTED_CHOSEN_WALK | 8.93 | 0 | 42 |
| R24.2 -> C28.2 | CONNECTED_CHOSEN_WALK | 11.9 | 2 | 56 |
| R26.2 -> R27.2 | CONNECTED_CHOSEN_WALK | 1.69 | 0 | 3.6 |
| U4.11 -> U4.THERMAL | CONNECTED_CHOSEN_WALK | 1.57 | 0 | 10 |
| U5.6 -> C27.1 | CONNECTED_CHOSEN_WALK | 2.23 | 0 | 2.2 |
| C27.2 -> U5.4 | CONNECTED_CHOSEN_WALK | 2.23 | 0 | 2.2 |
| U5.6 -> C28.1 | CONNECTED_CHOSEN_WALK | 4.32 | 0 | 3.5 |
| C28.2 -> U5.4 | CONNECTED_CHOSEN_WALK | 4.32 | 0 | 3.3 |

## Paired copper-only budgets

| Conditional loop | Case (A) | Nominal / 1.35x drop (mV) | Budget at target current | Result |
|---|---:|---:|---:|---|
| cell_via_a2_a1 | - | - | 50 mV @ 2 A | NOT_DEMONSTRATED: cell_vplus |
| cell_via_a2_c1 | - | - | 50 mV @ 2 A | NOT_DEMONSTRATED: cell_vplus |
| cell_via_c2_a1 | - | - | 50 mV @ 2 A | NOT_DEMONSTRATED: cell_vplus |
| cell_via_c2_c1 | - | - | 50 mV @ 2 A | NOT_DEMONSTRATED: cell_vplus |
| 5V_amp7_thermal | 1 | 69 / 93 | 100 mV @ 1 A | WITHIN_CHOSEN_WALK_ONLY; target NOT_DEMONSTRATED |
| 5V_amp7_11 | 1 | 76 / 1e+02 | 100 mV @ 1 A | ABOVE_CHOSEN_WALK_ONLY; target NOT_DEMONSTRATED |
| 5V_amp8_thermal | 1 | 68 / 92 | 100 mV @ 1 A | WITHIN_CHOSEN_WALK_ONLY; target NOT_DEMONSTRATED |
| 5V_amp8_11 | 1 | 75 / 1e+02 | 100 mV @ 1 A | ABOVE_CHOSEN_WALK_ONLY; target NOT_DEMONSTRATED |
| 5V_bulk_capacitor_endpoints | 1 | 42 / 56 | 100 mV @ 1 A | WITHIN_CHOSEN_WALK_ONLY; target NOT_DEMONSTRATED |

Cell Q5 alternatives are separate whole-current chosen walks, never parallel sums or equal-sharing claims. 3 A is sensitivity, not an approved operating current. An above-budget chosen strip does not prove the actual parallel-copper network fails; a below-budget strip does not qualify it.

Contacts and FET losses are unknown and excluded. The separate nominal 33 mOhm shunt alone adds 66 mV at 2 A or 99 mV at 3 A, before tolerance/temperature.

## Boost capacitor native source-to-candidate comparison

| Capacitor | Source paired XY / vias | Candidate paired XY / vias | Native all-F source -> candidate | Candidate rough all-F area |
|---|---:|---:|---|---:|
| C27 | 7.99 mm / 2 | 4.46 mm / 0 | False -> True | 2.81 mm2 |
| C28 | 12.2 mm / 2 | 8.63 mm / 0 | False -> True | 6.56 mm2 |

Loop lengths include finite pad travel; they are not the frozen review's pad-as-region numbers. Area is only a simple all-F walk polygon with straight IC/capacitor pin closures, not an inductance model. Each capacitor is separate; capacitances/parallel branches are not added.

## Exposed fine copper

| Native pad-adjacent inventory | Minimum exposed width (mm) | Total drawn (mm) | Uncovered centerline (mm) |
|---|---:|---:|---:|
| U5_SW_minimum_escape | 0.2 | 2.13 | 1.21 |
| output_VAMP_small_pin_exits | 0.3 | 0.815 | 0.09 |
| output_GND_small_pin_exits | 0.3 | 0.815 | 0.09 |
| Q5_pad_adjacent_fine_including_bias_branches | 0.1778 | 3.88 | 1.69 |
| amplifier_small_ground_exits | 0.3 | 4.5 | 1.05 |

Lengths here are inventories, not series resistance. The JSON contains exact native owners, covered/exposed intervals, actual narrow pieces on each selected main walk, and conditional currents. Pad/annulus/broader-trace coverage is subtracted; drilled-out centerline is not counted as copper. R24/R26/VIN bias and ripple branches have no automatic 2 A load.

## Counts and unresolved gates

Candidate: {'physical_pads': 325, 'tracks': 674, 'vias': 35, 'physical_net_islands': 241, 'multi_pad_nets_not_complete': 49}. Source: {'physical_pads': 325, 'tracks': 921, 'vias': 38, 'physical_net_islands': 234, 'multi_pad_nets_not_complete': 47}.
Candidate native shape shorts: 0; geometry-walk diagnostics: 0.
The complete diagnostic and input-hash inventories are in the JSON. Native shape connectivity is not DRC; previous QSPI/GND losses, USB findings, unfinished routing and parent-review gates remain open.

## Method and assumptions

- Native KiCad copper, not authored route groups, owns connectivity and path selection.
- Only F.Cu/B.Cu straight tracks, native pads and through vias are supported; no zones/arcs.
- Native inward copper polygons and outward drill polygons use a 1 nm polygonization bound; positive-width walk contacts use a 2 nm numerical guard. Boundary-only contact is not a usable walk.
- Dijkstra minimizes XY walk length plus 1.6 mm per layer transition on a finite portal graph. It is not the exact geometric shortest path, least-resistance path, or a 2-D current solution.
- An identical-XY overlap join has zero length; travel across a pad or between different contacts does not. Separate physical pads sharing a pin number are never internally shorted.
- Foil screening uses rho*L/(w*t). Each <=0.25 mm walk slice uses an inscribed strip width equal to twice its minimum distance to the same-net copper-union boundary, including holes.
- These restrictive chosen-strip estimates intentionally ignore parallel current redistribution. They can overstate drop; bends, junction spreading, barrel entry crowding, terminal injection and overlapping strips prevent calling them a rigorous upper bound or equivalent resistance.
- Neck inventory subtracts actual same-net pad, via-annulus and strictly broader-track coverage from drawn centerlines. Coverage is not proof of full-width bypass or absence of a 2-D bottleneck.
- A chosen-path current is a conditional load case, not a measured branch current. Bias, sense, feedback and capacitor-ripple spurs receive no blanket 2 A assignment.
- Nominal foil is assumed 35 um/20 C. The requested 30 um/60 C sensitivity is 1.35x nominal. 60 C is a calculation case, not an allowed cell/enclosure temperature.
- Via DCR uses thin-wall rho*board_thickness/(pi*drill*wall), conditional on 25 um wall plating and 1.6 mm board thickness. Neither plating nor finished copper is selected/qualified.
- Each selected barrel is charged once per traversal at its full conditional DCR. No equal sharing, parallel Q5 via division, or thermal-via-array resistance reduction is assumed.
- JSON decimal places preserve computational reproducibility, not measurement accuracy. Markdown resistance/drop screens are intentionally shown to about two significant digits.
- A barrel edge is a lumped annulus-to-annulus connection, not a vertical copper column at the reported annular XY port; its entry/exit spreading is not solved.
- Cell copper sections are concatenated only conditionally across the excluded ON-state selector/audio/protector FETs, shunt and converter. No copper edge bridges different nets.
- Copper budgets exclude contacts, solder interfaces, FETs, the deliberate 33 mOhm shunt, inductor winding, IC internals and capacitor ESR. These are separate additional losses.
- No IPC-2152 or 10 C temperature-rise claim, ampacity, functional, fault, fabrication, mechanical, live-cell or child-use signoff follows. Prior QSPI/GND losses are not waived.

Inputs were hash-checked before and after the calculation; this is not a cross-process generator lock. Rerun only after a coherent final build. These reports do not alter the parent-owned review.

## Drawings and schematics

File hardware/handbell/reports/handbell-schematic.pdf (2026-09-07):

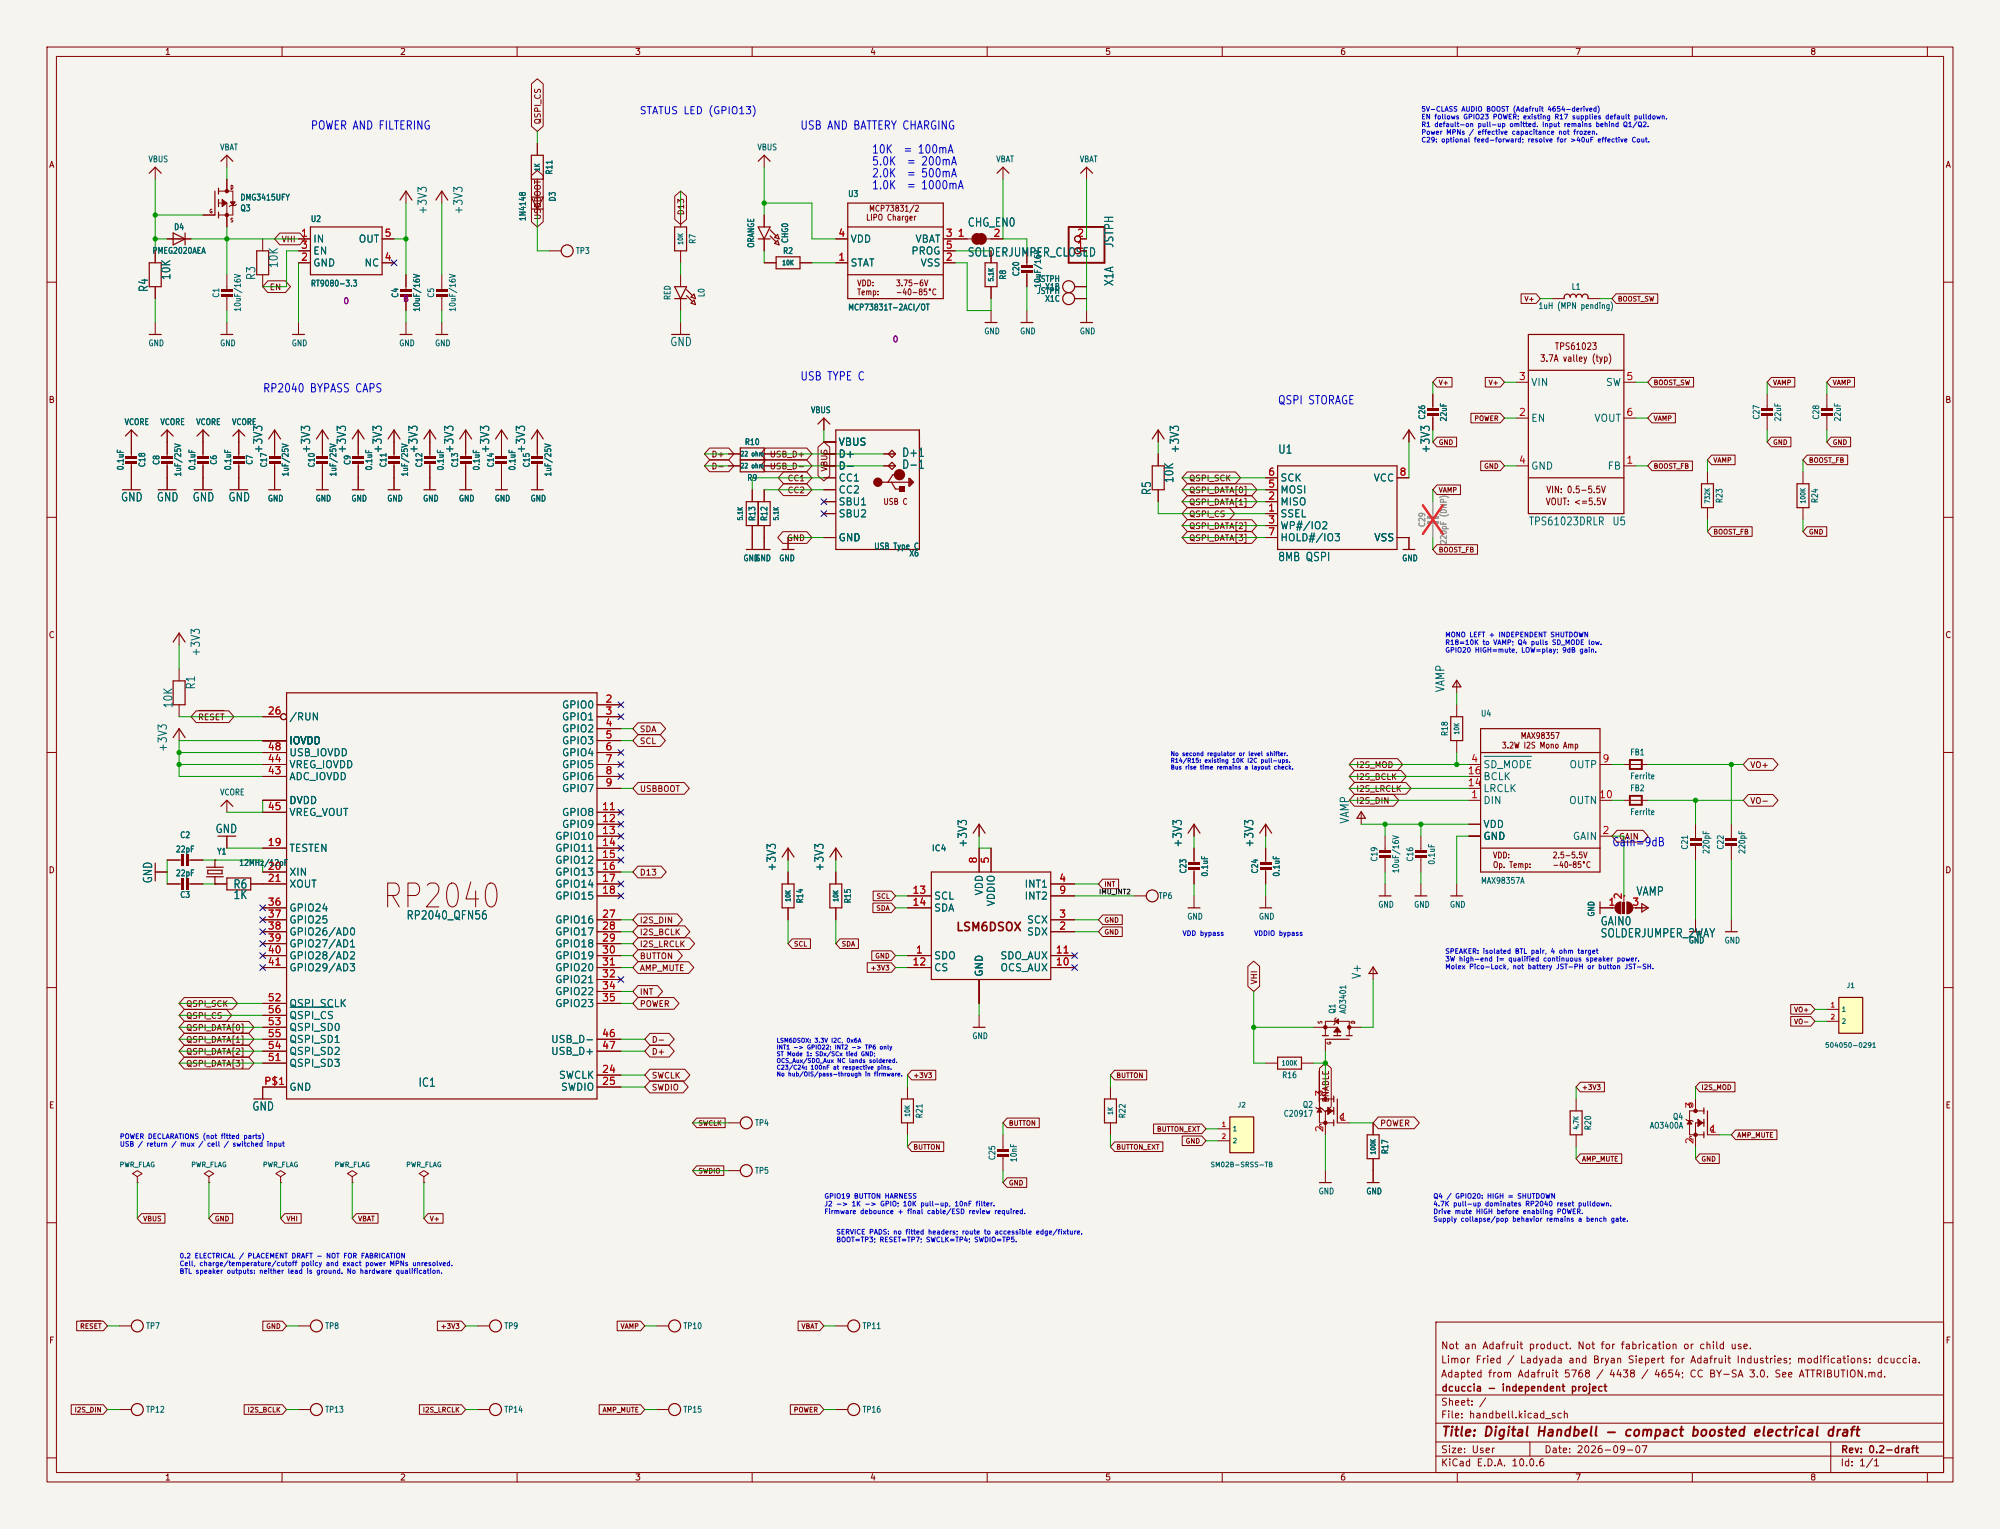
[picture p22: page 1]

5V-CLASS AUDIO BOOST (Adafruit 4654-derived) EN follows GPIO23 POWER; existing R17 supplies default pulldown. R1 default-on pull-up omitted. Input remains behind Q1/Q2. Power MPNs / effective capacitance not frozen. C29: optional feed-forward; resolve for >40uF effective Cout. STATUS LED (GPIO13)

Not an Adafruit product. Not for fabrication or child use. +3V3 +3V3

QSPI_DATA[1]
INT1 -> GPIO22; INT2 -> TP6 only ST Mode 1: SDx/SCx tied GND; OCS_Aux/SDO_Aux NC lands soldered. C23/C24: 100nF at respective pins. No hub/OIS/pass-through in firmware. 0.2 ELECTRICAL / PLACEMENT DRAFT - NOT FOR FABRICATION
QSPI_DATA[2]
QSPI_DATA[3]

POWER DECLARATIONS (not fitted parts) USB / return / mux / cell / switched input

GPIO19 BUTTON HARNESS
J2 -> 1K -> GPIO; 10K pull-up, 10nF filter. Firmware debounce + final cable/ESD review required.

4.7K pull-up dominates RP2040 reset pulldown. Drive mute HIGH before enabling POWER. Supply collapse/pop behavior remains a bench gate.

SERVICE PADS: no fitted headers; route to accessible edge/fixture. BOOT=TP3; RESET=TP7; SWCLK=TP4; SWDIO=TP5.

Cell, charge/temperature/cutoff policy and exact power MPNs unresolved. BTL speaker outputs: neither lead is ground. No hardware qualification.

Limor Fried / Ladyada and Bryan Siepert for Adafruit Industries; modifications: dcuccia.
Adapted from Adafruit 5768 / 4438 / 4654; CC BY-SA 3.0. See ATTRIBUTION.md.
dcuccia - independent project
Sheet: /
File: handbell.kicad_sch
Title: Digital Handbell - compact boosted electrical draft

Size: User | Rev: 0.2-draft
KiCad E.D.A. 10.0.6 | Id: 1/1

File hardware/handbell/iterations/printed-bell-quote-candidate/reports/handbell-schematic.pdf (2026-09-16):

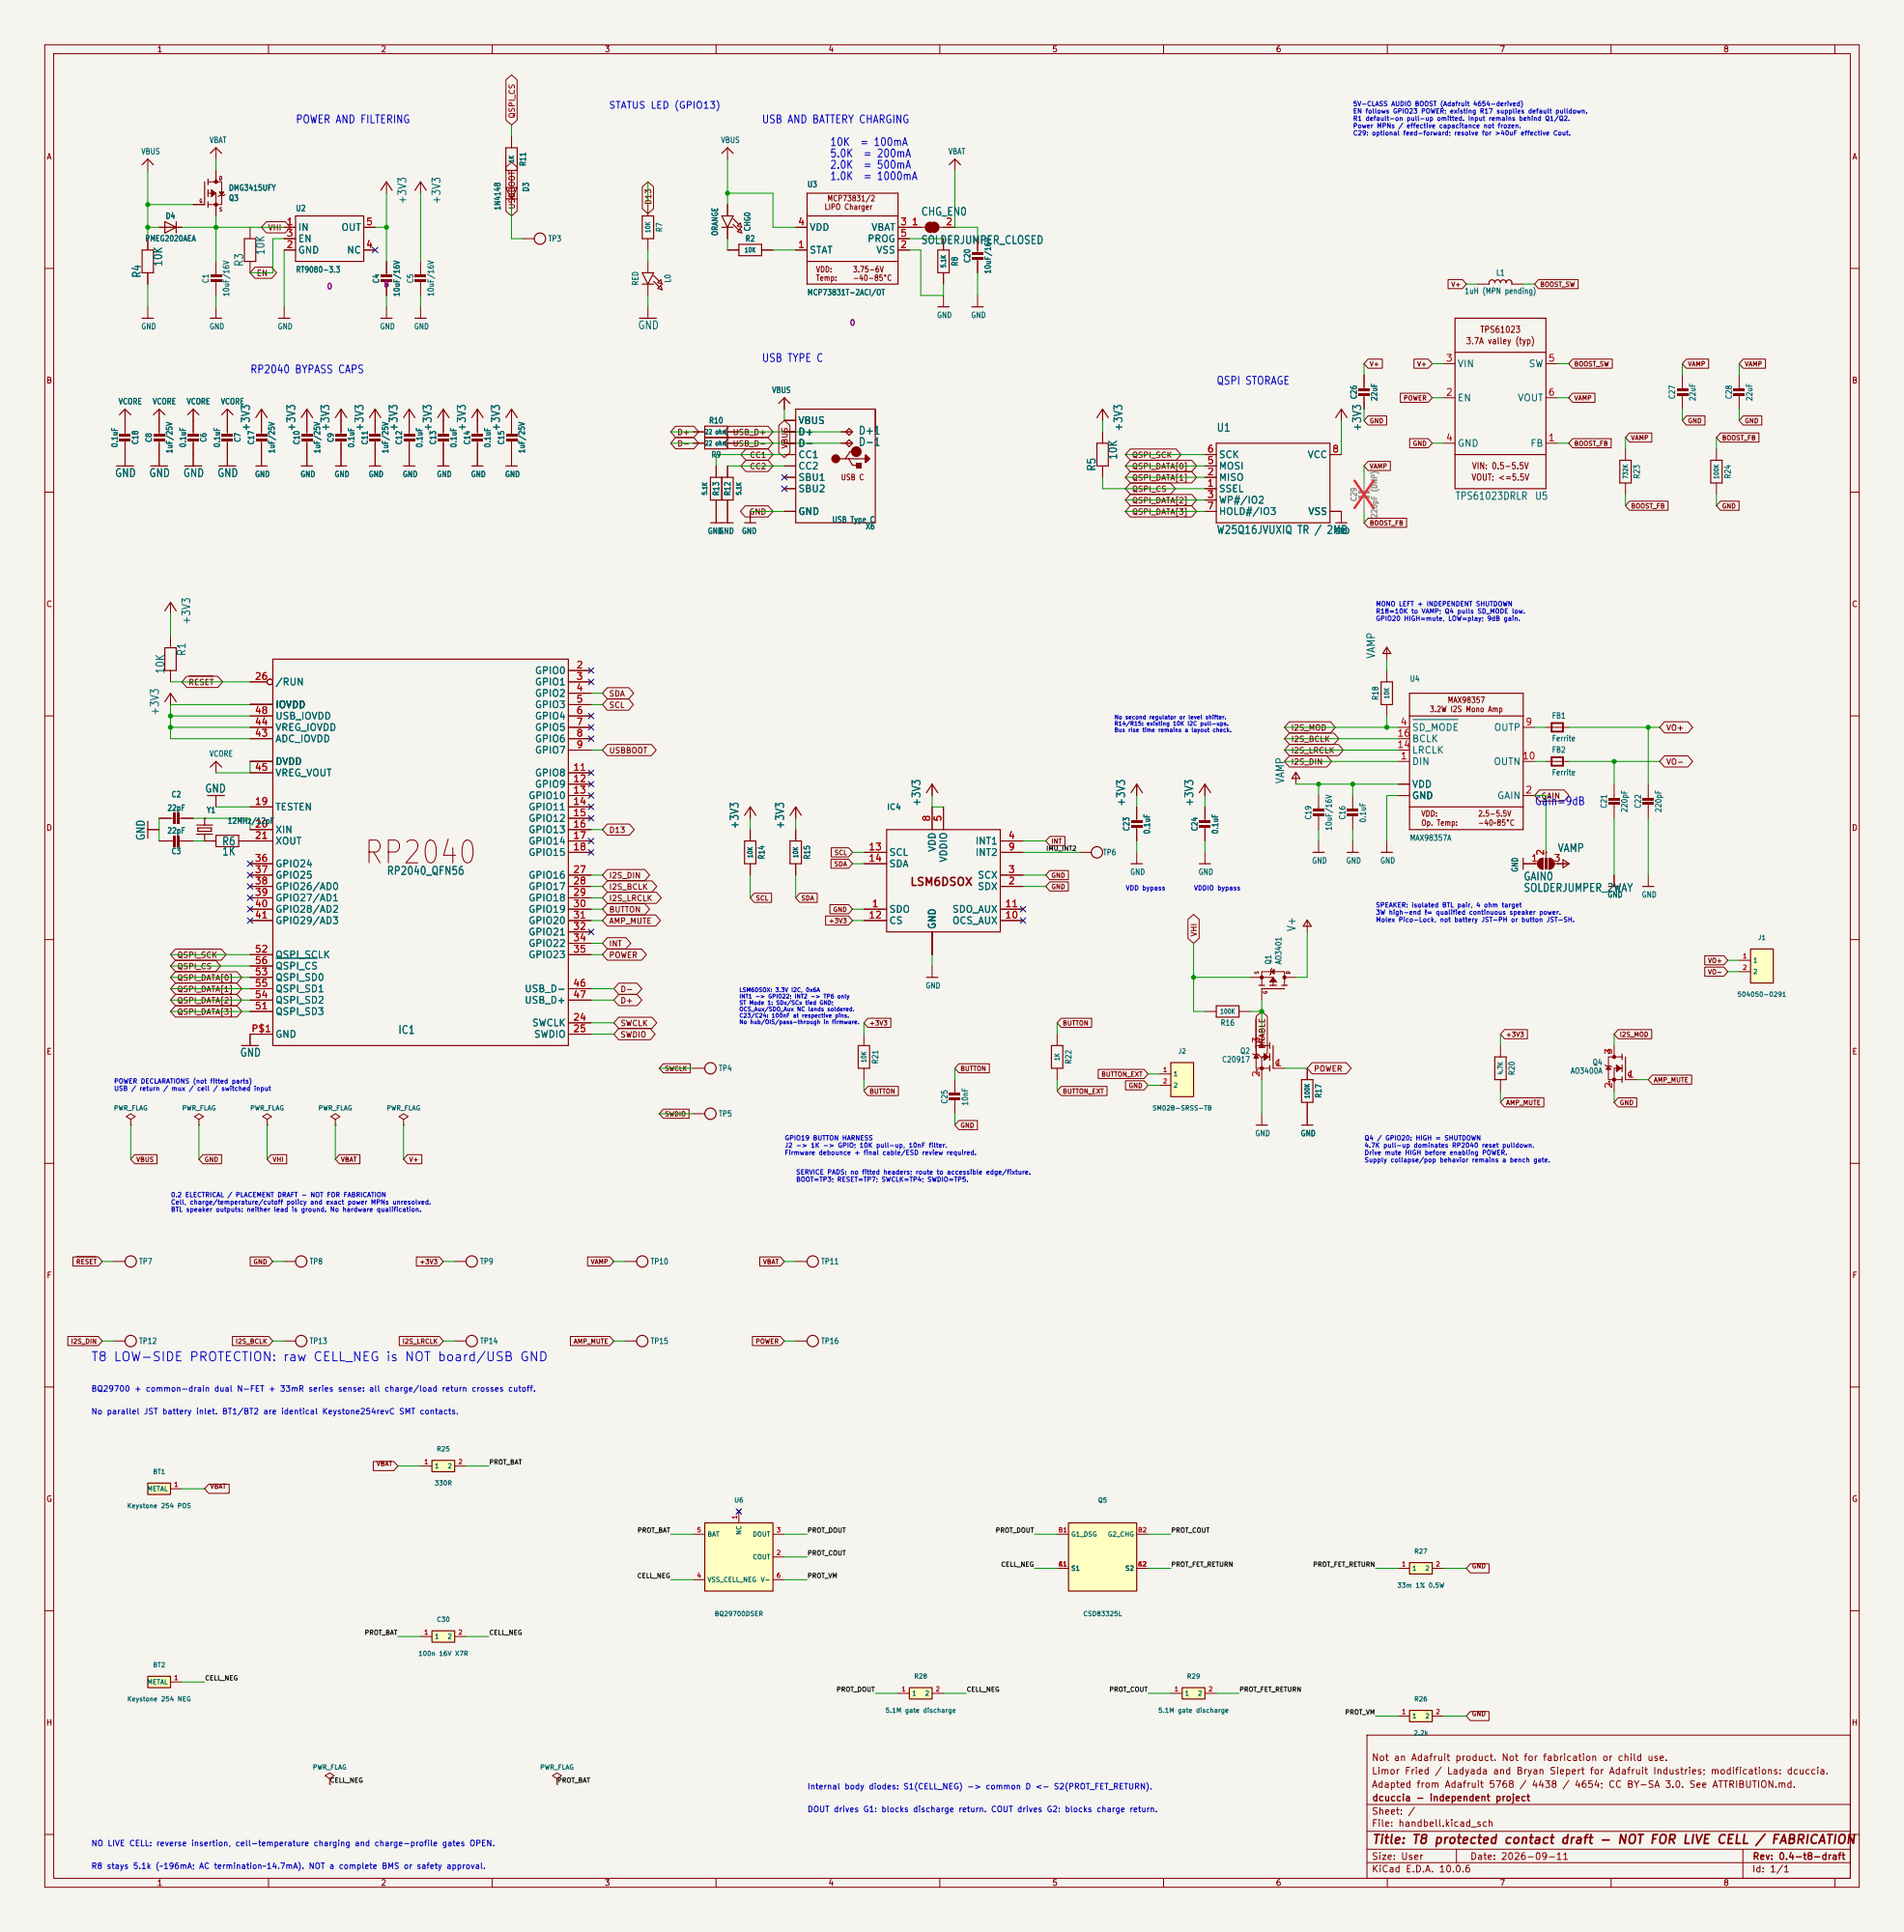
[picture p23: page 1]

5V-CLASS AUDIO BOOST (Adafruit 4654-derived) EN follows GPIO23 POWER; existing R17 supplies default pulldown. R1 default-on pull-up omitted. Input remains behind Q1/Q2. Power MPNs / effective capacitance not frozen. C29: optional feed-forward; resolve for >40uF effective Cout. U3MCP73831T-2ACI/OT 0 STAT 1

USB AND BATTERY CHARGING

R18=10K to VAMP; Q4 pulls SD_MODE low. GPIO20 HIGH=mute, LOW=play; 9dB gain. VDDIO bypass

MONO LEFT + INDEPENDENT SHUTDOWN
U4MAX98357A
VDD: Op. Temp: MAX98357
3.2W I2S Mono Amp 2.5-5.5V -40~85°C DIN 1
SD_MODE 4
LRCLK 14 BCLK 16

No second regulator or level shifter. R14/R15: existing 10K I2C pull-ups. Bus rise time remains a layout check.

INT1 -> GPIO22; INT2 -> TP6 only ST Mode 1: SDx/SCx tied GND; OCS_Aux/SDO_Aux NC lands soldered. C23/C24: 100nF at respective pins. No hub/OIS/pass-through in firmware. POWER DECLARATIONS (not fitted parts) USB / return / mux / cell / switched input

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

Q4 / GPIO20: HIGH = SHUTDOWN
4.7K pull-up dominates RP2040 reset pulldown. Drive mute HIGH before enabling POWER. Supply collapse/pop behavior remains a bench gate.

0.2 ELECTRICAL / PLACEMENT DRAFT - NOT FOR FABRICATION
Cell, charge/temperature/cutoff policy and exact power MPNs unresolved. BTL speaker outputs: neither lead is ground. No hardware qualification.

I2S_DIN
T8 LOW-SIDE PROTECTION: raw CELL_NEG is NOT board/USB GND

Not an Adafruit product. Not for fabrication or child use.
Limor Fried / Ladyada and Bryan Siepert for Adafruit Industries; modifications: dcuccia.
Adapted from Adafruit 5768 / 4438 / 4654; CC BY-SA 3.0. See ATTRIBUTION.md.
dcuccia - independent project
Sheet: /
File: handbell.kicad_sch
Title: T8 protected contact draft - NOT FOR LIVE CELL / FABRICATION

Internal body diodes: S1(CELL_NEG) -> common D <- S2(PROT_FET_RETURN).

DOUT drives G1: blocks discharge return. COUT drives G2: blocks charge return.

NO LIVE CELL: reverse insertion, cell-temperature charging and charge-profile gates OPEN. R8 stays 5.1k (~196mA; AC termination~14.7mA). NOT a complete BMS or safety approval.

Size: User | Rev: 0.4-t8-draft
KiCad E.D.A. 10.0.6 | Id: 1/1

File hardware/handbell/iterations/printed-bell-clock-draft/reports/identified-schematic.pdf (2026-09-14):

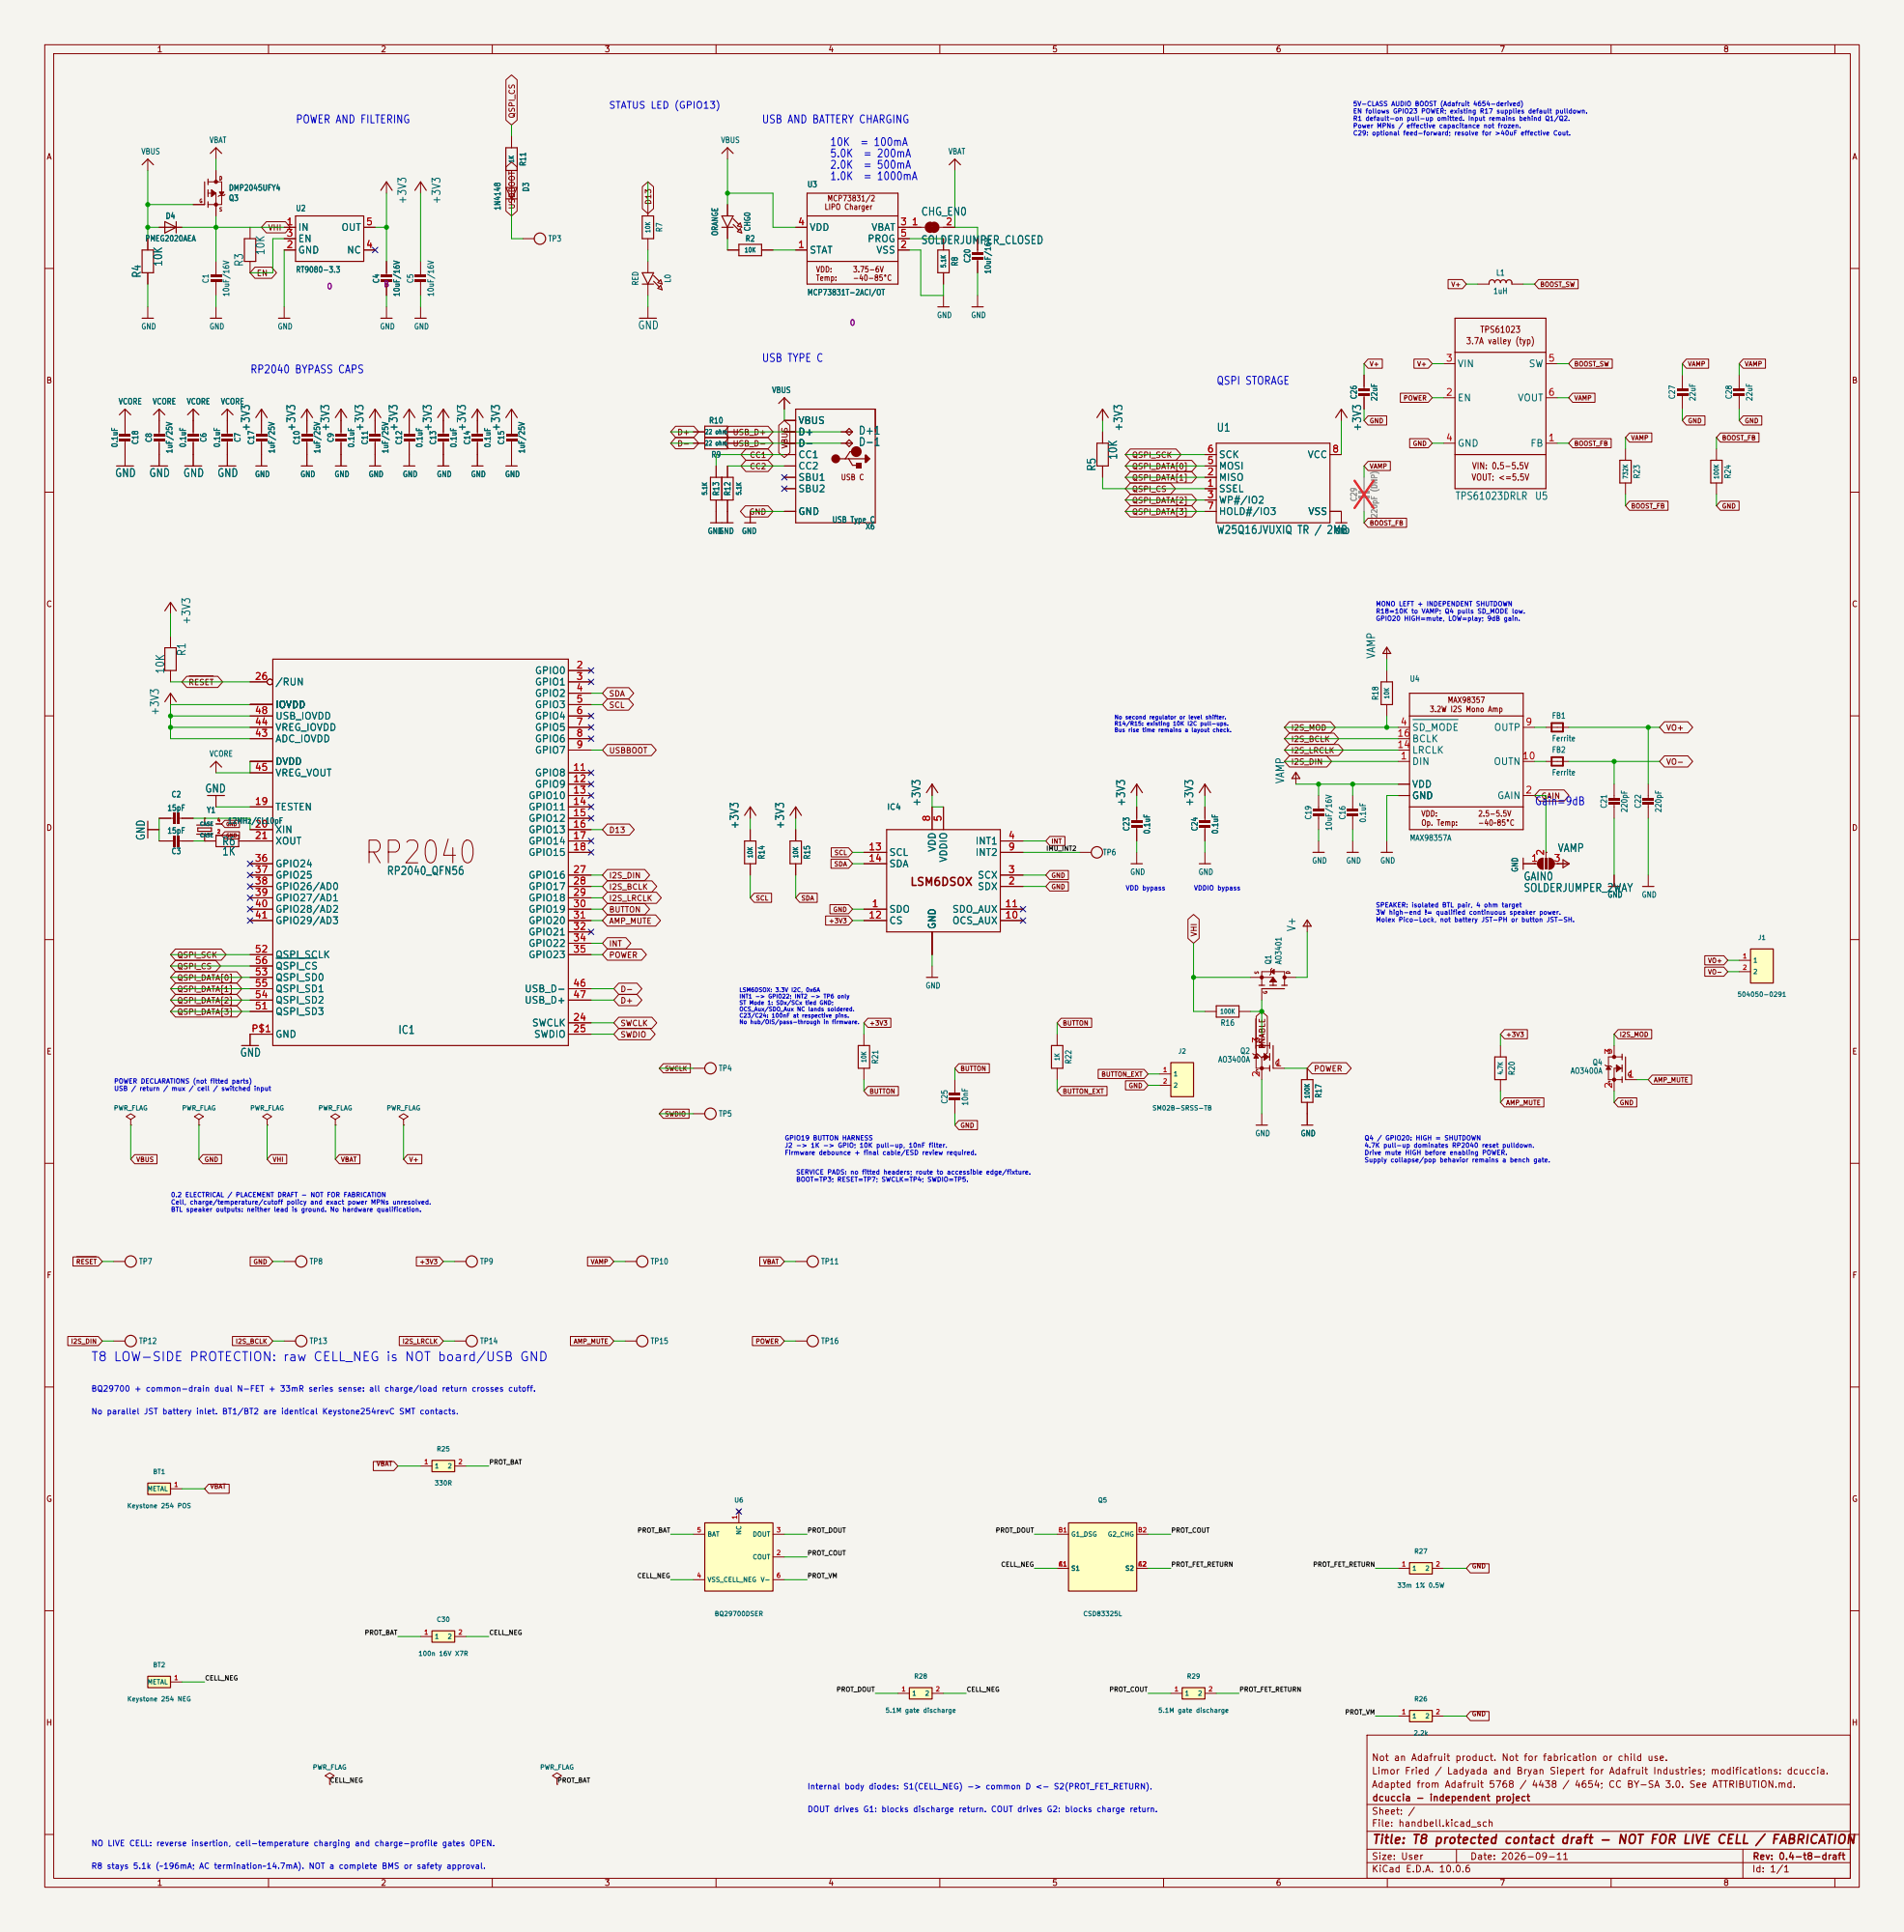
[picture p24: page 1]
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

USB AND BATTERY CHARGING

MONO LEFT + INDEPENDENT SHUTDOWN
R18=10K to VAMP; Q4 pulls SD_MODE low. GPIO20 HIGH=mute, LOW=play; 9dB gain.
U4MAX98357A
VDD: Op. Temp: MAX98357
3.2W I2S Mono Amp 2.5-5.5V -40~85°C DIN 1
SD_MODE 4
LRCLK 14 BCLK 16

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

SPEAKER: isolated BTL pair, 4 ohm target 3W high-end != qualified continuous speaker power. Molex Pico-Lock, not battery JST-PH or button JST-SH.

INT1 -> GPIO22; INT2 -> TP6 only ST Mode 1: SDx/SCx tied GND; OCS_Aux/SDO_Aux NC lands soldered. C23/C24: 100nF at respective pins. No hub/OIS/pass-through in firmware. T8 LOW-SIDE PROTECTION: raw CELL_NEG is NOT board/USB GND

4.7K pull-up dominates RP2040 reset pulldown. Drive mute HIGH before enabling POWER. Supply collapse/pop behavior remains a bench gate. POWER DECLARATIONS (not fitted parts) USB / return / mux / cell / switched input 0.2 ELECTRICAL / PLACEMENT DRAFT - NOT FOR FABRICATION

SERVICE PADS: no fitted headers; route to accessible edge/fixture. BOOT=TP3; RESET=TP7; SWCLK=TP4; SWDIO=TP5. GPIO19 BUTTON HARNESS
J2 -> 1K -> GPIO; 10K pull-up, 10nF filter. Firmware debounce + final cable/ESD review required.

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

BQ29700 + common-drain dual N-FET + 33mR series sense: all charge/load return crosses cutoff.

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

Internal body diodes: S1(CELL_NEG) -> common D <- S2(PROT_FET_RETURN).

DOUT drives G1: blocks discharge return. COUT drives G2: blocks charge return.

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

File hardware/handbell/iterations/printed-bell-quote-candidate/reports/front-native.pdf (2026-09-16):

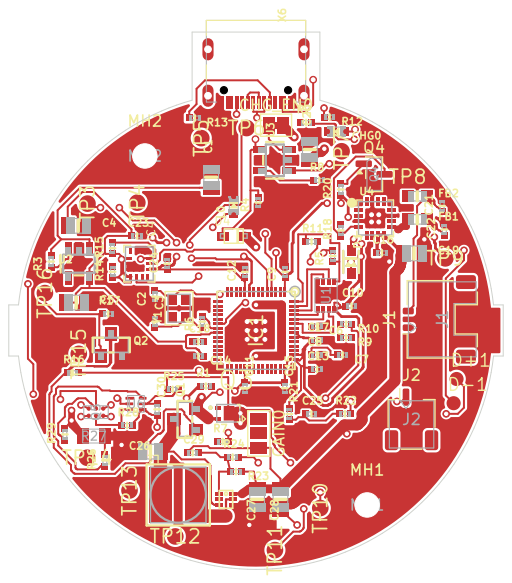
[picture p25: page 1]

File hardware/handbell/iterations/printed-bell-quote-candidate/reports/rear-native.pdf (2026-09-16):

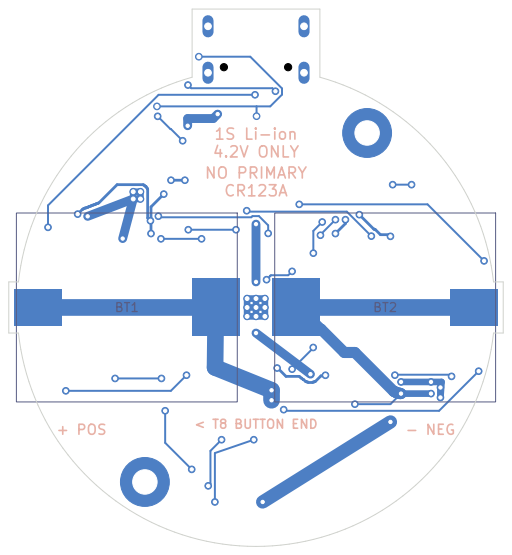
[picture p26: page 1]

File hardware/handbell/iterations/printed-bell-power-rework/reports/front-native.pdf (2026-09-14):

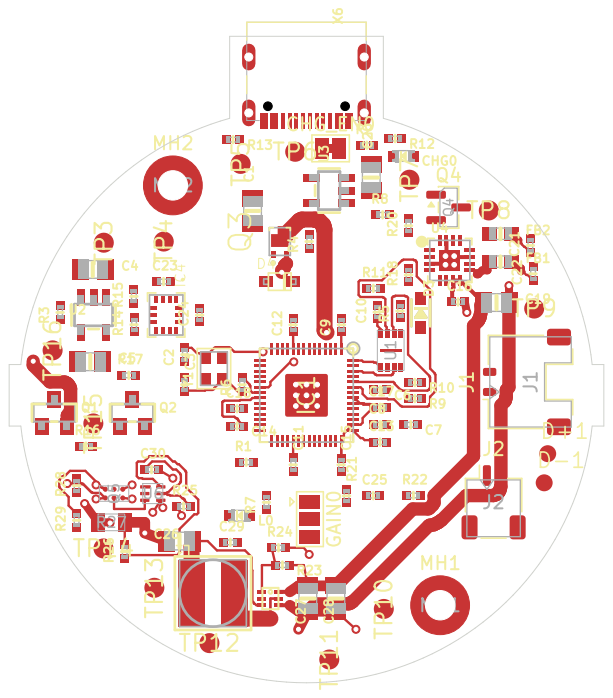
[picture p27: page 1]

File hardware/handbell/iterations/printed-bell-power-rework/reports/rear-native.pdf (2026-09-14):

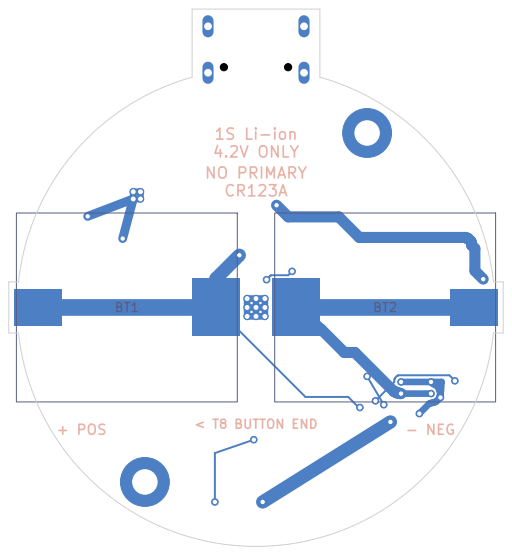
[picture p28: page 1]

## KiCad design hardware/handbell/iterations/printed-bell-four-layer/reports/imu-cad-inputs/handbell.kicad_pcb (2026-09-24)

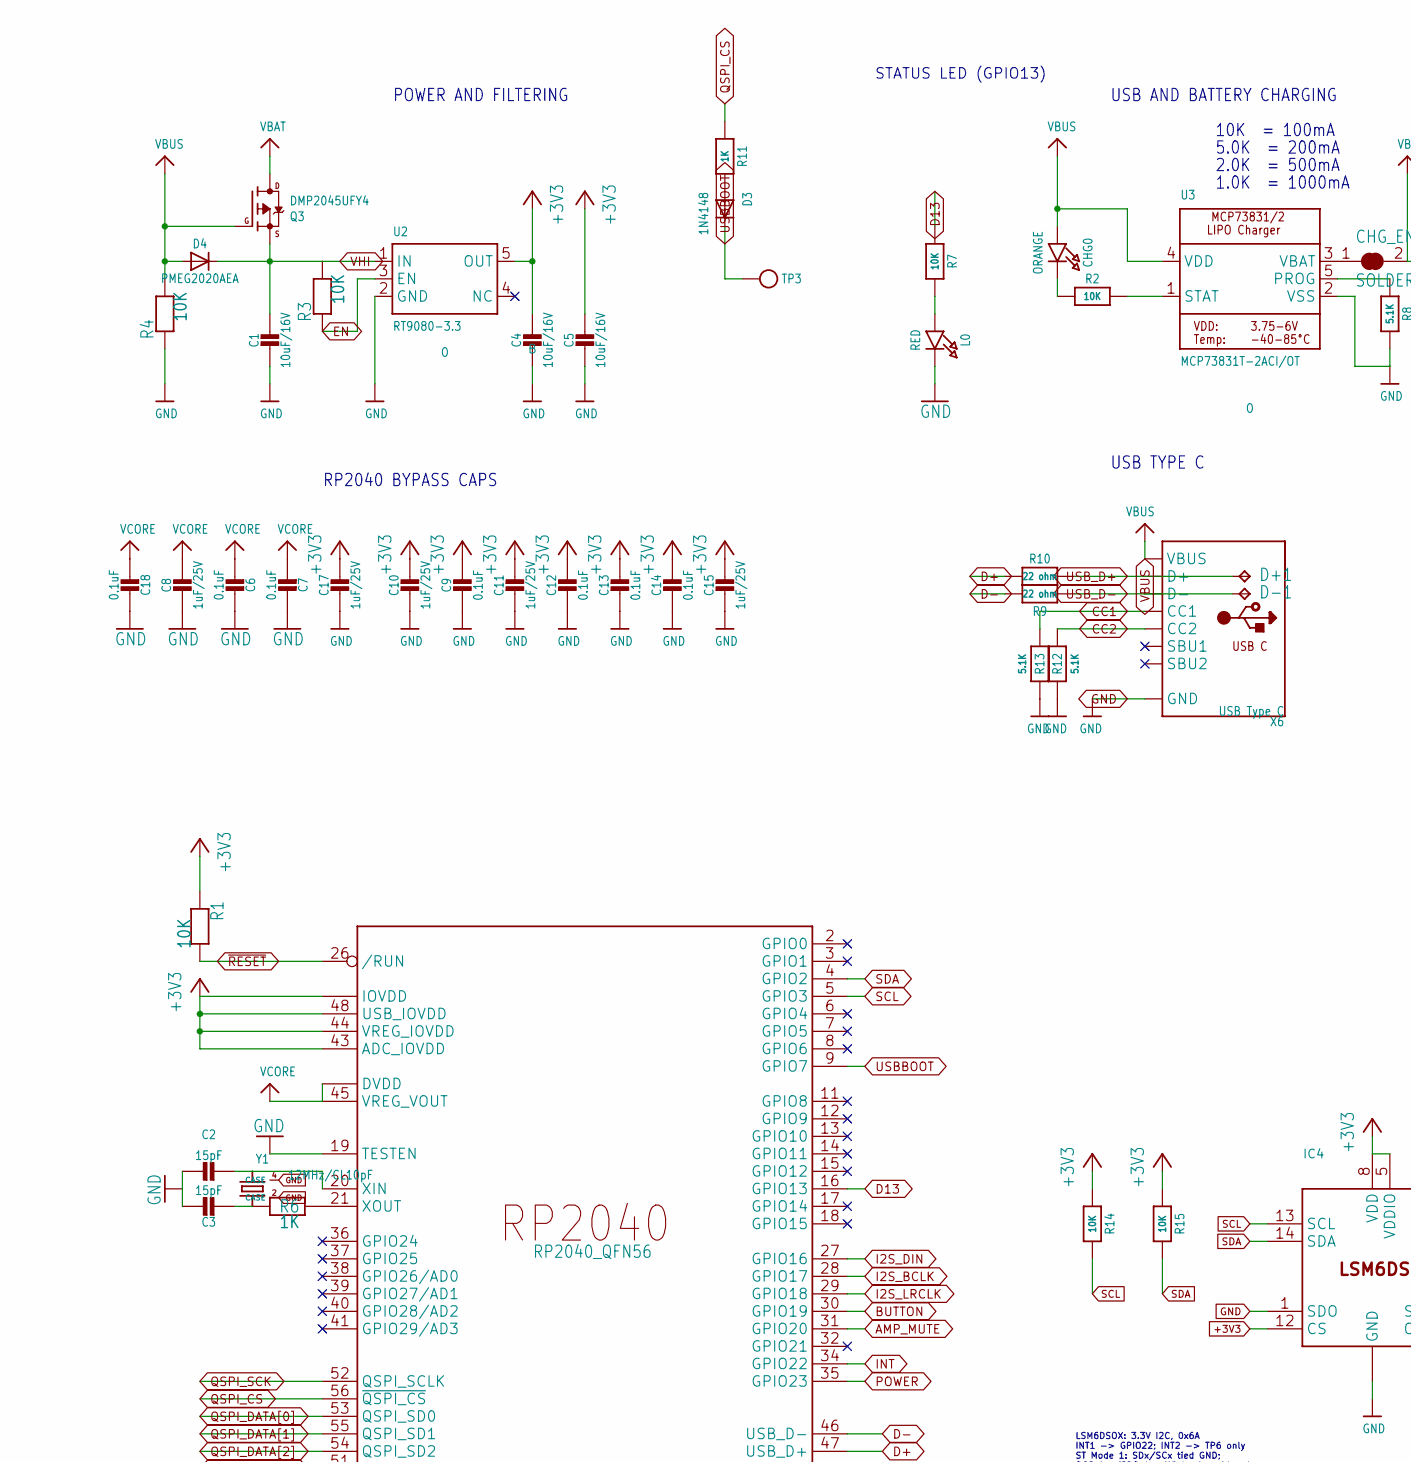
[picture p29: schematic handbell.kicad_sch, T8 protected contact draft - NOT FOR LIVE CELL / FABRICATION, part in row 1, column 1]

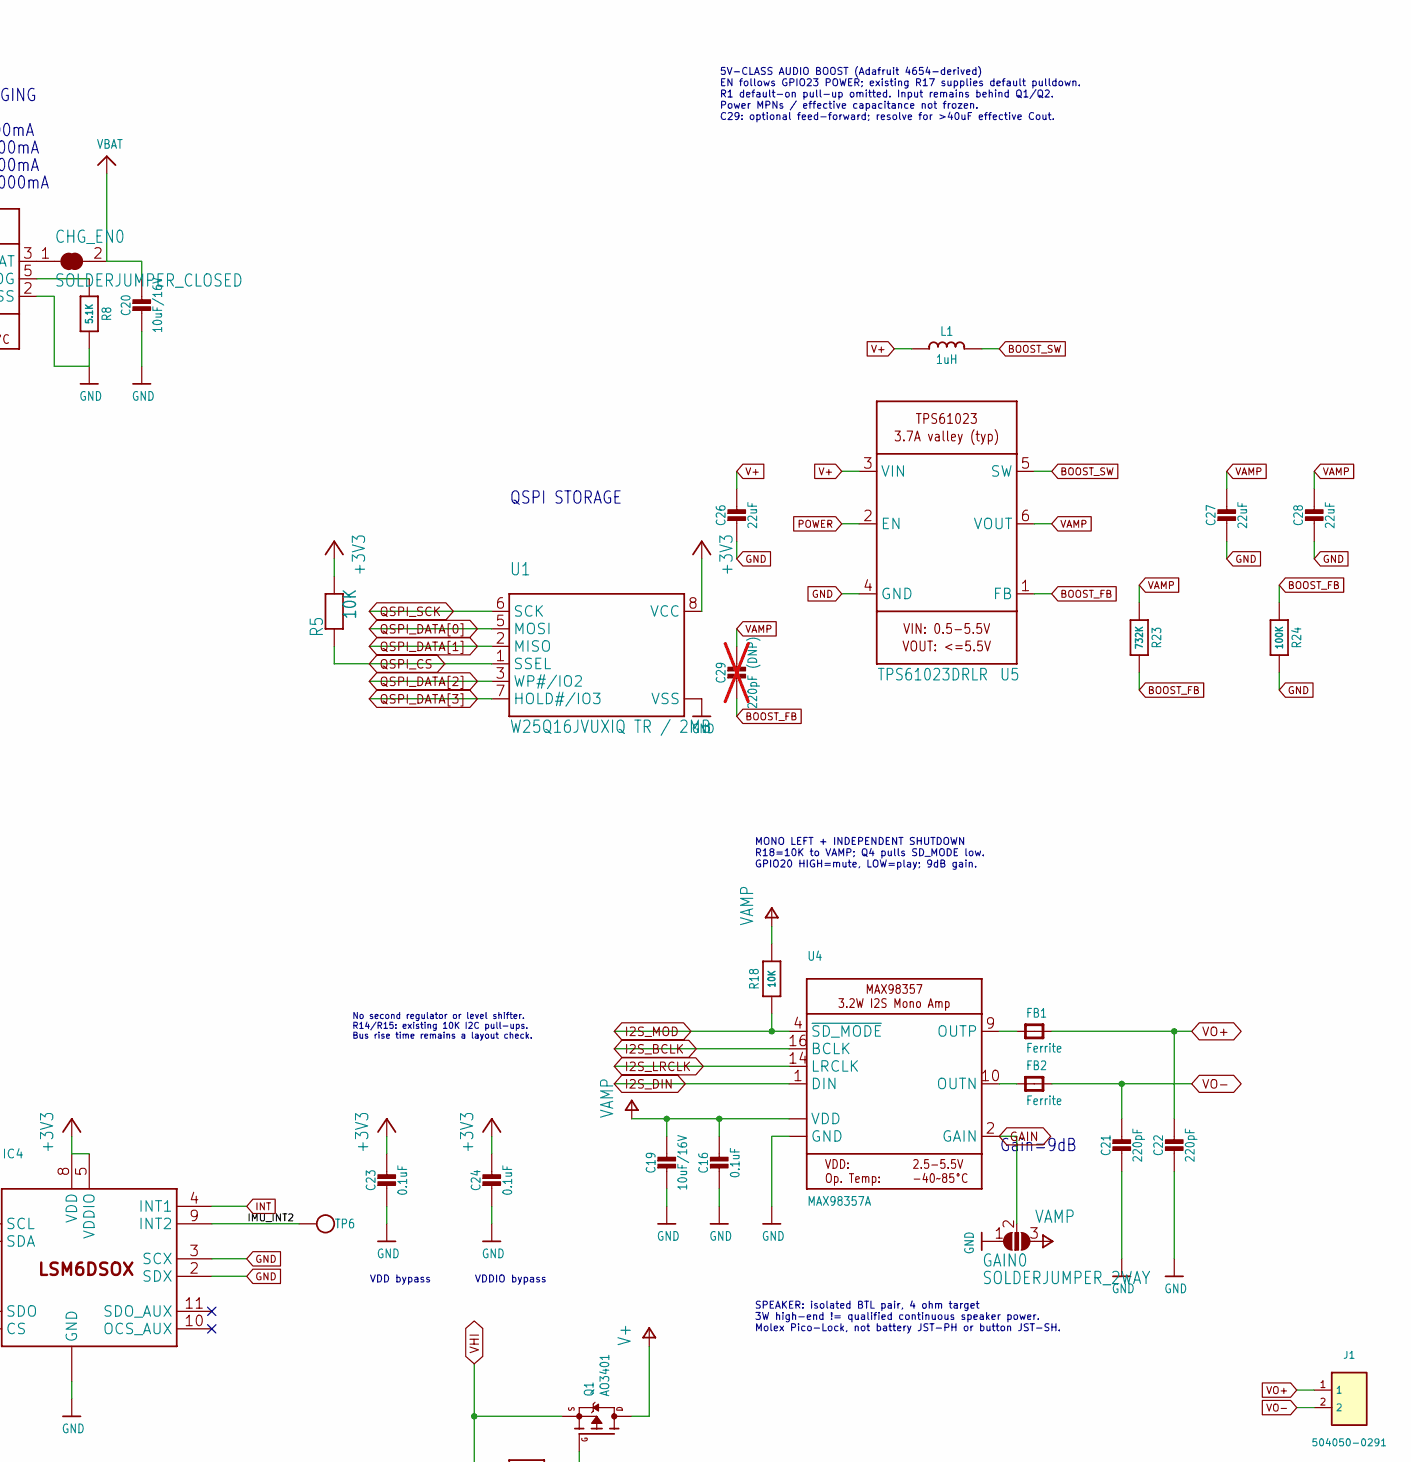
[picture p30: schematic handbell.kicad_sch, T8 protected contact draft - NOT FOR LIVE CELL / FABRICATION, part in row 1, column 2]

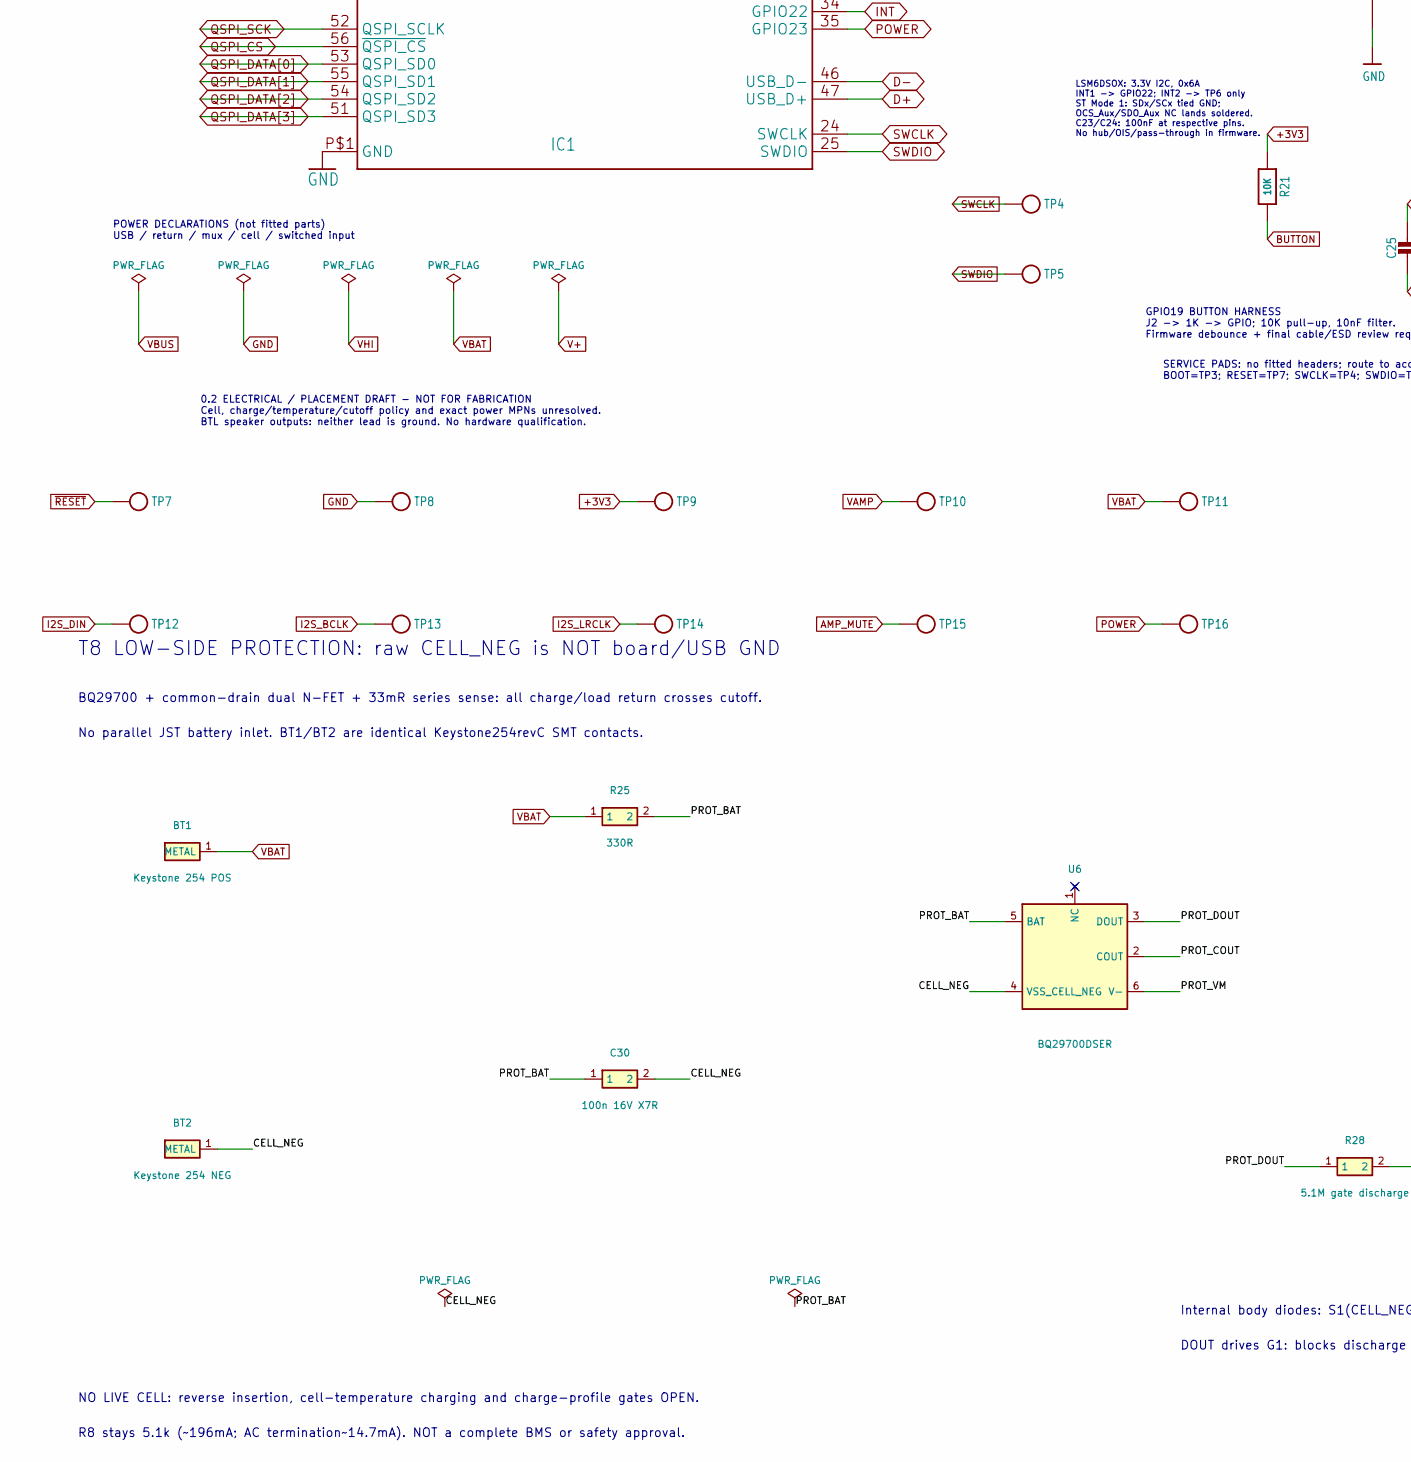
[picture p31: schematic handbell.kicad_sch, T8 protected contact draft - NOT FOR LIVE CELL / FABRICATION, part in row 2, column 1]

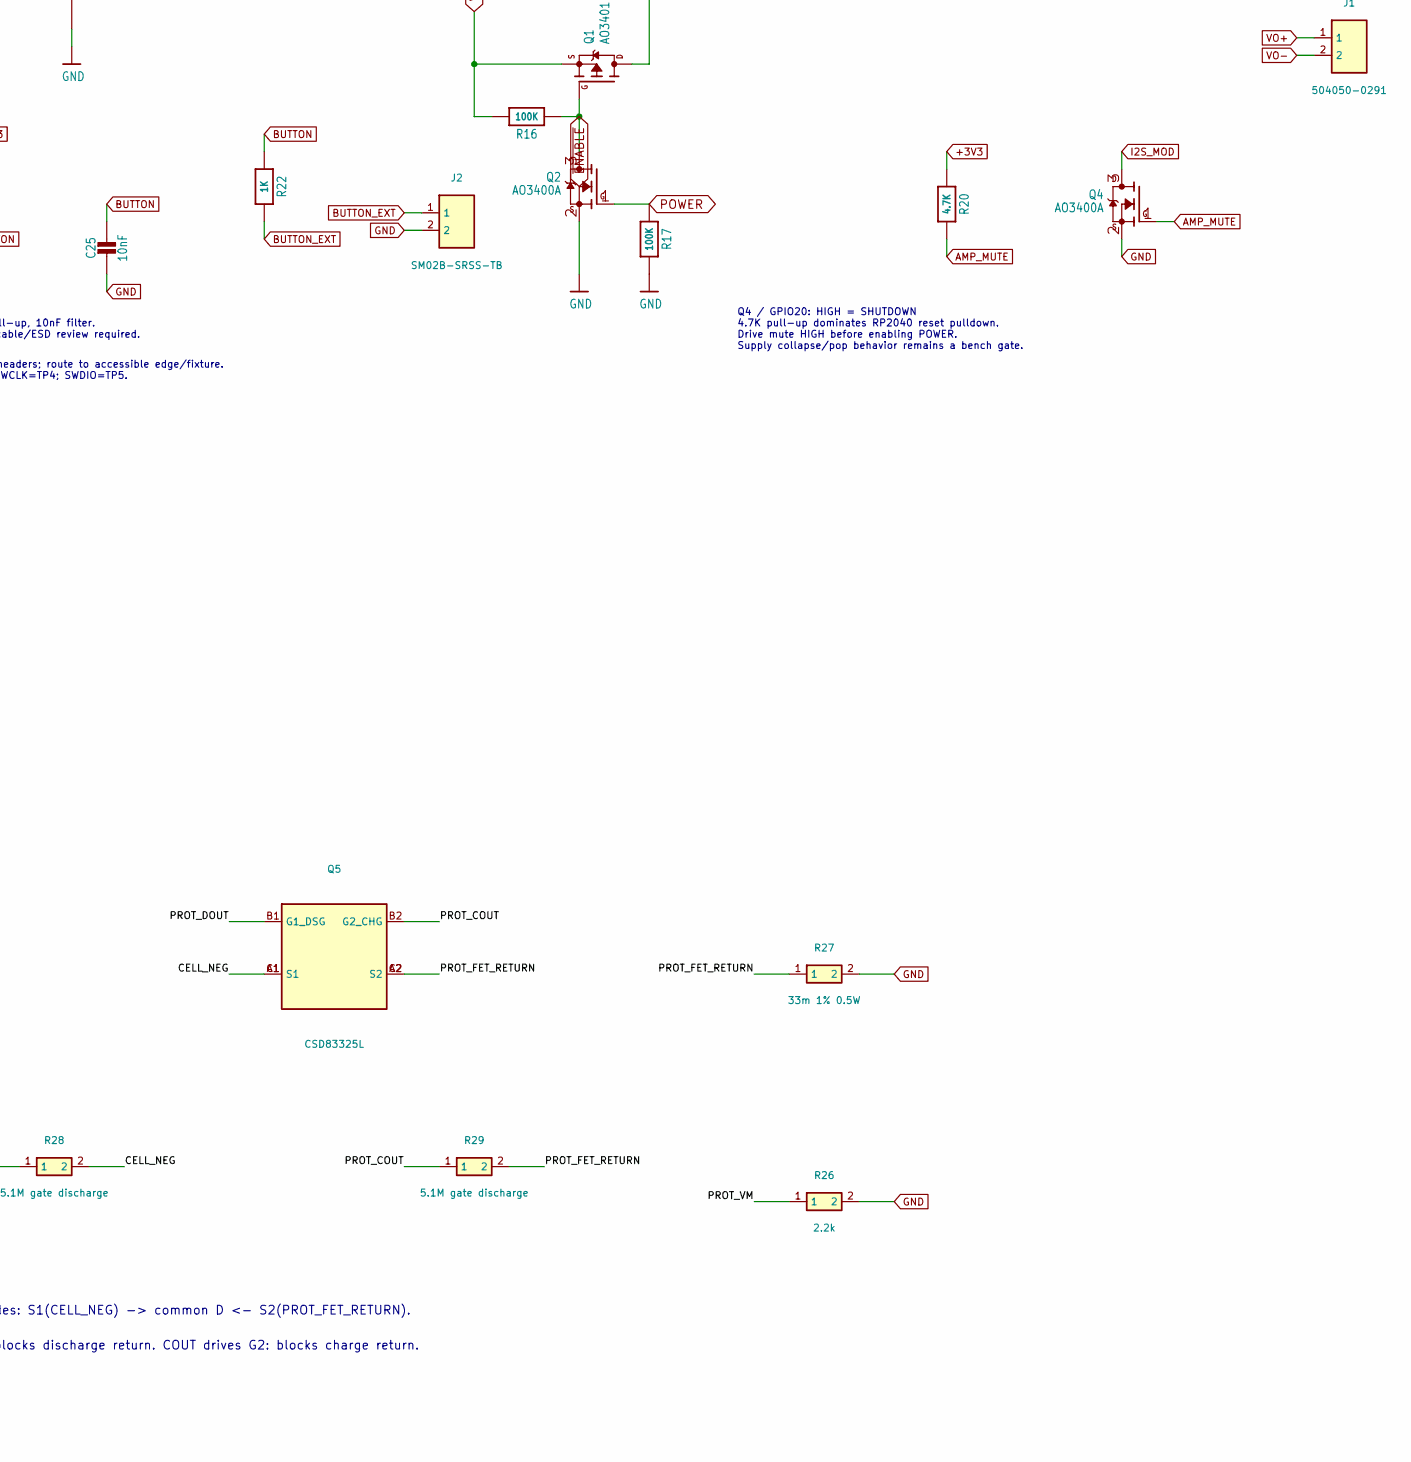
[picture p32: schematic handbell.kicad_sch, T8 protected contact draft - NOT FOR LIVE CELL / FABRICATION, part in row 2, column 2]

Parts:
BT1: Keystone 254 POS; Keystone_254_RevC; MPN 254
BT2: Keystone 254 NEG; Keystone_254_RevC; MPN 254
C1, C4, C5, C19, C20: 10uF/16V; Murata_GRM21_10uF_Reflow; MPN GRM21BR61C106KE15L
C2, C3: 15pF; GRM1555C1H150JA01D; MPN GRM1555C1H150JA01D
C6, C7, C9, C12, C13, C14, C16, C18, C23, C24: 0.1uF; _0402NO; MPN GRM155R71C104KA88D
C8, C10, C11, C15, C17: 1uF/25V; _0402NO; MPN GRM155R61E105KA12D
C21, C22: 220pF; _0402NO; MPN GRM1555C1H221JA01D
C25: 10nF; _0402NO; MPN GRM155R71C103KA01D
C26, C27, C28: 22uF; Murata_GRM21_22uF_Reflow; MPN GRM21BR61C226ME44L
C29: 220pF (DNP); _0402NO; not fitted
C30: 100n 16V X7R; _0402NO; MPN GRM155R71C104KA88D
CHG0: ORANGE; CHIPLED_0603_NOOUTLINE; MPN APT1608LSECK/J4-PRV
CHG_EN0: SOLDERJUMPER_CLOSED; SolderJumper-2_P1.3mm_Bridged_Pad1.0x1.5mm
D3: 1N4148; SOD-323_MINI; MPN 1N4148WS-7-F
D4: PMEG2020AEA; SOD-323F; MPN PMEG2020AEA,115
D+1: TPB1,27; B1,27
D-1: TPB1,27; B1,27
FB1, FB2: Ferrite; Murata_BLM18SG121_WideCopper; MPN BLM18SG121TN1D
GAIN0: SOLDERJUMPER_2WAY; SolderJumper-3_P1.3mm_Open_Pad1.0x1.5mm
IC1: RP2040_QFN56; QFN56_7MM_REDUCEDEPAD; MPN RP2040; LCSC C2040
IC4: LSM6DSOXTR; LGA-14L; MPN LSM6DSOXTR
J1: 504050-0291; Molex_Pico-Lock_504050-0291_1x02-1MP_P1.50mm_Horizontal; MPN 504050-0291
J2: SM02B-SRSS-TB; JST_SH_SM02B-SRSS-TB_1x02-1MP_P1.00mm_Horizontal; MPN SM02B-SRSS-TB
L0: RED; CHIPLED_0603_NOOUTLINE; MPN APT1608LSECK/J3-PRV
L1: 1uH; TDK_VLS5045EX_Reflow; MPN VLS5045EX-1R0N
Q1: AO3401; SOT23-WIDE; MPN AO3401
Q2: AO3400A; SOT23-WIDE; MPN AO3400A
Q3: DMP2045UFY4; DFN2015-3_DrainPad; MPN DMP2045UFY4-7
Q4: AO3400A; SOT-23; MPN AO3400A
Q5: CSD83325L; CSD83325L_YJE6; MPN CSD83325L
R1, R2, R3, R4, R5, R7, R14, R15, R18, R21: 10K; _0402NO; MPN RC0402FR-0710KL
R6, R11, R22: 1K; _0402NO; MPN RC0402FR-071KL
R8, R12, R13: 5.1K; _0402NO; MPN RC0402FR-075K1L
R9, R10: 22 ohm; _0402NO; MPN RC0402FR-0722RL
R16, R17, R24: 100K; _0402NO; MPN RC0402FR-07100KL
R20: 4.7K; _0402NO; MPN RC0402FR-074K7L
R23: 732K; _0402NO; MPN RC0402FR-07732KL
R25: 330R; _0402NO; MPN RC0402FR-07330RL
R26: 2.2k; _0402NO; MPN RC0402FR-072K2L
R27: 33m 1% 0.5W; ERJ6BW_0805_Panasonic_Example; MPN ERJ-6BWFR033V
R28, R29: 5.1M gate discharge; _0402NO; MPN RC0402FR-075M1L
TP3, TP4, TP5, TP6: TESTPOINTROUND1.5MMNO; TESTPOINT_ROUND_1.5MM_NO
TP7: ~{RESET}; TESTPOINT_ROUND_1.5MM_NO
TP8: GND; TESTPOINT_ROUND_1.5MM_NO
TP9: +3V3; TESTPOINT_ROUND_1.5MM_NO
TP10: VAMP; TESTPOINT_ROUND_1.5MM_NO
TP11: VBAT; TESTPOINT_ROUND_1.5MM_NO
TP12: I2S_DIN; TESTPOINT_ROUND_1.5MM_NO
TP13: I2S_BCLK; TESTPOINT_ROUND_1.5MM_NO
TP14: I2S_LRCLK; TESTPOINT_ROUND_1.5MM_NO
TP15: AMP_MUTE; TESTPOINT_ROUND_1.5MM_NO
TP16: POWER; TESTPOINT_ROUND_1.5MM_NO
U1: W25Q16JVUXIQ TR / 2MB; Winbond_USON8_UX_2x3; MPN W25Q16JVUXIQ TR
U2: RT9080-3.3; SOT23-5; MPN RT9080-33GJ5; JLC_ROTATION 0
U3: MCP73831T-2ACI/OT; SOT23-5; MPN MCP73831T-2ACI/OT; JLC_ROTATION 0
U4: MAX98357A; QFN16_3MM; MPN MAX98357AETE+T
U5: TPS61023DRLR; TPS61023_DRL_TI_Example; MPN TPS61023DRLR
U6: BQ29700DSER; BQ29700_DSE6; MPN BQ29700DSER
X6: USB Type C; USB_C_HRO_TYPE_C_31_M_12_Handbell; MPN TYPE-C-31-M-12; LCSC C165948
Y1: 12MHz/CL10pF; ABM8_272_T3; MPN ABM8-272-T3

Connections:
+3V3: C4.1, C5.1, C9.1, C10.1, C11.1, C12.1, C13.1, C14.1, C15.1, C17.1, C23.1, C24.1, IC1.1 (IOVDD), IC1.10 (IOVDD), IC1.22 (IOVDD), IC1.33 (IOVDD), IC1.42 (IOVDD), IC1.43 (ADC_IOVDD), IC1.44 (VREG_IOVDD), IC1.48 (USB_IOVDD), IC1.49 (IOVDD), IC4.5 (VDDIO), IC4.8 (VDD), IC4.12 (CS), R1.1, R5.2, R14.1, R15.1, R20.1, R21.1, TP9.P$1 (P$1_P$1), U1.8 (VCC), U2.5 (OUT)
/CELL_NEG: BT2.1 (METAL_1), C30.2, Q5.A1 (S1), Q5.C1 (S1), R28.2, U6.4 (VSS_CELL_NEG)
/IMU_INT2: IC4.9 (INT2), TP6.P$1 (P$1_P$1)
/PROT_BAT: C30.1, R25.2, U6.5 (BAT)
/PROT_COUT: Q5.B2 (G2_CHG), R29.1, U6.2 (COUT)
/PROT_DOUT: Q5.B1 (G1_DSG), R28.1, U6.3 (DOUT)
/PROT_FET_RETURN: Q5.A2 (S2), Q5.C2 (S2), R27.1, R29.2
/PROT_VM: R26.1, U6.6 (V-)
AMP_MUTE: IC1.31 (GPIO20), Q4.1 (G), R20.2, TP15.P$1 (P$1_P$1)
BOOST_FB: C29.2, R23.2, R24.1, U5.1 (FB)
BOOST_SW: L1.P$2 (2), U5.5 (SW)
BUTTON: C25.1, IC1.30 (GPIO19), R21.2, R22.1
BUTTON_EXT: J2.1, R22.2
CC1: R13.2, X6.A5 (CC1)
CC2: R12.2, X6.B5 (CC2)
D13: IC1.16 (GPIO13), R7.1
D+: IC1.47 (USB_D+), R10.2
D-: IC1.46 (USB_D-), R9.2
EN: R3.1, U2.3 (EN)
GAIN: GAIN0.2, U4.2 (GAIN)
GND: C1.2, C2.1, C3.1, C4.2, C5.2, C6.1, C7.1, C8.2, C9.2, C10.2, C11.2, C12.2, C13.2, C14.2, C15.2, C16.2, C17.2, C18.1, C19.2, C20.2, C21.2, C22.2, C23.2, C24.2, C25.2, C26.2, C27.2, C28.2, GAIN0.1, IC1.19 (TESTEN), IC1.P$1 (GND), IC4.1 (SDO), IC4.2 (SDX), IC4.3 (SCX), IC4.6 (GND), IC4.7 (GND), J2.2, L0.C, Q2.2 (S), Q4.2 (S), R4.1, R8.2, R12.1, R13.1, R17.2, R24.2, R26.2, R27.2, TP8.P$1 (P$1_P$1), U1.4 (VSS), U1.PAD (VSS), U2.2 (GND), U3.2 (VSS), U4.3 (GND), U4.11 (GND), U4.15 (GND), U4.THERMAL (GND), U5.4 (GND), X6.A1B12 (GND), X6.B1A12 (GND), Y1.2 (CASE), Y1.4 (CASE); also elsewhere on the board
I2S_BCLK: IC1.28 (GPIO17), TP13.P$1 (P$1_P$1), U4.16 (BCLK)
I2S_DIN: IC1.27 (GPIO16), TP12.P$1 (P$1_P$1), U4.1 (DIN)
I2S_LRCLK: IC1.29 (GPIO18), TP14.P$1 (P$1_P$1), U4.14 (LRCLK)
I2S_MOD: Q4.3 (D), R18.1, U4.4 (~SD_MODE)
INT: IC1.34 (GPIO22), IC4.4 (INT1)
unnamed: C3.2, R6.1, Y1.1 (1_1)
unnamed: CHG0.C, R2.1
unnamed: D3.A, R11.2
unnamed: FB1.1, U4.9 (OUTP)
unnamed: FB2.1, U4.10 (OUTN)
unnamed: C2.2, IC1.20 (XIN), Y1.3 (2_3)
unnamed: IC1.21 (XOUT), R6.2
unnamed: L0.A, R7.2
unnamed: R8.1, U3.5 (PROG)
unnamed: R2.2, U3.1 (STAT)
unnamed: CHG_EN0.1, U3.3 (VBAT)
POWER: IC1.35 (GPIO23), Q2.1 (G), R17.1, TP16.P$1 (P$1_P$1), U5.2 (EN)
QSPI_CS: IC1.56 (~QSPI_CS), R5.1, R11.1, U1.1 (SSEL)
QSPI_DATA[0]: IC1.53 (QSPI_SD0), U1.5 (MOSI)
QSPI_DATA[1]: IC1.55 (QSPI_SD1), U1.2 (MISO)
QSPI_DATA[2]: IC1.54 (QSPI_SD2), U1.3 (WP#/IO2)
QSPI_DATA[3]: IC1.51 (QSPI_SD3), U1.7 (HOLD#/IO3)
QSPI_SCK: IC1.52 (QSPI_SCLK), U1.6 (SCK)
SCL: IC1.5 (GPIO3), IC4.13 (SCL), R14.2
SDA: IC1.4 (GPIO2), IC4.14 (SDA), R15.2
SWCLK: IC1.24 (SWCLK), TP4.P$1 (P$1_P$1)
SWDIO: IC1.25 (SWDIO), TP5.P$1 (P$1_P$1)
USBBOOT: D3.C, IC1.9 (GPIO7), TP3.P$1 (P$1_P$1)
USB_D+: D+1.TP (TP_TP), R10.1, X6.A6 (D+), X6.B6 (D+)
USB_D-: D-1.TP (TP_TP), R9.1, X6.A7 (D-), X6.B7 (D-)
V+: C26.1, L1.P$1 (1), Q1.3 (D), U5.3 (VIN)
VAMP: C16.1, C19.1, C27.1, C28.1, C29.1, GAIN0.3, R18.2, R23.1, TP10.P$1 (P$1_P$1), U4.7 (VDD), U4.8 (VDD), U5.6 (VOUT)
VBAT: BT1.1 (METAL_1), C20.1, CHG_EN0.2, Q3.3 (D), R25.1, TP11.P$1 (P$1_P$1)
VBUS: CHG0.A, D4.A, Q3.1 (G), R4.2, U3.4 (VDD), X6.A4B9 (VBUS), X6.B4A9 (VBUS)
VCORE: C6.2, C7.2, C8.1, C18.2, IC1.23 (DVDD), IC1.45 (VREG_VOUT), IC1.50 (DVDD)
VHI: C1.1, D4.C, Q1.2 (S), Q3.2 (S), R3.2, R16.2, U2.1 (IN)
VO+: C22.1, FB1.2, J1.1
VO-: C21.1, FB2.2, J1.2
~ENABLE: Q1.1 (G), Q2.3 (D), R16.1
~RESET: IC1.26 (/RUN), R1.2, TP7.P$1 (P$1_P$1)

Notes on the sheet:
POWER AND FILTERING
MONO LEFT + INDEPENDENT SHUTDOWN R18=10K to VAMP; Q4 pulls SD_MODE low. GPIO20 HIGH=mute, LOW=play; 9dB gain.
USB AND BATTERY CHARGING
Gain=9dB
STATUS LED (GPIO13)
QSPI STORAGE
USB TYPE C
RP2040 BYPASS CAPS
5.0K = 200mA
2.0K = 500mA
10K = 100mA
1.0K = 1000mA
POWER DECLARATIONS (not fitted parts) USB / return / mux / cell / switched input
0.2 ELECTRICAL / PLACEMENT DRAFT - NOT FOR FABRICATION Cell, charge/temperature/cutoff policy and exact power MPNs unresolved. BTL speaker outputs: neither lead is ground. No hardware qualification.
VDD bypass
VDDIO bypass
LSM6DSOX: 3.3V I2C, 0x6A INT1 -> GPIO22; INT2 -> TP6 only ST Mode 1: SDx/SCx tied GND; OCS_Aux/SDO_Aux NC lands soldered. C23/C24: 100nF at respective pins. No hub/OIS/pass-through in firmware.
No second regulator or level shifter. R14/R15: existing 10K I2C pull-ups. Bus rise time remains a layout check.
5V-CLASS AUDIO BOOST (Adafruit 4654-derived) EN follows GPIO23 POWER; existing R17 supplies default pulldown. R1 default-on pull-up omitted. Input remains behind Q1/Q2. Power MPNs / effective capacitance not frozen. C29: optional feed-forward; resolve for >40uF effective Cout.
GPIO19 BUTTON HARNESS J2 -> 1K -> GPIO; 10K pull-up, 10nF filter. Firmware debounce + final cable/ESD review required.
Q4 / GPIO20: HIGH = SHUTDOWN 4.7K pull-up dominates RP2040 reset pulldown. Drive mute HIGH before enabling POWER. Supply collapse/pop behavior remains a bench gate.
SPEAKER: isolated BTL pair, 4 ohm target 3W high-end != qualified continuous speaker power. Molex Pico-Lock, not battery JST-PH or button JST-SH.
SERVICE PADS: no fitted headers; route to accessible edge/fixture. BOOT=TP3; RESET=TP7; SWCLK=TP4; SWDIO=TP5.
T8 LOW-SIDE PROTECTION: raw CELL_NEG is NOT board/USB GND
BQ29700 + common-drain dual N-FET + 33mR series sense: all charge/load return crosses cutoff.
No parallel JST battery inlet. BT1/BT2 are identical Keystone254revC SMT contacts.
Internal body diodes: S1(CELL_NEG) -> common D <- S2(PROT_FET_RETURN).
DOUT drives G1: blocks discharge return. COUT drives G2: blocks charge return.
NO LIVE CELL: reverse insertion, cell-temperature charging and charge-profile gates OPEN.
R8 stays 5.1k (~196mA; AC termination~14.7mA). NOT a complete BMS or safety approval.

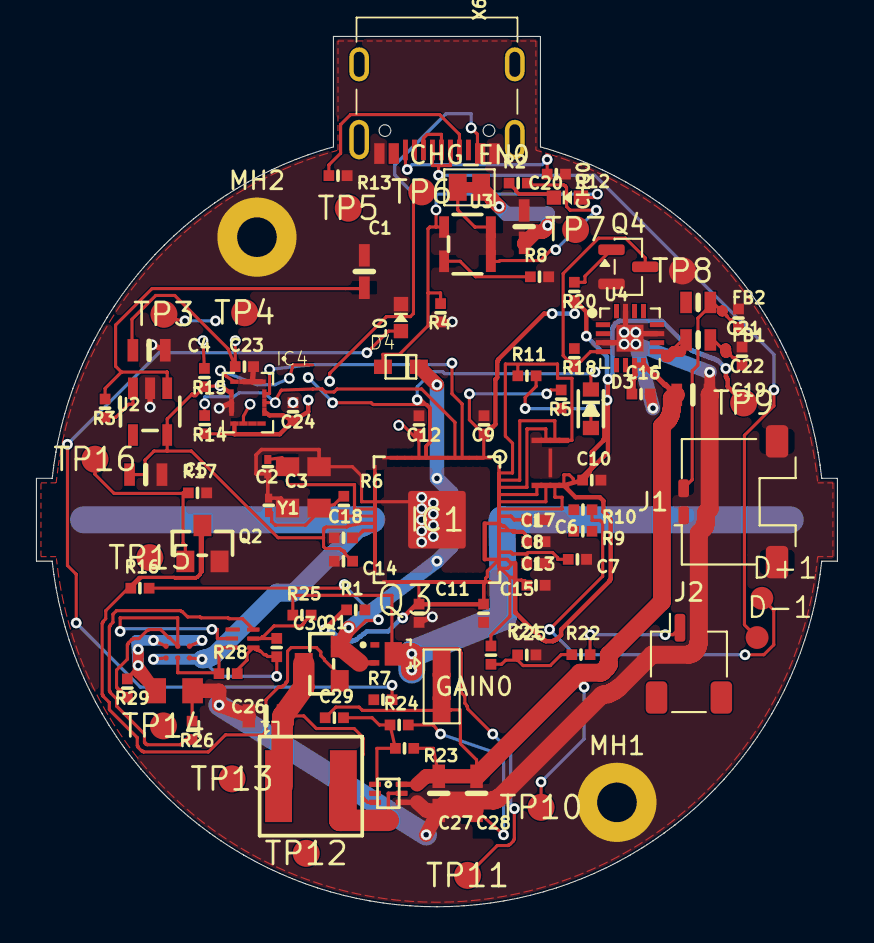
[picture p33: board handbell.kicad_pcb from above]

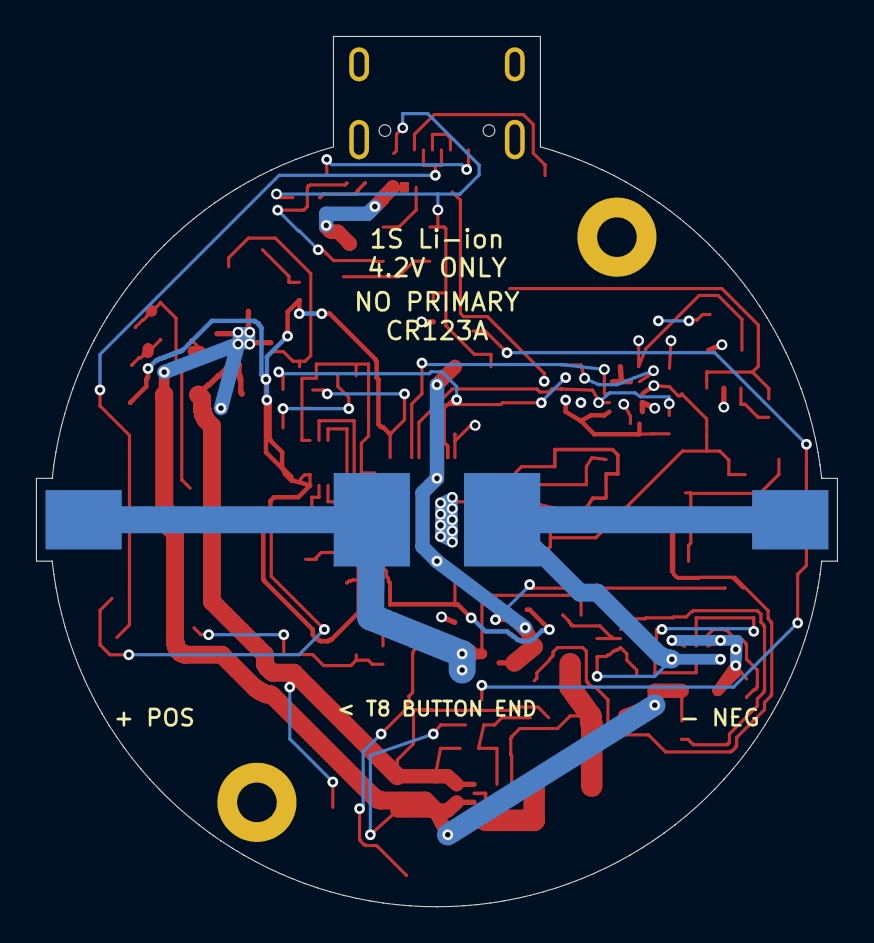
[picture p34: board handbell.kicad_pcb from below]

Board: 4 copper layers, 44.5 x 48.3 mm, 104 parts (2 on the bottom side), 61 nets.

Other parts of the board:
MH1, MH2: M2 GND mounting hole; MountingHole_2.2mm_M2_Pad

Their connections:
GND: MH1.1, MH2.1; also elsewhere on the board

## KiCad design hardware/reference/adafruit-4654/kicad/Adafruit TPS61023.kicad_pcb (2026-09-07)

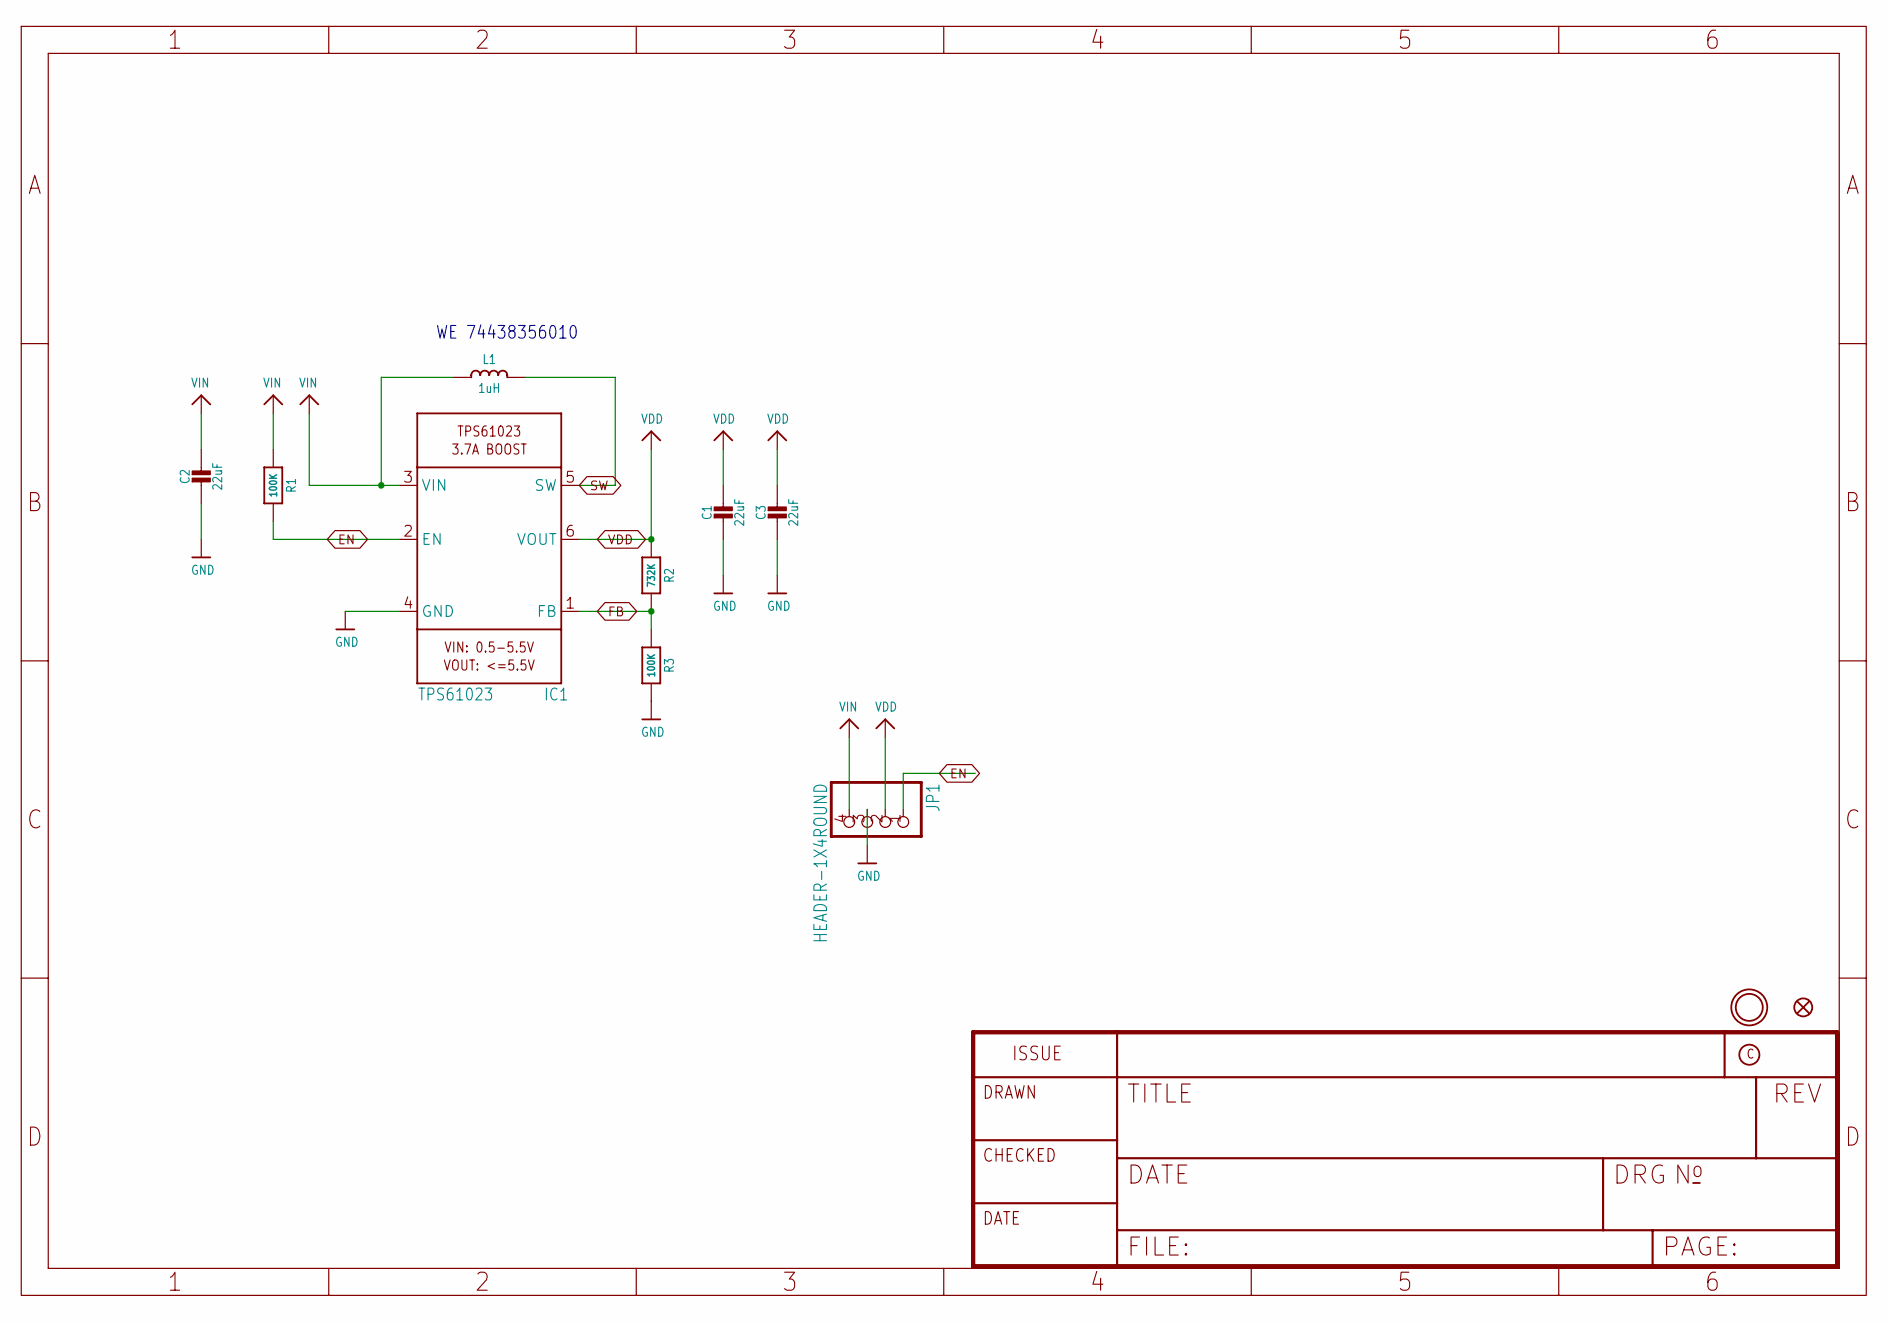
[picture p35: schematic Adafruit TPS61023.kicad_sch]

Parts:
C1, C2, C3: 22uF; 0805-NO
FID1: FIDUCIAL_1MM
IC1: TPS61023; SOT563
JP1: HEADER-1X4ROUND; 1X04_ROUND
L1: 1uH; INDUCTOR_5X5MM_TDK_VLC5045
R1, R3: 100K; 0603-NO
R2: 732K; 0603-NO
U$9: MOUNTINGHOLE2.5; MOUNTINGHOLE_2.5_PLATED

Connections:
EN: IC1.2 (EN), JP1.1, R1.2
FB: IC1.1 (FB), R2.2, R3.1
GND: C1.2, C2.2, C3.2, IC1.4 (GND), JP1.3, R3.2
SW: IC1.5 (SW), L1.P$2 (2)
VDD: C1.1, C3.1, IC1.6 (VOUT), JP1.2, R2.1
VIN: C2.1, IC1.3 (VIN), JP1.4, L1.P$1 (1), R1.1

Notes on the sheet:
WE 74438356010

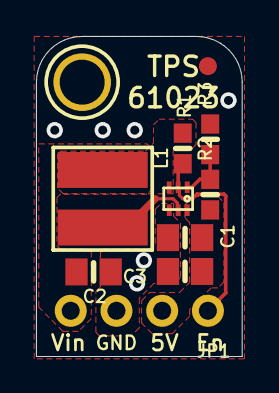
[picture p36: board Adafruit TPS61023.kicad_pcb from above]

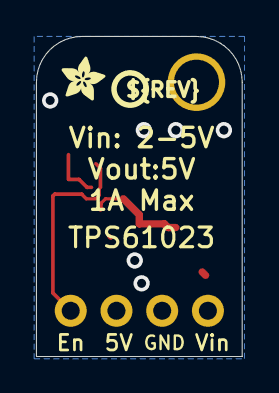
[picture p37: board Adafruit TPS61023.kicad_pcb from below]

Board: 2 copper layers, 11.4 x 17.8 mm, 13 parts (2 on the bottom side), 6 nets.

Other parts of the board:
U$10: PCBFEAT-REV-040
U$11: ADAFRUIT_2.5MM

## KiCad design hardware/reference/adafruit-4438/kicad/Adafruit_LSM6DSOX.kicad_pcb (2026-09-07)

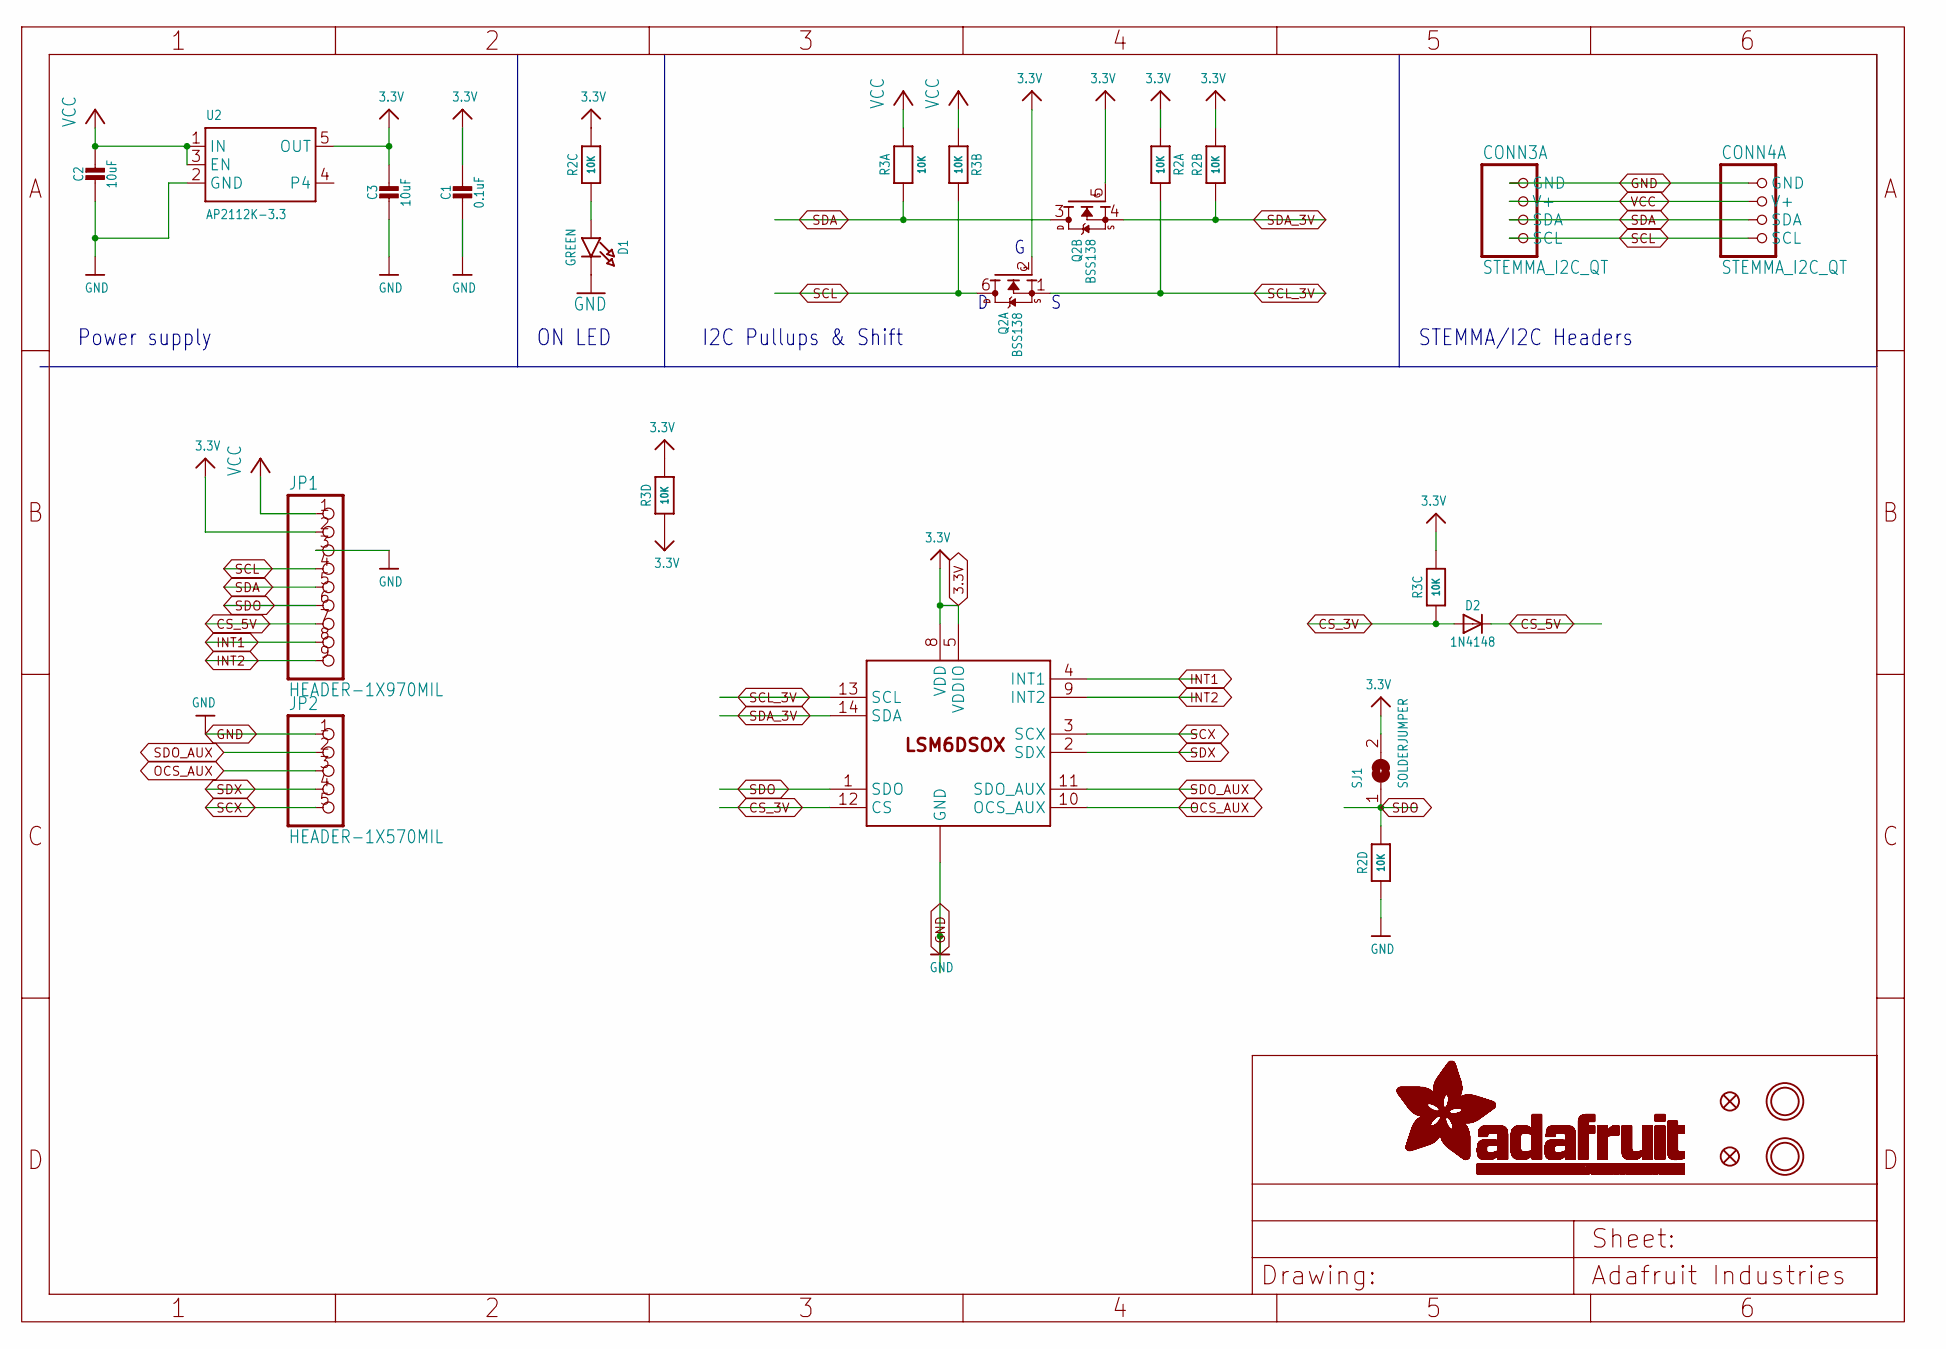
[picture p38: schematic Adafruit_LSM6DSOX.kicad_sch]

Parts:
C1: 0.1uF; 0603-NO
C2, C3: 10uF; 0805-NO
CONN3, CONN4: STEMMA_I2C_QT; JST_SH4
D1: GREEN; CHIPLED_0603_NOOUTLINE
D2: 1N4148; SOD-323
FID3, FID4: FIDUCIAL_1MM
JP1: HEADER-1X970MIL; 1X09_ROUND_70
JP2: HEADER-1X570MIL; 1X05_ROUND_70
Q2: BSS138; SOT363
R2, R3: 10K; RESPACK_4X0603
SJ1: SOLDERJUMPER; SOLDERJUMPER_ARROW_NOPASTE
U2: AP2112K-3.3; SOT23-5
U$1, U$17: MOUNTINGHOLE2.5; MOUNTINGHOLE_2.5_PLATED
U$2: LSM6DSOX; LGA-14L

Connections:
3.3V: C1.1, C3.1, JP1.2, Q2.2 (G), Q2.5 (G), R2.1, R2.2 (1), R2.6 (2), R3.3 (1), R3.4 (1), R3.5 (2), SJ1.2, U2.5 (OUT), U$2.5 (VDDIO), U$2.8 (VDD)
CS_3V: D2.A, R3.6 (2), U$2.12 (CS)
CS_5V: D2.C, JP1.7
GND: C1.2, C2.2, C3.2, CONN3.1 (GND), CONN4.1 (GND), D1.C, JP1.3, JP2.1, R2.4 (1), U2.2 (GND), U$2.6 (GND), U$2.7 (GND)
INT1: JP1.8, U$2.4 (INT1)
INT2: JP1.9, U$2.9 (INT2)
unnamed: D1.A, R2.3 (1)
OCS_AUX: JP2.3, U$2.10 (OCS_AUX)
SCL: CONN3.4 (SCL), CONN4.4 (SCL), JP1.4, Q2.6 (D), R3.2 (1)
SCL_3V: Q2.1 (S), R2.8 (2), U$2.13 (SCL)
SCX: JP2.5, U$2.3 (SCX)
SDA: CONN3.3 (SDA), CONN4.3 (SDA), JP1.5, Q2.3 (D), R3.1
SDA_3V: Q2.4 (S), R2.7 (2), U$2.14 (SDA)
SDO: JP1.6, R2.5 (2), SJ1.1, U$2.1 (SDO)
SDO_AUX: JP2.2, U$2.11 (SDO_AUX)
SDX: JP2.4, U$2.2 (SDX)
VCC: C2.1, CONN3.2 (V+), CONN4.2 (V+), JP1.1, R3.7 (2), R3.8 (2), U2.1 (IN), U2.3 (EN)

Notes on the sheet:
ON LED
I2C Pullups & Shift
STEMMA/I2C Headers
Power supply

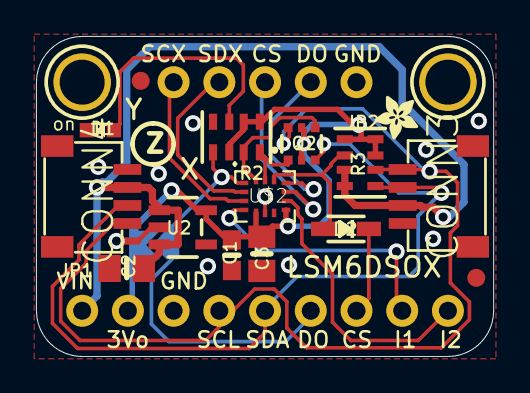
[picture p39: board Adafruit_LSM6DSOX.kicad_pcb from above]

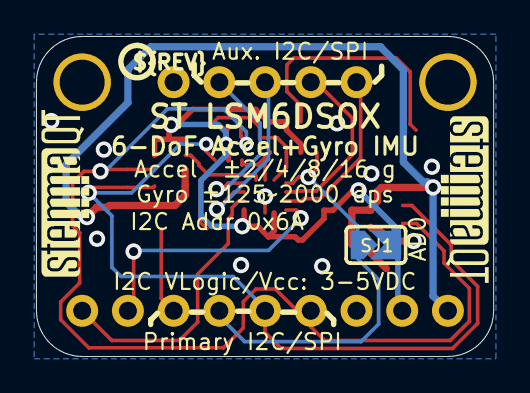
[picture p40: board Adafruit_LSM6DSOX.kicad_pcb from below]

Board: 2 copper layers, 25.4 x 17.8 mm, 23 parts (4 on the bottom side), 17 nets.

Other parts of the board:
U$9: ADAFRUIT_2.5MM
U$25: PCBFEAT-REV-040
U$30, U$31: STEMMAQT

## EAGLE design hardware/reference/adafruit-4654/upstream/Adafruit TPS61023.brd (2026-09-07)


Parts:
C1, C2, C3: 22uF; 0805-NO
FID1: FIDUCIAL_1MM
IC1: TPS61023; SOT563
JP1: HEADER-1X4ROUND; 1X04_ROUND
L1: 1uH; INDUCTOR_5X5MM_TDK_VLC5045
R1, R3: 100K; 0603-NO
R2: 732K; 0603-NO
U$9: MOUNTINGHOLE2.5; MOUNTINGHOLE_2.5_PLATED

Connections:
EN: IC1.2 (EN), JP1.1, R1.2
FB: IC1.1 (FB), R2.2, R3.1
GND: C1.2, C2.2, C3.2, IC1.4 (GND), JP1.3, R3.2
SW: IC1.5 (SW), L1.P$2 (2)
VDD: C1.1, C3.1, IC1.6 (VOUT), JP1.2, R2.1
VIN: C2.1, IC1.3 (VIN), JP1.4, L1.P$1 (1), R1.1

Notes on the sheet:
WE 74438356010



Board: 2 copper layers, 11.4 x 17.8 mm, 13 parts (2 on the bottom side), 6 nets.

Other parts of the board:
U$10: PCBFEAT-REV-040
U$11: ADAFRUIT_2.5MM

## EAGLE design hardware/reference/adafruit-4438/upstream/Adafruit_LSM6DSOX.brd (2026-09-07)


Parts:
C1: 0.1uF; 0603-NO
C2, C3: 10uF; 0805-NO
CONN3, CONN4: STEMMA_I2C_QT; JST_SH4
D1: GREEN; CHIPLED_0603_NOOUTLINE
D2: 1N4148; SOD-323
FID3, FID4: FIDUCIAL_1MM
JP1: HEADER-1X970MIL; 1X09_ROUND_70
JP2: HEADER-1X570MIL; 1X05_ROUND_70
Q2: BSS138; SOT363
R2, R3: 10K; RESPACK_4X0603
SJ1: SOLDERJUMPER; SOLDERJUMPER_ARROW_NOPASTE
U2: AP2112K-3.3; SOT23-5
U$1, U$17: MOUNTINGHOLE2.5; MOUNTINGHOLE_2.5_PLATED
U$2: LSM6DSOX; LGA-14L

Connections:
3.3V: C1.1, C3.1, JP1.2, Q2.2 (G), Q2.5 (G), R2.1, R2.2 (1), R2.6 (2), R3.3 (1), R3.4 (1), R3.5 (2), SJ1.2, U2.5 (OUT), U$2.5 (VDDIO), U$2.8 (VDD)
CS_3V: D2.A, R3.6 (2), U$2.12 (CS)
CS_5V: D2.C, JP1.7
GND: C1.2, C2.2, C3.2, CONN3.1 (GND), CONN4.1 (GND), D1.C, JP1.3, JP2.1, R2.4 (1), U2.2 (GND), U$2.6 (GND), U$2.7 (GND)
INT1: JP1.8, U$2.4 (INT1)
INT2: JP1.9, U$2.9 (INT2)
unnamed: D1.A, R2.3 (1)
OCS_AUX: JP2.3, U$2.10 (OCS_AUX)
SCL: CONN3.4 (SCL), CONN4.4 (SCL), JP1.4, Q2.6 (D), R3.2 (1)
SCL_3V: Q2.1 (S), R2.8 (2), U$2.13 (SCL)
SCX: JP2.5, U$2.3 (SCX)
SDA: CONN3.3 (SDA), CONN4.3 (SDA), JP1.5, Q2.3 (D), R3.1
SDA_3V: Q2.4 (S), R2.7 (2), U$2.14 (SDA)
SDO: JP1.6, R2.5 (2), SJ1.1, U$2.1 (SDO)
SDO_AUX: JP2.2, U$2.11 (SDO_AUX)
SDX: JP2.4, U$2.2 (SDX)
VCC: C2.1, CONN3.2 (V+), CONN4.2 (V+), JP1.1, R3.7 (2), R3.8 (2), U2.1 (IN), U2.3 (EN)

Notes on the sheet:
I2C Pullups & Shift
STEMMA/I2C Headers
ON LED
Power supply



Board: 2 copper layers, 25.4 x 17.8 mm, 23 parts (4 on the bottom side), 17 nets.

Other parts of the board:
U$9: ADAFRUIT_2.5MM
U$25: PCBFEAT-REV-040
U$30, U$31: STEMMAQT

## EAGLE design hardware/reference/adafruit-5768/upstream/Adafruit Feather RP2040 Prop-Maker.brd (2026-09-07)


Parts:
C1, C4, C5, C19, C20: 10uF/16V; 0805-NO
C2, C3: 22pF; _0402NO
C6, C7, C9, C12, C13, C14, C16, C18: 0.1uF; _0402NO
C8, C10, C11, C15, C17: 1uF/25V; _0402NO
C21, C22: 220pF; _0402NO
CHG: ORANGE; CHIPLED_0603_NOOUTLINE
CHG_EN: SOLDERJUMPER_CLOSED; SOLDERJUMPER_CLOSEDWIRE
CONN1: STEMMA_I2C_QTRA; JST_SH4_RA
D3: 1N4148; SOD-323_MINI
D4: PMEG2020AEA; SOD-323F
D+1: TPB1,27; B1,27
D-1: TPB1,27; B1,27
FB1, FB2: Ferrite; 0603-NO
GAIN: SOLDERJUMPER_2WAY; SOLDERJUMPER_2WAY_OPEN_NOPASTE
IC1: RP2040_QFN56; QFN56_7MM_REDUCEDEPAD
IC2: 74AHCT1G125DCK; SC70-5
IC4: LIS3DH; LGA16_3X3MM
JP1: HEADER-1X16ROUND; 1X16_ROUND
JP3: HEADER-1X12; 1X12_ROUND
L: RED; CHIPLED_0603_NOOUTLINE
LED1: WS2812B_SK6805_1515; SK6805_1515
OUTPUTS: TERMINALS; 1X06_OVAL
Q1: AO3401; SOT23-WIDE
Q2: C20917; SOT23-WIDE
Q3: DMG3415UFY; DFN2015-3
R1, R2, R3, R4, R5, R7, R14, R15: 10K; _0402NO
R6, R11: 1K; _0402NO
R8, R12, R13: 5.1K; _0402NO
R9, R10: 22 ohm; _0402NO
R16, R17: 100K; _0402NO
R18: 1M; _0402NO
R19: 100; _0402NO
SERVO: 1x3M; 1X03_ROUND_76
SW1, SW2: RKB2; BTN_RKB2_4.6X2.8
TP3: TESTPOINTROUND1.5MMNO; TESTPOINT_ROUND_1.5MM_NO
U1: 8MB QSPI; USON8_4X4
U2: RT9080-3.3; SOT23-5; JLC_ROTATION 0
U3: MCP73831T-2ACI/OT; SOT23-5; JLC_ROTATION 0
U4: MAX98357A; QFN16_3MM
U$31, U$32: MOUNTINGHOLE2.5; MOUNTINGHOLE_2.5_PLATED
U$34, U$35: FIDUCIAL_1MM
X1: JSTPH; JSTPH2_BATT
X6: USB Type C; USB_C_CUSB31-CFM2AX-01-X
Y1: 12MHz/12pF; CRYSTAL_2.5X2

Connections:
1.2V: C6.2, C7.2, C8.1, C18.2, IC1.23 (DVDD), IC1.45 (VREG_VOUT), IC1.50 (DVDD)
!ENABLE: Q1.1 (G), Q2.3 (D), R16.1
!RESET: IC1.26 (/RUN), JP1.16, R1.2, SW1.A, SW1.A' (P1)
+3V3: C4.1, C5.1, C9.1, C10.1, C11.1, C12.1, C13.1, C14.1, C15.1, C17.1, CONN1.2 (V+), IC1.1 (IOVDD), IC1.10 (IOVDD), IC1.22 (IOVDD), IC1.33 (IOVDD), IC1.42 (IOVDD), IC1.43 (ADC_IOVDD), IC1.44 (VREG_IOVDD), IC1.48 (USB_IOVDD), IC1.49 (IOVDD), IC4.1 (VDDIO), IC4.8 (CS), IC4.13 (ADC3), IC4.14 (VDD), IC4.15 (ADC2), IC4.16 (ADC1), JP1.14, JP1.15, LED1.2 (VDD), R1.1, R5.2, R14.1, R15.1, U1.8 (VCC), U2.5 (OUT)
A0: IC1.38 (GPIO26/AD0), JP1.12
A1: IC1.39 (GPIO27/AD1), JP1.11
A2: IC1.40 (GPIO28/AD2), JP1.10
A3: IC1.41 (GPIO29/AD3), JP1.9
BUTTON: IC1.30 (GPIO19), OUTPUTS.4
CC1: R13.2, X6.A5 (CC1)
CC2: R12.2, X6.B5 (CC2)
D4: IC1.6 (GPIO4), JP1.1, LED1.1 (DI)
D5: IC1.7 (GPIO5), JP3.10
D6: IC1.8 (GPIO6), JP3.9
D9: IC1.12 (GPIO9), JP3.8
D10: IC1.13 (GPIO10), JP3.7
D11: IC1.14 (GPIO11), JP3.6
D12: IC1.15 (GPIO12), JP3.5
D13: IC1.16 (GPIO13), JP3.4, R7.1
D24: IC1.36 (GPIO24), JP1.8
D25: IC1.37 (GPIO25), JP1.7
D+: IC1.47 (USB_D+), R10.2
D-: IC1.46 (USB_D-), R9.2
EN: JP3.2, R3.1, U2.3 (EN)
GAIN: GAIN.2, U4.2 (GAIN)
GND: C1.2, C2.1, C3.1, C4.2, C5.2, C6.1, C7.1, C8.2, C9.2, C10.2, C11.2, C12.2, C13.2, C14.2, C15.2, C16.2, C17.2, C18.1, C19.2, C20.2, C21.2, C22.2, CONN1.1 (GND), CONN1.MT1 (MT), CONN1.MT2 (MT), GAIN.1, IC1.19 (TESTEN), IC1.P$1 (GND), IC2.1 (OE), IC2.3 (GND), IC4.5 (GND), IC4.7 (SDO), IC4.10 (RES(GND)), IC4.12 (GND), JP1.13, L.C, LED1.4 (GND), OUTPUTS.2, Q2.2 (S), R4.1, R8.2, R12.1, R13.1, R17.2, SERVO.3, SW1.B (S), SW1.B' (S1), SW2.B (S), SW2.B' (S1), U1.4 (VSS), U1.PAD (VSS), U2.2 (GND), U3.2 (VSS), U4.3 (GND), U4.11 (GND), U4.15 (GND), U4.THERMAL (GND), X1.1, X1.NC1, X1.NC2, X6.A1B12 (GND), X6.B1A12 (GND)
I2S_BCLK: IC1.28 (GPIO17), U4.16 (BCLK)
I2S_DIN: IC1.27 (GPIO16), U4.1 (DIN)
I2S_LRCLK: IC1.29 (GPIO18), U4.14 (LRCLK)
I2S_MOD: R18.1, U4.4 (!SD_MODE)
INT: IC1.34 (GPIO22), IC4.11 (INT1)
MISO: IC1.11 (GPIO8), JP1.4
MOSI: IC1.18 (GPIO15), JP1.5
unnamed: CHG.C, R2.1
unnamed: L.A, R7.2
unnamed: R2.2, U3.1 (STAT)
unnamed: R8.1, U3.5 (PROG)
unnamed: C2.2, IC1.20 (XIN), Y1.3 (2)
unnamed: C3.2, R6.1, Y1.1
unnamed: IC1.21 (XOUT), R6.2
unnamed: FB2.1, U4.10 (OUTN)
unnamed: FB1.1, U4.9 (OUTP)
unnamed: CHG_EN.1, U3.3 (VBAT)
unnamed: D3.A, R11.2
NEOPIX_OUT: IC2.4 (O), R19.2
PIXELOUT: OUTPUTS.1, R19.1
PIXELS: IC1.32 (GPIO21), IC2.2 (I)
POWER: IC1.35 (GPIO23), Q2.1 (G), R17.1
QSPI_CS: IC1.56 (!QSPI_CS), R5.1, R11.1, U1.1 (SSEL)
QSPI_DATA[0]: IC1.53 (QSPI_SD0), U1.5 (MOSI)
QSPI_DATA[1]: IC1.55 (QSPI_SD1), U1.2 (MISO)
QSPI_DATA[2]: IC1.54 (QSPI_SD2), U1.3 (WP#/IO2)
QSPI_DATA[3]: IC1.51 (QSPI_SD3), U1.7 (HOLD#/IO3)
QSPI_SCK: IC1.52 (QSPI_SCLK), U1.6 (SCK)
RX: IC1.3 (GPIO1), JP1.3
SCK: IC1.17 (GPIO14), JP1.6
SCL: CONN1.4 (SCL), IC1.5 (GPIO3), IC4.4 (SCL), JP3.11, R14.2
SDA: CONN1.3 (SDA), IC1.4 (GPIO2), IC4.6 (SDA), JP3.12, R15.2
SERVO: IC1.31 (GPIO20), SERVO.1
SWCLK: IC1.24 (SWCLK)
SWDIO: IC1.25 (SWDIO)
TX: IC1.2 (GPIO0), JP1.2
USBBOOT: D3.C, IC1.9 (GPIO7), SW2.A, SW2.A' (P1), TP3.P$1
USB_D+: D+1.TP, R10.1, X6.A6 (D+), X6.B6 (D+)
USB_D-: D-1.TP, R9.1, X6.A7 (D-), X6.B7 (D-)
V+: C16.1, C19.1, GAIN.3, IC2.5 (VCC), OUTPUTS.3, Q1.3 (D), R18.2, SERVO.2, U4.7 (VDD), U4.8 (VDD)
VBAT: C20.1, CHG_EN.2, JP3.1, Q3.3 (D), X1.2
VBUS: CHG.A, D4.A, JP3.3, Q3.1 (G), R4.2, U3.4 (VDD), X6.A4B9 (VBUS), X6.B4A9 (VBUS)
VHI: C1.1, D4.C, Q1.2 (S), Q3.2 (S), R3.2, R16.2, U2.1 (IN)
VO+: C22.1, FB1.2, OUTPUTS.6
VO-: C21.1, FB2.2, OUTPUTS.5

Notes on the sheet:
POWER AND FILTERING
RESET
10K = 100mA
5.0K = 200mA
2.0K = 500mA
1.0K = 1000mA
USB AND BATTERY CHARGING
BREAKOUTS
RED LED
RP2040 BYPASS CAPS
USB TYPE C
QSPI STORAGE
NEOPIXEL
R1 Channel Selection: LEFT = VDD (0 Ohm) RIGHT = 370K (94*VDD-100) LEFT/2 + RIGHT/2 = 1.011M (222.2*VDD-100)
Gain=9dB



Board: 2 copper layers, 50.8 x 22.9 mm, 162 parts (51 on the bottom side), 69 nets.

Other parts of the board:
PLABEL0: PLABEL0
PLABEL1: PLABEL1
PLABEL2: PLABEL2
PLABEL3: PLABEL3
PLABEL4: PLABEL4
PLABEL5: PLABEL5
PLABEL6: PLABEL6
PLABEL7: PLABEL7
PLABEL8: PLABEL8
PLABEL9: PLABEL9
PLABEL10: PLABEL10
PLABEL11: PLABEL11
PLABEL12: PLABEL12
PLABEL13: PLABEL13
PLABEL14: PLABEL14
PLABEL15: PLABEL15
PLABEL16: PLABEL16
PLABEL17: PLABEL17
PLABEL18: PLABEL18
PLABEL19, PLABEL26: PLABEL26
PLABEL21: PLABEL21
PLABEL22: PLABEL22
PLABEL23: PLABEL23
PLABEL24: PLABEL24
PLABEL25: PLABEL25
PLABEL27: PLABEL27
PLABEL28: PLABEL28
PLABEL29: PLABEL29
PLABEL30: PLABEL30
PLABEL31: PLABEL31
PLABEL32: PLABEL32
PLABEL33: PLABEL33
PLABEL36: PLABEL36
PLABEL37: PLABEL37
PLABEL38: PLABEL38
PLABEL39: PLABEL39
PLABEL40: PLABEL40
PLABEL41: PLABEL41
PLABEL42: PLABEL42
PLABEL43: PLABEL43
PLABEL44: PLABEL44
PLABEL45: PLABEL45
PLABEL46: PLABEL46
PLABEL47: PLABEL47
PLABEL48: PLABEL48
PLABEL49: PLABEL49
PLABEL50: PLABEL50
PLABEL51: PLABEL51
PLABEL52: PLABEL52
PLABEL53: PLABEL53
PLABEL54: PLABEL54
PLABEL55: PLABEL55
PLABEL56: PLABEL56
PLABEL57: PLABEL57
PLABEL58: PLABEL58
PLABEL59: PLABEL59
PLABEL60: PLABEL60
PLABEL61: PLABEL61
PLABEL62: PLABEL62
PLABEL63: PLABEL63
PLABEL68: PLABEL68
PLABEL69: PLABEL69
PLABEL70: PLABEL70
PLABEL71: PLABEL71
PLABEL72: PLABEL72
PLABEL73: PLABEL73
PLABEL74: PLABEL74
PLABEL75: PLABEL75
PLABEL76: PLABEL76
PLABEL77: PLABEL77
PLABEL78: PLABEL78
PLABEL79: PLABEL79
PLABEL80: PLABEL80
PLABEL81: PLABEL81
PLABEL82: PLABEL82
PLABEL83: PLABEL83
PLABEL84: PLABEL84
PLABEL85: PLABEL85
PLABEL86: PLABEL86
PLABEL87: PLABEL87
PLABEL88: PLABEL88
PLABEL89: PLABEL89
U$13: PCBFEAT-REV-040
U$42: ADAFRUIT_3.5MM

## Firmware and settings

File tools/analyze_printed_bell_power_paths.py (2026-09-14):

# SPDX-License-Identifier: MIT
"""Measure the final printed-bell-power-rework PCB, without changing its copper.

Run ONLY after the generator has finished, with its final PCB SHA-256:
  python -B tools\\analyze_printed_bell_power_paths.py --pcb-sha256 <64 hex digits>

Writes only that package's reports/power-path-measurements.{json,md}. Requires
the existing KiCad 10.0.6 Python API and numpy; installs nothing. --help does not
import the generator or load a board. No DRC, generation, or parent review runs.

This is a finite, overlap-aware, shortest sampled geometric walk, NOT a 2-D
resistance solver. Finite pad travel is included. A conservative chosen-strip
1-D resistance screen and exposed-centerline neck inventory accompany each
walk; neither is an equivalent resistance or a thermal/current qualification.
An open path never acquires a fabricated round-trip resistance.
"""
from __future__ import annotations

import argparse
from collections import Counter, defaultdict
from datetime import datetime, timezone
import hashlib
import heapq
import itertools
import json
import math
from pathlib import Path
import re
import sys
import tempfile

ROOT = Path(__file__).resolve().parents[1]
SOURCE = ROOT / "hardware" / "handbell" / "iterations" / "printed-bell-routing"
OUTPUT = SOURCE.parent / "printed-bell-power-rework"
RHO = .0172                       # ohm.mm^2/m, nominal 20 C
FOIL_MM = .035
BOARD_MM = 1.6
WALL_MM = .025
HOT_FACTOR = 1.35
VIA_HOT_FACTOR = 1 + .00393 * 40
EPS = .000002                    # mm; native polygonization is bounded at 1 nm
SLICE_MM = .25
NECK_WIDTH_MM = .35
np = None                        # Loaded only for an explicitly requested final PCB.
EXPECTED_NETS = {
    "cell_vbat": "VBAT", "cell_vhi": "VHI", "cell_vplus": "V+", "cell_gnd": "GND",
    "cell_prot_a2": "/PROT_FET_RETURN", "cell_prot_c2": "/PROT_FET_RETURN",
    "cell_neg_a1": "/CELL_NEG", "cell_neg_c1": "/CELL_NEG",
    "v5_to_bulk": "VAMP", "v5_to_amp7": "VAMP", "v5_to_amp8": "VAMP",
    "v5_return_thermal": "GND", "v5_return_11": "GND", "v5_bulk_return": "GND",
    "sw_escape": "BOOST_SW", "input_cap_feed": "V+", "vin_bias": "V+",
    "feedback_ground": "GND", "protector_sense": "GND", "amp_local_ground11": "GND",
}

ASSUMPTIONS = [
    "Native KiCad copper, not authored route groups, owns connectivity and path selection.",
    "Only F.Cu/B.Cu straight tracks, native pads and through vias are supported; no zones/arcs.",
    "Native inward copper polygons and outward drill polygons use a 1 nm polygonization bound; "
    "positive-width walk contacts use a 2 nm numerical guard. Boundary-only contact is not a usable walk.",
    "Dijkstra minimizes XY walk length plus 1.6 mm per layer transition on a finite portal graph. "
    "It is not the exact geometric shortest path, least-resistance path, or a 2-D current solution.",
    "An identical-XY overlap join has zero length; travel across a pad or between different contacts "
    "does not. Separate physical pads sharing a pin number are never internally shorted.",
    "Foil screening uses rho*L/(w*t). Each <=0.25 mm walk slice uses an inscribed strip width "
    "equal to twice its minimum distance to the same-net copper-union boundary, including holes.",
    "These restrictive chosen-strip estimates intentionally ignore parallel current redistribution. "
    "They can overstate drop; bends, junction spreading, barrel entry crowding, terminal injection "
    "and overlapping strips prevent calling them a rigorous upper bound or equivalent resistance.",
    "Neck inventory subtracts actual same-net pad, via-annulus and strictly broader-track coverage "
    "from drawn centerlines. Coverage is not proof of full-width bypass or absence of a 2-D bottleneck.",
    "A chosen-path current is a conditional load case, not a measured branch current. Bias, sense, "
    "feedback and capacitor-ripple spurs receive no blanket 2 A assignment.",
    "Nominal foil is assumed 35 um/20 C. The requested 30 um/60 C sensitivity is 1.35x nominal. "
    "60 C is a calculation case, not an allowed cell/enclosure temperature.",
    "Via DCR uses thin-wall rho*board_thickness/(pi*drill*wall), conditional on 25 um wall plating "
    "and 1.6 mm board thickness. Neither plating nor finished copper is selected/qualified.",
    "Each selected barrel is charged once per traversal at its full conditional DCR. No equal "
    "sharing, parallel Q5 via division, or thermal-via-array resistance reduction is assumed.",
    "JSON decimal places preserve computational reproducibility, not measurement accuracy. "
    "Markdown resistance/drop screens are intentionally shown to about two significant digits.",
    "A barrel edge is a lumped annulus-to-annulus connection, not a vertical copper column at "
    "the reported annular XY port; its entry/exit spreading is not solved.",
    "Cell copper sections are concatenated only conditionally across the excluded ON-state "
    "selector/audio/protector FETs, shunt and converter. No copper edge bridges different nets.",
    "Copper budgets exclude contacts, solder interfaces, FETs, the deliberate 33 mOhm shunt, "
    "inductor winding, IC internals and capacitor ESR. These are separate additional losses.",
    "No IPC-2152 or 10 C temperature-rise claim, ampacity, functional, fault, fabrication, "
    "mechanical, live-cell or child-use signoff follows. Prior QSPI/GND losses are not waived.",
]


def require(condition, message):
    if not condition:
        raise ValueError(message)


def sha(path):
    return hashlib.sha256(Path(path).read_bytes()).hexdigest()


def read_json(path):
    return json.loads(Path(path).read_text(encoding="utf-8-sig"))


def rounded(value):
    return round(float(value), 6)


def xy(point):
    return [rounded(v - 100) for v in point]


def interpolate(a, b, fraction):
    return tuple(a[i] + fraction * (b[i] - a[i]) for i in (0, 1))


def merge_intervals(intervals):
    result = []
    for start, end in sorted(intervals):
        if end <= start:
            continue
        if result and start <= result[-1][1] + 1e-10:
            result[-1][1] = max(result[-1][1], end)
        else:
            result.append([start, end])
    return result


def complement(intervals):
    result, cursor = [], 0.
    for start, end in merge_intervals(intervals):
        if start > cursor:
            result.append([cursor, start])
        cursor = max(cursor, end)
    if cursor < 1:
        result.append([cursor, 1.])
    return result


def foil_mohm(length, width):
    return RHO * length / (width * FOIL_MM)


def barrel_mohm(drill):
    return RHO * BOARD_MM / (math.pi * drill * WALL_MM)


def resistance_record(foil, barrels):
    nominal = foil + barrels
    return {
        "foil_35um_20C_mOhm": rounded(foil),
        "barrels_conditional_25um_wall_20C_mOhm": rounded(barrels),
        "nominal_chosen_strip_mOhm": rounded(nominal),
        "requested_1p35x_total_mOhm": rounded(nominal * HOT_FACTOR),
        "foil_1p35x_plus_same_wall_barrels_60C_mOhm":
            rounded(foil * HOT_FACTOR + barrels * VIA_HOT_FACTOR),
        "interpretation": "1-D chosen-strip screen; NOT equivalent R or a rigorous upper bound",
    }


def coherent_inputs(check, route, expected):
    """Fail before loading native copper if the generated package is in flight."""
    require(route.ROOT == ROOT and route.SOURCE == SOURCE and route.OUTPUT == OUTPUT,
            "Generator package paths changed; review analyzer scope")
    build = read_json(OUTPUT / "routing-build.json")
    manifest = read_json(OUTPUT / "placement-manifest.json")
    require(sha(OUTPUT / "handbell.kicad_pcb") == expected == build["pcb_sha256"]
            == manifest["generated_pcb_sha256"], "Final PCB/build/manifest hash mismatch; do not analyze an in-flight build")
    require(build["script_sha256"] == sha(route.__file__), "Generator changed since this PCB was built")
    require(build.get("protected_files") and build.get("source_bindings"), "Missing generator coherence bindings")
    paths = {
        Path(__file__), Path(check.__file__), Path(route.__file__),
        ROOT / "tools" / "route_printed_bell.py", ROOT / "tools" / "kicad_sexpr.py",
        Path(route.prep.__file__), OUTPUT / "handbell.kicad_pcb",
        OUTPUT / "routing-data.json", OUTPUT / "routing-build.json",
        OUTPUT / "placement-manifest.json", SOURCE / "handbell.kicad_pcb",
        SOURCE / "routing-data.json", SOURCE / "placement-manifest.json",
        SOURCE / "reports" / "power-routing-review.md",
    }
    for name, digest in check.PINNED_SOURCE.items():
        require(sha(SOURCE / name) == digest, "Frozen source changed: " + name)
    for mapping, base in ((build["protected_files"], OUTPUT), (build["source_bindings"], ROOT)):
        for name, digest in mapping.items():
            path = (base / name).resolve()
            require(path.is_relative_to(base), "Binding escapes its allowed root: " + name)
            require(sha(path) == digest, "Stale build dependency: " + name)
            paths.add(path)
    bindings = {str(p.relative_to(ROOT)): sha(p) for p in sorted(paths)}
    require(bindings[str(OUTPUT.relative_to(ROOT) / "handbell.kicad_pcb")] == expected,
            "PCB changed while capturing bindings")
    return bindings, build


def assert_unchanged(bindings):
    for name, digest in bindings.items():
        require(sha(ROOT / name) == digest, "Inputs changed during analysis; discard this run: " + name)


def route_inventory(check, package):
    """Match every authored record to native literal copper before using labels."""
    _, board = check.literal_board(package / "handbell.kicad_pcb")
    require(not any(board.children(kind) for kind in ("zone", "arc", "group")),
            "Zones/arcs/groups require a new native path model")
    data = read_json(package / "routing-data.json")
    records = {}
    for kind, field in (("segment", "tracks"), ("via", "vias")):
        nodes, rows = board.children(kind), data[field]
        require(len(nodes) == len(rows), f"{package.name}: native/{field} inventory mismatch")
        for node, row in zip(nodes, rows):
            uid = node.value("uuid")
            require(uid and uid not in records, "Missing/duplicate native copper UUID")
            require(node.value("net") == row["net"], "Native/route-data net mismatch")
            if kind == "segment":
                for key, value in (("start", row["a"]), ("end", row["b"])):
                    native = list(map(float, node.child(key).atoms()[1:3]))
                    require(len(value) == 2 and all(math.isfinite(x) for x in value)
                            and math.dist(native, [x + 100 for x in value]) < EPS,
                            "Native/route-data track position mismatch")
                require(node.value("layer") == row["layer"] and row["layer"] in ("F.Cu", "B.Cu")
                        and abs(float(node.value("width")) - row["width"]) < EPS
                        and row["width"] > 0 and math.dist(row["a"], row["b"]) > EPS,
                        "Unsupported/mismatched native track")
            else:
                native = list(map(float, node.child("at").atoms()[1:3]))
                require(math.dist(native, [x + 100 for x in row["xy"]]) < EPS
                        and abs(float(node.value("size")) - row["diameter"]) < EPS
                        and abs(float(node.value("drill")) - row["drill"]) < EPS
                        and row["diameter"] > row["drill"] > 0
                        and node.child("layers").atoms()[1:] == ["F.Cu", "B.Cu"],
                        "Unsupported/mismatched native via")
            records[uid] = {"kind": kind, **row}
    return records


class Polygon:
    """Native polygon plus vectorized boundary-distance and line-clipping queries."""

    def __init__(self, pcb, native):
        self.pcb, self.native = pcb, native
        self.rings, self.outlines = [], []
        for index in range(native.OutlineCount()):
            chains = [native.Outline(index)]
            chains.extend(native.Hole(index, h) for h in range(native.HoleCount(index)))
            for offset, chain in enumerate(chains):
                points = [(pcb.ToMM(chain.CPoint(i).x), pcb.ToMM(chain.CPoint(i).y))
                          for i in range(chain.PointCount())]
                if len(points) >= 3:
                    self.rings.append(points)
                    if offset == 0:
                        self.outlines.append(points)
        require(self.rings, "Empty copper polygon needs an explicit unavailable result")
        self.a = np.array([p for ring in self.rings for p in ring], dtype=float)
        self.b = np.array([p for ring in self.rings for p in ring[1:] + ring[:1]], dtype=float)
        self.delta = self.b - self.a
        self.denominator = np.sum(self.delta * self.delta, axis=1)
        self.denominator[self.denominator == 0] = 1

    def contains(self, point):
        return self.native.Contains(self.pcb.VECTOR2I(*(round(x * 1e6) for x in point)))

    def point_clearance(self, point):
        point = np.asarray(point)
        t = np.clip(np.sum((point - self.a) * self.delta, axis=1) / self.denominator, 0, 1)
        return float(np.sqrt(np.min(np.sum((point - self.a - t[:, None] * self.delta) ** 2, axis=1))))

    def crossings(self, start, end):
        start, end = np.asarray(start), np.asarray(end)
        d = end - start
        e, v = self.delta, self.a - start
        cross = d[0] * e[:, 1] - d[1] * e[:, 0]
        good = np.abs(cross) > 1e-14
        t = np.zeros(len(cross))
        u = np.zeros(len(cross))
        t[good] = (v[good, 0] * e[good, 1] - v[good, 1] * e[good, 0]) / cross[good]
        u[good] = (v[good, 0] * d[1] - v[good, 1] * d[0]) / cross[good]
        hits = good & (t >= 0) & (t <= 1) & (u >= 0) & (u <= 1)
        return t[hits].tolist()

    def covered_intervals(self, start, end):
        if math.dist(start, end) <= EPS:
            return [[0., 1.]] if self.contains(start) else []
        cuts = sorted({0., 1., *self.crossings(start, end)})
        return merge_intervals([[a, b] for a, b in zip(cuts, cuts[1:])
                                if self.contains(interpolate(start, end, (a + b) / 2))])

    def segment_clearance(self, start, end):
        if not self.contains(start) or not self.contains(end) or self.crossings(start, end):
            return 0.
        start, end = np.asarray(start), np.asarray(end)
        d = end - start
        length2 = float(np.dot(d, d))
        if length2 == 0:
            return self.point_clearance(start)
        t = np.clip(np.sum((self.a - start) * d, axis=1) / length2, 0, 1)
        vertex_distance = np.sqrt(np.min(np.sum((self.a - start - t[:, None] * d) ** 2, axis=1)))
        return min(self.point_clearance(start), self.point_clearance(end), float(vertex_distance))

    def candidates(self, seeds=(), limit=3):
        candidates = list(seeds)
        for ring in self.outlines:
            xs, ys = zip(*ring)
            candidates.append((sum(xs) / len(xs), sum(ys) / len(ys)))
            for x in (.2, .5, .8):
                for y in (.2, .5, .8):
                    candidates.append((min(xs) + x * (max(xs) - min(xs)),
                                       min(ys) + y * (max(ys) - min(ys))))
        scores = []
        for p in sorted({tuple(round(v, 6) for v in p) for p in candidates}):
            if self.contains(p):
                clearance = self.point_clearance(p)
                if clearance > EPS:
                    scores.append((clearance, p))
        scores.sort(reverse=True)
        result = []
        for _, point in scores:
            if not result or min(math.dist(point, p) for p in result) > .02:
                result.append(point)
            if len(result) == limit:
                break
        return result
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

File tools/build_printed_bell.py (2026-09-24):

#!/usr/bin/env python3
"""Original September 13 printed bell. Headless FreeCAD, exact input binding.

Without --placement, explicitly writes DEVELOPMENT only. Final mode requires
all-front electronics and the unchanged, translated T8 contact interface.
"""
from __future__ import annotations

import argparse
import base64
import copy
from datetime import datetime, timezone
import hashlib
import json
import math
import os
from pathlib import Path
import shutil
import subprocess
import sys
import uuid
import zipfile

sys.dont_write_bytecode = True
sys.path.insert(0, str(Path(__file__).resolve().parent))
import build_mechanical as base
import build_t8_cartridge as helpers

ROOT = Path(__file__).resolve().parents[1]
STUDY = ROOT / "mechanical" / "studies" / "2026-09-13-printed-bell"
T8 = ROOT / "mechanical" / "studies" / "2026-09-11-t8-cartridge"
INPUT = ROOT / "docs" / "design-inputs" / "2026-09-13-printed-bell.json"
SHIFT = 10.75
EPS = 1e-5
BODY_H = 55.8
USB_PROFILES = {
    "legacy_cusb31": {
        "geometry": {
            "x_mm": 0.0, "y_mm": -23.935, "width_mm": 9.64,
            "depth_mm": 7.93, "height_mm": 3.5, "rotation_deg": -180.0,
        },
        "native_origin_common_xy_mm": [0.0, -22.82],
        "skin_center_y_mm": -28.6,
        "connector_front_y_mm": -27.9,
    },
    "hro_type_c_31_m_12": {
        "mpn": "TYPE-C-31-M-12",
        "footprint": "Handbell:USB_C_HRO_TYPE_C_31_M_12_Handbell",
        "geometry": {
            "x_mm": 0.0, "y_mm": -24.01, "width_mm": 9.64,
            "depth_mm": 8.08, "height_mm": 3.5, "rotation_deg": -180.0,
        },
        "native_origin_common_xy_mm": [0.0, -22.82],
        "skin_center_y_mm": -28.75,
        "connector_front_y_mm": -28.05,
    },
}
OUTER = [
    [(35, 0), (31.5, 5), (28.7, 14), (27.0, 27)],
    [(27.0, 27), (26.25, 33), (24.9, 38), (23.9, 42)],
    [(23.9, 42), (22.0, 49.6), (17, 55.8), (10, 55.8)],
]
INNER = [
    [(33.0, 0), (29.5, 5), (26.7, 14), (25.0, 27)],
    [(25.0, 27), (24.25, 33), (22.9, 38), (21.9, 42)],
    [(21.9, 42), (21.4, 44), (21, 45.0), (20.5, 46.5)],
    [(20.5, 46.5), (17, 48), (11.0, 51.3), (6.3, 51.3)],
]
HANDLE = [
    [(10, 55.8), (10, 61.8), (8, 67), (7.7, 77.8)],
    [(7.7, 77.8), (7.2, 95), (8.2, 107), (10.5, 117.8)],
    [(10.5, 117.8), (12.7, 128), (11.5, 135.8), (0, 135.8)],
]


def write(path, data):
    path.write_text(json.dumps(data, indent=2, allow_nan=False) + "\n", encoding="utf-8")


def sha(path):
    return hashlib.sha256(path.read_bytes()).hexdigest()


def args_parser():
    p = argparse.ArgumentParser(description=__doc__)
    p.add_argument("--placement", type=Path)
    p.add_argument("--output", type=Path)
    p.add_argument("--freecad-cmd", type=Path, default=Path(os.environ.get("LOCALAPPDATA", "")) /
                   "Programs" / "FreeCAD 1.1" / "bin" / "FreeCADCmd.exe")
    p.add_argument("--launch-timeout-seconds", type=int, default=2400)
    p.add_argument("--inside-freecad", action="store_true", help=argparse.SUPPRESS)
    p.add_argument("--token", help=argparse.SUPPRESS)
    p.add_argument("--expected", help=argparse.SUPPRESS)
    p.add_argument("--marker", type=Path, help=argparse.SUPPRESS)
    args = p.parse_args()
    if args.launch_timeout_seconds <= 0:
        p.error("--launch-timeout-seconds must be positive")
    return args


def translated_contact(source):
    c = copy.deepcopy(source)
    c["pcb_z_mm"] += SHIFT
    c["cell_nominal"]["center_mm"][2] += SHIFT
    for contact in c["contacts"]:
        contact["center_mm"][2] += SHIFT
        for pad in contact["pads"]:
            pad["center_mm"][2] += SHIFT
    primitives = c["right_contact_original_primitives"]
    for part in primitives["base_tabs"] + [primitives["under_cell_base"]]:
        part["z_min"] += SHIFT
    for point in primitives["spring_xz_polyline"]:
        point[1] += SHIFT
    primitives["ears"]["axis_center_yz"][1] += SHIFT
    return c


def numeric_contract(value):
    """Compare geometric records, allowing descriptive provenance text to evolve."""
    if isinstance(value, dict):
        return {k: numeric_contract(v) for k, v in value.items()
                if not isinstance(v, str) or k in ("reference", "polarity", "net", "cell_axis", "pcb_side")}
    if isinstance(value, list):
        return [numeric_contract(v) for v in value]
    if isinstance(value, (float, int)):
        return round(value, 7)
    return value


def approved_usb_profile(manifest):
    usb = next(c for c in manifest["components"] if c["reference"] == "X6")
    for name, profile in USB_PROFILES.items():
        geometry_matches = all(
            abs(usb[key]-expected) <= EPS
            for key, expected in profile["geometry"].items()
        )
        if not geometry_matches or usb["side"] != "F":
            continue
        if name == "hro_type_c_31_m_12" and (
            usb.get("mpn") != profile["mpn"]
            or usb.get("footprint") != profile["footprint"]
            or len(usb.get("native_origin_common_xy_mm", [])) != 2
            or not all(abs(actual-expected) <= EPS for actual, expected in zip(
                usb["native_origin_common_xy_mm"],
                profile["native_origin_common_xy_mm"],
            ))
        ):
            continue
        selected = copy.deepcopy(profile)
        selected["name"] = name
        selected["skin_front_y_mm"] = selected["skin_center_y_mm"]-.5
        selected["skin_rear_y_mm"] = selected["skin_center_y_mm"]+.5
        selected["connector_to_skin_rear_gap_mm"] = (
            selected["connector_front_y_mm"]-selected["skin_rear_y_mm"]
        )
        return selected
    raise ValueError("USB profile is neither the frozen legacy geometry nor the exact reviewed HRO variant")
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

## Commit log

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2026-09-07 Install-ready KiCad reference with preserved Adafruit sources and import evidence
    Add the licensed 5768 EAGLE sources and native KiCad conversion, project-local libraries, schematic PDF, initial ERC report, and Windows setup guide. Record connected-net equivalence and unresolved c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
    [Adafruit Feather RP2040 Prop-Maker.brd, Adafruit Feather RP2040 Prop-Maker.kicad_pcb, Adafruit Feather RP2040 Prop-Maker.kicad_sch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]
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2026-09-07 Integrate LSM6DSOX schematic and resolve reference ERC
    Add the licensed Adafruit 4438 source/native reference, a separate Mode 1 handbell schematic, all 50 ERC dispositions, strict connectivity and pad checks, a BOM draft, and the documented driver bring-up gate. Preserve the original reference and historical artifacts.
    [Adafruit_LSM6DSOX.brd, Adafruit_LSM6DSOX.kicad_pcb, Adafruit_LSM6DSOX.kicad_sch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]
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2026-09-07 Add reduced handbell electronics and printable fit-study kit
    Implement the licensed TPS61023 boost, mute/button and connector reduction; preserve explicit electrical and native placement evidence. Add the 43 mm unrouted candidate, editable FreeCAD assembly, po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
    [Adafruit TPS61023.brd, Adafruit TPS61023.kicad_pcb, Adafruit TPS61023.kicad_sch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]
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2026-09-09 Record measured speaker geometry and compare PCB battery contacts
    Preserve the original print kit while adding a separate FreeCAD/STEP/STL study from the owner's September 9 dimensions. Screen six outward-facing PCB depths and five battery bodies, retaining all interference and contact/retention uncertainty. Document manufacturer-backed Keystone SMT/TH contacts, exact cell leads, print feedback and the remaining layout/structural gates.
    [measured-speaker-study.FCStd, outward-body-screen.step, speaker-full-body-cylinder.step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]
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2026-09-12 Publish measured-shell T8 cartridge review assembly
    Bind the four-piece serviceable cartridge to the protected 83-part placement, preserve fixed-stack evidence, and record the owner-requested spacing comparison. Retain all routing, physical fit and live-cell qualification gates.
    [INERT-T8-full-cell.stl, INERT-battery-cover.stl, INERT-battery-cradle.stl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]
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2026-09-14 Place all electronic SMT parts on the 43 mm front face
    Preserve the T8 circuit, physical pad geometry and contact/mount/USB datums; consolidate 81 electronic parts on F while retaining two real B-side contact operations. Publish the independent stage-1 f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
    [bom-draft.csv, footprint-movements.csv, handbell.kicad_pcb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]
2026-09-14 Checkpoint the printed-bell interface and authorize critical routing
    Preserve the D70/H55.8 all-front assembly, keyed M4 handle and exact mechanical release. Record the parent visual finding on exterior nut-pocket openings for correction before the final print handoff; PCB interfaces remain fixed.
    [INERT-black-handle.stl, INERT-cell-cover.stl, INERT-cell-cradle.stl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]
2026-09-14 Refine the printed bell exterior and publish original CAD views
    Close exterior nut pockets with real wall stock, add a defined thin USB port face, preserve the fixed PCB interfaces, and publish the portable exterior/profile/grille/cutaway renderer with source bindings. Document the keyed M4 handle, inert print set and remaining qualification gates.
    [INERT-flush-carrier.stl, INERT-pcba-without-contacts.step, INERT-shell.stl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]
2026-09-14 Checkpoint partial PCB routing and readable battery service labels
    Preserve the immutable placement and mechanical release; record actual tracks, endpoint connectivity and unfinished nets. High-current widths/returns/hot-loop review remains an explicit open gate, no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
    [bom-draft.csv, handbell.kicad_pcb, handbell.kicad_sch]
2026-09-14 Add exact routed-model service-label recheck without circular bindings
    Keep immutable capture evidence intact and require a completed current model embedding the routed PCB before writing the separate final visibility report. Refresh native reports for the changed helper; no copper or component geometry changes.
2026-09-14 Record independent power-route findings and require boost/sense rework
    Preserve the initial native candidate as evidence. Prioritize the actual output-capacitor hot loop and quiet protector pickoff, distinguish overlaps and low-current spurs from load bottlenecks, and record provisional current/copper/drop assumptions without claiming ampacity.
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2026-09-14 Publish power-loop rework and exact printed-bell assembly
    Retain partial-routing and current-budget limits, record USB slot-import and quotation gates, and preserve reproducible raw source bytes. Refs #2, #4, #5, #7, #8.
    [INERT-pcba-without-contacts.step, INERT-pcba-without-contacts.stl, black-handle.step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]
2026-09-14 Resolve current HRO drawing and specify USB DFM correction
    Separate manufacturer dimensions from the engineered slot/annulus/pad changes, explicit secondary anchor soldering, and required bezel clearance update. Refs #2, #4, #5, #7, #8.
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2026-09-14 Source device identities and document package-envelope corrections
    Select eleven formerly blank device identities, confirm Q4, preserve package/polarity/thermal-process gates, and keep Q3/Y1 decisions explicit. Refs #4, #5, #7, #8.
2026-09-14 Select sourced Q3 replacement and bound the clock-reference decision
    Preserve the corrected DFN topology, document electrical and lifecycle differences, and evaluate the tested RP2040 crystal within the unchanged board outline.
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2026-09-14 Checkpoint isolated clock definitions and bounded engineering workflow
    Clock routing and local clearance remain pending; preserve exact recovered inputs and inherited CAD source whitespace.
    [handbell.kicad_pcb, handbell.kicad_sch]
2026-09-14 Route first local clock connections with bounded native evidence
    Add 15 F-side segments without moves or vias; retain unfinished MCU approaches, final returns and three library mismatch gates.
    [handbell.kicad_pcb]
2026-09-14 Align clock SMD library attributes without changing copper
    Record owner-authorized sequential bounded work and remove exactly three clock library mismatches.
    [handbell.kicad_pcb]
2026-09-14 Preserve blocked all-front clock proposal without changing the PCB
    C3 candidate clearance fails the configured minimum; retain exact obstacle evidence and stop the exhausted-retry item.
2026-09-14 Complete local clock network with all-front signals and returns
    Preserve fixed interfaces and nonclock copper; document exact four-part moves, native evidence and two-retry bounded workflow.
    [handbell.kicad_pcb]
2026-09-14 Apply selected Q3 identity while retaining corrected native geometry
    Preserve circuitry, copper and placements; publish scoped native identity and schematic evidence.
    [handbell.kicad_pcb, handbell.kicad_sch]
2026-09-14 Apply approved ordinary resistor identities without changing circuit values
    Fill23 blank MPNs and confirm4; preserve circuit-reference links and all geometry/copper.
    [handbell.kicad_pcb, handbell.kicad_sch]
2026-09-14 Apply selected non-boost capacitor identities without changing values
    Fill23 missing MPNs and confirm3; retain clock revision, all geometry/copper and outstanding land/process gates.
    [handbell.kicad_pcb, handbell.kicad_sch]
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2026-09-14 Accept recorded ground fill restoring C25 without placement changes
    Preserve previous connected groups and protected returns; 57 opens remain. Add a standalone source-preserving refill recipe.
    [handbell.kicad_pcb]
2026-09-14 Correct USB slots and lands with local VBUS and CC route repairs
    Restore source-bound slot geometry and secondary-anchor process; preserve 57 remaining opens and protected returns with zero native DRC errors.
    [handbell.kicad_pcb, handbell.kicad_sch]
2026-09-14 Complete all 83 native part identities in one geometry-preserving batch
    Apply the remaining 17 selected device and power identities; retain source geometry and publish one complete-identity schematic view.
    [handbell.kicad_pcb, handbell.kicad_sch]
2026-09-14 Land selected power footprints and publish standalone ground checks
    Preserve existing copper and quiet pickoffs across eleven land revisions. Publish the source-bound 56-open checkpoint, reusable fill plan/checker, and owner-requested pause handoff.
    [handbell.kicad_pcb, handbell.kicad_sch]
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2026-09-15 Close boost and shunt lands with bounded local repairs
    Apply recorded U5/R27 patterns and envelopes. Preserve trace widths and fixed poses; enlarge the R27.2 exclusion with its land. Reuse unaffected primitive evidence and bind the final filled continuity proof.
    [handbell.kicad_pcb, handbell.kicad_sch]
2026-09-15 Route the left core decoupling link with a local 3V3 correction
    Add three front-side VCORE segments and move one 3V3 bend 0.15 mm without narrowing it. Require the exact IC1.23/C18.2 connection in the reused ground checker; preserve earlier groups and capture the two remaining blocked approaches.
    [handbell.kicad_pcb]
2026-09-15 Connect C6 core supply and shorten the QSPI detour
    Preserve courtyard geometry through four small capacitor moves and a matching core bridge adjustment. No new vias or narrower existing tracks; retain QSPI, prior groups and private returns.
    [handbell.kicad_pcb]
2026-09-15 Preserve blocked C8 corridor experiment without changing accepted copper
    Record the VHI intersection, residual 3V3 stubs and blocked contact-base shortcut. Keep the 53-open accepted board unchanged and bound the next review to the VHI/core corridor.
2026-09-15 Free the MCU power corridor and connect the regulator output
    Retain all nine ground vias in a staggered array and move the unchanged-width VHI feed through the central B neck. Reuse the C8 experiment, preserve contact exclusions and prior connectivity, and rec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
    [handbell.kicad_pcb]
2026-09-15 Record bounded offline routing pilot and reusable tooling lessons
    Preserve the accepted board; document timed-out route attempts, corrected settings, no-route exchange observations and pinned local tools.
2026-09-15 Preserve bounded VCORE attempt and connected-group routing diagnosis
    Reuse native obstacle masks and the existing bounded search. Record C7 as a reachable terminal on the C8 group; do not mistake fixed-pad grid failure for a required layout change. Accepted PCB unchanged.
2026-09-15 Preserve rejected VCORE route and coupled ground-repair limits
    Keep the accepted board unchanged after refill exposes two new local ground breaks. Record bounded ground-first corrections and stop this affected routing item.
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2026-09-15 Connect the charge-indicator branch with preserved ground continuity
    Accept seven 0.20 mm front tracks between R2 and CHG0. Preserve existing copper, parts, vias, schematic and private returns; 51 opens remain.
    [handbell.kicad_pcb]
2026-09-16 Archive routing recovery and checkpoint paused SCL work
    Preserve the historical quote-candidate recovery separately from the accepted 51-open clock draft. Save unfinished SCL anchor tooling and attempt evidence. Record the September 16 owner pause; no fur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
    [completion-input.dsn, ground-fill-input.kicad_pcb, handbell.kicad_pcb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]
2026-09-21 Establish pinned Sol routing executor and preserve SCL escalation
    Keep Astra engineering authority, document fail-closed subagent dispatch and runtime caveats, and preserve the final constrained SCL experiment without changing the accepted board.
2026-09-21 Preserve R14 terminal-access screen and bound failed diagnostics
    Record unchanged accepted layout, local supply and return constraints, failed in-memory reversal and executor scope deviation. Retain only a read-only diagnostic and require joint R14 placement review before further routing.
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2026-09-21 Establish four-layer baseline and efficient Sol routing contract
    Preserve the two-layer source and all existing geometry, enable two inner layers, and bind logical migration evidence. Define corridor batches, all-layer validation gates, protected-ground policy and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
    [handbell.kicad_pcb, handbell.kicad_sch]
2026-09-21 Preserve partial multilayer graph qualification and fixture blocker
    Generalize enabled-layer and plated-span graph handling without production copper changes. Record passed primitive controls and native-fill fixture failures, preserve fail-closed layer handling, and bind reused fingerprint evidence to exact inputs. Inner routing remains unreleased.
    [check_four_layer_graph.py, check_printed_bell_power_rework.py]
2026-09-21 Preserve failed file-based control and disable unqualified reruns
    Record native plane-creator failure before CLI refill, lost temporary evidence and remaining harness validity issues. Preserve production board hashes and stop automatic retries instead of weakening the graph qualification gate.
    [check_four_layer_graph.py]
2026-09-21 Qualify inner-layer graph checks with saved native controls
    Use source-derived file fixtures and isolated CLI refill/save instead of unsafe native fixture creation. Verify exact short UUIDs, via/island-only connectivity and same-net layer isolation; retain stage evidence, reject stale workspaces and sanitize public paths. Production board unchanged; legacy route search remains unqualified.
    [check_four_layer_graph.py]
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2026-09-23 Accept first protected inner-ground plane routing baseline
    Resume owner-authorized work; promote exact reviewed candidate and rebind manifest metadata. Preserve 137 prior groups and private returns, reduce opens from 51 to 49, retain source-bound native whit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
    [handbell.kicad_pcb]
2026-09-23 Resolve core groups and release existing-via supply bridge
    Keep VCORE escape blockers explicit; release bounded 0.4 mm In2 +3V3 bridge above the clock void without new vias or placement changes.
2026-09-23 Connect 3V3 groups through existing vias on In2
    Accept exact 0.4mm supply bridge, preserve all prior copper and planes, bind source evidence and release bounded local supply-ground stitches. 48 opens remain.
    [handbell.kicad_pcb]
2026-09-23 Preserve rejected supply-ground batch and exact stop condition
    Keep accepted 48-open board unchanged; record saved candidate hashes, exhausted corrections and pending layer-specific guard diagnosis.
2026-09-23 Identify layer-mapping error in ground-stitch validation
    Record identical erroneous intersections on baseline and candidate; authorize only corrected read-only validation, not more geometry attempts.
2026-09-23 Checkpoint incomplete ground-stitch validation and stop corrections
    Preserve passing guard/connectivity evidence and distinct validator failures; drill/contact/fill gates incomplete, accepted board remains at 48 opens. Require explicit next-item decision.
2026-09-23 Accept validated R4 ground stitch and preserve native API controls
    Promote exact saved candidate: 47 opens, unchanged F/In1 fill, preserved private returns and connected groups. Keep C9 local high-frequency return unqualified and historical validator failures intact.
    [handbell.kicad_pcb]
2026-09-23 Preserve sparse ground screen and release fixed radial follow-up
    No copper changes. Distinguish four axis samples from geometric exhaustion; retain all layout constraints for bounded multi-radius sampling.
2026-09-23 Connect three supply-ground groups with validated local stitches
    Promote exact radial batch: 44 opens, unchanged planes and existing routing, preserved private returns. Retain finite C12/C23/C24 blockers and qualification limits.
    [handbell.kicad_pcb]
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2026-09-23 Preserve blocked C23 final-gate attempt and stop correction loop
    Input bindings passed, but a DRC-path correction was followed by an unavailable KiCad unit constant. Remaining acceptance gates were not executed; retain accepted 44-open board and staged candidate pending owner-authorized isolated validator repair.
2026-09-23 Archive C23 candidate and completed gates at validator stop
    Native controls and whole-board preservation, connectivity, private returns and clearance checks pass. A microscopic difference-fragment attachment assertion stops the review before remaining gates; preserve exact candidate bytes and escalate rather than extending the repair loop.
    [c23-usbboot-staged.kicad_pcb]
2026-09-23 Authorize actual-island attachment proof for remaining C23 gates
    Record explicit owner decision. Preserve independent displacement and clearance requirements; no routing, refill or automatic promotion.
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2026-09-23 Release bounded paired C12 supply and ground trial
    Preserve failed whole-island GND-via screen. Test nine ordinary power-via sites to replace only the necessary upstream feed while keeping local decoupling copper and requiring ground closure; no unrelated rerouting or placement changes.
2026-09-23 Accept paired C12 feed replacement and ground closure
    Promote exact 42-open board with one ordinary power via, preserving local decoupling copper and private returns. Review local antipad and bounded refill differences; release only a bounded ordinary C24 ground connection next.
    [handbell.kicad_pcb]
2026-09-23 Preserve C24 local blockers and bound via-in-pad feasibility review
    Four bridges and 48 ordinary-via proposals failed fixed constraints without changing the board. Inspect two existing through-via definitions at C24 ground pad only; no rule relaxation, blind vias, rerouting or process acceptance.
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2026-09-23 Checkpoint blocked IMU return batch without expanding search
    Preserve finite bridge/via screen failures and unchanged 41-open source. Stop at the correction limit; recommend a bounded native feasible-region diagnostic before any further IMU routing changes.
2026-09-23 Pause engineering for shutdown with exact IMU resume handoff
    Owner pauses until explicit resume. Preserve accepted 41-open board and failed IMU screen; next intended task is bounded read-only feasible-space analysis, not continued routing.
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2026-09-23 Checkpoint IMU feasible regions and bound local power-track diagnosis
    No legal connection survived the native region/stub checks. Preserve unchanged 41-open board; inspect only four named F supply-track exclusions and their topology in memory, with full contact clearance and no routing changes.
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2026-09-23 Authorize bounded coordinated IMU layout proposal
    Record owner's proposal-only approval. Compare fixed placement with three small cluster translations while preserving board interfaces and outside circuitry; no routing or placement implementation is released.
2026-09-23 Prefer fixed IMU placement after coordinated comparison
    Preserve four-case proposal. North shifts add fixed conflicts without improving screened signal escapes; case A still needs mutually compatible return and signal routing. No design changes or wholesale local-track removal authorized.
2026-09-23 Authorize fixed IMU rework trial and bottleneck-first closure plan
    Record owner approval and prioritize coupled escape, return and supply constraints ahead of routine routing. Preserve placement and outside interfaces, validate simultaneous local routes, and require full restoration before acceptance.
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2026-09-23 Record incomplete IMU re-layout and correct execution limits
2026-09-23 Preserve qualified incomplete IMU fanout fixture and next coupled scope
    [imu-fanout-method-staged.kicad_pcb]
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2026-09-24 Qualify IMU copper clearances and released routing regions
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2026-09-24 Preserve IMU branch cleanup and resolve newline-only source audit
    [imu-cleanup-staged.kicad_pcb]
2026-09-24 Record cleanup DRC and correct unchecked schematic-parity interpretation
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2026-09-27 Preserve replayable MCU fixture and hold incomplete oscillator audit
    [replay_mcu_fanout_fixture.py]
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2026-10-03 Record concrete D45 trial outline and physical reservations
    Preserve the USB tongue and all source outline containment; bind whole-body L1, mount, fixed-interface and actual-radius process-via evidence. Keep native staging gated on contact-mask and access dispositions without altering accepted source.
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2026-10-04 Qualify isolated battery feed import fixture
    Add a hash-locked import-only variant retaining exact source feeds and vias, preserve the original control fixture, and record native serialization evidence with all intentional DRC findings.
2026-10-04 Recover critical-block inventory with preflighted KiCad bindings
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2026-10-05 Correct common Quilter settings and launch first four-layer comparison
    Record source-bound capacitor/power/placement decisions, imported pin reconciliation, and confirmed running job. Preserve source and six-layer input unchanged.
2026-10-12 Preserve revised IMU placement and qualification blockers
    Record recovered candidate bytes, finite four-part placement, held native derivative, timeout and first-save/project-binding evidence limits. Preserve source and stop before cloud submission.
2026-10-14 Recover byte-safe common-mask staging for isolated comparison
    Record eight passing controls, exact staged input bindings, preserved failures, and the unperformed native fill stage at the declared time gate.
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2026-10-14 Preserve blocked core pilot and native snapshot
    Record original timebox, unsuccessful geometry qualification, syntax failures, late-launch deviation and unchanged PCB inputs. Leave remaining pilot items unstarted.
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2026-11-06 Try wider-clearance DeepPCB, repair router and charger spread; record results
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2026-11-06 Record held regulator rearrangement and preserve failed trials
2026-11-06 Correct fanout classification and resume connected regulator-cell placement
2026-11-07 Record v3 tolerance hold and checker lessons
    One native v3 screen passed both controls, then held on a 1e-6 mm C1 witness: KiCad 10 pcbnew.FromMM truncates to integer nm, placing C1 1 nm short. Five cases unevaluated; no PCB, copper change or DeepPCB spend. Adds evergreen screen/checker lessons; owner decision pending.
2026-11-07 Record v4 regulator screen outcome; stop rearrangement
    All five screened U2/C1/C4 poses are rejected on real foreign-net conflicts with fixed copper; every pose puts a ground via in the BT2 contact guard and four also hit B.Cu /CELL_NEG. Keep best-8, leave the approved DeepPCB run unspent, consolidate the AGENTS.md rearrangement bullets and add the workflow lessons.
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2026-11-10 Add quote-only JLC package for the six-layer review snapshot
    Bare-PCB quote-prep package bound to the public review snapshot
    (PCB 2f738ccb): hash-bound CPL, JLC/PCBWay/sourcing BOMs, inventory,
    verification (67 PASS / 4 INFO / 0 WARN / 0 FAIL), LCSC register,
    expectations and a 9-entry MANIFEST, plus the private-artifact hash list.
    Three narrative docs cover the package, the fabrication options and
    open questions, and everything unresolved before ordering.
    tools/build_quote_package.py builds and verifies the package;
    tools/test_build_quote_package.py has 98 passing unittest cases.
    Quote only. Nothing ordered, paid or accepted; no BOM/CPL upload or part
    matching. One Gerber/drill ZIP was up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
2026-11-10 Record J1 overhang disposition and first-article quantity
    West shift is blocked by USB_D-; a 0.25 mm south trial failed the 0.3 mm edge rule. The board is kept and a housing relief added under R4.
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

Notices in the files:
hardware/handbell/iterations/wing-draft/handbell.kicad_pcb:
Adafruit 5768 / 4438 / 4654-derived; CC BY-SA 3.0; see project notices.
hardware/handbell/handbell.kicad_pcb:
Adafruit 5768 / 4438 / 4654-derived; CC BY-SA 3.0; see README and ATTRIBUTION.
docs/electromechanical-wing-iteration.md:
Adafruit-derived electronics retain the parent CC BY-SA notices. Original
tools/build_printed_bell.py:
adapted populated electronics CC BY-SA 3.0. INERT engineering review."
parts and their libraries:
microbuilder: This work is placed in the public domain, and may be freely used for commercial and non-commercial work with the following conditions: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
